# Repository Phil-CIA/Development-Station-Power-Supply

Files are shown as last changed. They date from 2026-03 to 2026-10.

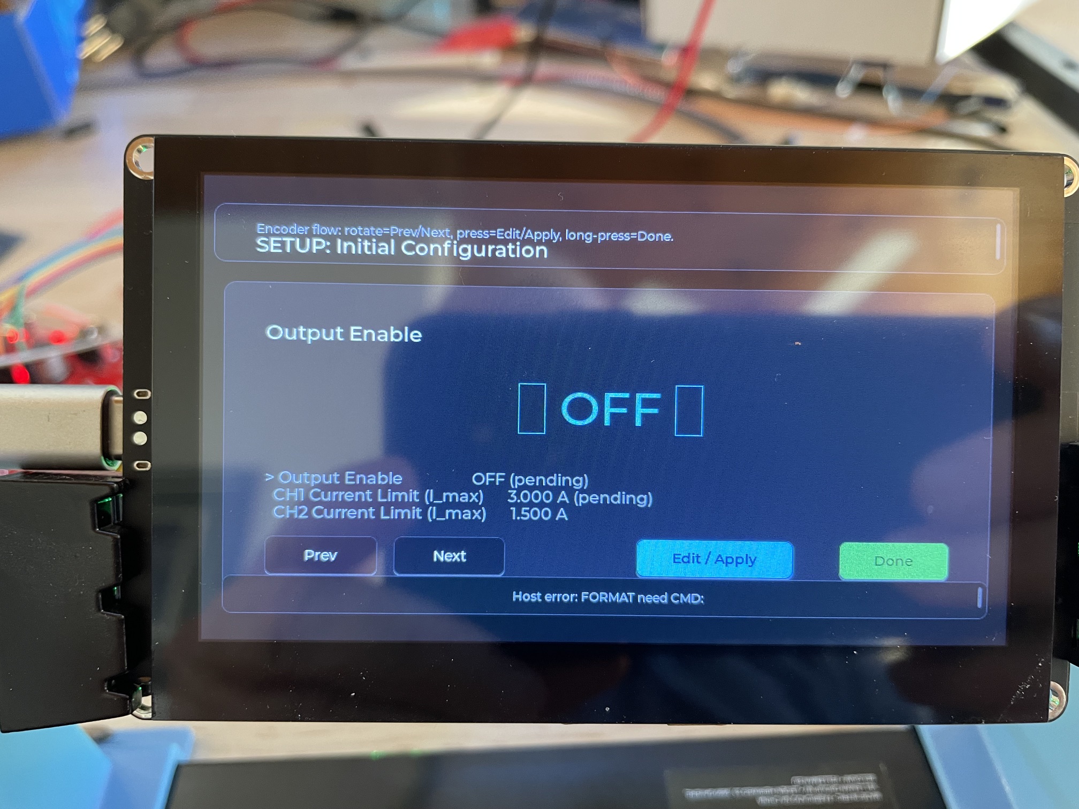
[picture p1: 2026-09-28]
docs/display-project/screenshots/audit/setup-before-fix.jpeg

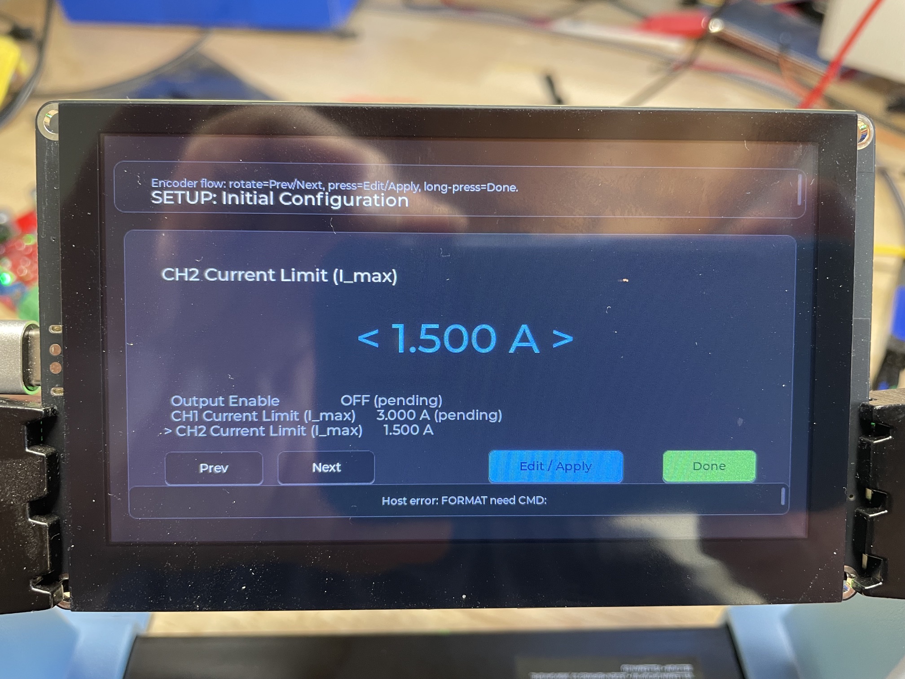
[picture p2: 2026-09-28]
docs/display-project/screenshots/audit/setup-d2.jpeg

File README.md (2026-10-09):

# Development-Station-Power-Supply

Integrated hardware and firmware repository for the development-station bench supply, its control electronics, front-panel display path, and supporting boards.

## What this repo actually contains

This is the active working repo for the full bench-supply platform, not just a single firmware target. It currently includes:

- ESP32 control firmware
- DSP regulator board design
- DSP regulator HAT / measurement-control board design
- original front-panel display board files
- USB hub board files and next-iter reference cleanup
- bring-up notes, pin maps, and display evaluation references

## Current direction (2026-08-14)

The project has shifted to a bring-up-first path.

**Recent progress:**
- Completed design simplification: migrated from adjustable 3-channel architecture to single +5V_Boot rail
- Connector contract verification passing (10 signal mappings validated across regulator↔HAT interface)
- Both RegulatorRevB and HAT-RevB boards electrically verified and ready for order prep

Current plan:
1. Use the hardware already built as the learning and validation baseline
2. Keep Rev-B bench work in proven bypass states while Rev-C electrical issues are closed
3. Complete Rev-C regulator and HAT design validation before PCB fabrication release
4. Continue front-panel work inside this repo
5. Evaluate two display paths in parallel:
   - the existing custom front-panel hardware already designed
   - the Elecrow CrowPanel Advance 4.3 inch HMI display
6. Avoid any new display redesign until bench results show it is needed

Current power-hardware status:

- The 3.3V regulator selector redesign is bench-proven in normal remote-sense operation; fallback and 5V TLV9352 checks remain open.
- The Rev-B HAT current-range switch remains bypassed pending MOSFET pinout and Vgs validation.
- HAT Rev-C implements four-channel differential OCP with dual INA2180A2 amplifiers and dual TLV1702 comparators.
- HAT Rev-C ERC is clean, but RB-012 remains a PCB release gate for Kelvin routing, bypassing, thresholds, hysteresis, footprints, and final DRC/connectivity validation.
- Future HAT Rev-D controller decision: use a bare STM32F405RG LQFP64 as the deterministic controller, replacing the F103C8 Blue Pill development module, with a bare ESP32-C3-MINI-1U external-antenna Wi-Fi coprocessor and USB CDC telemetry to a PC. The cited F405 pin allocation and minimum-support targets are frozen in the Rev-D contract; session 3 confirmed PC0=`C3_EN_N` and PC1=`C3_BOOT_N`. Session 4's reviewed support-only KiCad project remains intact. The separate editable project in `hardware/kicad/dsp-regulator-hat-rev-d-full/` now has an initial committed-source HAT reuse pass and independent local MCU/HAT sheets: 13 F405 interfaces wired, 102 components, 128 nets, ERC 0 errors / 80 unresolved warnings. This is partial integration, not a complete HAT; missing source blocks, bare C3 module/antenna and PCB remain open. User direction (2026-10-09): prior HAT circuits are working reuse candidates, replaceable as needed; full Rev-C bench requalification and the untested fan's later check do not block integration. The supplied 2026-08-28 production Rev-C PCB/Gerber/drill set is the working manufacturing reference, but exact physical-board/schematic correlation remains unresolved. Part qualification, full integration, layout and Rev-D bench validation remain open. See `docs/HAT_REVD_PIN_AND_SUPPORT_CONTRACT.md` and the project's `README.md`; no fabrication or hardware validation is claimed.
- See `docs/DEV_STATION_HANDOFF_2026-08-14.md` for the active restart state.

## Hardware scope in this repo

- External supply 12V feeds the regulator and HAT control stack
- Regulator board generates the main rails (+5V, +3.3V primary; +12V intermediate)
- HAT board handles measurement, feedback, and control behavior
- Front-panel display path is now treated as a system integration problem, not a redesign-first task
- USB hub files are retained as reference and redesign starting point where needed

## Hardware board status

**DSP-Regulator-RevB:** Ready for order
- ERC: 0 electrical errors (8 library warnings, non-critical)
- Connector contract: Verified against HAT-RevB (all 10 required signal mappings present)
- Latest netlist export: 2026-06-11 01:43:33

**DSP-Regulator-HAT-RevB:** Ready for order
- ERC: Clean (0 errors, 0 warnings)
- Connector contract: Verified with Regulator-RevB (all 10 required signal mappings present)
- Latest netlist export: 2026-06-11 01:10:51
- Design: Single +5V_Boot rail (simplified from adjustable 3-channel architecture)

These Rev-B files remain the built/bench baseline. Active redesign work now lives in the corresponding Rev-C project folders; do not release Rev-C fabrication outputs until its tracker gates are closed.

## Firmware status

Current firmware work in this repo includes:

- logical rail telemetry mapping
- automatic range selection support
- per-rail calibration and persistent configuration storage
- current-limit operating modes
- TFT front-panel support hooks

The active [CrowPanel UI plan](docs/display-project/crowpanel-screens-tracker.md)
adapts FNIRSI DPS-150 / IPS3608 styling to fixed +5V/+3.3V rails with editable
current limits and shared output control. It includes the issue/PR sequence
and VS Code Copilot session prompts; definitive CV/CC indication remains
gated on hardware validation.

## Current bench priorities

- Complete DRC checks and generate fabrication outputs for RegulatorRevB and HAT-RevB
- Place orders for both boards
- Safe first power-up and validation of the new boards
- Confirm regulator and HAT behavior on the bench
- Resume front-panel display bring-up
- Map the existing front-panel connector to the smart-display interface as needed

## Useful project references

- docs/SYSTEM_DEVELOPMENT_WORKFLOW.md — branch/PR workflow now in effect
- docs/FIRMWARE_DEVELOPMENT_PLAN.md — firmware feature inventory and milestone/branch plan
- docs/display-project/README.md
- docs/GPIO_PINOUT.md
- docs/USB_HUB_CHANGE_TRACKER.md

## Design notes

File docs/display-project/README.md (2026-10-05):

# Display Project Reference

This folder captures the current starting point for the front-panel display direction inside the Development Station Power Supply project.

## Path priority

| Priority | Path | Hardware | Status |
|---|---|---|---|
| **Primary** | Elecrow CrowPanel 4.3 HMI | ESP32-S3, 800×480 IPS, capacitive touch | Active — main development target |
| Secondary | Custom front-panel board + Hosyond MSP4021 | ESP32-C6, ST7796S SPI, 480×320 | Paused — revisit with replacement module |

## Current direction
The display effort is now on **two paths with a defined priority**:
- **Primary**: Elecrow CrowPanel Advance 4.3 inch HMI — main development target going forward
- **Secondary**: Custom front-panel hardware with Hosyond MSP4021 (ST7796S SPI module) — retained as a documented path but paused pending a replacement module

## Active UI improvement plan

Use FNIRSI DPS-150 / IPS3608 as visual references for an original, touch-first
800x480 interface. Our CH1 +5V and CH2 +3.3V rails remain fixed; users edit
current limits, not voltage or a manual CV/CC selector. One master OUTPUT
control serves both rails. Automatic CV/CC indication is conditional on
proven hardware behavior, not just a software threshold comparison.

The user-selected Main layout has side-by-side CH1/CH2 cards with large
vertical voltage/current/power readouts and no Energy or Input panels.
Tapping a card opens that channel's detail view: readings on the left,
its V/I graph on the right, and a touch action back to Main.

The Graph screen is being rebuilt as a Yokogawa GX-style strip recorder; see
[strip-recorder-graph-spec.md](strip-recorder-graph-spec.md) (Rev 2) for the
plan, hardware-feasibility analysis, and the D5a/D5b bucket breakdown
(supersedes the prior single D5 scope line). History scroll-back and alarm
markers are cut from scope; CSV/PC export is tracked separately in
[#84](https://github.com/Phil-CIA/Development-Station-Power-Supply/issues/84).

The [screen tracker](crowpanel-screens-tracker.md) contains the issue/PR
sequence, reference-photo approval gate, and copy-paste VS Code Copilot
session instructions. The [IPS3608 reference](../IPS3608_REFERENCE_MANUAL_KEY_SPECS.md)
is already in the repo; the user's two supplied visual references and
selected screen composition are described in the tracker. Exact product
identity is unverified and final geometry remains to be approved. No
display hardware redesign or secondary-path restart is included.

A simulated, browser-viewable 800x480 mockup for visual review is at
[mockups/crowpanel-fixed-rail-mockup.html](mockups/crowpanel-fixed-rail-mockup.html)
(baseline visual appearance and screen flow approved 2026-10-02; behavior
questions unresolved; not bench-tested; not an LVGL rendering).

The first LVGL port of the approved Main overview and single-channel detail
screens is on `display/fnirsi-dual-rail-dashboard` (#78); status and visual
differences are in the screen tracker. Build-verified only; not bench-tested.

## Active display candidate
- Elecrow CrowPanel Advance 4.3 inch HMI ESP32 display
- 800x480 IPS panel
- Capacitive touch
- ESP32-S3-WROOM-1-N16R8
- 16MB flash + 8MB PSRAM
- Suitable for Arduino, ESP-IDF, PlatformIO, and LVGL

## Official documentation links
- Product wiki:
  - https://www.elecrow.com/wiki/CrowPanel_Advance_4.3-HMI_ESP32_AI_Display.html
- Product page:
  - https://www.elecrow.com/crowpanel-advance-4-3-hmi-esp32-800x480-ai-display-ips-touch-artificial-intelligent-screen.html
- Elecrow GitHub organization:
  - https://github.com/Elecrow-RD
- Official board repository:
  - https://github.com/Elecrow-RD/CrowPanel-Advance-4.3-HMI-ESP32-S3-AI-Powered-IPS-Touch-Screen-800x480
- General CrowPanel course files:
  - https://github.com/Elecrow-RD/CrowPanel-ESP32-Display-Course-File

## Datasheet and hardware resource links
- Board resource page (includes schematics, version notes, and platform support):
  - https://www.elecrow.com/wiki/CrowPanel_Advance_4.3-HMI_ESP32_AI_Display.html#resources
- GitHub repository hardware and docs area:
  - https://github.com/Elecrow-RD/CrowPanel-Advance-4.3-HMI-ESP32-S3-AI-Powered-IPS-Touch-Screen-800x480
- Espressif ESP32-S3-WROOM module docs:
  - https://www.espressif.com/en/support/documents/technical-documents

## Notes
- The old separate TTF display repo is now reference-only and no longer the active implementation path.
- The front-panel work now lives back under the main Development Station Power Supply project.
- Custom board redesign (Phase 3) is scoped but not started — CrowPanel bring-up (Phase 4) runs first to validate the UART protocol.
- When the CrowPanel arrives, confirm the exact board revision against the Elecrow wiki version notes before selecting example code.
- The wiki indicates 5V input, LVGL support, and external interfaces for UART, I2C, audio, battery, and storage.

## Interface direction
The goal is not identical hardware. The goal is a common front-panel interface so either display path can be used from the host perspective.

**Standard decided (2026-05-27): Universal Display Interface (UDI)**
- Connector: JST XH B4B-XH-A, 4-pin (XH2.54-4P), LCSC C144394
- Pin 1: +5V (host → display), Pin 2: GND, Pin 3: DISP_UART_TX (host TX), Pin 4: DISP_UART_RX (host RX)
- Protocol: LVGL on display MCU; UART 115200 8N1; `CMD:`/`ACK:`/`ERR:`/`EVT:` framing
- Full spec: `docs/DISPLAY_INTERFACE_STANDARD.md`
- HAT Rev-B: implemented at J21 (PB10=TX, PB11=RX via USART3, 33Ω series on both lines)

---

## Custom Board Rev-1 Requirements

The custom front-panel board must be redesigned to comply with the UDI standard. The secondary-path board (ESP32-C6 + ST7796S) remains the hardware baseline; only the host interface and firmware architecture change.

### Host connector (J3) — REPLACE

| Item | Legacy (remove) | Rev-1 target |
|---|---|---|
| Connector | 2×5 IDC, 2.54mm (Conn_02x05) | JST XH B4B-XH-A, 4-pin |
| Signals | +5V, GND, SPI SCK/MISO/MOSI/CS | +5V, GND, UART_RX, UART_TX |
| ESP32-C6 role | SPI slave | UART peripheral |

### Firmware — REPLACE

| Item | Legacy | Rev-1 target |
|---|---|---|
| Graphics | TFT_eSPI / host pixel push | LVGL (display-side rendering) |
| Host link | SPI slave GPIO4–7 | UART RX/TX (GPIO assignment TBD) |
| Protocol | Raw pixel stream | `CMD:`/`ACK:`/`ERR:`/`EVT:` framing |

### What stays unchanged
- MCU: ESP32-C6
- Display panel: Hosyond MSP4021 (ST7796S, 480×320 SPI)
- Local SPI bus: TFT (GPIO10–13), touch XPT2046, SD card
- Power regulator: AMS1117-3.3

### ESP32-C6 UART pin assignment (TBD)
GPIO4/5 (previously SPI slave SCK/MISO) are available candidates for UART RX/TX. Confirm against ESP32-C6 UART peripheral matrix before committing. Document final assignment in `docs/GPIO_PINOUT.md` when redesign begins.

### Scope note
This redesign is Phase 3 — scoped as a requirements spec. KiCad work starts after CrowPanel bring-up (Phase 4) validates the UART protocol end-to-end.

## Local bring-up starter
- Local PlatformIO starter path (CrowPanel):
  - `crowpanel-43-bringup/`
- Starter is based on official Elecrow V1.2 4.3-inch example pin mapping for RGB data bus and touch I2C.
- Current code includes LVGL Splash/Setup/Main/Graph/Settings screens and
  telemetry/UDI bindings. See the screen tracker for merged versus open
  implementation work and remaining bench evidence.

## Hosyond MSP4021 (secondary path) reference
- Hardware spec, confirmed pin map, DC polarity, init sequence, and official resource links:
  - `docs/display-project/hosyond-msp4021-st7796-reference.md`

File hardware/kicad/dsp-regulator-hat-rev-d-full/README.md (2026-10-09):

# DSP Regulator HAT Rev-D Full - Initial Integration

**Status: editable PARTIAL INTEGRATION, not a complete full-HAT schematic.**
Created 2026-10-09 for #102 from the reviewed session-4 support project.
The first source-backed circuit integration pass is now present; remaining
bulk circuit edits belong here. This project is not fabrication-ready or
bench-validated; there is no PCB or PCB DRC result.

## Open and edit this project

- `DSP-Regulator-HAT-RevD-Full.kicad_pro` - project setup
- `DSP-Regulator-HAT-RevD-Full.kicad_sch` - root schematic
- `MCU.kicad_sch` - independent, local hierarchical F405 support sheet
- `HAT.kicad_sch` - independent local copy of committed HAT Rev-C reuse
  candidates, with the old Blue Pill and XIAO C3 removed
- `build_kicad/` - gitignored ERC reports and exported netlists

Open the `.kicad_pro` in KiCad 10.0.5, then open its root schematic and enter
the MCU and HAT sheets. Project/instance names and sheet paths are consistent
with this three-sheet hierarchy. The MCU is a real local copy, not a shared
reference to `../dsp-regulator-hat-rev-d/`; all source projects remain separate.

The reviewed support-only project in `../dsp-regulator-hat-rev-d/` and all
Rev-C source files are unchanged. Do not edit those projects when integrating
here. Preserve the frozen pin/support requirements in
[`HAT_REVD_PIN_AND_SUPPORT_CONTRACT.md`](../../../docs/HAT_REVD_PIN_AND_SUPPORT_CONTRACT.md).

## Present and intentionally absent

Present: bare STM32F405RGT6 support (power/VCAP, HSE, reset, boot and SWD),
USB 2.0 Type-C/ESD/CC and isolated PA9 VBUS sensing, J4's logical C3
UART/EN/BOOT interface, and 62 retained HAT Rev-C components. J4 is not a
C3 module. Crystal/load and EN candidate/DNP markings remain unchanged.

Source: `../dsp-regulator-hat-rev-c/DSP-Regulator-HAT-RevC.kicad_sch`, not
the uncorrelated production PCB. Added MCU/HAT global interfaces:

| F405 pins | Reused endpoint |
|---|---|
| PA0 / PA1 | J12 ISET 5V / 3V3; each has a new 10k pull-down |
| PA5 / PA6 / PA7 / PA8 | U12 W25Q128 SPI / CS; new 47k SCK/MOSI pull-downs and 10k CS pull-up |
| PB6 / PB7 | U16 CH340 debug TX / RX; each has a new 10k pull-up; not legacy PB6/PB7 connector nets |
| PB10 / PB11 | UDI via R77/R79 to J9; each has a new 10k pull-up |
| PB8 / PB9 | J10/U13 I2C; retains source R69/R70 4.7k pull-ups |
| PB5 | R63/Q9 fan control; R64 changed from 100k DNP to populated 10k |
| PA13 / PA14 / NRST | Existing SWD test points/header plus MCU support header |

The source `+3.3V Boot` rail is now `+3V3`, joining U15's output to the
F405 support rail; duplicate MCU rail/ground PWR_FLAGs were removed. This
is connectivity capture, not proof of regulator headroom for the bare C3.
The legacy WS2812B D12 is retained with DIN tied LOW, not wired to PC13;
the frozen low-current sink LED still needs a replacement circuit.

Absent: AW9523/interrupt and shift-register device (not in this source),
complete measurement/protection and fault/control integration, bare
ESP32-C3-MINI-1U and antenna implementation, C3 local supply/straps/UART0
recovery, and PCB. PA4, PC4 and PC13 remain explicit no-connects pending
those endpoints/replacements. Legacy expansion, sense and fault-label gaps
remain visible; do not invent mappings or treat ERC as protection coverage.

## Integration direction and open gates

User direction (2026-10-09): prior HAT circuits are working reuse candidates,
replaceable as needed. Full Rev-C bench requalification is not a prerequisite
to integration; the untested fan's later bench check is nonblocking. Replace
the old C3 development-board implementation, do not carry it forward.

The supplied 2026-08-28 production Rev-C PCB/Gerber/drill set is the working
manufacturing reference, but exact physical-board and schematic correlation
is unresolved. This starter does not claim a match and does not copy or
modify external OneDrive production files. PR #111 records the mismatch
but was not merged when this starter was created. Keep source identity and
block-level connectivity uncertainties explicit during integration rather
than treating manufacturing outputs or screenshots as a verified schematic.

Still required: integrated pin/net and safe-state review, ISET polarity and
shift-register all-off verification, complete ERC after integration,
crystal/load and C3 EN timing qualification, module/antenna and connector
footprint selection, 3.3 V rail budget, layout/USB/ESD/RF review, PCB DRC,
and Rev-D hardware/bench validation (including powered/unpowered USB VBUS
insertion, oscillator startup, reset/boot, fan and protection behavior).

## Validation and unresolved ERC warnings

Original support-only starter: KiCad CLI 10.0.5 reported 0 errors / 0 warnings
before importing the HAT candidates (31 components, 68 nets).

**Current first pass: KiCad CLI 10.0.5 reports 0 errors / 80 warnings**:
32 footprint-library, 32 symbol-library, 3 symbol/library mismatch and
13 isolated-label warnings. No warning exclusions were added to hide them.
The three mismatches are inherited `1My_Connectors:5015` test points
TP9, TP2_+5V1 and TP_+3.3V1.
Isolated labels are the four VSENSE endpoints, Incoming (+/-), legacy
PB6/PB7/B13/B14/B15/SPI_CS expansion endpoints and `FAULT_WARNING_SUM`.
These are unresolved integration gaps, not routed MCU functions.

Exports contain **102 components, 128 nets**, with all 64 F405 pins accounted
for. Root/MCU/HAT netlist and SVG exports resolve as pages 1/2/3. Pairwise
connectivity checks cover all 215 retained HAT pins except the deliberate
D12 DIN grounding, which is checked separately; support pin topology,
13 frozen interfaces, nine new bias resistors, R64 population, SWD,
rail joins and native USB VBUS isolation were checked. SHA-256 confirms
the original support project and HAT Rev-C files remain byte-identical.
This is not a clean full-HAT release, PCB DRC, fabrication or bench validation.

Re-run from the repository root in PowerShell:

```powershell
$project = "hardware\kicad\dsp-regulator-hat-rev-d-full"
$kicad = "$env:LOCALAPPDATA\Programs\KiCad\10.0\bin\kicad-cli.exe"
& $kicad sch erc "$project\DSP-Regulator-HAT-RevD-Full.kicad_sch" `
  --output "$project\build_kicad\ERC.rpt" --format report `
  --severity-all --exit-code-violations
& $kicad sch export netlist "$project\DSP-Regulator-HAT-RevD-Full.kicad_sch" `
  --output "$project\build_kicad\DSP-Regulator-HAT-RevD-Full.net" `
  --format kicadsexpr
```

The strict ERC command intentionally returns a nonzero status while these
warnings remain; inspect the report rather than interpreting export success
as design acceptance.

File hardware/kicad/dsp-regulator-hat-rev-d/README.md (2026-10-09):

# DSP Regulator HAT Rev-D F405 Support Sheet

Status: session-4 schematic capture and initial contract review complete.
This is a separate, hierarchical KiCad project containing the F405
minimum-support circuitry and external C3 interface. It has no PCB and is not
a fabrication release. Rev-C schematic and PCB files were not copied or
modified.

## Project files

- `DSP-Regulator-HAT-RevD-Support.kicad_pro` — project
- `DSP-Regulator-HAT-RevD-Support.kicad_sch` — root sheet
- `MCU.kicad_sch` — hierarchical F405 and support sheet
- `build_kicad/` — gitignored ERC report and netlist exports

## Captured circuits

- `MCU_ST_STM32F4:STM32F405RGTx` symbol with the frozen LQFP64 allocation;
  exact schematic Value is `STM32F405RGT6`.
- Four VDD-pin 100 nF bypass capacitors, local 4.7 µF bulk, VDDA 0 Ω link
  and 100 nF/1 µF bypass, VBAT-to-3.3 V tie, common VSS/VSSA ground, and one
  2.2 µF low-ESR capacitor at each VCAP pin.
- HSE crystal, NRST pull-up/capacitor/reset switch, BOOT0 and PB2 pull-downs,
  and BOOT0 recovery jumper.
- SWD-only ARM 10-pin header interface with SWDIO, SWCLK, NRST, target
  3.3 V reference, and GND. The exact keyed connector footprint is not chosen.
- USB 2.0 Type-C receptacle interface, 5.1 kΩ CC resistors, USBLC6-2SC6 ESD
  protection, and isolated PA9 VBUS sense divider. VBUS does not connect to
  a HAT supply rail. Verify the selected GCT footprint against the orderable
  USB4105-GF-A variant before layout.
- External C3 interface connector J4:

  | J4 pin | Net | F405 connection | C3-side meaning |
  |---:|---|---|---|
  | 1 | `+3V3` | Shared logic rail | C3 supply reference |
  | 2 | `GND` | Common ground | C3 ground |
  | 3 | `C3_UART_RX` | PC10 / UART4 TX | GPIO0 / application UART RX |
  | 4 | `C3_UART_TX` | PC11 / UART4 RX | GPIO1 / application UART TX |
  | 5 | `C3_EN_N` | PC0, open-drain control | CHIP_EN / active-low reset |
  | 6 | `C3_BOOT_N` | PC1, open-drain control | GPIO9 / active-low boot request |

Unallocated F405 pins are marked no-connect in this minimum-support project;
the frozen assignments remain requirements for full-HAT integration.

## Unverified values and integration boundary

The 8.000 MHz crystal and both 10 pF C0G/NP0 load-capacitor Value fields say
`candidate; UNVERIFIED`. The load capacitors are DNP until the selected
crystal's datasheet, total board parasitics, load calculation, and oscillator
startup are reviewed. The optional 1 µF C3 CHIP_EN capacitor is likewise
marked `candidate; UNVERIFIED` and DNP pending exact module and rail-ramp
review. These markings are intentional; do not treat them as released BOM
values.

J4 is a logical module interface, not an ESP32-C3-MINI-1U module footprint.
The C3's local bypassing, GPIO2/GPIO8 boot-strapping, UART0 recovery header,
exact module/antenna selection, RF keep-out, and antenna validation remain
outside this F405 support sheet. The SWD header's exact keyed footprint is
also pending.

## Validation

KiCad CLI 10.0.5 ERC result: **0 errors, 0 warnings**. The exported netlist
was checked against all 64 F405 pins and the contract's power, clock, reset,
boot, C3 UART/control, USB D+/D−/CC/VBUS, and SWD mappings. ERC and netlist
results do not establish PCB routing, USB signal integrity, ESD placement,
clock startup, VBUS behavior under powered/unpowered insertion, or bench
readiness.

Re-run from the repository root in PowerShell:

```powershell
$project = "hardware\kicad\dsp-regulator-hat-rev-d"
$kicad = "$env:LOCALAPPDATA\Programs\KiCad\10.0\bin\kicad-cli.exe"
& $kicad sch erc "$project\DSP-Regulator-HAT-RevD-Support.kicad_sch" `
  --output "$project\build_kicad\ERC.rpt" --format report --severity-all
& $kicad sch export netlist "$project\DSP-Regulator-HAT-RevD-Support.kicad_sch" `
  --output "$project\build_kicad\DSP-Regulator-HAT-RevD-Support.net" `
  --format kicadsexpr
```

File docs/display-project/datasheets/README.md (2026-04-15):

# Datasheet Staging Area

Place downloaded PDFs, pinouts, and vendor reference files for the display project here.

Suggested first additions:
- Board wiki export or PDF print
- ESP32-S3 module datasheet
- Display/touch controller references from the vendor repo
- Any pin maps used during bring-up

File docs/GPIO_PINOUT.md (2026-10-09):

# System Pinout Reference

Status: active. This document is the top-level index for signal/pin contracts
used by this repo. It links each subsystem to its authoritative mapping source.

## Authoritative pin-contract split

| Subsystem | Authoritative source |
|---|---|
| STM32 controller path (Rev-C HAT + `stm32-bluepill-bringup`) | `docs/STM32_BLUEPILL_PIN_TABLE.md` |
| Future Rev-D STM32F405RG controller (pin allocation frozen; not routed) | `docs/HAT_REVD_PIN_AND_SUPPORT_CONTRACT.md` |
| Custom front-panel board (ESP32-C6 + ST7796S path) | This file, sections below |
| Display host interface standard (both display paths) | `docs/DISPLAY_INTERFACE_STANDARD.md` |

---

## A) Custom front-panel board (ESP32-C6) pin mapping

Framework: Arduino  
Display architecture: display-side LVGL with local SPI peripherals  
Host link: UART over UDI connector

### A1) UDI host connector (J3, JST XH 4-pin)

| J3 Pin | Net Name | Direction (Host ↔ Display) | ESP32-C6 role | Notes |
|---:|---|---|---|---|
| 1 | +5V | Host -> Display | Power in | Board regulates to 3.3V via AMS1117-3.3 |
| 2 | GND | — | Ground | Common return |
| 3 | DISP_UART_TX | Host -> Display | UART RX | Host TX into display RX |
| 4 | DISP_UART_RX | Display -> Host | UART TX | Display TX back to host RX |

### A2) TFT module header (J1) -> ESP32-C6 (local SPI master)

| J1 Pin | Net Name | Function | ESP32-C6 GPIO | Notes |
|---:|---|---|---:|---|
| 3 | CS | TFT chip-select | GPIO10 | ST7796S CS |
| 4 | RST | TFT reset | GPIO19 | Active-low reset |
| 5 | D/C | TFT data/command | GPIO18 | |
| 6 | MISO | SPI MISO | GPIO11 | Shared with touch/SD |
| 7 | SCLK | SPI SCLK | GPIO12 | Shared with touch/SD |
| 8 | PWM | Backlight PWM | GPIO20 | LED/backlight control |
| 9 | MOSI | SPI MOSI | GPIO13 | Shared with touch/SD |
| 11 | Touch CS | Touch chip-select | GPIO22 | XPT2046 CS |
| 14 | IRQ | Touch interrupt | GPIO21 | Optional (can be polled) |

### A3) SD header (J2) -> ESP32-C6

| J2 Pin | Net Name | Function | ESP32-C6 GPIO |
|---:|---|---|---:|
| 1 | SCLK | SPI SCLK | GPIO12 |
| 2 | MOSI | SPI MOSI | GPIO13 |
| 3 | MISO | SPI MISO | GPIO11 |
| 4 | SD card CS | SD chip-select | GPIO15 |

Firmware notes:
- Host protocol: UART 115200 8N1 with `CMD:`/`ACK:`/`ERR:`/`EVT:` framing.
- The host sends semantic commands; display firmware renders locally with LVGL.

---

## B) STM32 controller path summary (Rev-C)

For STM32 signal ownership and status, use:
- `docs/STM32_BLUEPILL_PIN_TABLE.md` (authoritative matrix)

Current high-impact contract notes:
1. Rail-control outputs are active on `PA0/PA1/PA2` as `ISET_MPU_5V`,
   `ISET_MPU_3V3`, and `ISET_MPU_Channel_3`.
2. Current Rev-C fan connector (`J7`) is a 2-pin control connector and does
   not expose a dedicated tach net in this revision.
3. `FAULT_CRITICAL_SUM` is observed through AW9523 on Rev-C, not a direct STM32
   GPIO net. Firmware uses AW9523 interrupt signaling (`AW9523_INT` on `PB7`)
   with `PIN_FAULT_CRITICAL_SUM = -1` kept as disabled direct-path fallback.

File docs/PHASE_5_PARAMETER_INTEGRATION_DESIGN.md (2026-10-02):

# Phase 5: Parameter Integration Design (2-Channel Power Supply)

**Date:** 2026-07-03  
**Status:** Design Phase — Ready for Implementation  
**Scope:** Bind real system parameters to CrowPanel UI for 2-fixed-channel power supply  
**Reference:** IPS3608 dark-theme adaptation, Phase 4 visual baseline, UDI UART contract

> Historical design proposal, not the current implementation contract.
> The active [screen tracker](display-project/crowpanel-screens-tracker.md)
> supersedes this document's adjustable-voltage examples, per-channel output
> controls, always-CV assumptions, speculative thresholds, and proposed frame
> layout. Use actual firmware and `DISPLAY_INTERFACE_STANDARD.md` for the
> shipped protocol. Current UI work is fixed +5V/+3.3V, per-channel current
> limits, one shared output control, and touch-first operation; CV/CC claims
> require hardware validation.

---

## 1. Boot Sequence

```
Power On
  ↓
[Splash Screen] 3–5 seconds
  - Brand logo / product name
  - No user interaction
  ↓
[Setup Screen] User-configurable once per boot
  - Feature discovery & control mapping
  - User confirms defaults or adjusts
  - Sets: Current limits, protection thresholds, display preferences
  ↓
[Main Telemetry Screen] Live operation
  - Dual-channel V/I/P display
  - Status indicators
  - Protection state
  - User navigates between Main → Graph → Settings via encoder knob
```

**Gate to Main:** User must confirm Setup OR timeout (auto-proceed with defaults) after 30 seconds.

---

## 2. Parameter Contract

### Real System Data (from STM32 HAT via UART)

**Current telemetry frame (binary, 10 bytes):**
```
[0xAA][0x55][0x06][T][seq][v12_mV_lo][v12_mV_hi][i12_mA_lo][i12_mA_hi][CRC8]
```

**Proposed extended frame (Phase 5):**
```
[0xAA][0x55][LEN][T][seq][v5_mV_lo][v5_mV_hi][i5_mA_lo][i5_mA_hi]
                          [v3v3_mV_lo][v3v3_mV_hi][i3v3_mA_lo][i3v3_mA_hi]
                          [status][protection_flags][temp_C][CRC8]
```

**Status byte breakdown:**
- Bit 7: CH1 output enabled (1=on, 0=off)
- Bit 6: CH2 output enabled
- Bit 5: CH1 in CV mode (constant voltage)
- Bit 4: CH2 in CV mode
- Bit 3: Thermal warning (temp > threshold)
- Bit 2: Reserved
- Bit 1: Reserved
- Bit 0: Reserved

**Protection flags byte:**
- Bit 7: CH1 OVP triggered
- Bit 6: CH1 OCP triggered
- Bit 5: CH2 OVP triggered
- Bit 4: CH2 OCP triggered
- Bit 3: CH1 OTP triggered
- Bit 2: CH2 OTP triggered
- Bit 1: Communication link stale (no frame for > 1 second)
- Bit 0: Reserved

**Frame rate:** 4 Hz (250 ms interval)

### Display-Local Parameters (UI State)

**Setup Configuration (stored in flash or session):**
- CH1 current limit setpoint (0–3A, default TBD)
- CH2 current limit setpoint (0–2A, default TBD)
- CH1 OCP threshold (50–3000 mA, step 10 mA)
- CH2 OCP threshold (50–2000 mA, step 10 mA)
- CH1 OVP threshold (4.5–5.5V, step 0.1V)
- CH2 OVP threshold (3.0–3.6V, step 0.1V)
- OTP threshold (global, 45–80°C, step 1°C)
- Dark theme enabled (1=yes, 0=no — default: yes)
- Brightness (5–100%, step 5)

**User Controls (transient, not stored unless saved to preset):**
- CH1 output enable/disable toggle
- CH2 output enable/disable toggle
- Data group selector (preset 1–6 for quick parameter swap)
- Graph page timebase (0.1s, 0.2s, 0.5s)
- Screen: Main / Graph / Settings selector

---

## 3. Screen Layouts

### 3.1 Setup Screen (Boot Flow)

**Layout:**
```
╔════════════════════════════════════╗
║  Setup: Control Configuration      ║  ← Title
╠════════════════════════════════════╣
║                                    ║
║  CH1: +5V  Current Limit: 3.0 A   ║
║  CH1 OCP:  3000 mA  OVP: 5.5V     ║
║                                    ║
║  CH2: +3.3V  Current Limit: 2.0 A ║
║  CH2 OCP:  2000 mA  OVP: 3.6V     ║
║                                    ║
║  OTP Threshold: 70°C               ║
║  Theme: Dark   Brightness: 80%     ║
║                                    ║
╠════════════════════════════════════╣
║ ↑↓ Scroll  OK Confirm  ESC Cancel  ║  ← Instructions
╚════════════════════════════════════╝
```

**Encoder behavior:**
- Rotate: scroll through parameters
- Press: enter edit mode for selected parameter
- Long press: apply defaults and proceed to Main

**Expected parameters in order:**
1. CH1 current limit
2. CH1 OCP threshold
3. CH1 OVP threshold
4. CH2 current limit
5. CH2 OCP threshold
6. CH2 OVP threshold
7. OTP threshold
8. Brightness
9. Confirm & Start

---

### 3.2 Main Telemetry Screen

**Layout (IPS3608-inspired, dark theme):**

```
╔════════════════════════════════════╗
║ 🔊 ❄️  🔒       M1      CV   ⏹     ║  ← Status chips
╠════════════════════════════════════╣
║                                    ║
║  [CH1: +5V]                        ║
║  V 5.234 v  ← V set: 5.20v        ║  ← Yellow accent
║  A 1.234 A  ← I set: 1.60A        ║  ← Blue accent
║  P 6.3 W    Temp: 28°C            ║  ← Gray accent
║                                    ║
║  [CH2: +3.3V]                      ║
║  V 3.285 v  ← V set: 3.30v        ║  ← Yellow accent
║  A 0.542 A  ← I set: 0.50A        ║  ← Blue accent
║  P 1.8 W                           ║  ← Gray accent
║                                    ║
║  Capacity: 2456.3 Ah              ║
║  Energy: 14523.3 Wh               ║
║  Time: 13:06:17                    ║
║                                    ║
╠════════════════════════════════════╣
║ ↑↓ CH Select  RUN/STOP  ⚙ Settings ║  ← Navigation
╚════════════════════════════════════╝
```

**Status chips (top-right):**
- Volume icon (black if on, white if off)
- Fan icon (black if running, white if idle)
- Lock icon (black if locked, white if unlocked)
- Data group indicator (M1–M6)
- CV indicator (always on for fixed rails)
- RUN/STOP indicator (green if running, red if stopped)

**Encoder behavior:**
- Rotate (no input): toggle between CH1 and CH2 detail focus
- Rotate (after V/A press): scroll pages (Main → Graph → Settings)
- Press RUN/STOP button: toggle output enable for selected channel
- Press V/A: enter current-limit edit mode for selected channel
- Press encoder knob: confirm parameter edit or lock/unlock
- Long press encoder: clear statistics

---

### 3.3 Graph (VI Curve) Screen

**Layout:**

```
╔════════════════════════════════════╗
║ 🔊 ❄️  🔒       M1      CV   ⏹     ║  ← Status chips (same)
╠════════════════════════════════════╣
║  MAX: 5.20v (CH1)  MAX: 0.55A     ║  ← Yellow/Blue labels
║  MIN: 5.18v (CH1)  MIN: 0.10A     ║
║                                    ║
║  ┌────────────────────────────┐    ║
║  │ CH1 ↑   ╱╲╱╲  ← Voltage    │    ║  ← Yellow trace (CH1 V)
║  │     │  ╱  ╲                │    ║
║  │ CH2 ↓ ╱    ╲  ← Current    │    ║  ← Blue trace (CH1 I)
║  │     │╱      ╲              │    ║
║  │     ├────────┤             │    ║
║  │     T: 0.5s  ← Timebase    │    ║
║  └────────────────────────────┘    ║
║                                    ║
║  CH1 Data: V=5.23v I=1.24A        ║
║  CH2 Data: V=3.28v I=0.54A        ║
║                                    ║
╠════════════════════════════════════╣
║ ← TB Time Base      RUN/STOP  ⚙    ║  ← Timebase adjust / nav
╚════════════════════════════════════╝
```

**Legend:**
- **Yellow line:** Voltage trace (normalized to display width)
- **Blue line:** Current trace (normalized to display height)
- **Timebase:** 0.1s, 0.2s, 0.5s per division (left/right buttons adjust)

**Encoder behavior:**
- Rotate: scroll timebase (0.1s ↔ 0.2s ↔ 0.5s)
- Press: return to Main screen
- Long press: clear trend buffer

---

### 3.4 Settings Screen

**Layout:**

```
╔════════════════════════════════════╗
║  Settings: System Configuration    ║
╠════════════════════════════════════╣
║                                    ║
║  ✓ System                          ║  ← Current selection
║    Language: English               ║
║    Brightness: 80%                 ║
║    Volume: 40%                     ║
║    Style: Dark                     ║
║                                    ║
║  DataSet                           ║
║    Group 1–6 parameter presets     ║
║                                    ║
║  About                             ║
║    Model: WorkStation PSU          ║
║    Version: 1.0.0                  ║
║                                    ║
╠════════════════════════════════════╣
║ ↑↓ Menu   ► Enter   ← Back / ESC   ║
╚════════════════════════════════════╝
```

**Encoder behavior:**
- Rotate: select menu item (System / DataSet / About)
- Press: enter submenu
- Left arrow / ESC: return to Main

---

## 4. Operational State Machine

```
BOOT
  ↓
SPLASH (3–5 sec)
  ↓
SETUP (user interactive, 30 sec timeout)
  ├─→ [OK] → RUNNING / IDLE (Main screen, outputs OFF by default)
  └─→ [Timeout] → RUNNING / IDLE (Main screen with defaults)

RUNNING / IDLE
  ├─→ RUN/STOP press → toggle CH1 or CH2 output
  ├─→ V/A press → edit current limit for selected channel
  ├─→ Encoder rotate → select Main / Graph / Settings
  ├─→ Encoder press → navigate within current screen
  └─→ Power off → SHUTDOWN (save state, zero V/I)

FAULT STATE (if protection triggered)
  ├─→ OVP/OCP/OTP sets protection_flags bit
  ├─→ UI shows warning indicator on status chip
  ├─→ Output disabled automatically (hardware + firmware)
  └─→ User must acknowledge (Settings → clear fault)
```

---

## 5. Parameter Mapping: Display ↔ STM32 HAT

| Display Element | Source | Update Rate | Notes |
|---|---|---|---|
| CH1 voltage | STM32 ADC (12-bit) | 4 Hz (250 ms) | Measures main +5V rail |
| CH1 current | STM32 ADC (12-bit) | 4 Hz | INA3221 or equivalent |
| CH2 voltage | STM32 ADC (12-bit) | 4 Hz | Measures main +3.3V rail |
| CH2 current | STM32 ADC (12-bit) | 4 Hz | INA3221 or equivalent |
| Temperature | STM32 internal sensor | 4 Hz | MCU junction or external NTC |
| CH1 output enable | STM32 GPIO (PA0/equivalent) | Immediate | User toggle via UI |
| CH2 output enable | STM32 GPIO (PA1/equivalent) | Immediate | User toggle via UI |
| CH1 current limit | CrowPanel flash or UI state | On change | User-set threshold (compare against ADC) |
| CH2 current limit | CrowPanel flash or UI state | On change | User-set threshold |
| OVP/OCP/OTP flags | STM32 firmware logic | 4 Hz | Comparator + firmware trip |
| Protection flags byte | STM32 UART frame | 4 Hz | Bits 7–2 encode all active faults |
| Thermal warning | STM32 firmware | 4 Hz | Set if temp exceeds OTP threshold |
| Data statistics | CrowPanel accumulator | Real-time | Ah/Wh/time updated locally |

---

## 6. Telemetry Frame Evolution

### Current Frame (Phase 4 — Binary, HAT → CrowPanel only)
```
Byte [0]: 0xAA (SOF1)
Byte [1]: 0x55 (SOF2)
Byte [2]: 0x06 (LEN: TAG + seq + v12 + i12)
Byte [3]: 'T'  (TAG: Telemetry)
Byte [4]: seq  (u8, increments per transmission)
Byte [5–6]: v12_mV (uint16_le, main +12V rail estimate or +5V)
Byte [7–8]: i12_mA (int16_le, main rail current)
Byte [9]: CRC8 (poly 0x07, init 0x00)
```

### Proposed Extended Frame (Phase 5+)
```
Byte [0]: 0xAA (SOF1)
Byte [1]: 0x55 (SOF2)
Byte [2]: 0x14 (LEN: 20 bytes of payload)
Byte [3]: 'T'  (TAG: Extended Telemetry)
Byte [4]: seq  (u8)
Byte [5–6]: v5_mV (uint16_le, +5V channel)
Byte [7–8]: i5_mA (int16_le, +5V channel current)
Byte [9–10]: v3v3_mV (uint16_le, +3.3V channel)
Byte [11–12]: i3v3_mA (int16_le, +3.3V channel current)
Byte [13]: temp_C (u8, 0–125°C)
Byte [14]: status (u8: [CH1_en, CH2_en, CH1_CV, CH2_CV, Thermal_warn, -, -, -])
Byte [15]: protection_flags (u8: [CH1_OVP, CH1_OCP, CH2_OVP, CH2_OCP, CH1_OTP, CH2_OTP, Link_stale, -])
Byte [16–19]: Reserved for future expansion
Byte [20]: CRC8
```

**Backward compatibility:** Old 10-byte frame remains valid. CrowPanel detects frame length and parses accordingly.

**Gate:** Only deploy extended frame after both CrowPanel and STM32 firmware are ready to handle it. Until then, Phase 5 uses 10-byte frame with derived/placeholder values.

---

## 7. Implementation Roadmap (Next Steps)

### 7.1 Immediate (Days 1–2)
1. ✓ Capture IPS3608 manual reference (done)
2. ✓ Create this Phase 5 design doc (done)
3. Commit both to repo
4. Schedule STM32 breadboard bring-up (parallel track, Phase A bench runsheet)

### 7.2 Phase 5a — UI Skeleton (Days 3–5)
1. Add Setup screen template to `main.cpp` (no functional parameter storage yet)
2. Update Main screen to show 2-channel layout (CH1 top, CH2 bottom)
3. Update Graph screen to dual-trace (CH1 + CH2)
4. Update Settings menu structure
5. Build + test on CrowPanel hardware (visual layout only, hardcoded demo data)

### 7.3 Phase 5b — Parameter Binding (Days 6–10)
1. Define flash storage for Setup parameters (on CrowPanel or off-device)
2. Add V/A button handler for current-limit editing
3. Add RUN/STOP toggle for per-channel output control
4. Implement telemetry frame parser (handle both 10-byte and 20-byte formats)
5. Bind status flags and protection warnings to UI indicators

### 7.4 Phase 5c — End-to-End (Days 11–14)
1. Flash updated CrowPanel firmware to hardware
2. Verify STM32 breadboard bring-up results (Phase A completion)
3. Cross-connect STM32 UART → CrowPanel UART0-IN per bench runsheet
4. Test parameter flow: STM32 ADC → UART frame → CrowPanel display
5. Verify output enable/disable commands (if reverse channel added)
6. Capture scope traces for boot-to-run sequence

---

## 8. Definition of Done (Phase 5 Complete)

1. ✓ Setup screen appears at boot, allows current-limit adjustment, proceeds to Main
2. ✓ Main screen displays real V/I/P for both channels (4 Hz update)
3. ✓ Protection flags displayed as visual indicators (red/yellow chips if triggered)
4. ✓ Graph page shows dual traces (V and I) with adjustable timebase
5. ✓ RUN/STOP button toggles CH1 output enable/disable (or per-channel toggle)
6. ✓ V/A button allows current-limit editing (stored in Setup, used for OCP compare)
7. ✓ Guarded build/flash workflow passes for CrowPanel target
8. ✓ No regression in screen navigation or render stability
9. ✓ STM32 ↔ CrowPanel UART link confirmed with bench-captured data

---

**Document Version:** 1.0  
**Last Updated:** 2026-07-03  
**Status:** Ready for Development Sprint  
**Next Review:** After Phase 5a UI skeleton checkpoint (Day 5)

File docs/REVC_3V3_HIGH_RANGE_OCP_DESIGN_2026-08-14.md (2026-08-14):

# Rev-C 3.3V High-Range Differential OCP Design

Date: 2026-08-14

Status: First-channel design baseline; schematic implementation and bench validation pending.

## Design target

This circuit replaces the Rev-B U3A absolute-voltage comparison for the 3.3V high-current range.

| Item | Design value |
|---|---:|
| Rail | 3.3V |
| Shunt | R16, 20mΩ |
| Nominal rising trip | 2.00A |
| Nominal reset | approximately 1.97A |
| Fault polarity | Active high into `FAULT_CRITICAL_SUM` |
| Response target | Less than 10µs before fault-bus loading effects |

The 2.00A target follows the current provisional CH2 maximum in `docs/PHASE_5_PARAMETER_INTEGRATION_DESIGN.md`. It must be reviewed before the Rev-C schematic is released.

## Selected signal chain

Use an INA180A2 current-sense amplifier followed by one TLV1704 comparator channel.

### TLV9352 standardization assessment

TLV9352 remains the standard Rev-C regulator feedback-selector op amp, but it should not replace the INA180A2 in this OCP channel.

| Consideration | TLV9352 discrete differential stage | INA180A2 current-sense stage |
|---|---|---|
| Minimum supply | 4.5V; cannot operate from `+3.3V Boot` | Operates from `+3.3V Boot` |
| High-side 3.3V/5V common mode | Valid when TLV9352 is powered from 12V | Rated from -0.2V to 26V |
| Maximum input offset used for design | Up to 1.8mV over specified conditions | 150µV family maximum |
| Gain of 50 | Requires four precision, ratio-matched resistors | Factory trimmed |
| Common-mode rejection | Dominated by external resistor-ratio matching | 84dB minimum family specification |
| Layout sensitivity | Four-resistor differential network | Direct Kelvin input pair |

At R16 = 20mΩ, 1.8mV of TLV9352 input offset is equivalent to 90mA before resistor-ratio, reference, shunt, and comparator errors are included. The INA180's 150µV maximum corresponds to 7.5mA.

The second TLV9352 channel should not replace TLV1704 merely to reduce IC types. TLV9352 has a push-pull output referenced to its supply, while TLV1704 provides the open-drain output required for the 3.3V-pulled fault wired-OR. A TLV9352 powered from 12V would require an additional level-shift or open-drain transistor stage.

**Standardization decision:** Standardize by function rather than forcing one device into every analog role:

- TLV9352: regulator remote/local feedback selectors.
- INA180 family: high-side shunt differential amplification.
- TLV1704: multi-channel threshold comparison and `FAULT_CRITICAL_SUM` wired-OR.

```text
3V3 regulator side                         3V3 load side
      |                                          |
      +----[ R16 20mΩ, Kelvin pads ]-------------+
             | K+                    K- |
             |                          |
             +---- INA180A2 IN+  IN- ---+
                          VS = +3.3V Boot
                          GND = GND
                          OUT = 50 x (VK+ - VK-)
                                    |
                                  10kΩ
                                    +------ TLV1704 +IN
                                    |              OUT ----+---- D4 ---> FAULT_CRITICAL_SUM
                                  470pF                     |
                                    |                      10kΩ
                                   GND                      |
                                                             +3.3V Boot
                                    +------ 1MΩ -------------+

REF3120 2.048V --- 1.50kΩ ----+---- TLV1704 -IN
                                |
                              43.2kΩ
                                |
                               GND
```

The 1MΩ connection from comparator output to `+IN` provides positive feedback. The existing D4 isolation position may be retained, but its polarity and the complete fault-bus truth table must be checked after annotation.

## Component values

| Function | Part/value | Requirement |
|---|---|---|
| Current-sense amplifier | INA180A2IDBVR | Gain 50V/V, SOT-23-5 |
| Amplifier bypass | 100nF X7R | At INA180 VS pin |
| Shunt | 20mΩ, 1%, four-terminal preferred | Use Kelvin routing even if a two-terminal footprint is retained |
| Comparator | One TLV1704 channel | Existing 12V-powered comparator is suitable |
| Comparator input resistor | 10.0kΩ, 0.1% | INA output to comparator `+IN` |
| Comparator filter capacitor | 470pF C0G/NP0 | Comparator `+IN` to GND |
| Hysteresis resistor | 1.00MΩ, 1% | Comparator output to comparator `+IN` |
| Comparator pull-up | 10.0kΩ | Comparator output to `+3.3V Boot`; replace the weak 100kΩ value |
| Threshold reference | REF3120AIDBZR, 2.048V | SOT-23-3; power from `+3.3V Boot` |
| Reference input bypass | 100nF X7R | REF3120 input to GND at the device |
| Threshold upper resistor | 1.50kΩ, 0.1% | REF3120 output to comparator `-IN` |
| Threshold lower resistor | 43.2kΩ, 0.1% | Comparator `-IN` to GND |
| Threshold bypass | 100nF C0G/X7R | Comparator `-IN` to GND |

Do not place ordinary RC series resistors in the INA180 Kelvin inputs without calculating their gain error. Provide optional symmetric 0Ω footprints and a DNP differential capacitor only if bench noise requires input filtering.

## Nominal calculations

At 2.00A:

`VSHUNT = 2.00A * 0.020Ω = 40.0mV`

`VINA = 40.0mV * 50 = 2.000V`

The threshold divider produces:

`VTH = 2.048V * 43.2kΩ / (43.2kΩ + 1.50kΩ) = 1.9793V`

With the comparator output low before a trip, the 10kΩ/1MΩ positive-feedback network gives:

`ITRIP = VTH * (1 + 10kΩ / 1MΩ) / (50 * 0.020Ω) = 1.999A`

After the output releases high to 3.3V:

`IRESET = [VTH * (1 + 10kΩ / 1MΩ) - 3.3V * 10kΩ / 1MΩ] / (50 * 0.020Ω) = 1.966A`

Nominal hysteresis is approximately 33mA.

At the 2A trip point, R16 dissipates:

`PSHUNT = I²R = 2.00² * 0.020Ω = 80mW`

## Accuracy budget to verify

The INA180 family data lists up to 150µV input offset and 0.8% gain error. At R16 = 20mΩ, 150µV corresponds to 7.5mA input-referred current error. Gain error contributes approximately 16mA at 2A. Shunt tolerance, threshold-reference accuracy, resistor ratio, PCB thermal gradients, and comparator offset must be added to establish the final guaranteed trip band.

REF3120 is specified for a 2.55V to 5.5V input, 0.2% maximum initial accuracy, and 20ppm/°C maximum drift from -40°C to +125°C. Its initial accuracy alone contributes up to approximately 4mA of trip uncertainty in this 1V/A signal chain.

The TLV1704 maximum 2.5mV input offset is approximately 2.5mA referred to load current because the signal-chain transimpedance is 1V/A. This remains subject to verification across temperature.

## Layout requirements

1. Route K+ and K- independently from the inner edges of the R16 pads; neither trace may carry load current.
2. Route the Kelvin pair together and away from MOSFET gates, switch nodes, inductors, and fault-bus edges.
3. Place INA180 next to R16. Place its 100nF bypass directly between VS and GND.
4. Keep the INA180 output-to-comparator trace short. Place the 10kΩ, 470pF, and 1MΩ parts at the comparator pins.
5. Return the amplifier, filter capacitor, threshold divider, and reference to a quiet analog ground point, then join that point to the board ground plane away from shunt load-current spreading.
6. Add test points for K+, K-, `OCP_3V3_HIGH_AMP`, `OCP_3V3_HIGH_REF`, and comparator output.

## Fault behavior and limits

- Normal current: `VINA < VTH`; TLV1704 output sinks low; D4 does not assert the fault bus.
- Overcurrent: `VINA > VTH`; TLV1704 output becomes high impedance; the 10kΩ pull-up drives the isolated fault output high.
- Comparator unpowered: its open-drain output is high impedance, so the pull-up tends to assert a fault. Confirm this at the complete fault bus.
- INA180 unpowered or disconnected is not inherently fail-safe and may appear as zero current. Firmware plausibility checks and power-good supervision remain necessary.
- This is a fixed emergency ceiling, not the normal programmable current regulator. Firmware may enforce a lower user setting.

## Bench validation gate

1. Validate with the range MOSFET bypass retained and the bench PSU current limit set below the expected destructive level.
2. Confirm zero-load amplifier output and record offset.
3. Apply 0.5A, 1.0A, and 1.5A; compare measured `VINA` against `1.000V/A` nominal scaling.
4. Ramp through trip at least five times and record rising trip, reset current, response time, and temperature.
5. Repeat at minimum and maximum intended rail voltage and after thermal soak.
6. Apply representative load steps and switching events below 1.8A; require no false trips.
7. Open each Kelvin connection individually and record behavior before deciding whether additional sense-open diagnostics are required.

## Deferred decisions

- Lock the guaranteed 3.3V channel current rating and allowed trip tolerance.
- Confirm the REF3120AIDBZR footprint and local availability during BOM review.
- Decide whether the fixed 2A ceiling is sufficient or a DAC-controlled hardware threshold is required.
- Design the 200mΩ low-current channel separately; reusing gain 50 would saturate near 330mA on a 3.3V amplifier supply.

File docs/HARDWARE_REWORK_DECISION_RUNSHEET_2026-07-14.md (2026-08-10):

# Hardware Rework Decision Runsheet (2026-07-14)

Purpose: lock a safe hardware baseline before firmware checkout by deciding, validating, and executing restore-or-keep actions for known removed parts and added jumpers.

Scope: regulator board and HAT board hardware state only.

Policy: safety-first temporary state is valid. Do not restore parts just to match nominal BOM unless pass gates are met.

## Confirmed As-Built Hardware State

Use this as the source of truth before touching hardware.

| Board | Item | Current state | Action class |
|---|---|---|---|
| Regulator | U5 | Removed after failed reintroduction (~7V channel drive) | Keep removed for this revision |
| Regulator | R15 | Removed | Do not reinstall (wrong connection point) |
| Regulator | R28 | Removed | Do not reinstall (wrong connection point) |
| Regulator | R9 | Reinstalled | Hold and validate |
| Regulator | R10 | Reinstalled | Hold and validate |
| Regulator | VSENSE_3V3+ -> +3.3V_Reg | Jumper removed | Hold and validate |
| Regulator | +5V_Reg -> VSENSE_5V+ | Jumper added | Temporary workaround |
| HAT | U3 | Removed | Restore candidate |
| HAT | U4 | Removed | Restore candidate |
| HAT | D1 | Removed after heating observation | Temporary removal |
| HAT | D2 | Removed after heating observation | Temporary removal |

## Global Stop Rules

1. Stop immediately on PSU current foldback, smoke, odor, or fast thermal rise.
2. Stop immediately if +5V or +3.3V exceeds safe expected range during startup.
3. Do not perform stacked tests while this runsheet is in progress.
4. Revert only the most recent hardware change when recovering from regression.

## Bench Setup

| Item | Required state | Actual |
|---|---|---|
| Bench PSU | 12V preset, output off at setup | |
| Current limit | Conservative start 0.10A to 0.20A | |
| DMM | Continuity and DC rails ready | |
| Thermal check | IR thermometer or thermal camera ready | |
| Serial monitor | Ready for active firmware heartbeat logs | |
| Log capture | One worksheet/photo log per step | |

## Phase 1 - Freeze Baseline (No Solder Changes)

### 1.1 Photo and continuity record

1. Capture clear top/bottom photos for both boards.
2. Mark each removed part location as verified empty.
3. Confirm both temporary jumpers are physically present and solid.
4. Run continuity checks around changed pads for obvious shorts.

| Check | Result | Notes |
|---|---|---|
| Regulator U5 pad area clean | | |
| Regulator R15/R28/R9/R10 pad areas clean | | |
| HAT U3/U4 pad areas clean | | |
| HAT D1/D2 pad areas clean | | |
| Jumper VSENSE_3V3+ -> +3.3V_Reg absent (as expected) | | |
| Jumper +5V_Reg -> VSENSE_5V+ present | | |

### 1.2 Powered baseline capture

Status: WAIVED by user decision for this session. No additional Phase 1.2 data required before proceeding.

Previously captured reference values are retained for trace only.

| Measurement | Expected trend | Actual |
|---|---|---|
| VIN current at power-on | No runaway or foldback | Not captured in this log |
| VIN current at 10s | Stable | Not captured in this log |
| VIN current at 2 to 5 min | Stable drift only | 71mA at VIN 11.98V (Blue Pill installed) |
| U5 behavior signal note | No saturation or unstable toggling | Prior issue still open: saturation/unstable behavior reported |
| +5V_Reg | Present and stable | 4.91V |
| +3.3V_Reg | Present and stable | 3.25V |
| +5V_Boot | Present and stable | 4.91V |
| +3.3V_Boot | Present and stable | 3.28V |
| Hotspot location | No rapid rise trend | |
| Serial heartbeat | Present, no reset loop | |

Gate to continue:
1. Phase 1.2 is waived for this session by explicit user direction.
2. Continue using safety-first stop rules during all remaining steps.

## Phase 2 - Keep or Restore Decision Gates

Use this matrix before each physical change.

| Item | Keep for firmware checkout if... | Restore now only if... |
|---|---|---|
| Regulator U5 | Keep removed; reintroduction already caused about 7V channel drive | Only after topology redesign that guarantees headroom and output clamping |
| Regulator R15/R28 | User decision is to keep removed due to wrong connection point | Future PCB revision updates the schematic/net placement before any reintroduction |
| Regulator R9/R10 | Reinstallation remains stable in current bench state | Regression appears during continued bench validation |
| HAT U3 | Immediate test does not require U3 function | Firmware objective needs its path now and board remains stable after restore |
| HAT U4 | Immediate test does not require U4 function | Firmware objective needs its path now and board remains stable after restore |
| HAT D1/D2 | Thermal behavior remains stable without these parts and no clamp/protection fault appears | Part rating and orientation are re-verified for 12V conditions |
| VSENSE jumpers | Cold-start without jumper has not been proven safe | A controlled challenge test passes without overvoltage/instability |

## Phase 3 - Staged Physical Rework Sequence

Order is mandatory. Do not skip forward.

### Step A - No-change validation

1. Phase 1.2 remains waived for this session.
2. Use current recorded baseline plus live safety stop rules during operation.
3. Enter firmware checkout gate directly or continue to Step B if additional hardware changes are required.

### Step B - HAT restore steps (optional, scope-driven)

1. Restore one IC only (U3 or U4 based on immediate firmware objective).
2. Unpowered continuity/short check.
3. Power at conservative current limit.
4. Capture rail/current/thermal/serial status at 10s and 2 to 5 min.

| Step B item | Performed | Pass/Fail | Notes |
|---|---|---|---|
| Restore U3 | | | |
| Restore U4 | | | |

### Step C - Regulator resistor restore steps (optional, scope-driven)

1. R15 and R28 are excluded from restore work by user decision (wrong connection point).
2. Only validate stability of already-reinstalled R9 and R10 during normal operation.
3. Run unpowered continuity check only if a new change is introduced.
4. Log any regression against current reference values.

| Step C item | Performed | Pass/Fail | Notes |
|---|---|---|---|
| Keep R15 removed (intentional) | | | |
| Keep R28 removed (intentional) | | | |
| Validate R9 reinstallation stability | | | |
| Validate R10 reinstallation stability | | | |

### Step D - Regulator U5 reintroduction (deferred by default)

Removed from current revision workflow by user decision after failed reintroduction.

1. Do not restore U5 during firmware checkout.
2. Preserve U5 as depopulated in all current bench validations.
3. Reintroduction is moved to future-revision hardware redesign testing only.

| Step D item | Performed | Pass/Fail | Notes |
|---|---|---|---|
| Keep U5 removed (intentional) | | | |
| U5 redesign required before reintroduction | | | |

### Step E - Jumper challenge test (optional, high caution)

1. Remove one jumper only.
2. Run current-limited cold start while watching rails.
3. If instability appears, power off and restore jumper immediately.
4. Repeat for the other jumper only after first challenge is clean.

| Step E item | Performed | Pass/Fail | Notes |
|---|---|---|---|
| Challenge VSENSE_3V3+ -> +3.3V_Reg jumper | | | |
| Challenge +5V_Reg -> VSENSE_5V+ jumper | | | |

## Firmware Checkout Entry Gate

Proceed only when all selected hardware changes are stable and both conditions below pass:

1. Two consecutive clean power cycles with no foldback, no rail collapse, no reset loop.
2. No unresolved thermal rise trend at any modified area.

| Entry gate check | Pass/Fail | Notes |
|---|---|---|
| Two clean consecutive power cycles | | |
| Thermal trend acceptable | | |
| Firmware checkout unlocked | | |

## Rollback Rule

If any step fails, revert only the latest change and re-run baseline checks. Do not alter multiple components at once during recovery.

## Firmware Checkout Implementation Addendum (2026-07-14)

Scope: firmware-only implementation aligned to current baseline where HAT U3/U4 remain removed and U5 is the installed AHT20 I2C sensor.

Controller decision update: ESP32-C6 path is retired for this bring-up branch. STM32 Blue Pill is the active and only firmware target.

### Execution checklist

1. STM32 Blue Pill build (`stm32-bluepill-bringup`, env `bluepill_f103c8`) completes.
2. STM32 flash/program path uses ST-Link only (no ESP32 guarded flash workflow).
3. STM32 serial command set available: HELP, FTEST, AHTNOW, AHTRESET, SRTEST.
4. U5 AHT20 bring-up path active on I2C address 0x38 with init, measurement, and recovery handling.
5. Shift-register interface-only test emits deterministic patterns over SPI + SR_Latch without requiring U4 population.
6. W25Q128 JEDEC/erase/program/readback bring-up implementation passes at boot and can be rerun on-demand via FTEST.

### Current execution status

| Item | Result | Notes |
|---|---|---|
| STM32 Blue Pill build | PASS | `bluepill_f103c8` build succeeds after command-set and sensor/SR integration updates. |
| STM32 W25Q128 implementation | PASS (build) | JEDEC + erase/program/readback flow present and build-verified in `stm32-bluepill-bringup/src/main.cpp`. |
| STM32 manual flash re-test command | PASS (firmware) | `FTEST` reruns flash bring-up test on demand over Serial and SerialDbg. |
| STM32 AHT20 implementation (U5 @ 0x38) | PASS (firmware) | Added init/read/reset path on PB8/PB9 I2C in `stm32-bluepill-bringup/src/main.cpp`. |
| STM32 shift-register interface self-test | PASS (firmware) | Added `SRTEST` SPI pattern sweep with PA4 latch pulse in `stm32-bluepill-bringup/src/main.cpp`. |

### Hardware-dependent gate still open

1. Live on-hardware validation completed for the current firmware scope (command parser, AHT20, SR interface test, W25Q128 test).
2. Device-level shift-register channel verification remains deferred while U4 is intentionally depopulated.

### STM32 Live Evidence (Captured)

1. ST-Link upload completed with verify OK (`bluepill_f103c8`, OpenOCD reset + verify pass).
2. Serial monitor on COM7 stable at 115200 with continuous heartbeat (`hb`).
3. Command parser confirmed:
	- `HELP` returned `cmd: HELP | FTEST | AHTNOW | AHTRESET | SRTEST`
4. AHT20 path confirmed:
	- `AHTRESET` returned `aht20: reset + probe OK`
	- `AHTNOW` returned valid numeric sample: `aht20: T=31.08C RH=31.61% status=0x18`
5. Shift-register interface test confirmed:
	- `SRTEST` logged full deterministic pattern sweep from `0x0000` through `0x0F00` with begin/end markers.
6. W25Q128 memory path confirmed:
	- `FTEST` output: `JEDEC ID mfg=0xEF type=0x40 cap=0x18`, `SR1 before=0x00`, `erase/program/readback PASS`.
7. Automatic periodic health summary confirmed:
	- `status: flash=PASS aht=PASS T=30.12C RH=32.94% runs=1`
	- `status: flash=PASS aht=PASS T=30.00C RH=32.99% runs=1`

### Closeout Decision (This Session)

1. Firmware checkout scope for STM32 baseline is CLOSED as PASS.
2. Remaining open item is hardware-population dependent only: U4-deferred device-level channel verification.
3. Next session should start from STM32-only path; do not resume ESP32-C6 guarded upload flow for this branch.

## 2026-07-14 Delta Notes

1. R9 and R10 were reinstalled.
2. VSENSE_3V3+ -> +3.3V_Reg jumper was removed.
3. +5V_Reg -> VSENSE_5V+ jumper remains in place.
4. U5 behavior is reported as output saturation/unstable when powered from +5V_Boot path.
5. HAT D1 and D2 were removed after heating observations and voltage-rating concern at 12V bench conditions.
6. User decision: Phase 1.2 is waived as not necessary for this session.
7. User decision: R15 and R28 will remain removed and are not to be reinstalled in current hardware.
8. Future revision action: delete R15 and R28 from the design path or relocate them to the correct connection point in schematic/PCB.
9. U5 reintroduced-and-removed event: channel drove to about 7V during test.
10. User direction: keep U5 removed for this revision due to supply-headroom limitation in current topology.
11. Future revision action: redesign U5 supply/reference/output-limiting path before any reintroduction attempt.

## Session Record

| Date/time | Change made | Outcome | Next action |
|---|---|---|---|
| 2026-07-14 | Baseline measurement with Blue Pill installed and current hardware state | VIN 11.98V, 71mA; +5V_Reg 4.91V; +3.3V_Reg 3.25V; +5V_Boot 4.91V; +3.3V_Boot 3.28V | Capture hotspot location and startup (power-on and 10s) current points |
| 2026-07-14 | STM32 firmware integration for AHT20 + SR interface + W25Q128 + command shell | Build and ST-Link upload PASS; serial command set active (`HELP/FTEST/AHTNOW/AHTRESET/SRTEST`) | Capture live command evidence and lock runsheet status |
| 2026-07-14 | Live command validation on COM7 | `AHTNOW` valid data, `AHTRESET` pass, `SRTEST` pattern sweep pass, `FTEST` flash pass | Enable startup/periodic status reporting and capture trend lines |
| 2026-07-14 | Startup self-check + periodic status monitoring enabled | Repeating status lines show `flash=PASS aht=PASS` with stable numeric T/RH samples | Session closeout complete; next work is deferred U4 device-level verification |

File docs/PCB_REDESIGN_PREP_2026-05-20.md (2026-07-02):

# PCB Redesign Prep (2026-05-20)

Goal: Capture all known schematic edits and board-split decision points so Rev-C can be ordered with confidence.

**Current State**: Two-board split (Regulator + HAT) with increased signal traffic. Decision pending: keep split or merge to single board?

---

## Current Active Plan (2026-06-09): USB Hub + STM32 Integration

Objective for this cycle:
- Preserve the original USB hub value (power + port management + metering intent)
- Restore strong STM32 flashing/programming capability after the ESP32-to-STM32 migration
- Keep connector mechanics and external role expectations as stable as practical

Confirmed decisions (locked for this cycle):
1. Scope is hardware-only (schematic + PCB planning/execution).
2. Add an onboard USB-to-SWD debug bridge on the USB hub redesign.
3. Keep high-rate USB serial telemetry path independent (CH340C path on HAT remains runtime telemetry).
4. Preserve existing external connector mechanics/roles as much as possible.
5. Consume one existing flashing/data port budget for the internal SWD bridge path (simplest route).

### Execution Phases (Current)

| Phase | Focus | Exit Criterion |
|---|---|---|
| 0 | Baseline lock + topology map | Port-role map frozen and documented for redesign start |
| 1 | Bridge architecture lock | USB-to-SWD bridge electrical contract frozen |
| 2 | Hub schematic integration | One downstream data path reassigned to onboard bridge |
| 3 | STM32 tie-in contract | SWDIO/SWDCLK/NRST/GND/VTref board-to-board contract validated |
| 4 | PCB implementation | Placement and routing constraints applied for USB + SWD paths |
| 5 | Validation + freeze | ERC/DRC/netlist checks pass and docs updated |

### Kickoff Status (Started 2026-06-09)

Completed now:
1. Baseline target for edits locked to `hardware/kicad/usb-hub-next-iter/USB Hub Next Iter.kicad_sch`.
2. Existing hub role map confirmed from netlist:
   - Upstream host data: `Port H_D+`, `Port H_D-`
   - Downstream data ports: `Port 1_D+/-`, `Port 2_D+/-`, `Port 3_D+/-`, `Port 4_D+/-`
   - Power-only USB-A intent retained for J4/J6 (D+/D- intentionally NC)
3. STM32-side programming + telemetry baseline confirmed:
   - SWD header path present on HAT (`J19`)
   - USB serial telemetry path present (`CH340C` + `J20`)

In progress next:
1. Phase 1 bridge selection and SWD electrical contract freeze.
2. Phase 2 reassignment of one hub downstream data path to the internal bridge in `usb-hub-next-iter` schematic.
3. Tracker updates and explicit closure gates for flash + telemetry coexistence.

### Immediate Work Queue (Next 3 Tasks)

1. Freeze bridge implementation details (signal list, power domain behavior, protection strategy).
2. Add a new redesign issue entry in USB hub tracker for internal SWD-bridge integration work.
3. Define/record which existing flashing data port is consumed by the internal bridge and mark resulting external role update.

### Phase 1 Started: Bridge Electrical Contract Draft

Use this checklist to freeze the bridge contract before editing net topology.

Required USB-side signals:
- `USB_BRIDGE_DP`
- `USB_BRIDGE_DM`
- `USB_BRIDGE_VBUS_SENSE`
- `USB_BRIDGE_GND`

Required target-side signals (STM32):
- `SWDIO`
- `SWDCLK`
- `NRST`
- `VTref` (target voltage sense/reference)
- `GND`

Conditioning/protection requirements:
1. Add series damping (initial target 22-47 ohm) on SWDIO/SWDCLK near bridge output pins.
2. Keep NRST polarity and pull behavior compatible with existing STM32 path.
3. Prevent back-power paths when bridge is USB-powered but target is not.
4. Ensure all bridge I/O connected to STM32 are valid at target voltage domain.

Freeze gates (must be YES before Phase 2 net reassignment):
- Gate A: Bridge USB side is electrically isolated from non-selected downstream ports.
- Gate B: SWD and NRST signaling path is complete end-to-end (bridge -> inter-board contract -> STM32).
- Gate C: CH340C runtime telemetry path remains unchanged and independent.
- Gate D: Power-only USB-A roles (J4/J6 intent) remain unchanged.
- Gate E: ERC has no new hard errors attributable to bridge insertion.

#### Bridge Pin-Level Contract (Draft v0)

| Bridge function | Net label (target) | Notes |
|---|---|---|
| USB D+ input | `USB_BRIDGE_DP` | Comes from selected hub downstream D+ pair |
| USB D- input | `USB_BRIDGE_DM` | Comes from selected hub downstream D- pair |
| USB VBUS detect | `USB_BRIDGE_VBUS_SENSE` | Sense only; do not use as backfeed source |
| USB ground | `USB_BRIDGE_GND` | Tie to local digital ground reference |
| SWD data | `SWDIO_BRIDGE_OUT` | Route to STM32 SWDIO contract with series damping |
| SWD clock | `SWDCLK_BRIDGE_OUT` | Route to STM32 SWDCLK contract with series damping |
| Target reset | `NRST_BRIDGE_OUT` | Preserve active-low behavior to STM32 NRST |
| Target reference | `VTREF_BRIDGE_IN` | Bridge level reference from STM32 target rail |
| Target ground | `SWD_GND_REF` | Common SWD reference return |

#### Electrical Constraints (Draft v0)

1. Place 22-47 ohm series resistors at bridge outputs for `SWDIO_BRIDGE_OUT` and `SWDCLK_BRIDGE_OUT`.
2. Keep `NRST_BRIDGE_OUT` pull network compatible with existing STM32 reset behavior.
3. Do not allow bridge I/O to source STM32 rail when target rail is absent.
4. Keep bridge-to-target SWD routing short and avoid shared high-current return bottlenecks.
5. Keep bridge USB pair stubs short from hub path to bridge input.

### Phase 2 Prep: Provisional Downstream Port Assignment

Provisional selection for internal bridge USB feed:
- Use `Port 2_D+` / `Port 2_D-` as the consumed downstream data path for the onboard USB-to-SWD bridge.

Rationale for provisional pick:
1. `Port 3_D+/-` is tied into additional smart-charging path logic and is not the cleanest first reassignment target.
2. J4/J6 are intentionally power-only and are excluded from consideration.
3. A single clean downstream pair is required to move forward with minimal topology churn.

Validation required before hard-freeze:
1. Confirm connector-level mapping for the physical flashing port currently associated with `Port 2_D+/-`.
2. Confirm that reassignment of `Port 2_D+/-` does not break required external user-facing data behavior.
3. If either check fails, fallback candidate is `Port 1_D+/-`.

### Pack 2 Verification Snapshot (2026-06-09)

Verified from refreshed netlist/ERC:
1. `Port 2_D+/-` is reassigned to internal bridge USB path using `USB_BRIDGE_DP` / `USB_BRIDGE_DM`.
2. Bridge-to-STM32 debug handoff connector present: `J11` value `STM32_SWD_BRIDGE_OUT`.
3. Series damping installed: `R27 = 33 ohm` (SWDIO path), `R28 = 33 ohm` (SWDCLK path).
4. Current ERC state is warning-only for redesign additions (no hard architectural blocker).
5. Latest refreshed ERC baseline is now 0 errors / 5 warnings (library/footprint housekeeping only).

Locked role decision for this pass:
1. External Port 2 data role is consumed by internal STM32 programming bridge path.
2. Upstream host path (`Port H_D+/-`) and non-selected downstream channels remain unchanged in this pass.
3. J4/J6 remain power-only by design intent.

Remaining cleanup (non-blocking for topology lock):
1. Keep net naming consistent between schematic labels and connector pinout notes before PCB floorplanning.

### Priority Shift (2026-06-09): Order Regulator + HAT First

Execution order update:
1. Defer USB hub PCB placement/routing until regulator and HAT boards are finished and ready for order.
2. Keep USB hub schematic/netlist as staged integration baseline while upstream boards are closed.

Immediate gate before regulator/HAT release:
1. `scripts/verify-connector-contract.ps1 -Mode reduced` currently fails 4 required mappings.
2. Fix these connector-contract nets first, then rerun reduced and baseline checks.

Current failing mappings to resolve:
1. `VSENSE_ADJ+` (expected Reg `J2-12` <-> HAT `J6-12`)
2. `VSENSE_ADJ-` (expected Reg `J2-11` <-> HAT `J6-11`)
3. `ISET_MPU_Channel_3` (expected Reg `J2-5` <-> HAT `J6-5`)
4. `+V Adj Channel` (expected Reg `J2-13` <-> HAT `J6-13`)

#### Net Reassignment Mapping (Implementation Draft v0)

Current path (from netlist):
1. `J10 D+/-` feeds ESD stage `U10 I/O1/I/O2`.
2. `U10` feeds hub downstream nets `Port 2_D+` / `Port 2_D-`.
3. Hub controller `U7` consumes `Port 2_D+` / `Port 2_D-` as one external downstream channel.

Planned reassignment:
1. Keep `J10` mechanical connector unchanged unless layout forces otherwise.
2. Reassign `Port 2_D+` / `Port 2_D-` channel to internal bridge nets `USB_BRIDGE_DP` / `USB_BRIDGE_DM`.
3. Document the external role change: the prior Port 2 flashing/data path becomes internal STM32 programming path.
4. Keep `Port H_D+/-` upstream and other downstream channels unchanged for this pass.

Pre-edit schematic checklist:
1. Confirm `J10` is the active physical port associated with `Port 2_D+/-` in current files.
2. Add explicit net labels for bridge USB input and SWD output paths before rerouting.
3. Preserve existing ESD intent while changing only the downstream ownership of the selected channel.

### Phase 4 Handoff Constraints (PCB)

1. Place `J11`, `R27`, and `R28` as a tight SWD cluster with short, direct routes to their source nets.
2. Keep bridge USB D+/D- traces from hub channel to bridge input short and matched as practical.
3. Keep the reassigned Port 2 branch free of unnecessary stubs and avoid crossings near switching power nodes.
4. Preserve clear reference return for SWD signals; avoid routing SWD over split return regions.
5. Maintain existing connector edge mechanics unless a documented mechanical conflict requires change.

---

## Phase 1: Signal Inventory (What Crosses Between Boards?)

### Regulator Board → HAT Board Signals

**Power & Measurement** (Feedback/Sense Pairs):
- `VSENSE_5V+` / `VSENSE_5V-` (5V output sensing, 2 lines)
- `VSENSE_3V3+` / `VSENSE_3V3-` (3.3V output sensing, 2 lines)
- `VSENSE_ADJ+` / `VSENSE_ADJ-` (Adjustable output sensing, 2 lines)

**Fault/Protection**:
- `FAULT_CRITICAL_SUM` (global OCP/fault line)

**Power Rails** (if not integrating):
- `+12V_IN` (input supply)
- `+5V_Reg` / `GND` (primary 5V distribution)
- `+3.3V_Reg` / `GND` (primary 3.3V distribution)
- `+V_Adj` / `GND` (adjustable channel output)
- `+5V_Boot` (bootstrap supply to control circuits)

**Total Current Connector Count**: 13 signals (power/fault/sense) + GND/Vcc repeats

### 2026-05-22 Implementation Kickoff: Verified Cross-Board Contract

Netlist verification from both Rev-B exports confirms the active inter-board contract below.

| Group | Nets (current) | Count |
|---|---|---|
| Kelvin sense pairs | `VSENSE_5V+`, `VSENSE_5V-`, `VSENSE_3V3+`, `VSENSE_3V3-`, `VSENSE_ADJ+`, `VSENSE_ADJ-` | 6 |
| Feedback return paths | `Feedback 5V`, `Feedback 3.3`, `Feedback Adj Channel` | 3 |
| Rail-enable control | `ISET_MPU_5V`, ` ISET_MPU_3V3`, ` ISET_MPU_Channel_3` | 3 |
| Fault | `FAULT_CRITICAL_SUM` | 1 |
| Bootstrap naming (needs normalization) | `+5V_Boot`, `+5V_Bootstrap` | 2 names in use |

Implementation note:
- The signed-off naming policy is a single bootstrap contract, but Rev-B netlists still show both `+5V_Boot` and `+5V_Bootstrap` variants. Normalize this before final netlist release.

### 2026-05-24 Verification Snapshot: Reduced Contract Gate Closed

Status after script and netlist normalization pass:
- `scripts/verify-connector-contract.ps1 -Mode reduced`: **PASS** (0 failures).
- `scripts/verify-connector-contract.ps1 -Mode baseline`: **PASS** under default `-BaselineFeedbackPolicy reduced-policy` (feedback crossings treated as informational while reduced split is active).
- `scripts/verify-connector-contract.ps1 -Mode baseline -BaselineFeedbackPolicy strict`: **3 expected failures** (`Feedback 5V`, `Feedback 3.3`, `Feedback Adj Channel`) for legacy full-crossing baseline auditing.

Key closure details:
- Bootstrap naming is now normalized to single-name detection (`+5V_Boot`) in current Rev-B exports.
- Leading-space label artifacts in Rev-B schematics were normalized (`ISET_MPU_3V3`, `ISET_MPU_Channel_3`, `Memory_CS`) and netlists re-exported.
- Verifier still tolerates trimmed + legacy leading-space variants so older exports remain checkable without false negatives.
- Active gate for this redesign track is reduced mode; strict baseline remains available as an explicit audit mode.

### 2026-05-22 Target: Moderate Redistribution (Pin-Count Reduction First)

Goal: keep two boards for now, but move enough tightly coupled analog/protection logic to reduce connector dependency.

| Candidate move | Current owner | Proposed owner | Expected connector impact |
|---|---|---|---|
| OCP comparator stage (`U8/U9/U10`, trim network) | HAT | Regulator | Can remove/avoid cross-board comparator-driving dependencies and simplify fault routing ownership |
| Fault pull-up ownership (`FAULT_CRITICAL_SUM` pull-up strategy) | HAT side policy | Regulator-side ownership | Simplifies one-direction fault contract and reduces ambiguity at connector |
| Sense conditioning used only for split handoff | HAT | Regulator | Reduces duplicated analog handoff nodes and may allow fewer analog contract lines |

### Reduced-Connector Contract Candidates

Use this as the implementation screen before deciding one-board consolidation.

| Contract Option | Cross-board analog nets | Cross-board control/fault nets | Relative pin count | Decision signal |
|---|---|---|---|---|
| Current split (baseline) | 6 VSENSE + 3 Feedback | 3 ISET + 1 FAULT + power/ground | Highest | Keep only if redistribution gains are small |
| Reduced split (target) | Prefer only one analog scheme (either VSENSE pairs or feedback returns, not both) | Keep 3 ISET + 1 FAULT + required rails | Medium | Preferred if it materially reduces connector complexity |
| Single board | None | None | Lowest | Choose if reduced split still leaves a heavy connector contract |

Implementation rule for this revision:
1. Remove contract duplication first (do not carry both remote VSENSE pairs and duplicate feedback-return crossings unless required by measured behavior).
2. Normalize bootstrap naming to one net contract before any connector repin decisions.
3. If reduced split cannot drop connector complexity enough after ownership moves, promote one-board consolidation immediately instead of preserving a weak partition.

### 2026-05-23 Pivot: Production Connector Architecture (Two-Board Path)

Decision update:
- Pin-count-only optimization is no longer the primary design driver.
- Keep two boards, but replace hobby-style 2.54 mm breakaway headers with a production interconnect architecture.

Connector strategy (recommended):
1. **Power connector**: dedicated high-current board-to-board interface for rail transfer and power returns.
2. **Signal connector**: separate mezzanine interface for Kelvin sense, control, fault, and low-current references.

Why this pivot:
- Current interface relies on pin-ganging for rail current and leaves too few return/common paths.
- This is electrically workable but poor production practice for current density, grounding, and contact reliability.
- Splitting power and signal connectors allows cleaner return-path engineering and preserves two-board modularity.

### Connector Requirements (Must Be Defined Before Part Selection)

| Requirement | Target | Status |
|---|---|---|
| Per-rail max current (`+12V`, `+5V`, `+3.3V`, `+V Adj`) | Numeric values required | Open |
| Contact current derating rule | Use <= 70% of vendor rating at worst-case ambient | Open |
| Return path capacity | Total return contacts sized >= total outbound current capacity | Open |
| Minimum dedicated quiet grounds on signal connector | >= 3 (sense/control reference) | Open |
| Connector retention/keying | Positive latch or equivalent anti-mis-mate feature | Open |
| Mating cycle requirement | Define service-life target | Open |
| Stack-height compatibility | Must satisfy mechanical envelope and spacing constraints | Open |

### Proposed Connector Partition (Draft, Mixed Distribution)

| Connector | Carries | Notes |
|---|---|---|
| Connector A (`CLP/FW` pair #1) | Mixed set: power rails, returns, and subset of control/sense nets | Not a strict power-only connector |
| Connector B (`CLP/FW` pair #2) | Mixed set: remaining power returns plus control/sense/ground references | Not a strict signal-only connector |

Connector selection lock (2026-05-23):
- Use two identical Samtec CLP/FW pairs: `2x` (`CLP-110-02-L-D` + `FW-10-05-L-D-400-150-A`).
- Total inter-board positions available: `40` (20 per connector x 2 connectors).
- Allocation policy: mixed distribution across both connectors (do not assume clean power/control separation).

### Current Budget Worksheet (To Fill Before Final Connector Choice)

Working assumptions for v0 screening:
- Contact derating rule: use 70% of nominal rating.
- Active connector assumption from selected pair: 3.1 A/contact nominal, 2.17 A/contact derated.
- Rail-current assumptions are provisional design targets until bench characterization is logged.

| Rail / Group | Max current (A) | Candidate contact rating (A/contact) | Derated usable (A/contact) | Contacts required (N) | Current plan (N) | Margin |
|---|---|---|---|---|---|---|
| `+12V` feed | 1.0 (provisional) | 3.1 | 2.17 | 1 | 1 | 1.17 A |
| `+5V_reg` | 2.0 (provisional target) | 3.1 | 2.17 | 1 | 1 | 0.17 A |
| `+3.3V_Reg` | 1.5 (provisional target) | 3.1 | 2.17 | 1 | 1 | 0.67 A |
| `+V Adj` | 2.0 (provisional) | 3.1 | 2.17 | 1 | 1 | 0.17 A |
| Power return sum | 6.5 (sum of above) | 3.1 | 2.17 | 3 | 4 | 2.18 A |

Provisional source notes:
- `+5V_reg` and `+3.3V_Reg` starter targets are aligned to protection-sizing guidance captured in issue tracking (`2A` and `1.5A` examples).
- `+V Adj` and `+12V` values are temporary screening assumptions for connector-family down-select only.
- Replace all provisional values with measured/locked limits before freezing connector part numbers.

### Active Allocation Snapshot (2026-05-23 User Update)

Current working allocation:
- Signal pins used: 18
- Power rails: 3 rails at 3.0 A each
- Connector set: two identical CLP/FW pairs (40 total positions)

Capacity check using active contact assumption (3.1 A nominal, 2.17 A derated at 70%):
1. Outbound contacts per 3.0 A rail: `ceil(3.0 / 2.17) = 2`
2. Outbound power contacts for 3 rails: `2 x 3 = 6`
3. Required return contacts for 9.0 A total return: `ceil(9.0 / 2.17) = 5`
4. Total power-group contacts (outbound + return): `6 + 5 = 11`
5. Total used positions with current allocation: `18 (signal) + 11 (power) = 29`
6. Remaining spare positions: `40 - 29 = 11`

Result:
- Provisional PASS for pin-count capacity under the current 18-signal / 3x3 A allocation.
- Still HOLD for final freeze until exact net-to-pin assignment and return-path layout are checked.

### Draft 40-Pin Allocation Table (Dual CLP/FW, Mixed Pre-Layout Baseline)

Scope note:
- This table is the electrical allocation baseline (what each connector position class is reserved for).
- Distribution is intentionally mixed across both connectors.
- Physical connector placement, orientation, and trace routing in KiCad are separate layout tasks.

| Connector | Allocation group | Nets / function | Positions used |
|---|---|---|---|
| Connector A (`CLP/FW` pair #1) | Outbound power rails | Subset of rail contacts (`+12V`, `+5V_reg`, `+3.3V_Reg`) | 3 |
| Connector A (`CLP/FW` pair #1) | Power returns | `GND_power_return` | 3 |
| Connector A (`CLP/FW` pair #1) | Signal/control/fault/bootstrap/quiet grounds | Mixed subset of the 18-signal contract | 9 |
| Connector A (`CLP/FW` pair #1) | Spare / growth | Reserved margin | 5 |
| Connector B (`CLP/FW` pair #2) | Outbound power rails | Remaining rail contacts (`+12V`, `+5V_reg`, `+3.3V_Reg`) | 3 |
| Connector B (`CLP/FW` pair #2) | Power returns | `GND_power_return` | 2 |
| Connector B (`CLP/FW` pair #2) | Signal/control/fault/bootstrap/quiet grounds | Remaining subset of the 18-signal contract | 9 |
| Connector B (`CLP/FW` pair #2) | Spare / growth | Reserved margin | 6 |

Allocation totals check:
1. Connector A used: `3 + 3 + 9 + 5 = 20`
2. Connector B used: `3 + 2 + 9 + 6 = 20`
3. Combined positions: `20 + 20 = 40`
4. Matches active allocation baseline: `18 signal positions`, `11 power-group positions`, `11 spare positions`

### SMT Placement Study Gate (Board-Level, Before Pin Freeze)

Why this gate exists:
- Electrical allocation can pass on paper but still fail in practical placement/routing.
- SMT board-to-board connectors can help routing density and stack profile, but can hurt service robustness and assembly tolerance if placement is poor.

SMT help vs hurt checklist:
1. Helps when: short escape paths, clean return stitching, compact stack height, and no connector overhang conflicts.
2. Hurts when: weak solder-joint leverage under insertion force, poor probe/tool access, or dense fanout that forces long detours and reference breaks.

Placement study workflow (KiCad):
1. Create three placement variants using the same two CLP/FW connectors.
2. For each variant, do quick escape routing for critical groups (`VSENSE_*`, `FAULT_CRITICAL_SUM`, `ISET_*`, rails, and returns).
3. Run DRC and inspect courtyard overlap, keepout conflicts, and accessible rework/probe paths.
4. Score each variant against the matrix below.
5. Freeze only the best-scoring variant that passes hard gates.

Suggested variants:
- Variant A: connectors on one board edge, parallel orientation.
- Variant B: connectors near board centerline, parallel orientation.
- Variant C: staggered spacing (mixed orientation only if routing improves and assembly still passes).

Hard gates (must pass):
1. No DRC errors around connector fanout/courtyards.
2. Kelvin pair routing keeps stable reference adjacency and no forced long loops.
3. Power and return escape can meet copper width/via count targets without choke points.
4. Probe access remains for bring-up nets and fault/debug points.
5. Assembly/rework access supports iron/hot-air reach without shadowing critical parts.

Variant scoring matrix (quick decision tool):

| Variant | Escape routing complexity (1-5, higher is easier) | Return-path continuity (1-5) | Kelvin/control integrity (1-5) | Assembly/rework access (1-5) | Mechanical robustness (1-5) | Total (max 25) | Gate result |
|---|---|---|---|---|---|---|---|
| A | [fill] | [fill] | [fill] | [fill] | [fill] | [fill] | [PASS/HOLD/FAIL] |
| B | [fill] | [fill] | [fill] | [fill] | [fill] | [fill] | [PASS/HOLD/FAIL] |
| C | [fill] | [fill] | [fill] | [fill] | [fill] | [fill] | [PASS/HOLD/FAIL] |

Placement freeze output:
1. Selected variant ID.
2. Final connector coordinates/orientation committed in PCB layout.
3. Pin-number mapping updated to match real placement escape success.

### Connector Selection Gate (Pass/Fail)

Do not freeze connector part numbers until all checks pass:
1. All rails and returns meet derated current capacity with margin.
2. Across both connectors, quiet-ground allocation and net adjacency support Kelvin/control integrity.
3. Mechanical stack height and placement are compatible with enclosure constraints.
4. Selected families provide keying/retention suitable for repeated assembly/service.
5. PCB footprint availability and manufacturability are verified for both board sides.

### Initial Connector Shortlist (For Evaluation)

Use this as a sourcing/layout starting point. Final selection requires the current-budget worksheet and derating checks above.

| Role | Candidate family class | Typical strengths | Typical risks | Fit for this project |
|---|---|---|---|---|
| Power connector | High-current board-to-board power mezzanine | High current per contact, robust wipe force, good for grouped rails/returns | Larger footprint and stack-height impact | High |
| Power connector | Power blade or busbar-style board interconnect | Excellent current density and thermal margin | Mechanical integration complexity, cost | Medium-High |
| Power connector | Rugged wire-to-board power pair (board-stack via short harness) | High current, easy sourcing, robust crimp ecosystem | Loses pure board-stacking simplicity | Medium |
| Signal connector | Fine-pitch mezzanine board-to-board | High pin density for VSENSE/ISET/FAULT/grounds, compact | Lower current per pin, tighter assembly tolerance | High |
| Signal connector | Rugged micro mezzanine (latching) | Better retention and service robustness | Lower pin density and larger area | Medium-High |

Selection rule:
1. Choose power connector first from current-capacity/return-budget constraints.
2. Choose signal connector second from pin density, quiet-ground allocation, and assembly tolerance.
3. Do not collapse power and signal back into one connector unless current and grounding budgets still pass with margin.

### Candidate Series Matrix (v0 Starting Point)

| Role | Candidate series | Type | Why consider | Primary risk/check |
|---|---|---|---|---|
| Power connector | Samtec `CLP-110-02-L-D` + `FW-10-05-L-D-400-150-A` | Board-to-board mezzanine pair | User-selected Samtec pair; significant upgrade over prior hobby header approach | Confirm exact mating compatibility, current/contact limits, and mated-height window from datasheet |
| Signal connector | Samtec `CLP-110-02-L-D` + `FW-10-05-L-D-400-150-A` (second identical connector) | Board-to-board mezzanine pair | Same qualified part family as power connector; simplifies sourcing and assembly | Validate mixed allocation map (adjacency, return distribution, and crosstalk risk) |

Initial screening gate for candidate series:
1. Keep only options that meet derated current and return capacity from the worksheet.
2. Keep only options with available mating-height choices inside the target screening band (`H_mated = 8.0 .. 10.0 mm`, with 9.0 mm ideal).
3. Keep only options with positive retention or anti-mis-mate features for service handling.
4. De-prioritize options with long procurement lead-time unless second-source exists.

### Target-Height Filter (8.0 .. 10.0 mm Screening Band)

Purpose:
- Down-select connector families before part-number lock by checking whether each family offers viable mated-height options near the 9.0 mm target.

| Role | Candidate series | Mated-height options available in family | 8.0 .. 10.0 mm available? | Closest option to 9.0 mm | Height filter result |
|---|---|---|---|---|---|
| Power connector | Samtec `CLP-110-02-L-D` + `FW-10-05-L-D-400-150-A` | User-selected pair (datasheet confirmation pending) | [pending] | [pending] | HOLD (selected; verify height/current) |
| Signal connector | Samtec `CLP-110-02-L-D` + `FW-10-05-L-D-400-150-A` (second identical connector) | Same as selected power connector pair | [pending] | [pending] | HOLD (selected; verify height/current + signal allocation) |

Filter interpretation:
1. PASS: family has at least one practical option in 8.0 .. 10.0 mm, and one option close to 9.0 mm.
2. HOLD: incomplete datasheet confirmation or architecture variant (for example harness path).
3. FAIL: no practical options in 8.0 .. 10.0 mm.

### Candidate Scoring Matrix (v0, Pre-Measurement)

Scoring method:
- 5 = strong fit, 3 = acceptable with caveat, 1 = poor fit.
- Total score is pre-measurement only and must be re-scored after stack-height and sourcing checks.

#### Power Connector Candidates

| Candidate series | Derated current capacity fit | Return-path capacity fit | Mechanical stack/footprint risk | Service/retention fit | Sourcing risk | Total (max 25) | Provisional status |
|---|---|---|---|---|---|---|---|
| Samtec `CLP-110-02-L-D` + `FW-10-05-L-D-400-150-A` | 5 | 5 | 3 | 4 | 3 | 20 | **User-selected power candidate (verify datasheet details)** |

Power selection interpretation:
1. Power connector path is locked to Samtec `CLP-110-02-L-D` + `FW-10-05-L-D-400-150-A` per current user direction.
2. Remaining action is datasheet validation (mating fit, current/contact limits, and mated-height target window).

#### Signal Connector Candidates

| Candidate series | Pin-density fit (VSENSE/ISET/FAULT/grounds) | Quiet-ground allocation fit | Mechanical tolerance risk | Service/retention fit | Sourcing risk | Total (max 25) | Provisional status |
|---|---|---|---|---|---|---|---|
| Samtec `CLP-110-02-L-D` + `FW-10-05-L-D-400-150-A` (second identical connector) | 4 | 4 | 4 | 4 | 4 | 20 | **User-selected signal connector (identical CLP/FW pair; verify allocation + datasheet details)** |

Signal selection interpretation:
1. Signal connector path is locked to a second identical Samtec CLP/FW pair per current user direction.
2. Remaining action is pin-allocation validation (quiet grounds and sensitive nets) plus datasheet/source confirmation.

### Provisional Finalist Pair (Subject To Gate Closure)

Recommended pair for current direction:
1. Power: Samtec `CLP-110-02-L-D` + `FW-10-05-L-D-400-150-A` (user-selected, only active power path).
2. Signal: Samtec `CLP-110-02-L-D` + `FW-10-05-L-D-400-150-A` (second identical connector, user-selected).

Do not freeze part numbers yet:
- Final selection still depends on verified datasheet mating details (mated height and current/contact limits), confirmed rail limits, and procurement lead-time checks.

### Datasheet Validation Ledger (Selected PNs)

Purpose:
- Track exact evidence required to move selected connectors from HOLD to frozen.

Automated source-access status (2026-05-23):
- Attempted manufacturer/distributor extraction for selected PNs returned anti-bot or parse failures in this environment (HTTP 403/500 or no extractable content).
- Validation is therefore in structured HOLD state until manual datasheet values are copied into the table below.

| Item | Selected PN(s) | Required evidence | Current value | Source status | Gate status |
|---|---|---|---|---|---|
| Power mating compatibility | Samtec `CLP-110-02-L-D` + `FW-10-05-L-D-400-150-A` | Explicit mating statement in series datasheet/configurator | [pending] | Blocked via automated fetch (Samtec/Octopart/DigiKey mirror) | HOLD |
| M5 power mated height | Samtec `CLP-110-02-L-D` + `FW-10-05-L-D-400-150-A` | Nominal mated height + tolerance | [pending] | Blocked via automated fetch | HOLD |
| Power current/contact | Samtec `CLP-110-02-L-D` + `FW-10-05-L-D-400-150-A` | Current/contact rating + derated usable value | 3.1 A nominal (user-provided), 2.17 A derated @70% | User-provided from datasheet screenshot; automated fetch blocked | CONDITIONAL (await direct datasheet citation) |
| Signal mating compatibility | Samtec `CLP-110-02-L-D` + `FW-10-05-L-D-400-150-A` (second identical connector) | Explicit mating pair confirmation for second identical connector usage | [pending] | Same selected pair as power connector; automated fetch blocked | HOLD |
| M6 signal mated height | Samtec `CLP-110-02-L-D` + `FW-10-05-L-D-400-150-A` (second identical connector) | Nominal mated height + tolerance for second connector usage | [pending] | Same selected pair as power connector; automated fetch blocked | HOLD |
| Signal current/contact | Samtec `CLP-110-02-L-D` + `FW-10-05-L-D-400-150-A` (second identical connector) | Current/contact rating for signal connector | 3.1 A nominal (user-provided), 2.17 A derated @70% | User-provided from datasheet screenshot; automated fetch blocked | CONDITIONAL (await direct datasheet citation) |
| Procurement readiness | Both selected pairs | In-stock/lead-time snapshot from preferred distributors | [pending] | Blocked via automated fetch | HOLD |

Extraction completion rule:
1. Fill all `Current value` cells with numeric datasheet values and tolerance where applicable.
2. Copy exact source reference (datasheet title/revision/page) into session handoff notes.
3. Recompute RB-007 final pair numbers after M5/M6 are populated.
4. Move selected pair status from HOLD to PASS only after current and height checks both pass.

---

## Phase 2: Component Distribution Decision Matrix

### Current Two-Board Split (HAT + Regulator)

| Component | Board | Rationale |
|---|---|---|
| **Regulators** (U2/U3/U4: LM2596) | Regulator | Large heat-dissipation; requires thermal management separate from digital |
| **Output MOSFETs** (Q1–Q8) | Regulator | Power switching; heat + current path management |
| **Shunt resistors** (R13–R16, R20–R23) | Regulator | Current measurement points; should stay close to load rail for accuracy |
| **INA3221** (U1) | HAT | Digital telemetry; I2C to ESP32 |
| **OCP Comparators** (U8/U9/U10) | HAT | Fast fault detection; easier integration with fault bus |
| **Threshold trimmers** (POT1–POT6) | HAT | User adjustable; on same board as comparators for signal integrity |
| **ESP32 MCU** (U7) | HAT | Digital control/telemetry host |
| **Power entry / terminal block** | Regulator | Input 12V supply management |
| **Feedback op-amps** (Selector circuit) | Regulator | Analog measurement path; close to sense points improves PSRR |

---

## Phase 3: Known Pending Schematic Edits (All Boards)

### Regulator Board (DSP-Regulator Rev-B)

| Issue ID | Status | Description | Components Affected | Action |
|---|---|---|---|---|
| RB-001 | 🟡 Implemented | 3-channel Kelvin selector for feedback | U5/U6 (op-amp), C7/C11/C21 (feedback caps), R31–R36, BAT54C diodes | Bench validation pending; no additional edits needed |
| RB-003 | 🟡 Implemented | MOSFET gate-drive control topology | Q2/Q3/Q16 (BSS138), R1/R5/R65 (pull-ups), diode isolation D7/D8/D10 | Gate drive transient scoping needed (no schematic change) |
| 13 | 🟡 Implemented | Analog OCP comparator path | None (integration happens on HAT board) | Pending HAT finalization |

### HAT Board (DSP-Regulator-HAT Rev-B)

| Issue ID | Status | Description | Components Affected | Action |
|---|---|---|---|---|
| 13 | 🟢 Policy locked | Analog OCP comparator stage (all 3 rails) | U8/U9/U10 (TLV1704), C31–C36, R67–R79, POT1–POT6, D9–D11 | Keep D9–D11 footprints but default DNP for first Rev-C build |
| —— | 🟢 Policy locked | Comparator unused-channel parking | U8C/U8D, U9C/U9D, U10C/U10D outputs | Tie unused +IN/-IN to GND; keep unused outputs off fault bus |
| —— | 🟡 Open | FAULT output pull-up strategy | R65 (10k to 3V3_ESP) | **Verify**: Confirm fault-bus pull-up value and source rail |

### Cross-Board Connector Contract

| Issue ID | Status | Description | Signals Affected | Action |
|---|---|---|---|---|
| 14 | ✅ Verified | Reference sensing contract (Kelvin pairs) | `VSENSE_*±` nets | **Locked**: Routing rule enforcement during layout only |
| 12 | 🟢 Policy locked | Bootstrap split naming consistency | `+5V_Boot` net naming across both boards | Keep single `+5V_Boot` across boards; document source ownership on regulator side |

---

## Pre-Order Issue Triage (Decision Pass)

Purpose: decide what must be resolved before Rev-C order versus what is explicitly deferred.

| Issue ID | Current State | Pre-Order Decision | Order Block? | Owner/Timing |
|---|---|---|---|---|
| RB-001 | Implemented on Rev-B, validation pending | Keep current topology; no new schematic edits unless bench shows continuity/handoff error | No | Bring-up validation after board order |
| RB-002 | On hold for current MPU path | Keep parked; do not add VBUS isolation parts in this Rev-C pass unless MPU plan changes | No | Re-open only with MPU migration |
| RB-003 | Implemented, transient validation pending | Keep netlist implementation; perform bench truth-table and transient capture later | No | Bring-up validation |
| RB-004 | Input connector polarity/silk clarity open | Add silk polarity markers and terminal labeling in PCB layout pass | No | Layout pass before fab release |
| RB-005 | ESP32 footprint/silk clarity open | Confirm deployed module footprint, then record measured footprint dimensions before Gerber release | **Yes** | Schematic + footprint measurement now |
| RB-006 | Rail fuse/TVS policy open | Defer protection add-ons to post-Rev-C data unless enclosure/safety target requires immediate add | No | Next hardware iteration decision |
| RB-007 | Stack height/mechanical fit open | Measure board stack and enclosure budget before locking split-vs-single architecture | **Yes** | Mechanical check now |
| RB-008 | Buck status LED proposal | Defer; optional feature not required for Rev-C readiness | No | Future QoL update |
| RB-009 | TS5A3157 footprint corrected | Closed | No | None |
| 10 | INA channel mapping mismatch | Treat as bring-up + firmware mapping closure; verify shunt/channel contract but do not block PCB unless routing mismatch is found | No* | Bring-up now, schematic check quick-pass |
| 11 | Adjustable rail behavior uncertain | Perform continuity/feedback check; block only if schematic net is actually open | Conditional | Quick schematic continuity check now |
| 12 | Bootstrap naming drift | Lock one naming contract across both schematics/docs | **Yes** | Decide now, then netlist re-export |
| 13 | Analog OCP path implemented on HAT | Keep global-trip policy and comparator topology; finalize output isolation population policy | **Yes** | Decide D9/D10/D11 policy now |
| 14 | VSENSE contract verified | Keep as locked routing contract | No | Layout rule enforcement |
| 15 | MPU migration deferred | Keep deferred and tracked | No | Separate migration phase |

\* If INA mismatch is traced to schematic routing or incorrect shunt value assumptions in BOM, promote to blocking immediately.

### Blocking Items To Close Before Rev-C Order

1. RB-005: Confirm ESP32 module footprint and silk callouts, then log footprint measurements.
2. RB-007: Capture stack height + enclosure fit data and finalize split vs single decision.
3. Issue 12: Lock bootstrap naming contract.
4. Issue 13: Lock D9/D10/D11 population policy.
5. Issue 11 (conditional): Confirm adjustable rail feedback continuity is not open.

### Footprint Measurement Gate (Required Before Order)

Use this gate for every newly changed footprint in Rev-C scope.

1. Open footprint in KiCad Footprint Editor and measure key geometry.
2. Compare against datasheet package drawing.
3. Record measured values in the table below.
4. Mark pass/fail and block Gerber release on any mismatch outside tolerance.

Recommended tolerance for this gate: +/-0.10 mm on pitch and body edges unless the datasheet requires tighter.

| Footprint Ref | Package | Datasheet Pitch (mm) | Measured Pitch (mm) | Datasheet Body LxW (mm) | Measured Body LxW (mm) | Pad Width x Length (mm) | Courtyard Margin (mm) | Result |
|---|---|---|---|---|---|---|---|---|
| U7 (ESP32 module) | [fill] | [fill] | [fill] | [fill] | [fill] | [fill] | [fill] | [PASS/FAIL] |
| Ux (changed part) | [fill] | [fill] | [fill] | [fill] | [fill] | [fill] | [fill] | [PASS/FAIL] |

---

## Phase 4: Single-Board vs Split-Board Decision

### Split Board (Current) — Pros / Cons

**Pros**:
- ✅ Thermal separation: regulator heat stays isolated; easier thermal design
- ✅ Component density: each board smaller, easier PCB routing
- ✅ Modularity: HAT can be swapped/upgraded independently
- ✅ Test isolation: can bench-test regulator without HAT mounted

**Cons**:
- ❌ Connector complexity: 13-pin interface adds cost + assembly risk
- ❌ Signal integrity: longer sense traces (VSENSE_5V+/- crosses via connector)
- ❌ Stack height: combined PCB height may exceed enclosure budget
- ❌ Connector contact resistance adds to feedback path noise

### Single Board (Proposed Consolidation) — Pros / Cons

**Pros**:
- ✅ No connectors: direct PCB traces, lower noise feedback
- ✅ Simpler assembly: one PCB order, one stocking SKU
- ✅ Lower cost: no connector BOM or interface labor
- ✅ Easier troubleshooting: all signals local, no interface debugging

**Cons**:
- ❌ Thermal challenge: regulator + ESP32 on same board = heat management complexity
- ❌ Size: single board larger, may exceed target footprint
- ❌ Design coupling: feedback routing must avoid switching noise from MOSFET switching
- ❌ Loss of modularity: regulator and control always together

---

## Phase 5: Decision Criteria & Recommendations

### Mechanical Stack-Height and Fit Closure Pack (RB-007)

Purpose:
- Close RB-007 with measured mechanical data that is reusable even if connector series changes.

#### A) Measurement Inputs (Capture First)

| Input ID | Description | Method | Unit | Status |
|---|---|---|---|---|
| M1 | Regulator PCB thickness | Caliper at board edge (no copper burr) | mm | 1.60 (measured 2026-05-23) |
| M2 | HAT PCB thickness | Caliper at board edge | mm | 1.60 (measured 2026-05-23) |
| M3 | Tallest regulator top-side component above PCB | Height gauge/caliper from PCB top plane | mm | 11.00 (measured 2026-05-23) |
| M4 | Tallest HAT bottom-side component below PCB | Height gauge/caliper from PCB bottom plane | mm | 2.54 (measured 2026-05-23) |
| M5 | Candidate connector mated stack height (power connector) | Datasheet nominal + tolerance | mm | [open] |
| M6 | Candidate connector mated stack height (signal connector) | Datasheet nominal + tolerance | mm | [open] |
| M7 | Assembly tolerance allowance (board warp + placement + spacer tolerance) | Process allowance | mm | 1.00 (provisional planning default; replace when process spec is known) |
| M8 | Enclosure internal Z budget at stack location | Enclosure measurement/CAD | mm | N/A (non-limiting per current enclosure) |
| M9 | Keepout near external interfaces (USB, terminal block, headers) | CAD/physical measurement | mm | N/A (no known global constraints; check only for local placement conflicts) |

Measured baseline constants from current data:
- `M3 + M4 = 13.54 mm` (fixed term before connector mated height and assembly allowance).
- With current known measurements, `H_required = 13.54 + H_mated + M7`.
- Spacing policy (2026-05-23 user direction):
   - Minimum acceptable inter-board spacing envelope: `13.54 mm`.
   - Preferred working spacing envelope: `23.54 mm` (minimum + 10.00 mm).
- Target-driven connector sizing:
   - `H_mated_target = 23.54 - 13.54 - M7 = 10.00 - M7`.
   - With provisional `M7 = 1.00`, target `H_mated` is `~9.00 mm`.
   - Practical starting band for connector search: `H_mated = 8.0 .. 10.0 mm`.

#### B) Stack-Height Calculation (Connector-Agnostic)

For each connector option pair, compute:

1. Functional mated height:
   - `H_mated = max(M5, M6)` for two-connector architecture if boards are constrained by the taller mated pair.

2. Required internal envelope:
   - `H_required = M3 + H_mated + M4 + M7`
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

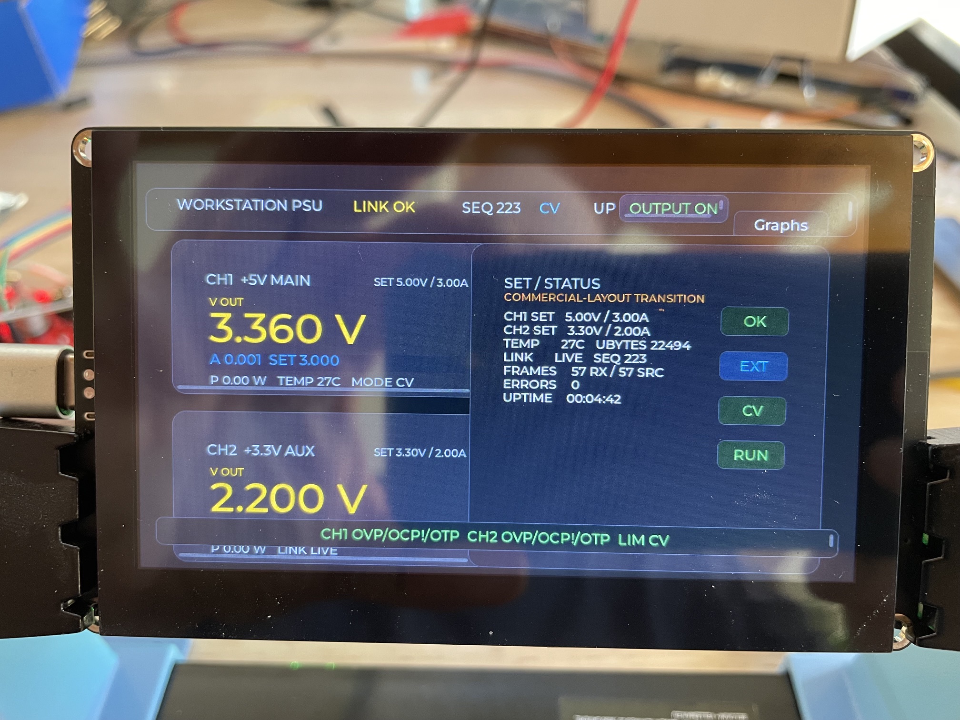
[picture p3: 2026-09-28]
docs/display-project/screenshots/audit/main.jpeg

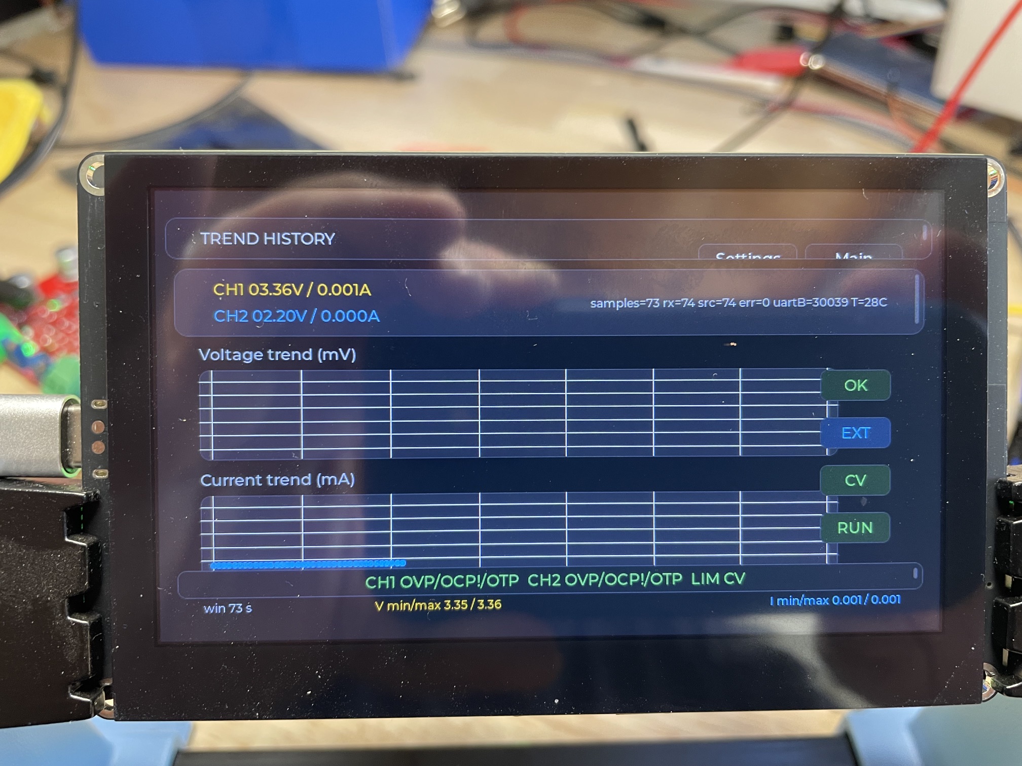
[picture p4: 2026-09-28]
docs/display-project/screenshots/audit/graph-d2.jpeg

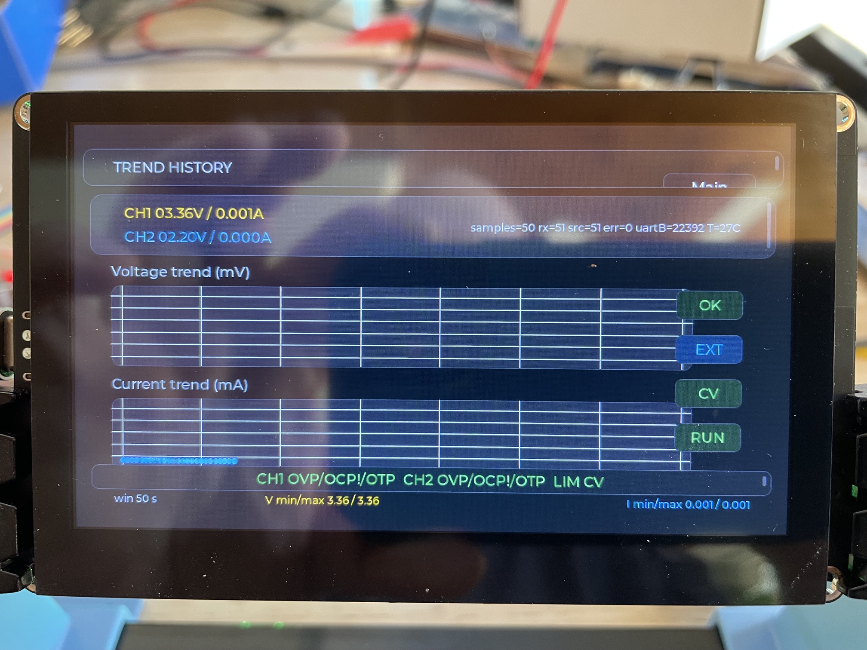
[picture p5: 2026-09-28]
docs/display-project/screenshots/audit/graph.jpeg

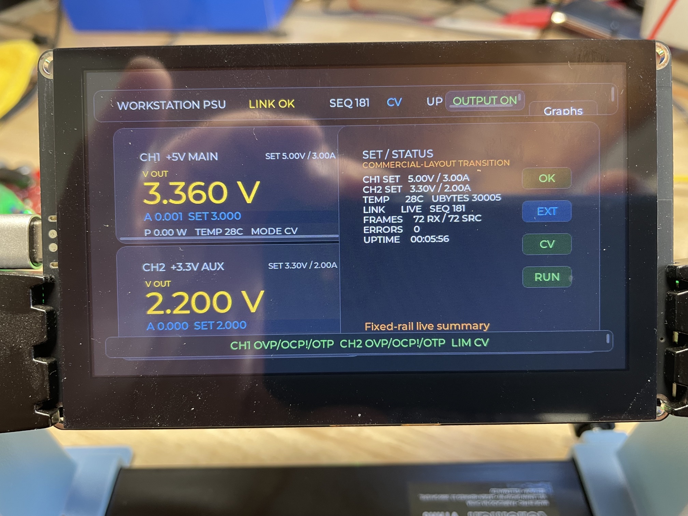
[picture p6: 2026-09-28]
docs/display-project/screenshots/audit/main-d2.jpeg

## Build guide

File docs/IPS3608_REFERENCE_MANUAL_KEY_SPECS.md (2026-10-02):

# IPS3608 Reference Manual — Key Specifications

**Source:** IPS3608 AC-DC Intelligent Digital Control Power Supply User Manual V1.0

This document extracts key specifications from the IPS3608 manual for design adaptation to a 2-fixed-channel power supply system.

**Current adaptation decisions:** See
[`display-project/crowpanel-screens-tracker.md`](display-project/crowpanel-screens-tracker.md)
for the active FNIRSI-inspired UI plan and VS Code session prompts. Reference
device features below are not claims about our hardware. Fixed voltages,
per-channel current limits, shared output enable, and touch-only operation
take precedence over older adjustable-supply examples.

---

## Hardware Specifications

| Parameter | Value |
|---|---|
| Output voltage range | DC 0–36V |
| Output current range | 0–8A |
| Output power range | 0–285W |
| Voltage accuracy | ±(0.3% + 3 bits) |
| Current accuracy | ±(0.15% + 5 bits) |
| Voltage resolution | 0.01V |
| Current resolution | 0.001A |
| Operating temperature | –10°C to +40°C, 0–75% RH |
| Display | 2.8-inch color screen |
| Product size | ≈138 × 214 × 115 mm |
| Product weight | ≈1539g |

### Protection Mechanisms
- Overvoltage protection (OVP)
- Overcurrent protection (OCP)
- Overpower protection (OPP)
- Overtemperature protection (OTP)
- Undervoltage protection (UVP)
- Output reverse injection protection
- Input reverse connection protection
- Short circuit protection

### Fast Charge Support
- **USB-C:** PD3.0, HUAWEI FCP, HUAWEI SCP
- **USB-A:** AFC, QC2.0, QC3.0

---

## UI/Display Features (IPS3608 Reference)

### Main Display Sections

**1. Voltage Display Area**
- Large yellow accent on measurement value
- Shows both measured (output) and set (target) voltage
- Format: `V set` and numerical values

**2. Current Display Area**
- Large blue accent on measurement value
- Shows both measured (output) and set (target) current
- Format: `I set` and numerical values

**3. Power Display Area**
- Gray accent, shows total power in watts
- Shows device temperature (°C) — not user-adjustable

**4. Data Statistics Area**
- Capacity (Ah): total charge delivered
- Energy (Wh): total energy delivered
- Time (HH:MM:SS): device runtime

**5. Status Indicators (Right Side Chips)**
- Volume on/off
- Cooling fan status
- Lock indicator
- OK button validity
- Data group selector (M1–M6)
- CV/CC status
- RUN/STOP state

**6. VI Curve Page**
- Real-time graph showing voltage (yellow) vs current (blue)
- MAX/MIN labels for both
- Timebase adjustment (0.1s–0.5s)

### Theme / Color Palette (Dark Theme)
- **Yellow accent:** Voltage measurements
- **Blue accent:** Current measurements
- **Gray accent:** Temperature, power, neutral elements
- **Dark background:** Primary display area
- **Green buttons:** Confirmation (OK, CV, etc.)
- **Red buttons:** Stop/error states

### Button Layout (Physical Controls)
1. **Encoder knob:** Page navigation, value adjustment
2. **Up/Down buttons:** Data group or menu selection
3. **Left/Right buttons:** Digit selection or parameter stepping
4. **V/A button:** Toggle between voltage and current input modes
5. **RUN/STOP button:** Output enable/disable
6. **Settings menu button:** Enter/exit system settings
7. **Long-press encoder:** Clear data statistics

### Data Group Storage
- 6 separate parameter sets (M1–M6)
- Each group stores:
  - Voltage setting (0–36V)
  - Current setting (0–8A)
  - OVP threshold (0V–36.10V)
  - OCP threshold (0–8.2A)
  - OPP threshold (0W–295.2W)
  - OTP threshold (0–99°C)

### Settings Menu Structure
```
Settings
├── System
│   ├── Language (Chinese, English)
│   ├── Brightness (5%–100%)
│   ├── Volume (0%–100%)
│   ├── Metering switch (ON/OFF)
│   ├── Device address (000–255)
│   └── Style switch (Light/Dark)
├── DataSet
│   ├── Group 1–6 (each with V, I, OVP, OCP, OPP, OTP)
└── About
    └── Model, version, factory reset
```

---

## Operational Flow (from manual Section 5.1)

1. Power on device → enter main interface
2. Press Settings to enter menu
3. Select DataSet group or System settings
4. Adjust parameters with buttons/encoder
5. Set voltage and current via V/A button
6. Confirm with OK button
7. Press RUN/STOP to enable output
8. Monitor V/I/P on main screen
9. Use encoder to switch to VI curve page
10. Power off: reduce V and I to minimum, then press RUN/STOP to disable output

---

## Design Adaptation for 2-Fixed-Channel System

### Channel-to-FNIRSI Mapping

| IPS3608 Element | 2-Channel Adaptation |
|---|---|
| Single voltage dial (0–36V) | Channel 1: Fixed +5V, Channel 2: Fixed +3.3V |
| Single current limit (0–8A) | CH1: User-configurable limit, CH2: User-configurable limit |
| CV/CC indicator | Per-channel automatic status, only where supported by validated hardware evidence; otherwise show limit/trip/unknown |
| Data groups (M1–M6) | Retain for storing presets per channel pair or scenario |
| RUN/STOP button | One shared master output toggle for the current hardware |
| Status chips | Adapt to show CH1/CH2 status separately |
| VI curve | Show both channels on same graph (dual traces) or selector |
| Protection flags | OVP/OCP/OTP per channel |
| Temperature | Show PCB temperature or per-channel thermal state |

### Boot Sequence (2-Channel)
1. **Splash:** Brand/product screen (3–5 seconds)
2. **Setup:** Display features & control configuration (user-defined, then confirm)
3. **Main Telemetry:** Live V/I/P for both channels, status, protection state

### Key UI Changes vs IPS3608
- **Dual channel layout:** Main screen shows CH1 top, CH2 bottom (or side-by-side)
- **No voltage adjustment:** Voltage is fixed per channel; only current limit is user-configurable
- **Simplified output control:** One shared master output control, not independent channel toggles
- **Simplified data groups:** Store current-limit presets instead of full V/I pairs
- **Graph page:** Show dual traces (one per channel) on same timebase

---

## Reference for Implementation

### Files Extracted from Manual
- Section 2.3: Main page layout and status chip definitions
- Section 2.4: VI curve page with dual-trace potential
- Section 2.5: Multi-output layout (USB-A/USB-C) — template for 2-channel display
- Section 3.2: Specification ranges and accuracy formulas
- Section 4.3: DataSet configuration structure
- Section 6: Troubleshooting and error conditions

### Next Steps for Phase 5
1. Define exact channel voltage/current limits (5V/3.3V specs from your HAT)
2. Create Setup screen flow (which parameters to configure at boot)
3. Map telemetry frame additions (if any extra channels needed beyond V/I/P)
4. Finalize status chip indicators (protection flags, thermal, link status)
5. Update `crowpanel-43-bringup/src/main.cpp` with 2-channel rendering

---

**Manual Version:** 1.0  
**Captured:** 2026-07-03  
**Adapter Context:** IPS3608 dark-theme reference for 2-fixed-channel development supply UI

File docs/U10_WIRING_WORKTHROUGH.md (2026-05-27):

# U10 Pin Wiring Workthrough — STM32 Blue Pill (1My_MPUs:stm32_BLUE)

**Date started:** 2026-05-25  
**Last updated:** 2026-05-27  
**Schematic:** `hardware/kicad/dsp-regulator-hat-rev-b/DSP-Regulator-HAT-RevB.kicad_sch`  
**Symbol:** U10 (`1My_MPUs:stm32_BLUE`) — renamed from U9A ✓  
**Old symbol to remove:** U9 (`Local:BluePill_STM32F103C8_Migrated`) — delete after SR_CLK/SR_Data migration

---

## 🚨 STOP — Fix This First

**Pin 37 (R = NRST) is connected to GND.** The MCU will be held in permanent reset and will never run.

- [ ] **Remove the GND connection from pin 37 (R)**
- [ ] **Wire pin 37 → NRST net** (its own dedicated net)

---

## Architecture Notes (Updated 2026-05-26)

**SWD pins preserved — debugging is available:**
- Pin 42 (SW0 / PA13) → `SWDIO` net → test point TP14
- Pin 43 (SWCLK / PA14) → `SWDCLK` net → test point TP13
- Programming via SWD or UART bootloader (BOOT0 jumper high) both available.

**SPI bus (single, shared on-board + off-board via J13):**
- PA4=SR_Latch, PA5=SPI SCK, PA6=SPI_MISO, PA7=SPI_MOSI, PA8=Memory_CS
- PB12=SPI_CS (J13 pin 9 via R83)

**Two I2C buses:**
- Bus 0 (on-board sensors): PB8=I²C SCL_0, PB9=I²C SDA_0 — wired ✓

**Display UART (USART3):**
- PB10=DISP_UART_TX, PB11=DISP_UART_RX — wired to J21 via R78/R79 ✓ (2026-05-27)

---

## Step 0 — Rename U9A → U10

- [x] ~~Double-click U9A in schematic → Edit Properties → set Reference to **U10**~~ ✓ Done

---

## Group A — Power & Ground (7 pins) ✓ (NRST fix pending)

| Pin | Name | Net | Status |
|---|---|---|---|
| 18 | 5V | +5V_Boot | ✓ Done |
| 19 | G | GND | ✓ Done |
| 20 | 3.3 | No connect | ✓ Done |
| 38 | 3.3 | No connect | ✓ Done |
| 39 | GND | GND | ✓ Done |
| 40 | GND | GND | ✓ Done |
| 44 | GND (bottom) | GND | ✓ Done |

---

## Group B — UART1 Debug Bus ✓

| Pin | Name | Net | Status |
|---|---|---|---|
| 6 | A9 | UART1_TX | ✓ Done |
| 7 | A10 | UART1_RX | ✓ Done |
| 8 | A11 | CTS | ✓ Done (→ R77 → J13 pin 6) |
| 9 | A12 | RTS | ✓ Done (→ R73 → J13 pin 4) |

---

## Group C — I2C Bus 0 — PB8/PB9 ✓

| Pin | Name | Net | Status |
|---|---|---|---|
| 16 | B8 | I²C SCL_0 | ✓ Done |
| 17 | B9 | I²C SDA_0 | ✓ Done |

---

## Group D — Display UART (USART3) — PB10/PB11 ✓

| Pin | Name | Net | Status |
|---|---|---|---|
| 35 | B10 | DISP_UART_TX | ✓ Done (2026-05-27) |
| 36 | B11 | DISP_UART_RX | ✓ Done (2026-05-27) |

> I2C Bus 1 removed 2026-05-27. J14/J15 deleted; R78/R79 repurposed as 33Ω series resistors to J21 (display connector). PB10/PB11 reallocated to USART3 display interface.

---

## Group E — SWD / Debug / Reset ✓

| Pin | Name | Net | Status |
|---|---|---|---|
| 37 | R | NRST | ✓ Done |
| 42 | SW0 | SWDIO | ✓ Done (test point TP14) |
| 43 | SWCLK | SWDCLK | ✓ Done (test point TP13) |
| 41 | 3V3 | No connect | ✓ Done |

---

## Group F — ISET Analog Outputs ✓

| Pin | Name | Net | Status |
|---|---|---|---|
| 25 | A0 | ISET_MPU_5V | ✓ Done |
| 26 | A1 | ISET_MPU_3V3 | ✓ Done |
| 27 | A2 | ISET_MPU_Channel_3 | ✓ Done |

---

## Group G — Fault Inputs ✓

| Pin | Name | Net | Status |
|---|---|---|---|
| 28 | A3 | FAULT_CRITICAL_SUM | ✓ Done |
| 33 | B0 | FAULT_WARNING_SUM | ✓ Done |

---

## Group H — SPI Bus ✓

| Pin | Name | Net | Status |
|---|---|---|---|
| 5 | A8 | Memory_CS | ✓ Done |
| 29 | A4 | SR_Latch | ✓ Done |
| 30 | A5 | SPI SCK | ✓ Done (also U7/U8 SHCP) |
| 31 | A6 | SPI_MISO | ✓ Done (also U11 DO) |
| 32 | A7 | SPI_MOSI | ✓ Done (also U7 DS, U11 DI) |
| 1 | B12 | SPI_CS | ✓ Done (→ R83 → J13 pin 9) |

> **U11 (W25Q128, 16MB SPI Flash) role decision (2026-05-26):** Originally intended for ESP32 OTA staging.
> **Repurposed as STM32 telemetry ring buffer** — stores raw V/I sample records for bulk transfer to PC via UART/USB (CH340C bridge, J20).
> STM32 OTA over SPI flash requires a custom IAP bootloader; deferred unless needed.

---

## Group I — Status LED ✓

| Pin | Name | Net | Status |
|---|---|---|---|
| 22 | C13 | Status_LED | ✓ Done (→ D12 DIN) |

---

## Group J — No Connect ✓

All NC pins confirmed in netlist (pintype includes `+no_connect`):
- Pin 10 (A15), 20 (3.3), 21 (VB), 34 (B1), 38 (3.3), 41 (3V3)
- Pins 2–4 (B13–B15), 11–15 (B3–B7), 23–24 (C14–C15)

> Pins 13/14/15 (B5/B6/B7) will be reassigned to Group K GPIO — remove NC markers.

## Group K — Development GPIO Connector Pins

Three development I/O pins brought out to expansion connectors. Assign to adjacent free GPIOs.
Net names follow STM32 port/pin convention (same approach as ESP32 GPIO naming).

| U10 Pin | STM32 Pin | Net Name | Connector | Status |
|---|---|---|---|---|
| 13 (B5) | PB5 | `PB5` | J12 pin 6 (was GPIO10) | ✓ Direct connection |
| 14 (B6) | PB6 | `PB6` | J12 pin 8 (was GPIO11) | ✓ Direct connection |
| 15 (B7) | PB7 | `PB7` | J13 pin 10 (was GPIO12) via R86 | ✓ Series resistor |

**KiCad steps:**
1. Remove NC markers from U10 pins 13, 14, 15
2. Add net label `PB5` on pin 13, `PB6` on pin 14, `PB7` on pin 15
3. Change label at J12 pin 6: `GPIO10` → `PB5`
4. Change label at J12 pin 8: `GPIO11` → `PB6`
5. Change label at J13 pin 10: `GPIO12` → `PB7`

---

## Step Z — Clean Up Complete ✓

- Old U9 (`Local:BluePill_STM32F103C8_Migrated`) deleted ✓
- U9 is now AMS1117-3.3 LDO (VI→+5V_Boot, VO→+3.3V Boot, GND) ✓
- SR_CLK/SR_Data migrated to SPI SCK/SPI_MOSI ✓
- 3V3_ESP renamed to `+3.3V Boot` ✓

---

## Verification Checklist

- [x] ~~Fix NRST (pin 37 off GND)~~ ✓
- [x] ~~SR_CLK/SR_Data labels updated at shift registers~~ ✓
- [x] ~~All NC markers placed~~ ✓
- [x] ~~U9 deleted / replaced with AMS1117-3.3 LDO~~ ✓
- [x] ~~CTS/RTS wired (PA11→J13 pin 6, PA12→J13 pin 4)~~ ✓
- [x] ~~3V3_ESP renamed to +3.3V Boot~~ ✓
- [x] ~~Group K GPIO assignments (J12 pin 6/8, J13 pin 10 → PB5/PB6/PB7)~~ ✓
- [x] ~~KiCad ERC~~ ✓ **0 errors / 9 warnings (all environment/stub label — no electrical issues)**
- [x] ~~J19 SWD Cortex Debug 10-pin header added to schematic~~ ✓ (2026-05-26)
- [x] ~~BOOT0 — closed loop: Blue Pill module JP3 jumper + onboard pull-down handles this; no HAT-level circuit needed~~ ✓
- [x] ~~U11 role decision documented~~ ✓ (telemetry ring buffer, see Group H note)
- [x] ~~Run `scripts/verify-connector-contract.ps1`~~ ✓ passes in `reduced` mode (18/18)
- [x] ~~Add CH340C USB-UART bridge (U12) + USB-C connector (J20) via KiCad GUI~~ ✓ (2026-05-27)
- [x] ~~Re-export netlist after CH340C addition~~ ✓
- [x] ~~Re-run ERC after CH340C addition~~ ✓ 0 errors / 0 warnings
- [x] ~~Display UART: J21 (JST XH 4-pin) added, I2C_1 removed, DISP_UART_TX/RX on PB10/PB11~~ ✓ (2026-05-27)
- [ ] Update `docs/STM32_BLUEPILL_PIN_TABLE.md` validation log

---

## Pin Count Summary

- **Connections wired:** 25 nets
- **No connects:** 19 pins
- **Total:** 44 pins ✓

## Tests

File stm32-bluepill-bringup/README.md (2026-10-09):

# STM32 Bring-up Firmware

## Targets

- `bluepill_f103c8`: Rev-C STM32F103C8 Blue Pill bring-up target.
- `f405rg`: build-only Rev-D STM32F405RG target using the frozen pin
  allocation in `docs/HAT_REVD_PIN_AND_SUPPORT_CONTRACT.md`. Rev-D hardware is
  not available; this build does not validate electrical behavior or imply
  bench readiness.

Board-specific GPIO and UART assignments are held in `src/board_pins_*.h`.
The F103 assignments follow `docs/STM32_BLUEPILL_PIN_TABLE.md`; the F405
assignments follow the Rev-D pin/support contract. The F405 environment
enables USB CDC on OTG FS PA11/PA12 with PA9 VBUS sensing, USART1 debug on
PB6/PB7, USART3 UDI on PB10/PB11, and UART4 for C3 on PC10/PC11. This build
configuration is not evidence that those interfaces are routed or bench-tested.

## Rev-C F103 Blue Pill bring-up (First Flash)

This project is the active bench-controller firmware baseline for STM32F103C8 (Blue Pill) on the current Rev-B HAT bring-up branch.

## Behavior

- Forces control outputs low at startup:
  - PA0 = ISET_MPU_5V
  - PA1 = ISET_MPU_3V3
  - PA2 = ISET_MPU_Channel_3
- Blinks PC13 status LED every 1 second.
- Emits heartbeat on USB/USART monitor (`Serial`) at 115200.
- Emits extended binary telemetry on USART3 via `HardwareSerial SerialU3(PB11, PB10)` at 115200.

## Current role in this repo

- This is the controller-of-record for current bench bring-up and worksheet command checks.
- The active command shell lives in `src/main.cpp`.
- The root-repo ESP32-C6 HAT environments are not the active control path for the current Rev-B bypass worksheet.

## Command shell

- `HELP`
- `FTEST`
- `AHTNOW`
- `AHTRESET`
- `SRTEST`
- `D9FLASH`
- `D9ON`
- `D9OFF`
- `Q1ON`
- `Q1OFF`
- `Q2ON`
- `Q2OFF`
- `Q3ON`
- `Q3OFF`
- `Q4ON`
- `Q4OFF`
- `Q5ON`
- `Q5OFF`
- `Q39ON`
- `Q39OFF`
- `Q612ON`
- `Q612OFF`
- `QSTATE`
- `QSEQ`
- `INAPROBE`
- `INANOW`
- `INARAILS`
- Display-over-UDI command channel on USART3:
  - `CMD:OUTPUT ON|OFF`
  - `CMD:ILIM CH1|CH2 <mA>`
  - Responses: `ACK:...` / `ERR:...` / `EVT:...`
- `AWPROBE`
- `AWMODE`

Range pair notes:
- `Q1ON` / `Q1OFF` drive AW9523 `P0.2` (`ESP- GPIO 5V Low`) for the Q1/Q7 gate path.
- `Q2ON` / `Q2OFF` drive AW9523 `P0.1` (`ESP- GPIO 5V Hi`) for the Q2/Q8 gate path.
- `Q3ON` / `Q3OFF` drive only AW9523 `P0.0` (`ISET_MPU_5V`) for isolated Q3-path testing.
- `Q39ON` / `Q39OFF` drive AW9523 `P0.0` (`ISET_MPU_5V`) and `P0.5` (`ISET_MPU_3V3`) together for the Q3/Q9 test path.
- `Q4ON` / `Q4OFF` drive AW9523 `P0.4` (`ESP- GPIO 3V3 Low`) for the Q4/Q10 gate path.
- `Q5ON` / `Q5OFF` drive AW9523 `P0.3` (`Channel 3 Hi-Range`) for the Q5/Q11 gate path.
- `Q612ON` / `Q612OFF` drive AW9523 `P0.1` (`ESP- GPIO 5V Hi`) for the Q6/Q12 test path.
- `QSTATE` prints AW9523 `P0` output/config register state and decoded ON/OFF state, including separate Q3 (P0.0) and Q9 (P0.5) lines.
- `QSEQ` runs the full test sequence with tagged snapshots: baseline, Q3/Q9 OFF/ON/OFF, then Q6/Q12 OFF/ON/OFF, including INA rail summaries after each step.
- If AW9523 is unavailable, range commands automatically fall back to the legacy SR emulation path.

AW9523 mode notes:
- Control commands force AW9523 into GPIO + push-pull mode before writing outputs.
- `AWMODE` explicitly reapplies and prints mode registers (`GCR`, `LEDMODE_P0`, `LEDMODE_P1`) for bench verification.

## Telemetry

- Current bring-up firmware publishes an extended UART frame once per second.
- Frame payload carries:
  - CH1 (+5V) voltage/current
  - CH2 (+3.3V) voltage/current
  - temperature
  - status byte
  - protection flags byte

## Bench connections

- Flash path: ST-Link using `upload_protocol = stlink`
- Debug shell: USART1/CH340 path at 115200 8N1
- Historical monitor port in prior captures: COM7

## Build

Build the Rev-C environment:

`platformio run -d stm32-bluepill-bringup -e bluepill_f103c8`

Build the Rev-D target:

`platformio run -d stm32-bluepill-bringup -e f405rg`

## Upload (ST-Link)

`platformio run -d stm32-bluepill-bringup -e bluepill_f103c8 -t upload`

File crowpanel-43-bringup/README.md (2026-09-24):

# CrowPanel 4.3 Bring-up (WorkStation)

This is a standalone PlatformIO starter target for the Elecrow CrowPanel Advance 4.3 inch board.

## Why this folder exists

- The official Elecrow repo is Arduino-sketch oriented.
- WorkStation uses PlatformIO for repeatable builds and handoff.
- This folder provides a clean baseline we can iterate without touching existing C6 display bring-up code.

## What this includes

- ESP32-S3 PlatformIO target (`esp32-s3-devkitc-1`)
- UART + I2C board-probe baseline (0x30 board controller and 0x5D touch probe)
- Official V1.2 CrowPanel 4.3 RGB pin mapping captured in serial boot output for verification
- Minimal serial command stub for host-display contract experiments

## Build

```powershell
C:/Users/user/.platformio/penv/Scripts/platformio.exe run -d "c:/Users/user/Esp32 projects VScode/WorkStation/crowpanel-43-bringup"
```

## Upload

```powershell
C:/Users/user/.platformio/penv/Scripts/platformio.exe run -d "c:/Users/user/Esp32 projects VScode/WorkStation/crowpanel-43-bringup" -t upload
```

## Serial monitor

```powershell
C:/Users/user/.platformio/penv/Scripts/platformio.exe device monitor -b 115200
```

## Serial commands

- `HELP`
- `PING`
- `STATUS`
- `RX`
- `UDI_STATUS`
- `UDI_OUTPUT ON|OFF` (sends `CMD:OUTPUT ...` over UDI UART)
- `UDI_ILIM CH1|CH2 <mA>` (sends `CMD:ILIM ...` over UDI UART)

## Notes

- This is a bring-up baseline, not full LVGL UI firmware yet.
- RGB panel init is intentionally deferred in this baseline to keep first compile/flash cycle reliable.
- Next step is enabling panel init after board revision confirmation and then layering LVGL.

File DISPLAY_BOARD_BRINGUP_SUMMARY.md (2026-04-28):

# Display Board Bring-Up Summary - 2026-04-20

## Implementation Status: COMPLETE ✅

All diagnostic infrastructure is in place and ready for systematic root-cause testing.

---

## Current Firmware on COM9

**Configuration**:
- **MOSI**: 11 (swapped from 13)
- **MISO**: 13 (swapped from 11)
- **DC Polarity**: Normal (DIAG_INVERT_DC=0)
- **CS Polarity**: Normal (DIAG_INVERT_CS=0)
- **Controller**: ST7796 (RGB565, 16-bit)

**Status**: Ready for testing

---

## What Works

✅ Backlight PWM brightness control (0-255)  
✅ Hardware reset pulse (GPIO19, active-low)  
✅ Software reset (SWRESET 0x01)  
✅ SPI command transmission  
✅ Backlight diagnostic loop (brightness cycling)  
✅ Firmware boots without errors  
✅ Serial communication at 115200 baud  

---

## What Doesn't Work

❌ RED framebuffer display (no visible output)  
❌ Controller appears to receive commands but not execute framebuffer writes  

---

## Root Cause Candidates

Based on diagnostic evidence:

1. **SPI MOSI/MISO Swap** (HIGH probability)
   - Symptom: Backlight works (command bus OK), framebuffer fails (data bus reversed)
   - Test: Swap pins 13↔11
   - Status: ⚠️ Currently loaded on COM9

2. **DC Line Polarity Reversed** (MEDIUM probability)
   - Symptom: Data/command confusion during initialization
   - Test: Invert DC signal polarity
   - Status: ⚠️ Prepared, not yet tested

3. **CS Line Polarity Reversed** (LOW probability)
   - Symptom: Chip-select not activating, but backlight works (suggests selective issue)
   - Test: Invert CS signal polarity
   - Status: ⚠️ Prepared, ready to build

---

## Diagnostic Testing Procedure

### Quick Start
1. Read: `DISPLAY_TESTING_CHECKLIST.md`
2. Perform: Cold power-cycle (unplug 5s, replug)
3. Observe: Display for RED framebuffer
4. Check: Serial output for boot messages
5. Report: RED appears? YES or NO

### Systematic Testing
Follow `DISPLAY_TESTING_CHECKLIST.md` for step-by-step instructions to test each hypothesis.

### Expected Outcome
When RED framebuffer appears, the root cause is identified:
- RED appears + SPI pin-swap active → **MOSI/MISO are swapped on PCB**
- RED appears + DC polarity inverted → **DC line is inverted on PCB**
- RED appears + CS polarity inverted → **CS line is inverted on PCB**

---

## File Reference

| File | Purpose |
|---|---|
| `src/display_main.cpp` | Dual-profile firmware (ILI9488 + ST7796), diagnostic wrappers |
| `platformio.ini` | Build flags for diagnostic control (DIAG_INVERT_DC, DIAG_INVERT_CS) |
| `docs/GPIO_PINOUT.md` | PCB schematic pin definitions |
| `DISPLAY_DIAGNOSTIC_REFERENCE.md` | Technical reference for each test configuration |
| `DISPLAY_TESTING_CHECKLIST.md` | Step-by-step user guide for testing |
| `DISPLAY_BOARD_BRINGUP_SUMMARY.md` | This file |

---

## Code Changes Made

### 1. Diagnostic Framework
Added compile-time flags to enable/disable polarity inversions:
```cpp
#ifndef DIAG_INVERT_DC
#define DIAG_INVERT_DC 0
#endif

#ifndef DIAG_INVERT_CS
#define DIAG_INVERT_CS 0
#endif
```

### 2. Polarity Wrapper Functions
```cpp
static inline void diagSetDC(bool dataMode) {
#if DIAG_INVERT_DC
    digitalWrite(TFT_DC_PIN, dataMode ? LOW : HIGH);
#else
    digitalWrite(TFT_DC_PIN, dataMode ? HIGH : LOW);
#endif
}

static inline void diagSetCS(bool active) {
#if DIAG_INVERT_CS
    digitalWrite(TFT_CS_PIN, active ? HIGH : LOW);
#else
    digitalWrite(TFT_CS_PIN, active ? LOW : HIGH);
#endif
}
```

### 3. SPI Write Functions Updated
All legacy SPI write functions now use diagnostic wrappers:
- `legacyWriteCommand()` → uses `diagSetCS()` and `diagSetDC()`
- `legacyWriteData8()` → uses `diagSetCS()` and `diagSetDC()`
- `legacyWriteDataN()` → uses `diagSetCS()` and `diagSetDC()`

### 4. Serial Diagnostic Output
Boot messages show which diagnostic is active:
```
[DIAGNOSTIC] DC polarity INVERTED
[DIAGNOSTIC] CS polarity INVERTED
```

### 5. platformio.ini
Added diagnostic flags to build_flags:
```ini
-DDIAG_INVERT_DC=0
-DDIAG_INVERT_CS=0
```

---

## Build Instructions

### Clean Build
```powershell
Set-Location "c:/Users/user/Esp32 projects VScode/WorkStation"
C:/Users/user/.platformio/penv/Scripts/platformio.exe run -e display_board -t upload
```

### With Diagnostics
1. Edit `platformio.ini` or `src/display_main.cpp` as needed
2. Run build command
3. Wait for upload to complete
4. Perform cold power-cycle

---

## Hardware Specifications

**Controller**: ST7796 (Hosyond MSP4022 module)
- Display: 320x480 pixels
- Color: RGB565 (16-bit)
- Interface: SPI 4-wire + control lines
- Init sequence: Full table, SWRESET first

**ESP32-C6 (QFN40 v0.2)**
- Core: RISC-V 160MHz, single-core with LP core
- RAM: 320KB SRAM
- Flash: 4MB
- SPI pins: 12=SCLK, 13=MOSI, 11=MISO (PCB schematic)
- Control: 10=CS, 18=DC, 19=RST (active-low)

---

## Test Matrix Summary

```
Test Config          | Board MOSI/MISO | DC Polarity | CS Polarity | Expected Outcome
                     |                 |             |             |
Original             | 13/11           | Normal      | Normal      | No display (baseline)
MOSI/MISO Swap       | 11/13           | Normal      | Normal      | RED if swapped on PCB
DC Invert            | 13/11           | Inverted    | Normal      | RED if inverted on PCB
CS Invert            | 13/11           | Normal      | Inverted    | RED if inverted on PCB
```

---

## Success Criteria

Display board bring-up is successful when:

1. ✅ RED framebuffer appears on display
2. ✅ Root cause identified (which polarity/pin swap needed)
3. ✅ All brightness levels show RED consistently
4. ✅ No hardware damage or smoke
5. ✅ Serial messages show successful init sequence

---

## Next Steps After Root Cause Identified

Once RED appears and root cause is known:

1. **Update PCB Schematic** with correct pin/polarity definitions
2. **Create Production Firmware** with inverted/swapped configuration as needed
3. **Remove Diagnostic Flags** (set DIAG_INVERT_DC=0, DIAG_INVERT_CS=0)
4. **Full Integration Testing** with other board systems (power supply, control board, etc.)
5. **Prototype Validation** with full hardware stack

---

## Known Issues

⚠️ GFX Library compilation occasionally fails with Error 3 on clean builds  
**Workaround**: Re-run build command or clean build cache

---

## Contact / Questions

- Firmware: `src/display_main.cpp`
- Config: `platformio.ini`
- Testing Guide: `DISPLAY_TESTING_CHECKLIST.md`
- Reference: `DISPLAY_DIAGNOSTIC_REFERENCE.md`

---

**Date**: 2026-04-20  
**Target**: ESP32-C6 Front Display Board (COM9)  
**Module**: Hosyond MSP4022  
**Status**: Diagnostic infrastructure complete, ready for user testing

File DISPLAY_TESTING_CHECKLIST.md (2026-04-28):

# Display Board Diagnostic Testing Checklist

## Current Firmware Status
- **Uploaded to COM9**: SPI Diagnostic Probe (baseline - all diagnostics disabled)
- **MOSI Pin**: 13 (original)
- **MISO Pin**: 11 (original)
- **DC Polarity**: Normal (not inverted)
- **CS Polarity**: Normal (not inverted)

## Pre-Test Checklist
- [ ] Display board connected and powered
- [ ] COM9 connection verified
- [ ] Serial monitor ready (115200 baud)
- [ ] Read diagnostic reference: `DISPLAY_DIAGNOSTIC_REFERENCE.md`

## Test Plan

### Test 1: Baseline (Original Configuration)
**Status**: Firmware already uploaded to COM9

1. [ ] Unplug display board from power
2. [ ] Wait 5+ seconds
3. [ ] Plug back in
4. [ ] Wait 2 seconds for boot
5. [ ] **Observe**: Does RED framebuffer appear?
   - [ ] YES → Baseline works (unexpected - proceed with other tests for confirmation)
   - [ ] NO → Proceed to Test 2
6. [ ] **Serial Output**: Should show boot sequence and brightness diagnostic loop

**Result**: RED appears? __ YES __ NO

---

### Test 2: DC Polarity Invert
**Action Required**: Modify `platformio.ini`

1. [ ] Edit `platformio.ini` line 19: change `-DDIAG_INVERT_DC=0` to `-DDIAG_INVERT_DC=1`
2. [ ] Save file
3. [ ] In terminal: `platformio run -e display_board -t upload`
4. [ ] Wait for success message
5. [ ] Unplug display board
6. [ ] Wait 5+ seconds
7. [ ] Plug back in
8. [ ] Wait 2 seconds for boot
9. [ ] **Observe**: Does RED framebuffer appear?
   - [ ] YES → **DC POLARITY IS INVERTED on PCB** ← ROOT CAUSE FOUND
   - [ ] NO → Proceed to Test 3
10. [ ] **Serial Output**: Should show `[DIAGNOSTIC] DC polarity INVERTED`

**Result**: RED appears? __ YES __ NO

---

### Test 3: SPI Pin Swap (MOSI ↔ MISO)
**Action Required**: Modify `src/display_main.cpp`

1. [ ] Edit `src/display_main.cpp` lines 49-50:
   - Change `constexpr uint8_t TFT_MOSI_PIN   = 13;` to `constexpr uint8_t TFT_MOSI_PIN   = 11;`
   - Change `constexpr uint8_t TFT_MISO_PIN   = 11;` to `constexpr uint8_t TFT_MISO_PIN   = 13;`
2. [ ] Save file
3. [ ] Ensure `platformio.ini` has: `-DDIAG_INVERT_DC=0` (revert Test 2 change if needed)
4. [ ] In terminal: `platformio run -e display_board -t upload`
5. [ ] Wait for success message
6. [ ] Unplug display board
7. [ ] Wait 5+ seconds
8. [ ] Plug back in
9. [ ] Wait 2 seconds for boot
10. [ ] **Observe**: Does RED framebuffer appear?
    - [ ] YES → **MOSI/MISO PINS ARE SWAPPED on PCB** ← ROOT CAUSE FOUND
    - [ ] NO → Proceed to Test 4
11. [ ] **Serial Output**: Should show boot sequence (no diagnostic message)

**Result**: RED appears? __ YES __ NO

---

### Test 4: CS Polarity Invert
**Action Required**: Modify `platformio.ini` and revert `src/display_main.cpp`

1. [ ] Revert `src/display_main.cpp` lines 49-50 to original:
   - Change back to: `constexpr uint8_t TFT_MOSI_PIN   = 13;`
   - Change back to: `constexpr uint8_t TFT_MISO_PIN   = 11;`
2. [ ] Save file
3. [ ] Edit `platformio.ini` line 20: change `-DDIAG_INVERT_CS=0` to `-DDIAG_INVERT_CS=1`
4. [ ] Save file
5. [ ] In terminal: `platformio run -e display_board -t upload`
6. [ ] Wait for success message
7. [ ] Unplug display board
8. [ ] Wait 5+ seconds
9. [ ] Plug back in
10. [ ] Wait 2 seconds for boot
11. [ ] **Observe**: Does RED framebuffer appear?
    - [ ] YES → **CS POLARITY IS INVERTED on PCB** ← ROOT CAUSE FOUND
    - [ ] NO → Hardware issue or incompatibility (see Troubleshooting)
12. [ ] **Serial Output**: Should show `[DIAGNOSTIC] CS polarity INVERTED`

**Result**: RED appears? __ YES __ NO

---

## Summary of Findings

| Test | RED Appears? | Root Cause |
|---|---|---|
| Baseline | [ ] YES / [ ] NO | — |
| DC Polarity | [ ] YES / [ ] NO | DC line inverted on PCB |
| Pin Swap | [ ] YES / [ ] NO | MOSI/MISO swapped on PCB |
| CS Polarity | [ ] YES / [ ] NO | CS line inverted on PCB |

**Root Cause Identified**: ____________________________________________________

---

## If RED Appears in Multiple Tests

This is unlikely but possible if multiple issues exist. Note which tests show RED:
- Tests: _________________________________________________

**Recommendation**: Combine fixes (e.g., invert DC AND swap MOSI/MISO)

---

## If RED Never Appears

**Possible causes**:
1. Hardware defect on display module
2. Controller not recognized (wrong init sequence for this display)
3. SPI timing issue (speed too fast/slow)
4. Power supply insufficient for display
5. PCB has additional undocumented pin swaps

**Next steps**:
- Check backlight brightness cycles (proves SPI bus working)
- Verify reset pulse occurs (GPIO19)
- Test with hardware SPI diagnostic (DC/CS toggling with logic analyzer)
- Consult display module datasheet: Hosyond MSP4022

---

## Testing Notes

- Each test requires **cold power-cycle** (5+ seconds unplugged)
- Warm restart is insufficient; ROM needs time to de-energize
- Serial output shows init table, backlight ramp, then diagnostic loop
- Brightness cycles through {0, 50, 100, 150, 200, 255} every 3 seconds
- If RED appears at any brightness level, display IS responding

---

## Rollback to Baseline

After testing, to return to baseline (all diagnostics disabled):

```powershell
# Revert platformio.ini flags to 0:
platformio run -e display_board -t upload

# Revert src/display_main.cpp pins to original:
# MOSI=13, MISO=11
```

---

**Created**: 2026-04-20
**Target**: ESP32-C6 Front Display Board (COM9)
**Module**: Hosyond MSP4022 / ST7796 controller

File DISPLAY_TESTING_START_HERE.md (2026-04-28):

# NEXT STEPS - Display Board Testing

**Status**: Diagnostic firmware is ready on COM9. Your turn to test and report results.

---

## What You Need to Do

1. **Read**: `DISPLAY_TESTING_CHECKLIST.md` (this will take 5 minutes)
2. **Perform**: Cold power-cycle test (unplug 5+ seconds, replug)
3. **Observe**: Does RED framebuffer appear on the display?
4. **Report**: YES or NO

---

## Quick Reference

| File | Purpose |
|---|---|
| **DISPLAY_TESTING_CHECKLIST.md** | Step-by-step testing instructions (START HERE) |
| **DISPLAY_DIAGNOSTIC_REFERENCE.md** | Technical details on each test configuration |
| **DISPLAY_BOARD_BRINGUP_SUMMARY.md** | Complete implementation overview |

---

## Current Firmware

**Loaded on COM9**: SPI Pin-Swap test version
- **MOSI**: 11 (swapped from 13)
- **MISO**: 13 (swapped from 11)
- **Status**: Ready for first cold-cycle test

---

## What to Expect

**Boot Sequence** (watch serial output at 115200 baud):
```
[display] boot - Arduino_GFX ST7796 probe
[pins] using PCB schematic mapping (CS=10, DC=18, RST=19)
[tft] hardware reset done
[minimal] deterministic dual-profile probe mode
[minimal] profile = ST7796 (full table)
[minimal] ramping backlight 0->255 over 5 seconds...
[minimal] backlight at full brightness
[minimal] fill RED using RGB565 over 320x480
[done] probe complete; screen should be solid RED
[diag] entering brightness diagnostic loop
[diag] brightness = 0 (hold 3s)
[diag] brightness = 50 (hold 3s)
...
```

**Expected Visual**:
- Backlight comes on and ramps from dark to bright (0-255) over 5 seconds
- Screen should show solid RED color
- Brightness cycles through levels {0, 50, 100, 150, 200, 255} every 3 seconds

---

## Test Outcome Matrix

| Test | RED Appears? | What It Means |
|---|---|---|
| SPI Pin-Swap (current) | YES | ✅ **MOSI/MISO are swapped on PCB** → Fix confirmed |
| SPI Pin-Swap (current) | NO | Continue testing (follow checklist) |

---

## If RED Appears in Current Test

**Congratulations!** Root cause identified: MOSI and MISO pins are swapped on the PCB.

**Next Actions**:
1. Confirm result by testing again (repeat cold-cycle)
2. Note which brightness levels show RED (should be all of them)
3. Notify lead engineer with result
4. Update PCB schematic with correct pin mappings
5. Prepare production firmware with pins swapped (11↔13)

---

## If RED Does NOT Appear

**Follow the checklist** to test the next hypothesis (DC polarity invert).

The checklist will guide you through:
1. Modifying the firmware config
2. Rebuilding and uploading
3. Performing cold-cycle test
4. Observing results

---

## Important Notes

- ⚠️ **ALWAYS perform a cold power-cycle** (unplug 5+ seconds, not just restart)
- 🔍 Watch for backlight brightness ramp (proves SPI bus is working)
- 📊 Monitor serial output at 115200 baud for boot messages
- 🔄 Each test takes ~2 minutes (build + upload + cold-cycle)
- 💾 All test configurations are prepared; no coding needed, just config changes

---

## Questions?

Refer to:
- **Testing steps**: `DISPLAY_TESTING_CHECKLIST.md`
- **Technical details**: `DISPLAY_DIAGNOSTIC_REFERENCE.md`
- **Overview**: `DISPLAY_BOARD_BRINGUP_SUMMARY.md`
- **GPIO reference**: `docs/GPIO_PINOUT.md`

---

**Ready?** Open `DISPLAY_TESTING_CHECKLIST.md` and start testing!

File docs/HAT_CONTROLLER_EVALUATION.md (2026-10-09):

# HAT Controller Decision and Rev-D Migration (#102)

**Status:** Controller architecture and MCU selected for future HAT Rev-D:
STM32F405RG bare MCU plus ESP32-C3-MINI Wi-Fi coprocessor. Schematic/layout
migration and verification remain to be done; Rev-C files are not changed by
this decision. The reviewed F405 support project is preserved; use the
separate editable integration starter in
`hardware/kicad/dsp-regulator-hat-rev-d-full/` for full-HAT work. It currently
contains F405 support and an initial committed-source HAT reuse pass, not
the complete HAT, bare C3 module or PCB.

This decision applies to the future HAT revision, referred to here as
Rev-D. Continue Rev-C bring-up and firmware work separately.

## Confirmed future requirements

| Function | Current direction | Boundary |
|---|---|---|
| PC display link | USB device with CDC serial telemetry; a separate PC application renders a larger dashboard | Data/telemetry path, not USB host functionality. The existing CH340C/USART debug path is distinct from the future native USB interface. |
| Wi-Fi | Local-network telemetry and OTA updates | No remote power control has been requested. OTA security, recovery, and update interruption behavior must be evaluated before selection. |
| Power control | Preserve a deterministic, safe control path | USB, Wi-Fi, and update activity must not compromise safe output states, hardware protection, or fault reporting. |

These are future-revision requirements, not authorization to enable Wi-Fi,
OTA, or a new USB path on Rev-C. The exact PC telemetry schema, update
security/recovery policy, and network provisioning behavior remain open.

## Selected Rev-D architecture

The selected architecture is:

- **STM32F405RG** as the on-board, bare LQFP64 control MCU. It replaces the
  STM32F103C8T6 Blue Pill development board used by the current firmware
  bring-up setup and remains the deterministic real-time/control and safety
  authority.
- **ESP32-C3-MINI** as a separate, low-cost Wi-Fi coprocessor for local
  network telemetry and OTA.
- **USB CDC device telemetry** from the HAT to a PC, where a separate
  application can render the larger dashboard.
- Keep Wi-Fi/network activity from directly owning time-critical rail control
  or bypassing STM32 safety/fault handling.

The STM32F405RG selection is final for this architecture decision. The cited
F405 pin allocation and minimum-support targets are frozen in the
[Rev-D pin and support contract](HAT_REVD_PIN_AND_SUPPORT_CONTRACT.md);
schematic capture, electrical review, USB routing, and C3 module integration
remain open before a Rev-D schematic or PCB is ready. Session 3 confirmed
PC0=`C3_EN_N` and PC1=`C3_BOOT_N` for the bare ESP32-C3-MINI-1U external-antenna
module path; exact ordering code and electrical implementation remain to be
verified.
The exact C3 module variant and its use of the current Rev-C U2 footprint and
routing also require verification; the existing `ESP32_C3_mini` symbol at U2
does not prove that it is fully wired or firmware-ready. The Rev-C netlist
identifies that footprint as Seeed SKU `113991054` (XIAO ESP32C3), not a bare
ESP32-C3-MINI module. Its 5 V input is connected, its 3.3 V output is
explicitly no-connected, two GPIOs link to the STM32, two more have isolated
RTS/CTS-named net stubs, and nine GPIOs are explicit no-connects. EN and USB
programming signals are not exposed by the schematic symbol. Rev-D therefore
uses a bare ESP32-C3-MINI-1U module with external antenna, with explicit
power, EN/boot control, UART, and recovery access. Confirm the exact orderable
module variant and antenna/connector before layout; see the C3 audit in the
[Rev-D pin and minimum-support contract](HAT_REVD_PIN_AND_SUPPORT_CONTRACT.md).

The STM32F405RG is an LQFP64 device, not a Blue Pill module. Rev-D must
provide the MCU's required board-level power, clock/reset/boot, programming,
and debug support. The existing Blue Pill is the current Rev-C bring-up
controller and is not the Rev-D implementation.

## Rev-C work continues in parallel

Continue Rev-C firmware development, integration, and bench work wherever
possible while Rev-D migration proceeds. Issue #102 is not a
hold on the current revision and does not replace its remaining firmware and
validation work. Keep changes compatible with Rev-C hardware; when a feature
cannot reasonably fit or operate on the current controller, record that
constraint and defer only that feature or implementation to the future
revision rather than stopping unrelated Rev-C progress.

## Existing controller baseline

| Item | Current evidence |
|---|---|
| Controller | STM32F103C8T6 Blue Pill, 72 MHz; guaranteed 64 KiB program flash and 20 KiB SRAM |
| Firmware links | USART1 to CH340 debug, USART3 to UDI display, I2C on PB8/PB9, SPI external flash, AW9523 interrupt on PB7; see `docs/STM32_BLUEPILL_PIN_TABLE.md` |
| External memory | W25Q128 is SPI data flash for tests/configuration; it is not executable MCU flash or working SRAM |
| Flash constraint | The Rev-C firmware build exceeds the F103C8's 65,536-byte program-flash capacity, and more features remain to be developed. This is sufficient to rule out the F103C8 for the complete planned firmware; the small variation between reported build sizes does not change that decision. |

The remaining Rev-C firmware and validation work is tracked in
`docs/FIRMWARE_DEVELOPMENT_PLAN.md`. Size the F405 firmware for that remaining
work and additional planned features, with an explicit growth reserve; do not
infer the full requirement from the present build alone.

## Migration and implementation checklist

The [Rev-D pin and minimum-support contract](HAT_REVD_PIN_AND_SUPPORT_CONTRACT.md)
provides the frozen, cited F405 allocation and schematic review gates.
Confirmed interface decisions: supply-powered USB device (data/VBUS sensing
only) and a dedicated UART between the STM32 and C3. Session 3 confirmed the
bare ESP32-C3-MINI-1U external-antenna path and PC0/PC1 as the C3 EN/BOOT
controls. The support schematic has passed initial ERC/netlist review, and a
separate editable full-HAT project now adds an initial HAT reuse pass.
The current partial integration has 0 ERC errors and 80 unresolved warnings;
the earlier support-only 0/0 result is not a current full-HAT claim.
Full-HAT integration and electrical review remain open. Under the user's 2026-10-09 direction,
prior HAT circuits are working reuse candidates, replaceable as needed;
full Rev-C bench requalification and the untested fan's later bench check
do not block integration. Production-source/physical-board correlation and
Rev-D validation remain open; see the contract for the manufacturing-reference
boundary and remaining gates.

The F405RG provides up to 1 MiB of flash, 192 KiB SRAM, and USB OTG FS
according to ST documentation. Confirm the exact datasheet limits and memory
regions during firmware migration. The ESP32-C3 remains a separate radio
coprocessor; do not merge its networking responsibilities into the STM32
control loop.

- [ST STM32F405RG product page](https://www.st.com/en/microcontrollers-microprocessors/stm32f405rg.html)
- [ST STM32F405RG datasheet](https://www.st.com/resource/en/datasheet/stm32f405rg.pdf)
- [Espressif ESP32-C3-MINI-1 datasheet](https://documentation.espressif.com/esp32-c3-mini-1_datasheet_en.html)

1. **Board-level STM32 integration:** replace the Blue Pill module representation
   with the exact STM32F405RG LQFP64 symbol and footprint; allocate VDD/VSS,
   VDDA/VSSA, VCAP, decoupling, reset, boot-strapping, clock source, and SWD
   programming/debug access from the current ST documentation and design
   requirements.
2. **Pin/peripheral migration:** map every current F103 signal contract to
   legal F405RG LQFP64 pins and alternate functions. Preserve USART for CH340
   debug and UDI, I2C, SPI W25Q128, shift-register controls, AW9523 interrupt,
   and needed timers/PWM/ADC. Check all simultaneous peripheral use and avoid
   assuming pin-name equivalence between MCUs.
3. **USB CDC hardware:** reserve and route the F405 USB OTG FS device D+/D-
   signals with the required connector, protection, VBUS sensing/power
   policy, and routing constraints. Confirm USB CDC does not conflict with
   existing debug/programming paths.
4. **C3 coprocessor interface:** verify the ESP32-C3-MINI variant, U2
   footprint/power/RF layout, and available GPIOs. Define a robust STM32-C3
   transport, framing, reset/boot control, and behavior when Wi-Fi is absent
   or the coprocessor resets.
5. **Firmware migration:** add a dedicated STM32F405RG build target and move
   the controller firmware off the F103C8 memory map. Revalidate startup,
   safe output defaults, fault latency, watchdog behavior, calibration and
   persistence, UDI, USB CDC telemetry, and build-size/RAM headroom.
6. **Network/update boundary:** define provisioning and local telemetry,
   OTA authentication/signing, rollback/recovery, and power-loss behavior.
   OTA may update the C3 firmware; any STM32 update path must be designed and
   independently validated. Remote power control remains out of scope.
7. **Hardware verification:** run schematic ERC, pin/net contract checks,
   footprint review, PCB DRC, and programming/boot/USB/Wi-Fi coexistence
   tests. Keep fabrication release gated on the applicable Rev-D electrical
   and safety review.

The W25Q128 remains external SPI data flash. It may support data storage or
update staging only if a future boot/update design explicitly implements and
validates that role; it does not replace the F405's executable flash or RAM.

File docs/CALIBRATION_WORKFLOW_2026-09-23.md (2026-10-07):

# Development Station Calibration Workflow (Recovered + Updated)

Date: 2026-09-23
Status: Active working procedure for next calibration session

## Purpose

Recover and update the existing calibration approach already present in firmware and handoff notes, without changing the current CrowPanel UART0 shared transport setup.

## Key Decision

Keep CrowPanel on the current UART0 shared mode for now.

- CrowPanel is confirmed booting and running on COM12.
- In UART0 shared mode, CrowPanel console command interaction is intentionally limited by firmware design.
- Calibration command/control should therefore run from the Blue Pill helper console and/or the main controller console where calibration commands already exist.

## What already exists in repo

### 1) Blue Pill helper path (bring-up and rail-state verification)

File: stm32-bluepill-bringup/src/main.cpp

Useful commands:
- HELP
- AWPROBE
- AWMODE
- Q1ON/Q1OFF, Q2ON/Q2OFF, Q3ON/Q3OFF, Q4ON/Q4OFF, Q5ON/Q5OFF, Q9ON/Q9OFF
- QSTATE
- INAPROBE
- INANOW
- INARAILS
- INADIAG

Use this path to:
- Hold known-safe gate states (all OFF baseline unless a step needs ON)
- Verify AW9523 control is alive
- Capture directional INA behavior while stepping ranges/loads

### 2) Legacy ESP32 calibration reference (not the active STM32 controller)

File: src/main.cpp
File: src/power_telemetry_map.h

These commands belong to the legacy ESP32 firmware, not
`stm32-bluepill-bringup/src/main.cpp`. Do not use this command set to infer or
change the active STM32 controller's calibration or physical shunt mapping.

Legacy command set:
- RCALSHOW
- RCAL <rail> <range> <vgain> <voff> <igain> <ioff>
- SHUNTSHOW
- SHUNT <rail> <range> <ohms>
- AUTORANGE <ON|OFF>
- RTHR <low_mA> <high_mA>
- CFGSHOW
- CFGSAVE
- CFGLOAD
- CFGRESET
- CALRAMP / CALRAMP0 / CALRAMP1
- RAILSNAP

Supported rail/range tokens from command handling:
- rails: 5V, 3V3, ADJ, IN12
- ranges: HIGH, LOW, SINGLE

Calibration is applied as:
- V_cal = V_raw * vgain + voff
- I_cal = I_raw * igain + ioff

## Current-measurement qualification gate (before calibration)

**Status:** Bounded CH1/CH2 HIGH correlation captures and a direct CH1 current
capture recorded below. No calibration values changed; no protection testing
performed.
Operator confirms a 10Ω / 5W resistor load and an OWON XDM1041 DMM. The
disconnected, cold load measured 10.68Ω (operator report). The published
XDM1041 specification is ±(0.05% of reading + 5 counts) on the 5V/50V DC
voltage ranges and ±(0.15% + 10 counts) on the 500Ω resistance range. DMM
calibration status and resistor tolerance remain unknown, so these are
instrument specifications, not a traceable uncertainty statement.
Specification source: https://in.owon.com/products_owon_4_1%7C2_digits_xdm1000_series_bench-type_digital_multimeter
Operator-approved provisional capture bounds: test one channel at a time with
the 10Ω / 5W load, 800mA maximum input-supply limit, and no more than 10 seconds
at load; stop if CH1 leaves 4.75–5.25V or CH2 leaves 3.135–3.465V. Apply only
after unpowered range-to-INA mapping is identified. These bounds do not
authorize protection testing, overloads, or persistent calibration changes.

### Static path findings

- PR #63's current Rev-C regulator export is
  `hardware/kicad/dsp-regulator-rev-c/DSP-Regulator-RevC.net` (export timestamp
  `2026-10-07T05:31:09`). The operator confirms these values are installed:
  R7/R37 = 20mΩ, R19/R45 = 200mΩ, and R64 = 10mΩ. The export confirms the
  first four values and routes the sense nets to INA3221s as follows:

  | Rail/range | INA in Rev-C netlist | INA channel | Range sense nets | Shunt |
  |---|---|---:|---|---|
  | CH1 +5V HIGH | U10 | 1 | `+5V_Hi_Range` / `-5V_Hi_Range` | R7, 20mΩ |
  | CH1 +5V LOW | U10 | 2 | `+5V_low_Range` / `-5V_low_Range` | R19, 200mΩ |
  | CH2 +3.3V HIGH | U11 | 1 | `+3v3V_Hi_Range` / `-3v3V_Hi_Range` | R37, 20mΩ |
  | CH2 +3.3V LOW | U11 | 2 | `+3v3V_low_Range` / `-3v3V_low_Range` | R45, 200mΩ |
  | Incoming monitor | U11 | 3 | `Incoming (+)` / `Incoming (-)` | R64, 10mΩ (operator-confirmed) |

  Firmware addresses U10/U11 as `0x40`/`0x41` and `INARAILS` labels channel 1
  HIGH and channel 2 LOW. This confirms the intended design mapping. Installed
  board revision/population is operator-reported, not independently inspected.
  The export labels R64 `10mohm`, but its component description / linked part
  metadata says 0Ω; the physical 10mΩ value is operator-confirmed, so this is
  a netlist/BOM metadata discrepancy, not a reason to substitute another value.
- The STM32 controller reads INA3221s at `0x40` and `0x41`. Its conversion is
  signed INA shunt-register value × 0.04mV, then shunt mV divided by
  `inaShuntOhmsFor()`. That helper returns 0.200Ω for every output channel and
  0.018Ω for the `0x41` channel-3 incoming monitor. Against the mapped shunts,
  the output formula is nominally correct for LOW (200mΩ) but 10× too small
  for HIGH (20mΩ); the incoming-monitor value also differs from the confirmed
  10mΩ R64. Do not use calibration to mask this range-dependent conversion
  mismatch.
- The published CH1 and CH2 telemetry both use INA channel 1 (index 0), then
  apply one rail-level current coefficient: `I_cal = I_raw * current_gain +
  current_offset_mA`. Defaults are gain 1 and offset 0, but boot can restore
  other persistent flash values. The active STM32 has `CFGSHOW`/`CALSHOW` for
  readback; `CALSET` writes the persistent config immediately. There are no
  per-range calibration coefficients in this path. `INARAILS` can show both
  INA channels, but the published frame always uses channel 1 (HIGH), even
  when the LOW hardware path is active; the CrowPanel therefore cannot provide
  a LOW-range current reading with the current firmware.
- The CrowPanel parses the transmitted integer-mA fields and displays them to
  0.001A precision. It receives the controller's calibrated/rounded frame
  values, not raw INA data, and does not show the calibration coefficients.
  If an INA read fails, the controller currently publishes fallback values
  (500mA for CH1, 320mA for CH2); do not treat those as measurements.
- The operator clarified that #63's loaded readings were incidental, not a
  controlled current-accuracy test. A later reported 10.68Ω cold resistance
  can be used only for an illustrative calculation if it was the same load:
  CH1 `5.005V / 10.68Ω = 468.6mA` and CH2
  `3.3141V / 10.68Ω = 310.3mA`. The CrowPanel values (66mA and 45mA) are
  approximately 7.10× and 6.90× lower than those illustrative estimates.
  Load identity, measurement timing, DMM accuracy/calibration status, and
  resistor temperature/tolerance are not established; this is a discrepancy
  clue only, not evidence that verifies current accuracy or a precise scaling
  error. It is directionally consistent with the now-traced HIGH-range
  formula mismatch but does not independently verify that explanation. CH2's
  recorded 1.1W conflicts with its displayed
  `3.32V × 0.045A ≈ 0.149W`; preserve the discrepancy as unresolved rather
  than selecting one value.
- **Bounded CH1 HIGH correlation capture (operator log, 2026-10-07):** With
  the 10.68Ω cold resistor on CH1, measured voltage across the load was
  4.9203V, giving an illustrative `I = V/R = 460.7mA` and `P = V²/R = 2.267W`.
  CrowPanel reported CH1 `5.02V, 0.066A, 0.33W`; CH2 was zero/off. The serial
  log records `Q2ON`, `QSTATE p0=0x02 ... Q2=1`, and `INARAILS`:
  `rail 5V: hi 5.024V 65.60mA | lo 5.024V 20.60mA`; the 3V3 output channels
  were zero, incoming monitor about 11.088V / 320mA. Controller HIGH current
  and display current agree closely (65.60 vs 66mA), while the load-based
  estimate is about 7.02× higher. The load voltage (4.9203V) is also about
  0.104V below the reported INA/panel voltage (~5.02V). The capture is bounded
  correlation evidence, not a traceable current measurement: DMM calibration,
  resistor tolerance/temperature, and the exact `CFGSHOW` coefficient values
  were not established (`cfg d9=ON 5V[   ] 3V3[   ]` was the recorded output).
  The known 20mΩ HIGH shunt plus the firmware's 200mΩ conversion predicts a
  nominal 10× under-reading, not the observed 7.02×; therefore the conversion
  mismatch is real in source, but does not alone explain the captured value.
  Output was returned OFF after the capture.
- **Bounded CH2 HIGH correlation capture (operator log, 2026-10-07):** With
  the same 10.68Ω cold resistor, voltage across the load was 3.2756V, giving
  illustrative `I = V/R = 306.7mA` and `P = V²/R = 1.005W`. CrowPanel reported
  CH2 `3.32V, 0.046A, 0.15W`; CH1 was zero/off. The serial log records
  `QSTATE p0=0x08 ... Q5=1` and `INARAILS`:
  `rail 3V3: hi 3.320V 45.60mA | lo 3.320V 13.80mA`, with the 5V channels
  zero. Controller HIGH and display current agree (45.60 vs 46mA), while the
  load-based estimate is about 6.73× higher. Load voltage is about 44mV below
  the reported INA/panel voltage. The panel's 0.15W is consistent with
  `3.32V × 0.046A ≈ 0.153W`, but far below the load-based 1.005W estimate.
  The same uncertainty limitations as CH1 apply. The 200mΩ firmware
  denominator with a 20mΩ HIGH shunt predicts about 30.7mA for this load,
  below the observed 45.6mA; the known range conversion mismatch alone does
  not fully explain the capture. No coefficients were changed.
- **CH1 HIGH direct-current capture (operator log, 2026-10-07):** Fluke 87 in
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

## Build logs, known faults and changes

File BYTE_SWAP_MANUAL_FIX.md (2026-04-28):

# Manual Byte-Swap Fix (Build System Workaround)

## Problem
Build system having issues with GFX library compilation. PlatformIO flag approach blocked.  
**Solution**: Manually edit the color byte-send order in C++ code directly.

## Quick Fix (60 seconds)

### Step 1: Open File
Open `src/display_main.cpp`

### Step 2: Find the Function
Search for `legacyFillScreenRaw565` (around line 407)

### Step 3: Swap the Bytes

**Current (WRONG - causing B&W pattern):**
```cpp
for (uint32_t i = 0; i < px; ++i) {
    SPI.transfer(hi);  // HIGH BYTE FIRST
    SPI.transfer(lo);  // LOW BYTE SECOND
}
```

**Change To (TEST THIS):**
```cpp
for (uint32_t i = 0; i < px; ++i) {
    SPI.transfer(lo);  // LOW BYTE FIRST
    SPI.transfer(hi);  // HIGH BYTE SECOND
}
```

### Step 4: Build and Test
```bash
platformio run -e display_board -t upload
```

### Step 5: Observe
- Unplug display 5+ seconds
- Replug
- **If RED appears**: Byte-swap is correct ✅
- **If B&W continues**: Swap back and try alternatives

---

## Why This Matters

16-bit RGB565 color format requires bytes in specific order:
- **Hi-Lo** (current): Sends high byte first, low byte second
- **Lo-Hi** (test): Sends low byte first, high byte second

Display ST7796 controller may expect Lo-Hi order.

---

## Expected Result When Fixed

After byte-swap fix + upload + reboot:
- Backlight ramps brightness 0→255
- Screen fills with **RED** color
- Serial output shows diagnostics
- Display responds to subsequent color commands

---

## If Byte-Swap Fixes It

Commit the change:
```cpp
for (uint32_t i = 0; i < px; ++i) {
    SPI.transfer(lo);  // FINAL: Lo-Hi byte order
    SPI.transfer(hi);
}
```

This becomes the permanent fix for RED framebuffer.

---

## Build Command Quick Reference

```bash
# From WorkStation folder
cd "c:\Users\user\Esp32 projects VScode\WorkStation"

# Build only
platformio run -e display_board

# Build and upload
platformio run -e display_board -t upload
```

---

## Status

- ✅ SPI pins FIXED (11/13 instead of 13/11)
- ✅ B&W pattern CONFIRMED (data flowing)
- ⏳ Color byte order TESTING (next step)
- ⏳ RED framebuffer AWAITING (depends on byte-swap)

Once this fix works, RED will appear and diagnostic phase is COMPLETE.

---

**Action**: Edit `src/display_main.cpp` lines ~414-418, swap the SPI.transfer() call order, rebuild, and report if RED appears.

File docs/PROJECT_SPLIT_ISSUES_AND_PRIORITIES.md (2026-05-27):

# Project Split: Issues and Priorities

**Date**: May 14, 2026  
**Scope**: Complete issue inventory for both redesign path and bring-up continuation path  

---

## Overview

The WorkStation power-supply project is splitting into two parallel efforts:

1. **Redesign Path**: PCB revision with architectural improvements; designs for next-generation boards
2. **Bring-Up Path**: Continue developing on Rev 1 hardware; learn failure modes and system behavior

This document tracks all known issues, their priority, and which path owns each.

---

## Status Legend

| Symbol | Meaning |
|---|---|
| 🔴 | High priority — blocks system validation or creates risk |
| 🟡 | Medium priority — design flaw or missing feature |
| 🟢 | Low priority — quality-of-life, optimization, or future expansion |
| 📍 | Redesign Path — owned by PCB redesign cycle |
| 🔧 | Bring-Up Path — addressed while developing on Rev 1 |
| ✅ | Resolved — change committed or accepted workaround in place |

---

## Electrical & Power Issues

### 1. LM2596 Feedback Path: Open Circuit When MOSFETs Off
**Status**: 🟡 Topology implemented on Rev-B and verified in netlist; bring-up validation pending for closure  
**Path**: 📍 Redesign (implemented in Rev-B) + 🔧 Bring-Up (validation and any value retune)  
**Priority**: High (functional flaw)  
**Description**: Feedback divider (measuring 5V output for regulation) is located after output MOSFETs (Q1/Q7, Q2/Q8). When MOSFETs are off at cold-start, the feedback path is open, causing the LM2596 to regulate to ~10.7V instead of 5V until the MCU boots and closes the MOSFET gates.  
**Current Workaround (Rev1 bring-up baseline)**: Jumper to sense before MOSFET; tenths of volt offset accepted as calibration margin. Less critical since +5V bootstrap regulator was added to power the MCU without waiting on the main rail.  
**Rev-B Baseline**: Use the implemented 3-channel selector topology as the active baseline; do not introduce new topology changes unless bring-up data shows continuity error that requires value retuning.  
**Implemented Rev-B Topology**: Op-amp plus Schottky selector per channel (all three channels: 5V, 3.3V, Adj):

Each channel now uses two buffered sense paths combined through a BAT54C selector node, with remote-sense intended as primary and local-sense intentionally underbiased as fallback.

**Sense points per channel:**

| Channel | Sense A node (always-live) | Sense A net (regulator) | Sense B path (HAT → regulator) | Sense B net (regulator) | FB net |
|---|---|---|---|---|---|
| 5V | L3 pin 2 | `+5V_reg` | `V_out +5V` → R59 (10Ω) → `VSENSE_5V+` → J4 pin 3 → J1 pin 4 | `Feedback 5V` | `Net-(U4-FB)` |
| 3.3V | L1 pin 2 | `+3.3V_Reg` | `V_out +3V3` → R61 (10Ω) → `VSENSE_3V3+` → J4 pin 15 → J1 pin 9 | `Feedback 3.3` | `Net-(U3-FB)` |
| Adj | L5 pin 2 | `+V Adj Channel` | `V_out +CH3` → R63 (10Ω) → `VSENSE_ADJ+` → J6 pin 12 → J2 pin 4 | `Feedback Adj Channel` | `Net-(U2-FB)` |

**Op-amp selector cell (per channel):**
- **Remote path buffer**: Non-inverting buffer for VSENSE path into selector input
- **Local path buffer**: Non-inverting buffer for always-live local rail path into selector input
- **Selector/output node**: BAT54C common-cathode combine to LM2596 FB-divider top node
- **Intent**: Remote path wins in normal operation; local path is slightly lower to provide startup fallback without introducing large measurement handoff steps
- **Verified Rev-B values**: R31/R33/R35 = 100 ohm and R32/R34/R36 = 33k on local fallback legs

**Parts count (new additions):**
- 3 × dual op-amp (e.g., LMV358 SOT-23-8) — one per channel, 6 buffer sections total
- 6 × Schottky diode (e.g., BAT54 or similar, low Vf) — 2 per channel
- 3 × resistive divider for Sense A (2 resistors per channel matching existing Sense B ratio)
- 3 × 100pF compensation cap for Sense A divider (matching C21/C7/C11)

**Residual Impact of Bootstrap Fix**: +5V bootstrap regulator still shortens cold-start exposure, but RB-001 closure now depends on bring-up continuity data, not additional topology creation.  
**Next Action**: Preserve current topology and execute bring-up validation; retune local attenuation values only if measured continuity/step error exceeds expectation.  
**Tracker Alignment Note**: This item has moved from "topology creation" to "bring-up validation and possible value tuning."  
**Control Ownership Rule**: Keep the output MOSFETs as the load-connect/load-isolate layer. Use LM2596 pin 5 as the authoritative hard-disable point for faults and short-circuit shutdown. A low-side pull-down stage can assert enable, but it cannot by itself implement a fault-off override.

**Desired Rev-B control truth table**:

| Load command | Fault critical | Output MOSFET state | LM2596 pin 5 state | Result |
|---|---|---|---|---|
| Disable | Inactive | Off | High / disable | Rail off, load isolated |
| Enable | Inactive | On | Low / enable | Rail on, load connected |
| Disable | Active | Off | High / disable | Fault wins, rail off |
| Enable | Active | Off | High / disable | Fault overrides command, rail off |

**Schematic edit implication**: if a shutdown path currently shares a low-side BSS138 pull-down with the enable path, it must be inverted or moved to a disable-only node so that fault assertion forces the shutdown state instead of reinforcing enable.

**Reference**: [HANDOFF.md](../HANDOFF.md) and [NEW_CHAT_HANDOFF.rmd](../NEW_CHAT_HANDOFF.rmd)

---

### 2. USB Vbus Backfeed: HAT/ESP32 USB 5V Fights Regulator 5V
**Status**: 🟢 On hold for current MPU path | ⏳ Re-open only if MPU changes to a design with board-exposed VBUS  
**Path**: 📍 Redesign (long-term), 🔧 Bring-Up (avoid during testing)  
**Priority**: High (current-limit during stacked test)  
**Description**: When HAT is powered by 5V regulator output AND connected to USB, USB Vbus (~10V) back-drives the 5V rail, causing voltage sag and current limiting (observed 520mA @ 9.3V during first stacked test).  
**Current Workaround**: Disconnect USB 5V or use data-only cable during bench testing  
**Redesign Solution**: Add Schottky diode on Vbus on HAT PCB to isolate USB from 5V rail  
**Board Change Note**: For the current architecture, boot-regulator power to MPU and non-exposed board VBUS make this a non-blocking item. Keep this issue parked unless MPU migration re-introduces direct VBUS exposure on-board.  
**Bring-Up Impact**: No USB power during load testing; use serial-only debugging if needed  
**Next component placement package (only if MPU migration requires VBUS handling)**:
- 1 x series Schottky on USB VBUS path (recommended start: SS14 or SS24, anode at USB VBUS side, cathode at local +5V rail side).
- 1 x optional resettable fuse on USB VBUS input before the Schottky (recommended start: 500mA hold) for cable/port fault limiting.
- 1 x optional VBUS bleed resistor to GND on USB-side node (recommended start: 100k) to discharge cable-side float when unplugged.
- 2 x test points: `TP_USB_VBUS_IN` (before diode) and `TP_USB_VBUS_OUT` (after diode) for bring-up verification.
**Reference**: [HANDOFF.md](../HANDOFF.md) and [NEW_CHAT_HANDOFF.rmd](../NEW_CHAT_HANDOFF.rmd)

---

### 3. ON/OFF Pin Switching: MOSFET Gate Drive Circuit
**Status**: 🟡 Topology implemented, validation pending  
**Path**: 📍 Redesign (design review)  
**Priority**: High (control reliability)  
**Description**: LM2596 pin 5 (ON/OFF) uses N-channel MOSFET for low-side pull-down. Gate drive voltage, rise/fall time, debounce behavior not yet characterized under load transients.  
**Next Step**: Scope gate voltage, drain voltage, and load response during ON → OFF → ON cycles  

**Control contract for the Rev-B edits**:
- The MOSFET pair that touches `~{ON}/OFF` is a load-enable path, not a fault-off path.
- A fault signal must either drive a separate disable element or be inverted before it reaches the shutdown node.
- If the same low-side pull-down polarity is used for both enable and fault, fault assertion can only reinforce enable, which is the wrong polarity for shutdown.
- Use one fault-isolation diode per rail from `FAULT_CRITICAL_SUM` to each enable gate node instead of tying the three gate nets together. That preserves per-rail enable control while still letting fault pull the active gate low.

**2026-05-19 implementation snapshot (netlist)**:
- Fault fanout present: `FAULT_CRITICAL_SUM` -> `R37`, `R39`, `R45` (pin 1 on each resistor).
- Per-rail diode isolation present: `D7`, `D8`, `D10` between each fault branch and each gate net (`Q1-G`, `Q4-G`, `Q5-G`).
- Cross-coupled gate net condition is removed at the netlist level.

**Bring-up instrumentation status (2026-05-19):**
- Gate and fault test points added (3 on regulator path, 1 on HAT path).

**Fault-conditioning component status (2026-05-19 netlist):**
- Implemented: branch pull-ups (`R47`, `R48`, `R49`) to `+5V_Boot`.
- Implemented: branch RC caps (`C14`, `C17`, `C23`) at the three fault-injection branches.
- Implemented: connector entry series resistor (`R50`) between `J2 Pin_3` and `FAULT_CRITICAL_SUM`.

**Next steps (validation, not new components):**
- Scope `FAULT_CRITICAL_SUM` and each gate net (`Q1-G`, `Q4-G`, `Q5-G`) during injected fault pulses and verify no cross-coupled gate transitions.
- Measure fault assert/release timing through `R50` and branch RC networks to confirm shutdown response stays within protection targets.
- Run truth-table bench validation for all four states (Enable/Disable x Fault inactive/active) and record resulting `~ON/OFF` pin state per channel.

**Desired shutdown truth table**:

| MCU rail-enable | Fault critical | Expected `~{ON}/OFF` | Expected regulator state |
|---|---|---|---|
| 0 | 0 | High | Disabled |
| 1 | 0 | Low | Enabled |
| 0 | 1 | High | Disabled |
| 1 | 1 | High | Disabled |

**Current Rev-B netlist snapshot (for schematic review):**
- 3.3V channel control path:
	- Gate drive input: `ISET_MPU_3V3` -> R2 (100 ohm)
	- Gate pull element: R6 (100k to GND)
	- ON/OFF node pull element: R1 (10k to +5V_Boot; verified in current netlist export)
	- LM2596 ON/OFF node: U3 pin 5 via net `Net-(Q16-D)`
	- Netlist observation: Q16 source (pin 2) is currently on `GND`
- 5V channel control path:
	- Gate drive input: `ISET_MPU_5V` -> R24 (100 ohm)
	- Gate pull element: R4 (100k to GND)
	- ON/OFF node pull element: R5 (10k to +5V_Boot; verified in current netlist export)
	- LM2596 ON/OFF node: U4 pin 5 via net `Net-(Q3-D)`
	- Netlist observation: Q3 source (pin 2) is currently on `GND`
- Adj channel control path:
	- Gate drive input: `ISET_MPU_Channel_3` -> R63 (100 ohm)
	- Gate pull element: R64 (100k to GND)
	- ON/OFF node pull element: R65 (10k to +5V_Boot; verified in current netlist export)
	- LM2596 ON/OFF node: U2 pin 5 via net `Net-(Q2-D)`
	- Netlist observation: Q2 source (pin 2) is currently on `GND`

Netlist baseline verified (2026-05-19):
- ON/OFF pull values: R1/R5/R65 = 10k (not 100k as previously documented)
- Gate pull values: R4/R6/R24/R64 = 100k as documented
- Source-side bias: Q2/Q3/Q16 sources on GND (no source-specific ties to +12V present)

**RB-003 schematic checklist (execute in-order):**
1. Confirm intended ON/OFF polarity and thresholds at the LM2596 pin for each channel.
2. Verify symbol pin mapping for Q2/Q3/Q16 against the selected BSS138 footprint orientation in schematic and PCB.
3. Validate whether source-node bias is intentionally referenced to +12V for this topology.
4. Compare available gate drive high levels (ISET_MPU_3V3, ISET_MPU_5V, ISET_MPU_Channel_3) versus source-node potential to ensure expected Vgs sign and magnitude.
5. Confirm ON/OFF node default state at reset using the current 100k pull network (R1/R5/R65 and gate pulls R6/R4/R64).
6. If Vgs operating margin is invalid, update topology (device orientation and/or device type and/or drive reference) before any value tuning.
7. Re-export netlist and verify U2/U3/U4 pin-5 control nets still map one-to-one with their channel-select inputs and default pulls.

**Pass criteria for RB-003 closure:**
- Each channel has a valid control-state truth table (OFF and ON) with achievable gate drive margins at worst-case supply.
- Default power-up state is deterministic and matches intended safety behavior.
- ON/OFF transitions are explainable from schematic alone without relying on ambiguous pin orientation assumptions.

**Reference**: [HANDOFF.md](../HANDOFF.md) and [NEW_CHAT_HANDOFF.rmd](../NEW_CHAT_HANDOFF.rmd)

---

### 4. Internal Voltage Rail Protection: OCP/OVP Fuses or Monitoring
**Status**: 🟡 Open  
**Path**: 📍 Redesign (design review)  
**Priority**: Medium (fault tolerance)  
**Description**: No per-rail fuses or TVS diodes protecting against short-circuit or overvoltage. LM2596 internal OCP is only protection; relies on bench PSU external fuse.  
**Bring-Up Strategy**: If a rail is shorted, test bench PSU defensive behavior; record fuse-trip time and power shutdown response  
**Redesign Solution**: Add SMD fuses (e.g., 2A for 5V, 1.5A for 3.3V) or TVS diodes per output; evaluate firmware rail monitoring thresholds  
**Reference**: [HANDOFF.md](../HANDOFF.md) and [NEW_CHAT_HANDOFF.rmd](../NEW_CHAT_HANDOFF.rmd)

---

### 12. Bootstrap Rail Split Naming: Contract Cleanup Pending
**Status**: ✅ Resolved (Rev-B naming normalized and contract checks updated)  
**Path**: 📍 Redesign (net-contract correction)  
**Priority**: High (cross-board contract consistency)  
**Description**: Bootstrap naming and ownership language had drifted across handoffs and analysis docs. The requirement was to align Rev-B to a single naming contract and re-verify in both schematic and netlist exports.  
**Impact**: Prior ambiguity could misdirect routing and cross-board contract updates.  
**Resolution**: Rev-B exports are normalized to `+5V_Boot` only, and connector-contract verification now supports explicit baseline policy modes (`reduced-policy` default, `strict` audit mode) so redesign gating follows the active reduced-contract path while preserving strict baseline auditing when needed.  
**Reference**: [HANDOFF.md](../HANDOFF.md) and [NEW_CHAT_HANDOFF_SHORT.rmd](../NEW_CHAT_HANDOFF_SHORT.rmd)

---

## PCB Layout & Mechanical Issues

### 5. TS5A3157-DCKR Footprint: Incorrect Package Match
**Status**: ✅ Resolved on Rev-B (symbol library default + instance aligned)  
**Path**: 📍 Redesign (high priority)  
**Priority**: High (assembly and functional risk)  
**Description**: Footprint used for analog switch does not match SOT-363/SC-70-6 package pinout or land pattern. Risk of rotated/misaligned placement or non-functional switch path.  
**Current Impact**: ✅ Rev-B instance footprint corrected to `Package_TO_SOT_SMD:SOT-363_SC-70-6` (LCSC C91307); symbol library default footprint also updated to prevent regressions.  
**Redesign Action**: Completed. Symbol library default is now locked to correct footprint; assembly risk eliminated for new instances in this schematic.  
**Reference**: [HANDOFF.md](../HANDOFF.md)

---

### 6. Input Voltage Terminal Block: Labeling and Polarity Clarity
**Status**: 🟡 Open  
**Path**: 📍 Redesign (assembly QA)  
**Priority**: Medium (user experience / assembly error prevention)  
**Description**: Input 12V terminal block needs clear polarity marking in silkscreen; physical keying or polarity guard preferred.  
**Redesign Actions**:  
- Add silkscreen arrows and +12V / GND labels
- Consider upgrading to keyed connector type
- Document wire gauge and current rating for each terminal  
**Reference**: [HANDOFF.md](../HANDOFF.md)

---

### 7. Stack Height Connector: Physical Fit and Viability
**Status**: 🟡 Open  
**Path**: 📍 Redesign (mechanical review)  
**Priority**: Low to Medium (mechanical integration)  
**Description**: HAT stacks on regulator via connector; stack height may not fit intended enclosure; alignment/contact pressure not yet validated under load.  
**Bring-Up Observations**: Manual stacking works on bench; no mechanical feedback issues observed during light load  
**Redesign Actions**:  
- Measure final stack height with connector
- Review enclosure mechanical constraints
- Confirm connector contact rating for observed current levels
- Evaluate alignment pins/slots for removal/insertion robustness  
**Reference**: [HANDOFF.md](../HANDOFF.md)

---

### 8. ESP32 Footprint: Compatibility and Silk Clarity
**Status**: 🟡 Under investigation  
**Path**: 📍 Redesign (assembly clarity)  
**Priority**: Medium (assembly accuracy)  
**Description**: ESP32 footprint may not match variant in use (originally designed for standard ESP32; bench testing used ESP32-C6). Silk labels for critical pins unclear post-assembly.  
**Bring-Up Finding**: HAT discovered with ESP32-C6, not standard ESP32; pin mapping is GPIO5/GPIO6 per HAT schematic, not footprint dependent  
**Redesign Actions**:  
- Verify footprint matches deployed variant
- Review/clarify silk legends for critical pins
- Confirm mechanical clearance around USB connector  
**Reference**: [HANDOFF.md](../HANDOFF.md)

---

### 9. Buck Output Status LED: Design Consideration
**Status**: 🟢 Design proposal  
**Path**: 📍 Redesign (nice-to-have)  
**Priority**: Low (user feedback / debugging aid)  
**Description**: Proposal to add LED on 5V buck output to indicate power-on, fault, or current-limit mode visually.  
**Bring-Up Strategy**: Not critical for bringup; skip on Rev 1  
**Redesign Considerations**:  
- LED current draw (~1–2mA @ 2V drop, standard ~1kΩ series resistor)
- Blink pattern for fault states (OCP, OVP, current-limit cycle)
- Firmware output pin assignment required  
**Reference**: [HANDOFF.md](../HANDOFF.md)

---

## Measurement & Control Issues

### 10. INA3221 Current Mapping: Channel-to-Rail Assignment Incorrect
**Status**: 🔴 Confirmed  
**Path**: 🔧 Bring-Up (debug), 📍 Redesign (schematic review)  
**Priority**: High (telemetry accuracy)  
**Description**: INA3221 current readings do not match known load behavior. With 10 ohm load on 3.3V drawing ~327mA, INA reports only 18–20mA on loaded channel. Likely cause: wrong channel-to-shunt mapping, incorrect shunt values assumed, or sense routing does not place load current through the expected shunt.  
**Observed Data** (as of 2026-05-11):
- Loaded 3.3V: measured ~3.27V, expected ~327mA, INA reported 18mA on CH1/CH2
- Voltage telemetry appears directionally correct (3.304V INA vs ~3.273V measured)
- Input shunt (CH3 @ 0x41) also suspect: 11.544V and 252mA reported vs ~12.02V measured

**Bring-Up Debug Plan**:  
1. Build channel-to-shunt truth table from HAT schematic
2. Meter actual shunt resistor values on board (20mΩ vs 200mΩ assumed)
3. Load one rail at a time and trace INA reading for the corresponding channel
4. Identify which channels are correctly routed vs. misassigned

**Redesign Review**:  
- Verify HAT schematic rail-to-INA-channel assignment
- Confirm shunt value assumptions with actual BOM
- Update firmware mappings based on truth table  
**Reference**: [STACKED_BOARD_FIRST_POWER_BASELINE.md](STACKED_BOARD_FIRST_POWER_BASELINE.md) INA Confidence Check section

---

### 11. Adjustable Rail Feedback: Disconnected or Default State
**Status**: 🟡 Open  
**Path**: 🔧 Bring-Up (verify), 📍 Redesign (schematic check)  
**Priority**: Medium (rail control)  
**Description**: Adjustable rail (channel 3) reading same voltage as 3.3V reference, suggesting feedback divider not connected or in default state. Rail should be independently adjustable via ISET potentiometer or digital trim (MCP4231).  
**Bring-Up Investigation**:  
- Check feedback divider continuity (from adjustable output to feedback network)
- Verify potentiometer (ISET) range and orientation
- Measure feedback network voltage vs potentiometer output
- If applicable, check LM2596 feedback pin (pin 4) for proper divider scaling  
**Redesign**: Ensure feedback network is present and properly routed if adjustable rail intended to be independent

---

### 13. Short-Circuit Feedback Path: Protection Feedback Integration Missing
**Status**: 🟡 Digital fault path implemented on Rev-B; analog instantaneous OCP path pending  
**Path**: 📍 Redesign (control/protection integration)  
**Priority**: High (layout blocker for protection/control routing)  
**Description**: Short-circuit behavior now has a dedicated digital fault feedback path in Rev-B via INA3221 alert outputs summed into named nets and routed into control logic. An analog instantaneous over-current path is still needed if sub-conversion-cycle protection response is required.  
**Impact**: Digital fault ownership/routing blocker is cleared; fast analog trip capability remains an open integration item.  
**Redesign Actions**:  
- Define explicit short-circuit feedback signal path (source, sink, polarity, threshold intent)
- Connect INA `CRITICAL`/`WARNING` outputs to named fault nets (wired-OR or per-rail scheme) and route to MCU/control domain with proper pull-up strategy
- Rev-B default proposal: use `FAULT_CRITICAL_SUM` and `FAULT_WARNING_SUM` nets and route to currently unconnected MPU pins (`U7.GPIO22` and `U7.GPIO2`) to avoid blocking layout while MPU migration is deferred
- Add named net(s) and connector contract updates where required
- Ensure feedback path is represented in both regulator Rev-B and HAT Rev-B schematics/netlists

**Verification Evidence (2026-05-18)**:
- `FAULT_CRITICAL_SUM` includes U1/U2/U3 `CRITICAL` plus U7 `GPIO2`
- `FAULT_WARNING_SUM` includes U1/U2/U3 `WARNING` plus U7 `GPIO22`
- Prior `unconnected-(U*-CRITICAL/WARNING-Pad*)` nets are absent from the regenerated Rev-B HAT netlist

**Next component placement package (analog instantaneous OCP)**:
- 3 x fast current-sense front ends (one per rail, reusing existing shunt locations) feeding comparator inputs.
- 1 x multi-channel comparator stage (3 channels + optional spare/latch) to generate per-rail fast-trip outputs.
- 3 x threshold-set networks (divider/reference per channel, or shared reference with per-channel trim) for trip current setpoint.
- 3 x blanking/filter RC networks at comparator inputs to avoid switch-edge false trips.
- 3 x isolation/injection elements from comparator outputs into the existing fault-disable path so analog trip can force shutdown without cross-coupling rails.

**5V channel first (pilot implementation order)**:
- Use the existing 5V shunt path first (R13/R14 network) as the analog current source; do not use R42/R43/R44 (those are INA address-strap resistors).
- Add one open-collector comparator channel for 5V fast-trip (starter: LMV393-family channel at 3.3V logic domain).
- Add one 5V threshold network (starter: fixed divider plus trim option) to set instantaneous trip current.
- Add one input blanking RC (starter: 1k series + 1nF to GND at comparator input) to suppress switching-edge false trips.
- Add one comparator-output isolation/injection element into `FAULT_CRITICAL_SUM` so 5V analog trip can assert shutdown immediately without disturbing 3.3V/Adj enable domains.
- Add two pilot test points: `TP_OCP_5V_SENSE` (comparator sense input) and `TP_OCP_5V_TRIP` (comparator output to fault path).

**5V comparator slice wiring contract (place this one first)**:
- Sense input: take the 5V current-sense differential from the existing R13/R14 shunt network.
- Comparator channel: use only one channel of the quad comparator for this slice; leave the other three channels unplaced or DNP until the 5V slice passes.
- Sense conditioning: place the 1k series resistor and 1nF blanking capacitor right at the comparator input.
- Threshold reference: create a dedicated trip reference for this channel only; do not share the threshold node with the other rails yet.
- Output path: wire the open-collector output to the existing fault net through the planned isolation/injection element, then let the existing fault pull-up define the idle state.
- Verification: populate `TP_OCP_5V_SENSE` at the comparator input side of the blanking RC and `TP_OCP_5V_TRIP` at the comparator output side of the isolation element.

**5V slice starter component set**:
- 1 x quad comparator IC, but only channel A used for the first slice.
- 1 x 1k input series resistor.
- 1 x 1nF input blanking capacitor.
- 1 x threshold divider/trimmer network for the 5V trip point.
- 1 x output isolation element into `FAULT_CRITICAL_SUM`.
- 2 x test points (`TP_OCP_5V_SENSE`, `TP_OCP_5V_TRIP`).

**Current implementation snapshot (2026-05-20, HAT Rev-B)**:
- Comparator IC placed (`TLV1704AIPWR`) and powered from +12V/GND.
- Two comparator outputs (`OUT1`, `OUT2`) now assert `FAULT_CRITICAL_SUM` directly (global trip behavior confirmed).
- Input blanking parts are present for first two channels (1k + 1nF per channel).
- Threshold trim network parts are present for first two channels.

**Next component placement batch (continue from here)**:
- Add explicit output isolation options for comparator outputs into `FAULT_CRITICAL_SUM` (DNP-friendly):
	- Starter option: one small-signal diode per comparator output to fault net.
	- Alt option: one small series resistor per output if diode isolation is deferred.
- Add dedicated pilot test points with final names:
	- `TP_OCP_5V_SENSE` on the comparator-input side of the RC sense node.
	- `TP_OCP_5V_TRIP` on the comparator-output/fault-injection node.
- Park unused comparator channels (U8C/U8D) in a deterministic state:
	- Tie each unused `+IN` and `-IN` to a quiet reference (GND preferred for now).
	- Leave `OUT3`/`OUT4` not connected to fault net until those channels are intentionally used.

**5V pilot pass criteria before cloning to 3.3V and Adj**:
- Fast short/over-current event on 5V rail asserts shutdown path without cross-coupled gate behavior on other rails.
- No false trips during expected load-step transients after RC blanking tuning.
- Trip threshold is measurable and repeatable across bench temperature and supply variation.

**Integration rule**:
- Keep INA `CRITICAL/WARNING` as telemetry and slower supervisory path.
- Add analog comparator trip as the instantaneous protection path that can assert disable immediately.

**Protection policy decision (2026-05-20)**:
- Instantaneous analog over-current trip is treated as a system-level critical event, not a single-channel local event.
- Any rail asserting analog trip must drive `FAULT_CRITICAL_SUM` and force global shutdown.
- Rationale: once current exceeds controllable behavior, fail-safe full shutdown is preferred over selective rail isolation.

**Comparator selection shortlist (recommended order)**:
- Option A (preferred): TLV1704 (quad, open-drain outputs, wide supply range, single IC covers 3 rails + 1 spare channel).
- Option B: LM339 family (quad, open-collector outputs, common and widely available, good for wired-fault integration).
- Option C: LMV339 family (quad, low-voltage focused, suitable when comparator domain is fixed at 3.3V).

**Package decision guidance**:
- Use one quad comparator IC for the whole board (3 active channels + 1 spare/latch channel).
- If placement density is tight, choose TSSOP-14 or SOIC-14.
- If hand rework is expected during bring-up, prefer SOIC-14 for easier probing and replacement.

**Minimum electrical requirements for selected part**:
- Open-drain or open-collector outputs (needed for safe OR/injection into fault path).
- Input common-mode range that includes the sensed shunt-comparator operating range.
- Propagation delay fast enough for intended instantaneous trip behavior.
- Stable operation at chosen comparator supply rail (3.3V domain preferred for MCU/fault logic compatibility).

---

### 14. Reference Sensing Path: Architecture Not Finalized
**Status**: 🟢 Contract verified on Rev-B netlists  
**Path**: 📍 Redesign (measurement architecture)  
**Priority**: High (layout blocker for analog routing quality)  
**Description**: Reference sensing requirements (reference node source, return path, and isolation strategy) are not finalized in the active hardware contract. Rev-B already contains `VSENSE_3V3±`, `VSENSE_5V±`, and `VSENSE_ADJ±` nets, but there is no locked reference-sensing contract defining the reference anchor and Kelvin/return strategy for final layout.  
**Impact**: Layout blocker cleared at schematic/netlist level; contract is now defined and present across regulator and HAT Rev-B netlists.  
**Redesign Actions**:  
- Define reference sensing source and return explicitly (including where analog reference ties to power ground)
- Lock Kelvin sense routing rules for `VSENSE_*` pairs (pairing, return locality, and keep-out from switching paths)
- Add/confirm net names and measurement entry points in Rev-B schematics
- Freeze a reference contract table for layout: `VSENSE_3V3±`, `VSENSE_5V±`, `VSENSE_ADJ±` with mapped measurement sink and physical test access
- Validate consistency with INA/channel sensing and feedback nets

**Reference Sensing Contract (Rev-B Lock v1)**:

| Pair | Regulator/HAT Entry | Measurement Sink | Routing Contract |
|---|---|---|---|
| `VSENSE_3V3+/-` | `J4` pins 15/14 | Divider inputs via `R61/R63` and `R62/R64` | Route as paired Kelvin sense lines; keep local return with its + pair; avoid switching-node adjacency |
| `VSENSE_5V+/-` | `J4` pins 3/2 | Divider inputs via `R59/R60` | Route as paired Kelvin sense lines; maintain matched local return path |
| `VSENSE_ADJ+/-` | `J6` pins 12/11 | Sense/protection entry via `D7` (`+`) and `D1` (`-`) | Route as paired Kelvin sense lines; keep reference return tied to same channel locality |

**Verification Evidence (2026-05-18)**:
- Regulator Rev-B netlist includes all six `VSENSE_*` nets with connector entries on `J1`/`J2`
- HAT Rev-B netlist includes all six `VSENSE_*` nets with matching connector entries on `J4`/`J6`
- Pair structure is consistent with divider/protection entry points documented in this contract table

**Implementation note for layout**:
- Keep Kelvin pairing and return-locality rules enforced during PCB routing; treat this as a layout quality rule, not a remaining schematic blocker

---

### 15. MPU Change Plan: Active Migration Closure Workflow
**Status**: 🟡 In Progress (active pre-freeze workflow)  
**Path**: 📍 Redesign (platform transition planning)  
**Priority**: High (Rev-C pin-freeze dependency)  
**Description**: MPU migration is now an active closure gate for Rev-C. Use STM32 Blue Pill as the initial target while keeping the plan non-constraining: escalate to a larger STM32 if objective closure gates fail.  
**Current Decision**: Hardware-only migration planning is in scope now. Firmware rewrite remains out of scope for this document phase.  

**Locked decisions (2026-05-24):**
- Start with STM32 Blue Pill for mapping and footprint planning.
- Keep migration non-constraining: permit scale-up to larger STM32 if required.
- Include both UART and SWD paths in hardware.
- Keep Arduino-style firmware direction for first software phase (tracked, not implemented here).

**Required closure outputs before Rev-C pin freeze:**
1. STM32 interface remap table from ESP32-C6 logical functions to candidate STM32 pins.
2. Voltage-domain compatibility table for all migrated MCU-facing nets.
3. Boot/program/debug contract with both UART and SWD connectivity.
4. MCU-critical connector/net assignment rules aligned with mixed dual-connector policy.
5. Explicit pin-freeze readiness decision: PASS, HOLD, or FAIL with rationale.

**Scale-up trigger gates (Blue Pill -> larger STM32):**
1. GPIO budget fails after assigning all must-have nets.
2. Required peripheral placement conflicts cannot be resolved without high-risk pin reuse.
3. Reset/default-safe state requirements for rail control and fault response are not met.
4. UART+SWD debug/program path cannot be completed without conflicts.

**Connector-pin assignment rules for MCU-critical nets:**
1. Keep `FAULT_CRITICAL_SUM` on a low-noise route with adjacent reference ground and no long detours.
2. Keep I2C pair and its quiet return grouped to preserve measurement integrity.
3. Keep `ISET_MPU_*` control lines away from noisy power-switching regions at connector fanout.
4. Reserve access for SWD and UART pins so they are not consumed by optional features.

**Pin-freeze readiness checklist (Issue 15 closure):**
1. All mandatory MCU logical functions are mapped and conflict-free.
2. Voltage levels and pull ownership are valid at reset and fault conditions.
3. UART and SWD paths are complete and test-accessible.
4. MCU-critical net allocation fits connector policy and quiet-ground constraints.
5. Scale-up recommendation recorded (stay Blue Pill or move up) with evidence.

**Progress snapshot (2026-05-24):**
- Closure outputs 1-4 are now documented in `docs/PCB_REDESIGN_PREP_2026-05-20.md` under Phase 10 (hardware-only migration baseline).
- Output 5 remains open with one identified blocker: **KERC-04 reset-safe startup evidence**.
- Execution checklist in Phase 10.6 is now mostly closed: `KMCU-01..07` are complete and `KERC-01/02/03/05/06` are promoted based on latest ERC evidence.
- Latest ERC evidence remains warning-only (`Errors 0`, `Warnings 50`) and no longer blocks pin-conflict, SWD, UART, fault, or I2C integrity gates.
- Remaining hold is validation-only (bench/firmware): prove rail-control defaults remain inactive through reset/early boot and assert only after controlled firmware init.
- U7 symbol identity is now normalized to local Blue Pill migrated symbol naming in the active HAT schematic; remaining hold is bench evidence only.
- Bench execution reference: `docs/KERC-04_RESET_STARTUP_VALIDATION.md`.

**Issue 15 gate result:** [HOLD - KERC-04 only] (reset-safe startup evidence pending)

---

## Summary: Issues by Path

### 📍 Redesign Path Issues (PCB Next Iteration)

| Issue | ID | Priority | Action |
|---|----|---|----|
| Feedback divider before MOSFET | RB-001 | High | Topology implemented on Rev-B; validate handoff continuity and retune only if needed |
| USB Vbus isolation on HAT | RB-002 | High | On hold for current MPU path; re-open only if MPU migration exposes VBUS on-board |
| TS5A3157 footprint correction | RB-009 | High | ✅ Locked to Package_TO_SOT_SMD:SOT-363_SC-70-6 on Rev-B |
| MOSFET gate drive characterization | RB-003 | High | Scope transient; optimize pull-up/down resistors |
| Rail protection (fuses/TVS) | RB-006 | Medium | Add SMD fuses and/or TVS diodes per output |
| Bootstrap split net labels | 12 | High | ✅ Rev-B naming normalized to `+5V_Boot`; reduced-contract gate closed, strict baseline kept for audit |
| Short-circuit feedback path | 13 | High | Digital INA path implemented; add analog instantaneous OCP comparator path for fast trip |
| Reference sensing architecture | 14 | High | Verified on Rev-B netlists; enforce Kelvin pair/return-locality rules during layout |
| MPU migration closure workflow | 15 | High | Active gate: close remap, level checks, UART+SWD path, and pin-freeze PASS/HOLD/FAIL |
| Terminal block labeling | RB-004 | Medium | Add silkscreen polarity + keyed connector |
| ESP32 footprint clarity | RB-005 | Medium | Verify variant match; update silk legends |
| Stack height/connector review | RB-007 | Low | Measure height; confirm alignment pins; contact rating |
| Buck output LED (optional) | RB-008 | Low | Design LED circuit; firmware pin assignment |
| INA current mapping (architectural) | 10 | High | Review HAT schematic rail-to-channel assignment; verify shunt BOM |

---

### 🔧 Bring-Up Path Issues (Continue on Rev 1)

| Issue | ID | Priority | Action |
|---|----|---|----|
| USB Vbus workaround validation | RB-002 | High | Keep current safe testing procedure; no new hardware action unless MPU migration changes VBUS exposure |
| RB-001 continuity and handoff-step validation | RB-001 | High | Measure remote/local handoff behavior across load and startup; retune local attenuation if needed |
| INA current debug & mapping | 10 | High | Build truth table; meter shunt values; correlate channels to rails |
| Adjustable rail feedback investigation | 11 | Medium | Check continuity; verify potentiometer; characterize output range |
| Rail protection behavior | RB-006 | Medium | Intentional short-circuit test (safe conditions); record fuse trip time |
| MOSFET switch transient logging | RB-003 | Medium | Scope gate/drain during control transitions; document rise/fall times |
| System load-testing at higher currents | Various | Medium | Test with multiple loads; verify no unexpected behavior or resets |

---

## Implementation Strategy

**Redesign Path** (High-level process):
1. Create `dsp-regulator-next-iter/` and `dsp-regulator-hat-next-iter/` folders in `hardware/kicad/`
2. Copy current schematics as starting points
3. Apply fixes from highest-priority items first
4. Perform ERC/DRC validation on each change
5. Tag each fix with issue ID for traceability

**Bring-Up Path** (High-level process):
1. Execute debugging plan for INA current mapping (build truth table, meter values)
2. Document safe procedures for USB isolation, load testing, protection validation
3. Log any new issues discovered during testing
4. Keep Rev 1 hardware stable as testbed for system discovery

---

## Reference Documents

- [PROJECT_SPLIT_ISSUES_AND_PRIORITIES.md](PROJECT_SPLIT_ISSUES_AND_PRIORITIES.md) — Detailed electrical and design issues (RB-001 through RB-009)
- [STACKED_BOARD_FIRST_POWER_BASELINE.md](STACKED_BOARD_FIRST_POWER_BASELINE.md) — Bench bring-up measurements and INA confidence assessment
- [GPIO_PINOUT.md](GPIO_PINOUT.md) — I2C bus and control signal mapping
- [power_telemetry_map.h](../../src/power_telemetry_map.h) — INA address definitions and rail mapping (to be updated based on truth table)

---

## Revision History

| Date | Event |
|---|---|
| 2026-05-14 | Created PROJECT_SPLIT_ISSUES_AND_PRIORITIES.md; consolidated all issues from bring-up and design review |
| 2026-05-18 | Added issue 12 for missing bootstrap split net labels and redesign-path contract alignment |
| 2026-05-18 | Added issues 13-15 for short-circuit feedback integration, reference sensing architecture, and deferred MPU migration tracking |
| 2026-05-18 | Re-validated Rev-B HAT netlist: issue 13 fault nets implemented and no INA CRITICAL/WARNING no-connect remnants; added Reference Sensing Contract (Rev-B Lock v1) for issue 14 |
| 2026-05-18 | Cross-board Rev-B VSENSE audit complete: issue 14 promoted to contract-verified at netlist level |
| 2026-05-18 | RB-009 resolved: TS5A3157 symbol library default footprint corrected to Package_TO_SOT_SMD:SOT-363_SC-70-6 on Rev-B |
| 2026-05-18 | Restart alignment: RB-001 status updated to implemented Rev-B 3-channel selector with bench continuity validation pending; issue 12 wording normalized to contract-cleanup state |
| 2026-05-24 | Issue 15 promoted from deferred tracking to active migration closure workflow with explicit scale-up gates, connector assignment rules, and Rev-C pin-freeze checklist |
| 2026-05-24 | Issue 15 migration-label cutover pass completed on HAT schematic: all `*_DRAFT` U7 net labels promoted to final names; ERC baseline restored to warning-only (`Errors 0`, `Warnings 50`) while symbol-library swap remains deferred |
| 2026-05-24 | Issue 12 closed: Rev-B bootstrap naming normalized to `+5V_Boot`; connector verifier updated with `-BaselineFeedbackPolicy` (`reduced-policy` default, `strict` audit) and both Rev-B netlists re-exported after leading-space label cleanup |
| 2026-05-24 | Issue 15 gate narrowed to single blocker: KERC-04 reset-safe startup evidence; other KERC gates documented as closed by latest ERC-backed evidence |
| 2026-05-24 | Issue 15 symbol migration completion: active U7 symbol/lib_id in `DSP Regulator_hat.kicad_sch` renamed to local Blue Pill migrated identity; gate remains HOLD on KERC-04 bench startup evidence only |

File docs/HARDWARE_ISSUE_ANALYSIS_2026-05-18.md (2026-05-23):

# Hardware Issue Analysis - 2026-05-18 (Archived Snapshot)

Purpose: preserve historical analysis context while avoiding conflicts with current restarted handoff guidance.

## Source Of Truth For Active Work

Use these files first for current direction and stop-state:
- HANDOFF.md
- NEW_CHAT_HANDOFF.rmd
- NEW_CHAT_HANDOFF_SHORT.rmd
- docs/PROJECT_SPLIT_ISSUES_AND_PRIORITIES.md

## Archived Summary

This analysis was produced during an earlier in-session verification pass and contained mixed interim findings. The active baseline has since been restarted and normalized.

Current normalized baseline:
- Rev-B regulator/HAT netlists are the active hardware baseline.
- RB-001 3-channel selector implementation is present in Rev-B (LMV358 plus BAT54C with local attenuation).
- Sense-B origins are confirmed on HAT Rev-B (R59/R60, R61/R62, R63/R64).
- Bench continuity validation remains pending for final RB-001 closure.
- Bootstrap naming and ownership statements should be treated as contract-cleanup items unless explicitly re-verified in latest exports.

## How To Use This File

- Treat this file as historical context only.
- Do not use old "pending/implemented" claims here to override HANDOFF.md.
- If any statement here conflicts with handoff docs, handoff docs win.

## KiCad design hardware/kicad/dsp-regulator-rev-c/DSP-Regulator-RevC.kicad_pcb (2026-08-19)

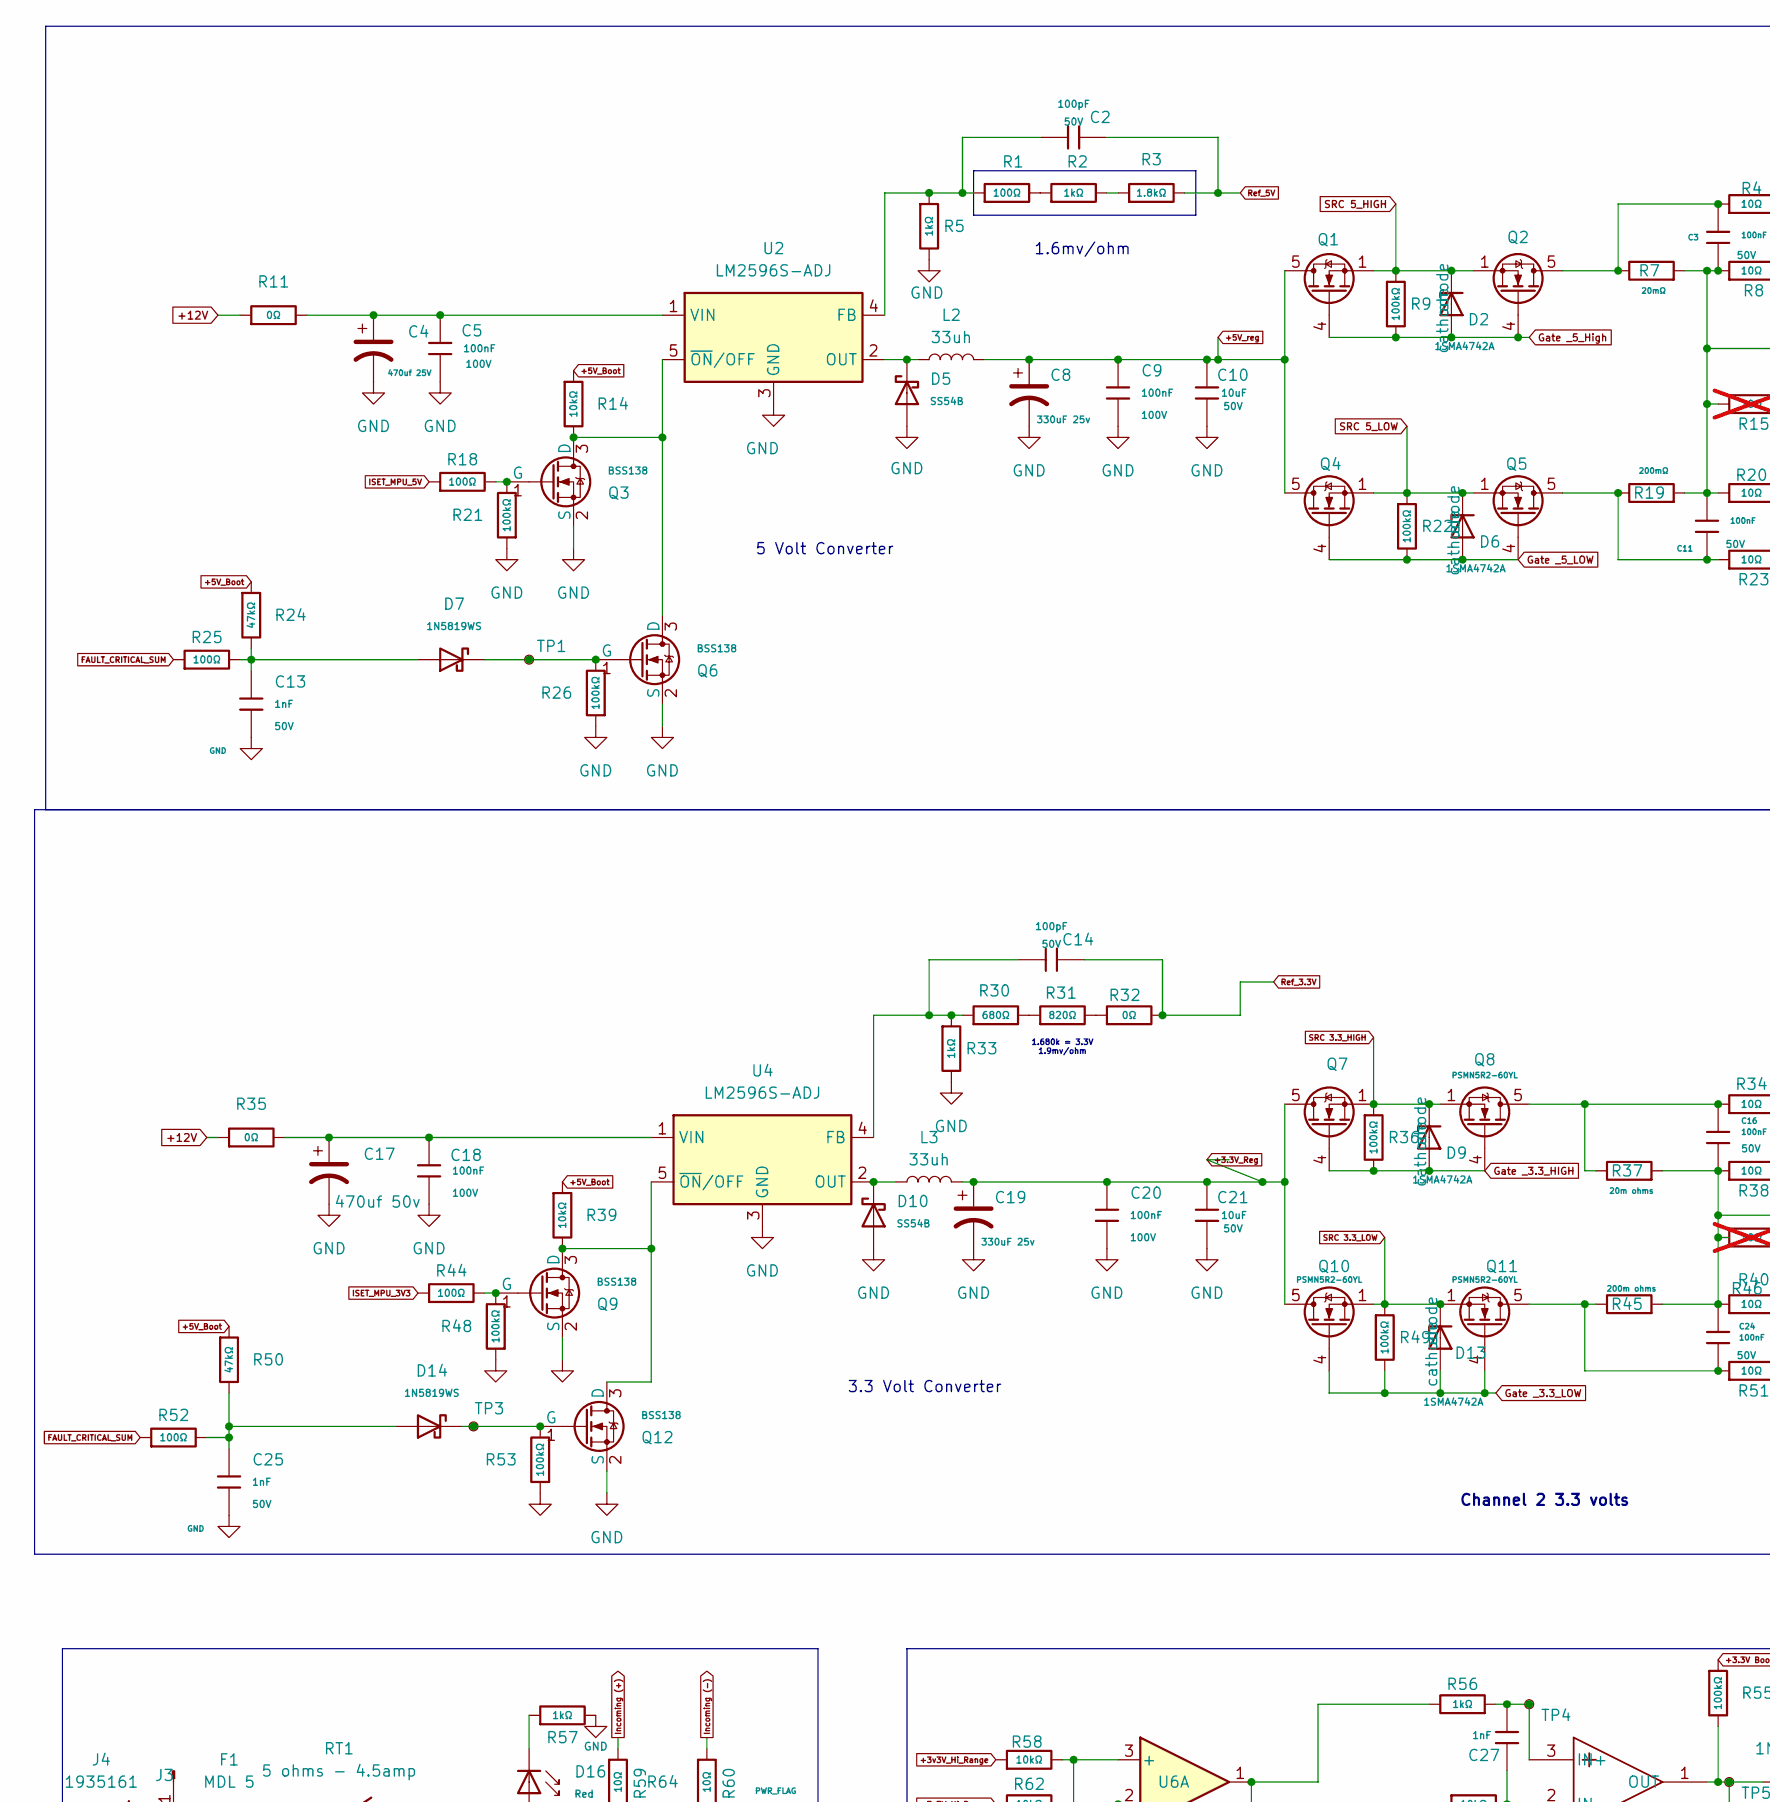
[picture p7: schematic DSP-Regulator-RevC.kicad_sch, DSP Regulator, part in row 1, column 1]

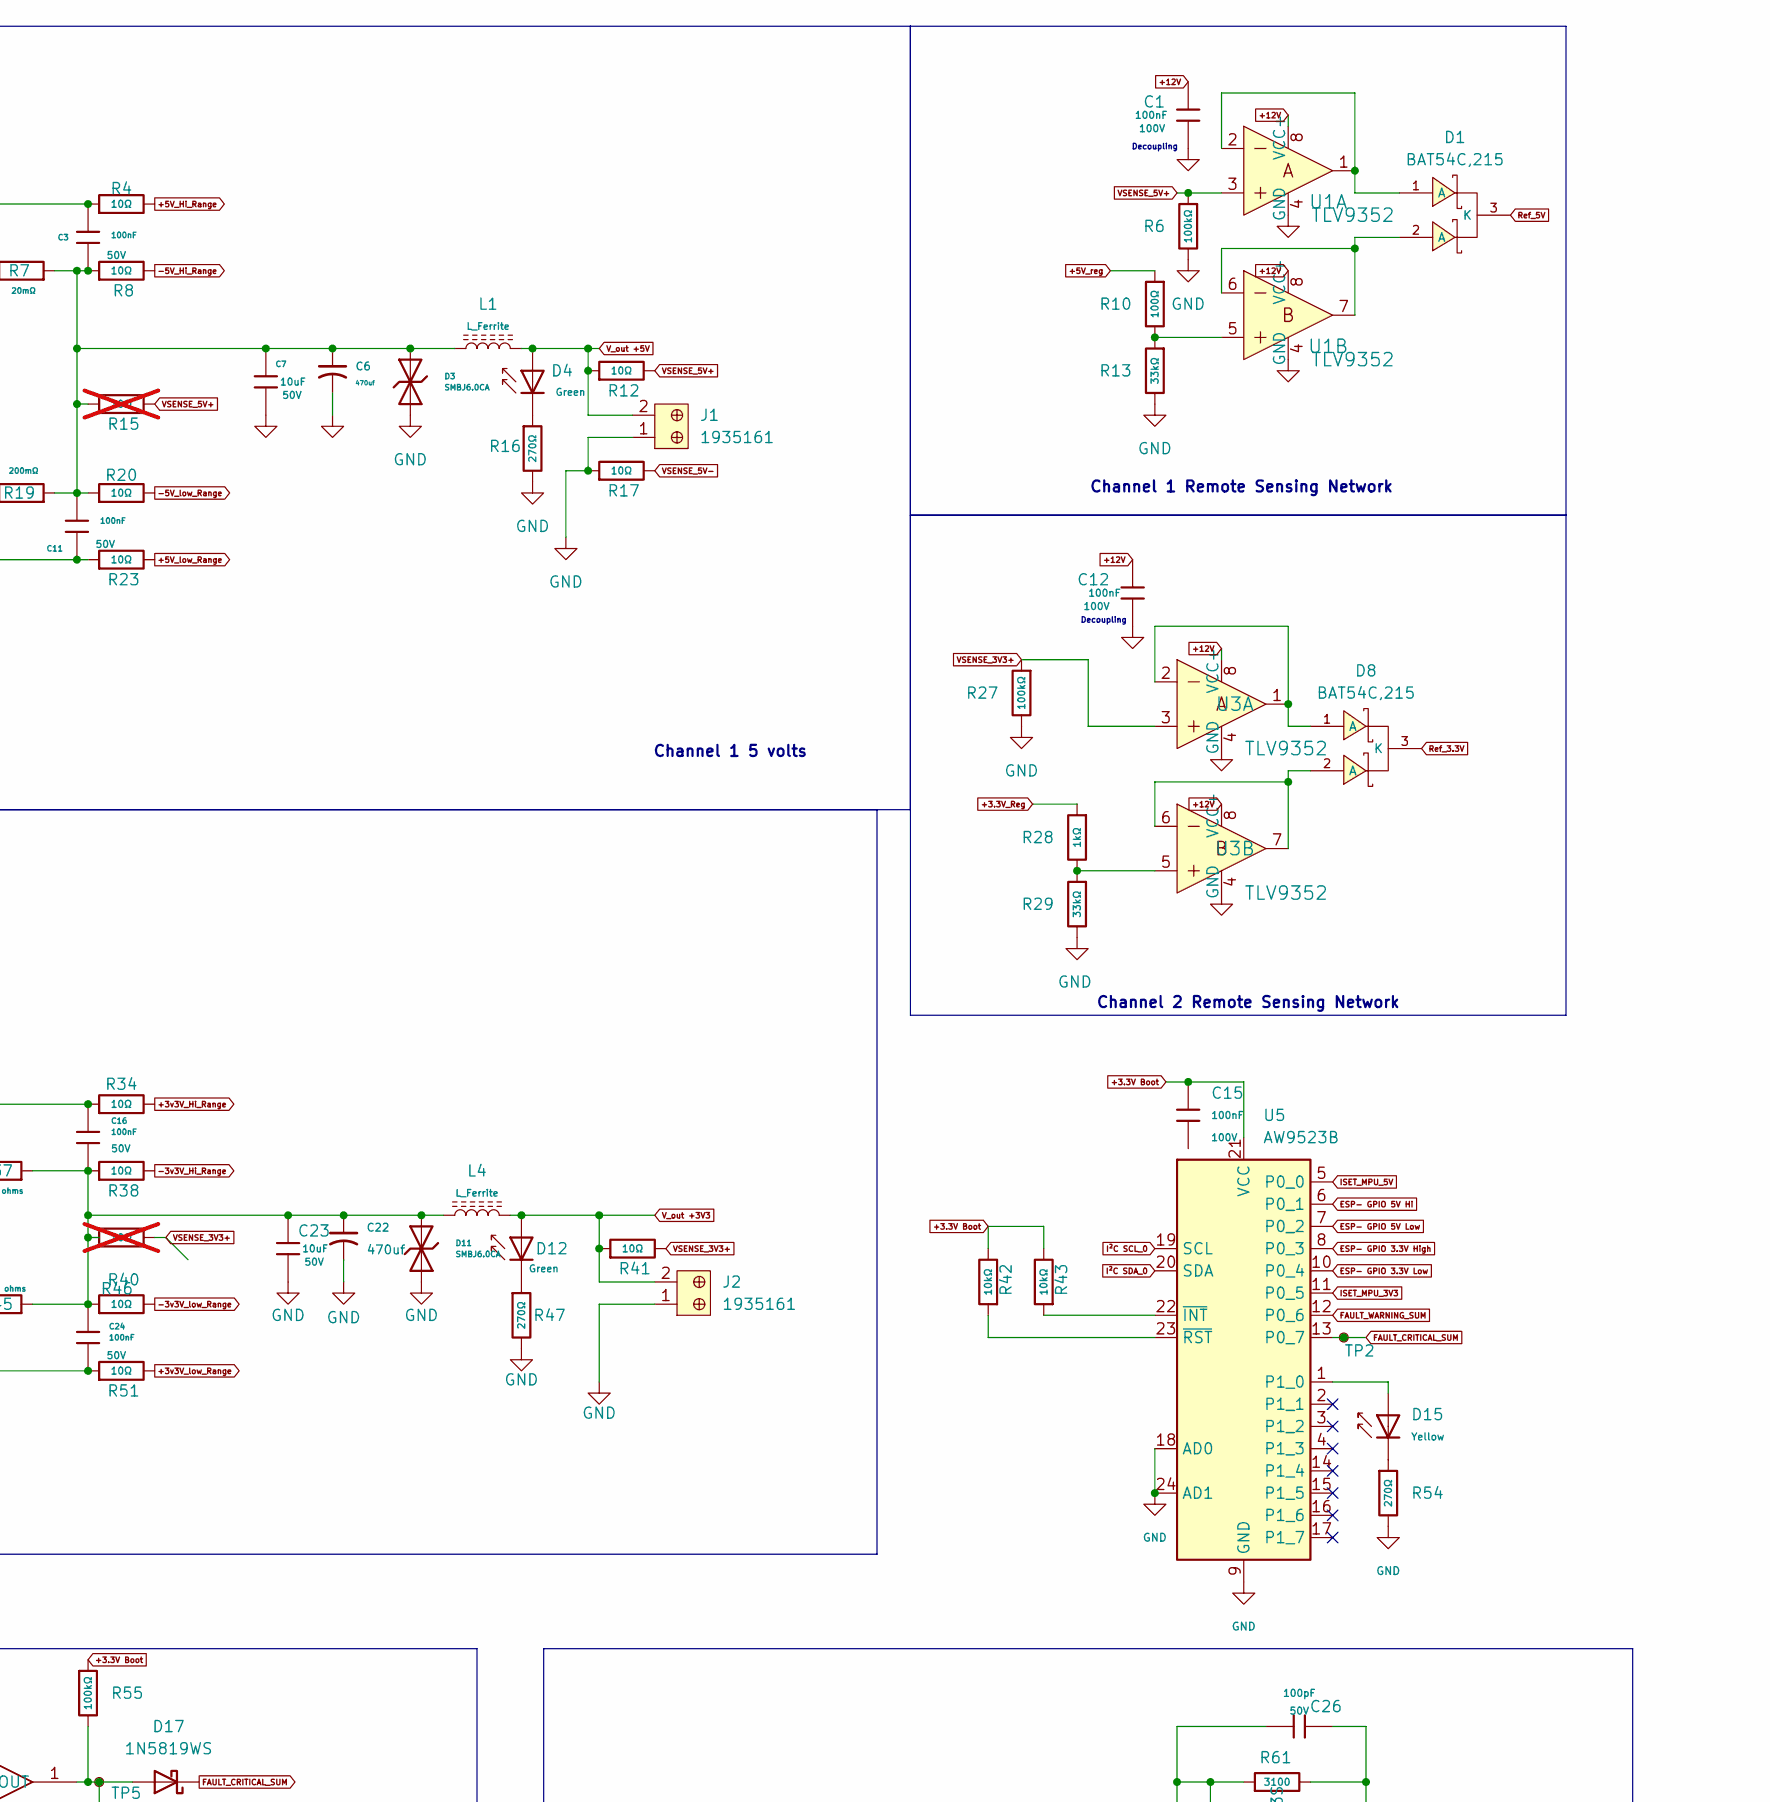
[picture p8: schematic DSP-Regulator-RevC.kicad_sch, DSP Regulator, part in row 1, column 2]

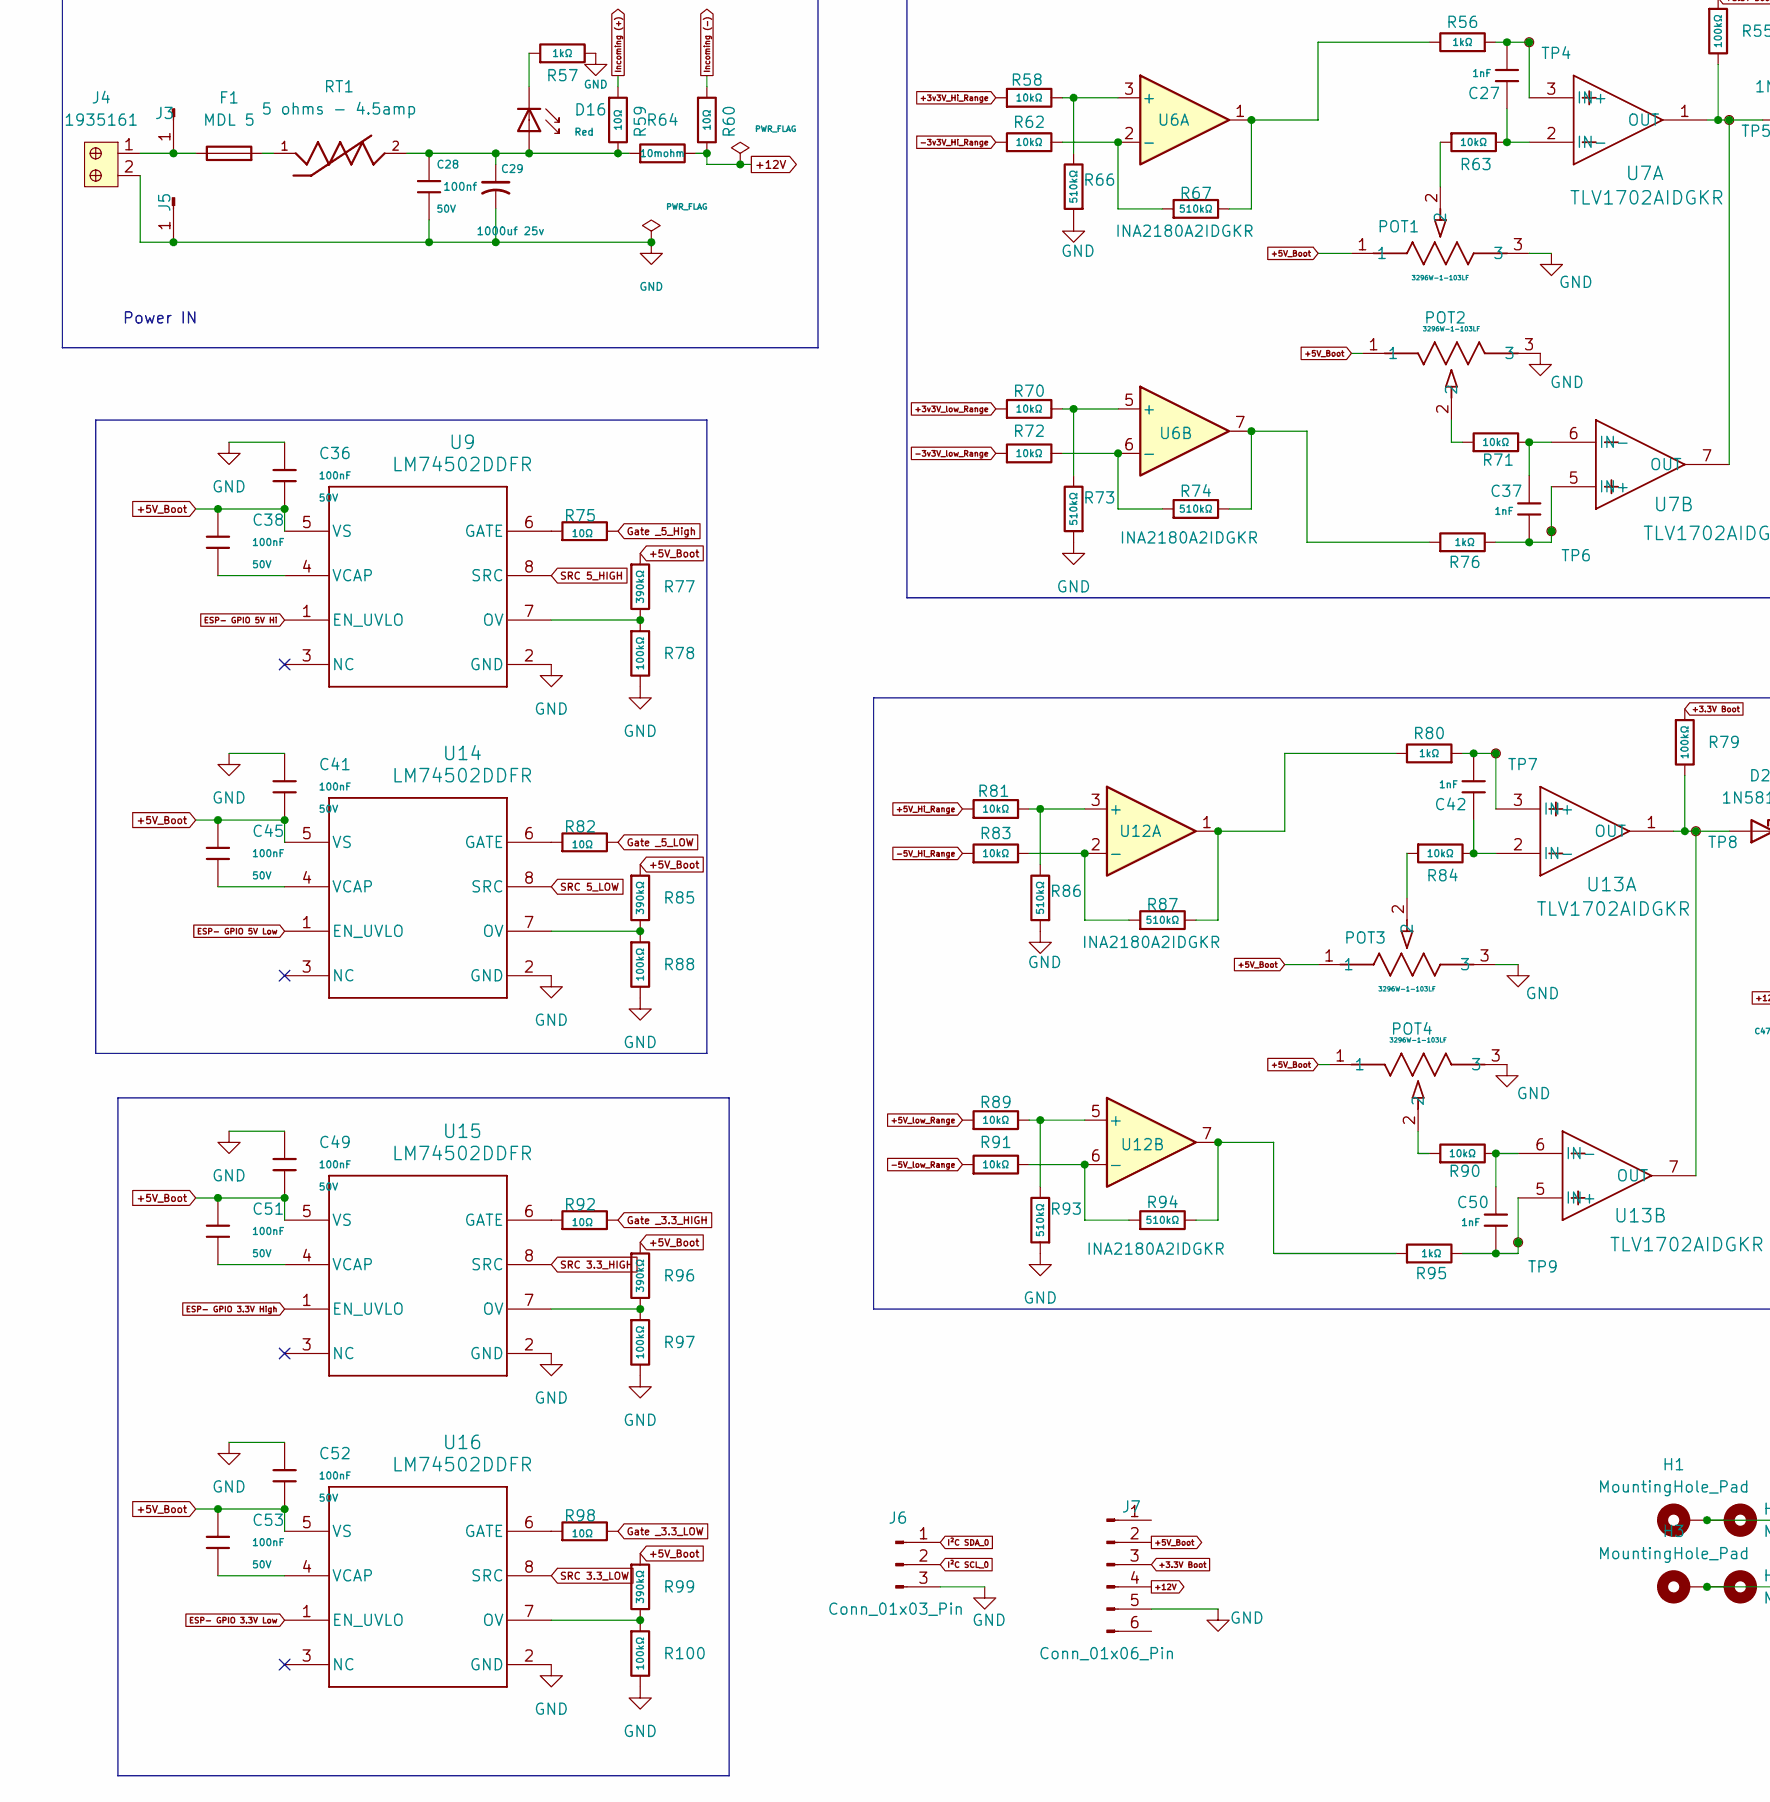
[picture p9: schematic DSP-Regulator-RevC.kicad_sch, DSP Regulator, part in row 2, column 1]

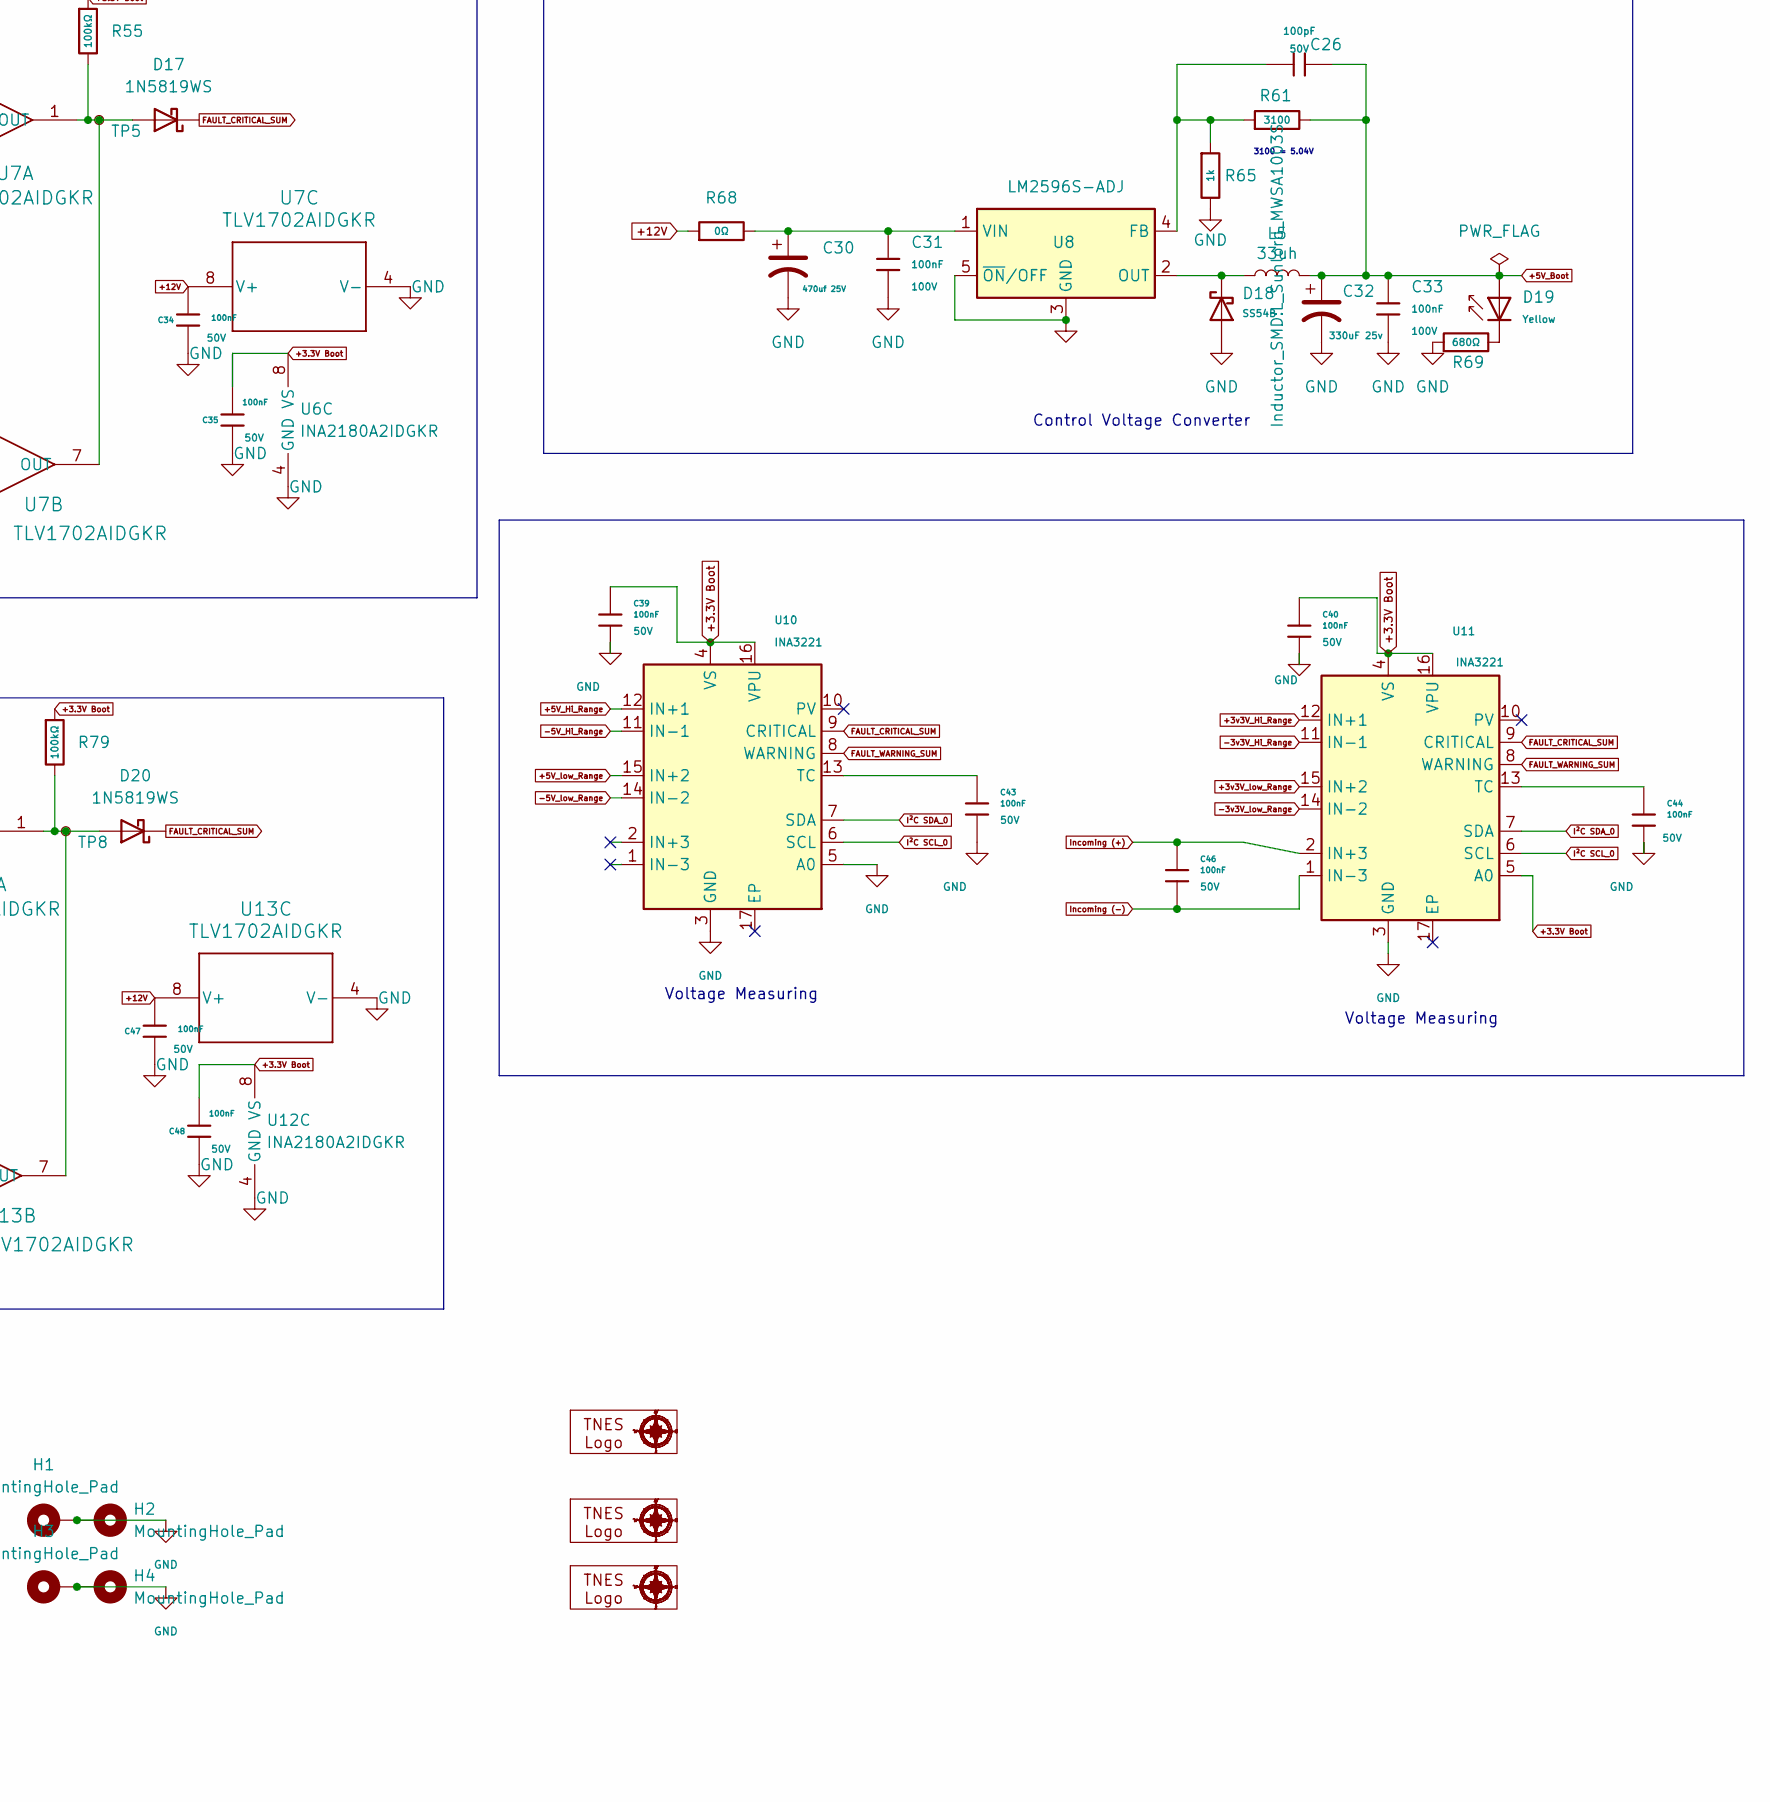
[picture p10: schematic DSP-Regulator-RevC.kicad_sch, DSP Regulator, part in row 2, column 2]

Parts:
5mm1: 5mm LOGO
10mm1, 10mm2: 10mm LOGO
C1, C9, C12, C15, C31, C33: 100nF; C_0805; Voltage Rated 100V; Tolerance ±10%; Part CL21B104KCFNNNE; LCSC C28233
C2, C14: 100pF; C_0805_2012Metric; Voltage Rated 50V; Tolerance ±5%; Part CL21C101JBANNNC; LCSC C1790
C3, C11, C16, C24, C34, C35, C36, C39, C40, C41, C43, C44, C45, C46, C47, C48, C49, C51, C52, C53: 100nF; C_0805; Voltage Rated 50V; Tolerance ±10%; Part CC0805KRX7R9BB104; LCSC C49678
C4, C30: 470uf 25V; CP_Elec_10x10.5; Voltage Class 25; LCSC C48615124
C5, C18, C20: 100nF; C_0805_2012Metric; Voltage Rated 100V; Tolerance ±10%; Part CL21B104KCFNNNE; LCSC C28233
C6, C22: 470uf; CP_Elec_10x10; Part JVE25V470M10X10; LCSC C48615124
C7, C10, C21, C23: 10uF; C_0805; Voltage Rated 50V; Tolerance ±10%; Part GRM21BR61H106KE43L; LCSC C440198
C8, C19, C32: 330uF 25v; CP_Elec_10x10.5; LCSC C72510
C13, C25: 1nF; C_0805_2012Metric; Voltage Rated 50V; Tolerance ±10%; Part CL21B102KBCNNNC; LCSC C46653
C17: 470uf 50v; CP_Elec_10x10.5; Voltage Class 50; LCSC C34642
C26: 100pF; C_0805; Voltage Rated 50V; Tolerance ±5%; Part CL21C101JBANNNC; LCSC C1790
C27, C37, C42, C50: 1nF; C_0805; Voltage Rated 50V; Tolerance ±10%; Part CL21B102KBCNNNC; LCSC C46653
C28: 100nf; C_0805_2012Metric; Voltage Rated 50V; Tolerance ±10%; Part CL21B104KCFNNNE; LCSC C28233
C29: 1000uf 25v; C_Elec_10x10.2; Part EEEFT1E102UP; LCSC C401766
C38: 100nF; C_0805_2012Metric; Voltage Rated 50V; Tolerance ±10%; Part CC0805KRX7R9BB104; LCSC C49678
D1, D8: BAT54C,215; SOT-23-3_L2.9-W1.6-P1.90-LS2.8-BR; Reverse Voltage (Vr) 30V; Forward Voltage (Vf@If) 800mV@100mA; Part BAT54C,215; LCSC C37704
D2, D6, D9, D13: 1SMA4742A; D_DO-214AC(SMA); Part 1SMA4742A; LCSC C19077480
D3, D11: SMBJ6.0CA; D_SMB; Clamping Voltage 10.3V; Voltage - Breakdown 6.67V; PARTREV F2102; LCSC C19077561
D4, D12: Green; D_0805; Part KT-0805G; LCSC C2297
D5, D10, D18: SS54B; D_SMB; Voltage - Forward(Vf@If) 550mV@5.0A; Voltage - DC Reverse(Vr) 40V; Part SS54B; LCSC C18199181
D7, D14: 1N5819WS; D_SOD-323; Forward Voltage (Vf@If) 600mV@1A; Reverse Voltage (Vr) 40V; Part 1N5819WS; LCSC C191023
D15, D19: Yellow; D_0805; Part KT-0805Y; LCSC C2296
D16: Red; D_0805; Forward Voltage (VF) 1.6V~2.6V; Part NCD0805R1; LCSC C84256
D17, D20: 1N5819WS; D_SOD-323; LCSC C191023
F1: MDL 5; Fuseholder_Clip-6.3x32mm_Littelfuse_102_Inline_P34.21x7.62m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
H1, H2, H3, H4: MountingHole_Pad; MountingHole_3.2mm_M3_Pad_Via
J1, J2, J4: 1935161; Terminal_Block_D1.3mm_P5mm; MPN 1935161; Digi-Key_PN 277-1667-ND
J3, J5: Wire con; SolderWire-1sqmm_1x01_D1.4mm_OD2.7mm
J6: Conn_01x03_Pin; PinHeader_1x03_P2.54mm_Vertical_SMD_Pin1Right
J7: Conn_01x06_Pin; PinHeader_1x06_P2.54mm_Vertical_SMD_Pin1Right
L1, L4: L_Ferrite; L_1206_3216Metric; LCSC C85841
L2, L3, L5: 33uh; L_Sunlord_MWSA1003S; LCSC C149598
POT1, POT2, POT3, POT4: 3296W-1-103LF; Potentiometer_Bourns_3296W_Vertical; MPN TC33X-2-103E; Digi-Key_PN TC33X-103ETR-ND
Q1, Q2, Q4, Q5, Q7, Q8, Q10: PSMN5R2-60YL; LFPAK56; Part HL3400; LCSC C22469448
Q3, Q6, Q9, Q12: BSS138; Q_SOT-23; Part BSS138; LCSC C7420339
Q11: PSMN5R2-60YL; LFPAK56; LCSC C22469448
R1, R10, R18, R25, R44, R52: 100Ω; R_0805; Overload Voltage (Max) 150V; Tolerance ±1%; Part 0805W8F1000T5E; LCSC C17408
R2, R5, R28, R33, R56, R57, R76, R80, R95: 1kΩ; R_0805; Overload Voltage (Max) 150V; Tolerance ±1%; Part 0805W8F1001T5E; LCSC C17513
R3: 1.8kΩ; R_0805; Overload Voltage (Max) 150V; Tolerance ±1%; Part 0805W8F1801T5E; LCSC C17398
R4, R8, R12, R17, R20, R23, R34, R38, R41, R46, R51, R59, R60, R75, R82, R92, R98: 10Ω; R_0805; Overload Voltage (Max) 150V; Tolerance ±1%; Part 0805W8F100JT5E; LCSC C17415
R6, R9, R21, R22, R26, R27, R36, R48, R49, R53, R55, R78, R79, R88, R97, R100: 100kΩ; R_0805; Overload Voltage (Max) 150V; Tolerance ±1%; Part 0805W8F1003T5E; LCSC C149504
R7: 20mΩ; R_2512_6332Metric; LCSC C49164694
R11, R35, R68: 0Ω; R_1206; Overload Voltage (Max) 200V; Tolerance ±1%; Part 1206W4F0000T5E; LCSC C17888
R13, R29: 33kΩ; R_0805; Overload Voltage (Max) 150V; Tolerance ±1%; Part 0805W8F3302T5E; LCSC C17633
R14, R39, R42, R43, R58, R62, R63, R70, R71, R72, R81, R83, R84, R89, R90, R91: 10kΩ; R_0805; Overload Voltage (Max) 150V; Tolerance ±1%; Part 0805W8F1002T5E; LCSC C17414
R15, R40: 10Ω; R_0805; Overload Voltage (Max) 150V; Tolerance ±1%; Part 0805W8F100JT5E; LCSC C17415; not fitted
R16, R47, R54: 270Ω; R_0805; Overload Voltage (Max) 150V; Tolerance ±1%; Part 0805W8F2700T5E; LCSC C17590
R19: 200mΩ; R_2512_6332Metric; LCSC C7420022
R24, R50: 47kΩ; R_0805; Overload Voltage (Max) 150V; Tolerance ±1%; Part 0805W8F4702T5E; LCSC C17713
R30, R69: 680Ω; R_0805; Overload Voltage (Max) 150V; Tolerance ±1%; Part 0805W8F6800T5E; LCSC C17798
R31: 820Ω; R_0805; Overload Voltage (Max) 150V; Tolerance ±1%; Part 0805W8F8200T5E; LCSC C17837
R32: 0Ω; R_0805; Overload Voltage (Max) 150V; Tolerance ±1%; Part 0805W8F0000T5E; LCSC C17477
R37: 20m ohms; R_2512_6332Metric; LCSC C49164694
R45: 200m ohms; R_2512_6332Metric; LCSC C7420022
R61: 3100; R_0805; Overload Voltage (Max) 150V; Tolerance ±1%; Part 0805W8F1000T5E; LCSC C17408
R64: 10mohm; R_0805; Overload Voltage (Max) 150V; Tolerance ±1%; Part 0805W8F0000T5E; LCSC C17477
R65: 1k; R_0805; Overload Voltage (Max) 150V; Tolerance ±1%; Part 0805W8F1001T5E; LCSC C17513
R66, R67, R73, R74, R86, R87, R93, R94: 510kΩ; R_0805; Overload Voltage (Max) 150V; Tolerance ±1%; Part 0805W8F5103T5E; LCSC C17733
R77, R85, R96, R99: 390kΩ; R_0805; Overload Voltage (Max) 150V; Tolerance ±1%; Part 0805W8F3903T5E; LCSC C17656
RT1: 5 ohms - 4.5amp; RV_Disc_D7mm_W4.5mm_P5mm; PARTREV 8/1/2022
TP1, TP2, TP3: TestPoint_Small; PinHeader_1x01_P2.54mm_Vertical
TP4, TP5, TP6, TP7, TP8, TP9: TestPoint_Small; PinHeader_1x01_P1.00mm_Vertical
U1, U3: TLV9352; SOIC-8_W3.9mm; MPN LMV358IDR; Digi-Key_PN 296-9571-1-ND
U2, U4, U8: LM2596S-ADJ; TO-263-5_TabPin3
U5: AW9523B; QFN-24-1EP_4x4mm_P0.5mm_EP2.7x2.7mm; LCSC C148077
U6, U12: INA2180A2IDGKR; VSSOP-8_3x3mm_P0.65mm; LCSC C2058508
U7, U13: TLV1702AIDGKR; Texas_S-PDSO-G8_3x3mm_P0.65mm
U9, U14, U15, U16: LM74502DDFR; TSOT-23-8; LCSC C3236215
U10, U11: INA3221; Texas_RGV0016A_VQFN-16-1EP_4x4mm_P0.65mm_EP2.1x2.1mm; LCSC C181255

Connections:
+3.3V Boot: C15.1, C35.1, C39.1, C40.1, C48.1, J7.3, R42.2, R43.2, R55.1, R79.1, U5.21 (VCC), U6.8 (VS), U10.4 (VS), U10.16 (VPU), U11.4 (VS), U11.5 (A0), U11.16 (VPU), U12.8 (VS)
+3.3V_Reg: C19.1, C20.1, C21.1, L3.2, Q7.5 (D), Q10.5 (D), R28.1
+3v3V_Hi_Range: R34.2, R58.1, U11.12 (IN+1)
+3v3V_low_Range: R51.2, R70.1, U11.15 (IN+2)
+5V_Boot: C26.1, C32.1, C33.1, C36.2, C38.1, C41.2, C45.1, C49.2, C51.1, C52.2, C53.1, D19.2, J7.2, L5.2, POT1.1, POT2.1, POT3.1, POT4.1, R14.1, R24.1, R39.1, R50.1, R61.2, R77.1, R85.1, R96.1, R99.1, U9.5 (VS), U14.5 (VS), U15.5 (VS), U16.5 (VS)
+5V_Hi_Range: R4.2, R81.1, U10.12 (IN+1)
+5V_low_Range: R23.2, R89.1, U10.15 (IN+2)
+5V_reg: C8.1, C9.1, C10.1, L2.2, Q1.5 (D), Q4.5 (D), R10.1
+12V: C1.1, C12.1, C34.1, C47.1, J7.4, R11.1, R35.1, R60.2, R64.2, R68.1, U1.8 (VCC+), U3.8 (VCC+), U7.8 (V+), U13.8 (V+)
-3v3V_Hi_Range: R38.2, R62.1, U11.11 (IN-1)
-3v3V_low_Range: R46.2, R72.1, U11.14 (IN-2)
-5V_Hi_Range: R8.2, R83.1, U10.11 (IN-1)
-5V_low_Range: R20.2, R91.1, U10.14 (IN-2)
ESP- GPIO 3.3V High: U5.8 (P0_3), U15.1 (EN_UVLO)
ESP- GPIO 3.3V Low: U5.10 (P0_4), U16.1 (EN_UVLO)
ESP- GPIO 5V Hi: U5.6 (P0_1), U9.1 (EN_UVLO)
ESP- GPIO 5V Low: U5.7 (P0_2), U14.1 (EN_UVLO)
FAULT_CRITICAL_SUM: D17.1 (K), D20.1 (K), R25.1, R52.1, TP2.1 (1_1), U5.13 (P0_7), U10.9 (CRITICAL), U11.9 (CRITICAL)
FAULT_WARNING_SUM: U5.12 (P0_6), U10.8 (WARNING), U11.8 (WARNING)
GND: C1.2, C4.2, C5.2, C6.2, C7.2, C8.2, C9.2, C10.2, C12.2, C13.2, C17.2, C18.2, C19.2, C20.2, C21.2, C22.2, C23.2, C25.2, C28.2, C29.2, C30.2, C31.2, C32.2, C33.2, C34.2, C35.2, C36.1, C39.2, C40.2, C41.1, C43.2, C44.2, C47.2, C48.2, C49.1, C52.1, D3.1, D5.2, D10.2, D11.1, D18.2, H1.1 (1_1), H2.1 (1_1), H3.1 (1_1), H4.1 (1_1), J1.1, J2.1, J4.2, J5.1 (Pin_1_1), J6.3, J7.5, POT1.3, POT2.3, POT3.3, POT4.3, Q3.2 (S), Q6.2 (S), Q9.2 (S), Q12.2 (S), R5.2, R6.2, R13.2, R16.2, R17.1, R21.1, R26.1, R27.2, R29.2, R33.2, R47.2, R48.1, R53.1, R54.2, R57.2, R65.2, R66.1, R69.1, R73.1, R78.2, R86.1, R88.2, R93.1, R97.2, R100.2, U1.4 (GND), U2.3 (GND), U3.4 (GND), U4.3 (GND), U5.9 (GND), U5.18 (AD0), U5.24 (AD1), U5.25 (GND), U6.4 (GND), U7.4 (V-), U8.3 (GND), U8.5 (~ON/OFF), U9.2 (GND), U10.3 (GND), U10.5 (A0), U11.3 (GND), U12.4 (GND), U13.4 (V-), U14.2 (GND), U15.2 (GND), U16.2 (GND)
Gate _3.3_HIGH: D9.2 (cathode), Q7.4 (G), Q8.4 (G), R36.2, R92.2
Gate _3.3_LOW: D13.2 (cathode), Q10.4 (G), Q11.4 (G), R49.2, R98.2
Gate _5_High: D2.2 (cathode), Q1.4 (G), Q2.4 (G), R9.2, R75.2
Gate _5_LOW: D6.2 (cathode), Q4.4 (G), Q5.4 (G), R22.2, R82.2
ISET_MPU_3V3: R44.1, U5.11 (P0_5)
ISET_MPU_5V: R18.1, U5.5 (P0_0)
Incoming (+): C46.1, R59.1, U11.2 (IN+3)
Incoming (-): C46.2, R60.1, U11.1 (IN-3)
I²C SCL_0: J6.2, U5.19 (SCL), U10.6 (SCL), U11.6 (SCL)
I²C SDA_0: J6.1, U5.20 (SDA), U10.7 (SDA), U11.7 (SDA)
unnamed: C3.2, C6.1, C7.1, C11.1, D3.2, L1.1, R7.2, R8.1, R15.1, R19.2, R20.1
unnamed: C13.1, D7.2, R24.2, R25.2
unnamed: C16.2, C22.1, C23.1, C24.1, D11.2, L4.1, R37.2, R38.1, R40.1, R45.2, R46.1
unnamed: C25.1, D14.2, R50.2, R52.2
unnamed: C28.1, C29.1, D16.2, R59.2, R64.1, RT1.2
unnamed: D1.1 (A), U1.1, U1.2
unnamed: D1.2 (A), U1.6, U1.7
unnamed: D4.1, R16.1
unnamed: D8.1 (A), U3.1, U3.2
unnamed: D8.2 (A), U3.6, U3.7
unnamed: D12.1, R47.1
unnamed: D15.1, R54.1
unnamed: D16.1, R57.1
unnamed: D17.2 (A), R55.2, TP5.1 (1_1), U7.1 (OUT), U7.7 (OUT)
unnamed: D19.1, R69.2
unnamed: D20.2 (A), R79.2, TP8.1 (1_1), U13.1 (OUT), U13.7 (OUT)
unnamed: F1.2, RT1.1
unnamed: F1.1, J3.1 (Pin_1_1), J4.1
unnamed: POT1.2, R63.1
unnamed: POT2.2, R71.1
unnamed: POT3.2, R84.1
unnamed: POT4.2, R90.1
unnamed: C3.1, Q2.5 (D), R4.1, R7.1
unnamed: Q3.3 (D), Q6.3 (D), R14.2, U2.5 (~ON/OFF)
unnamed: Q3.1 (G), R18.2, R21.2
unnamed: C11.2, Q5.5 (D), R19.1, R23.1
unnamed: D7.1, Q6.1 (G), R26.2, TP1.1 (1_1)
unnamed: C16.1, Q8.5 (D), R34.1, R37.1
unnamed: Q9.1 (G), R44.2, R48.2
unnamed: C24.2, Q11.5 (D), R45.1, R51.1
unnamed: Q9.3 (D), Q12.3 (D), R39.2, U4.5 (~ON/OFF)
unnamed: D14.1, Q12.1 (G), R53.2, TP3.1 (1_1)
unnamed: R1.2, R2.1
unnamed: R2.2, R3.1
unnamed: R10.2, R13.1, U1.5
unnamed: R28.2, R29.1, U3.5
unnamed: R30.2, R31.1
unnamed: R31.2, R32.1
unnamed: R56.2, R67.2, U6.1
unnamed: R74.2, R76.1, U6.7
unnamed: R80.2, R87.2, U12.1
unnamed: R94.2, R95.1, U12.7
unnamed: C2.2, R1.1, R5.1, U2.4 (FB)
unnamed: D5.1, L2.1, U2.2 (OUT)
unnamed: C4.1, C5.1, R11.2, U2.1 (VIN)
unnamed: C14.2, R30.1, R33.1, U4.4 (FB)
unnamed: D10.1, L3.1, U4.2 (OUT)
unnamed: C17.1, C18.1, R35.2, U4.1 (VIN)
unnamed: D15.2, U5.1 (P1_0)
unnamed: R43.1, U5.22 (~INT)
unnamed: R42.1, U5.23 (~RST)
unnamed: R58.2, R66.2, U6.3 (+)
unnamed: R62.2, R67.1, U6.2 (-)
unnamed: R70.2, R73.2, U6.5 (+)
unnamed: R72.2, R74.1, U6.6 (-)
unnamed: C27.2, R56.1, TP4.1 (1_1), U7.3 (IN+)
unnamed: C27.1, R63.2, U7.2 (IN-)
unnamed: C37.2, R76.2, TP6.1 (1_1), U7.5 (IN+)
unnamed: C37.1, R71.2, U7.6 (IN-)
unnamed: C26.2, R61.1, R65.1, U8.4 (FB)
unnamed: D18.1, L5.1, U8.2 (OUT)
unnamed: C30.1, C31.1, R68.2, U8.1 (VIN)
unnamed: R75.1, U9.6 (GATE)
unnamed: R77.2, R78.1, U9.7 (OV)
unnamed: C38.2, U9.4 (VCAP)
unnamed: C43.1, U10.13 (TC)
unnamed: C44.1, U11.13 (TC)
unnamed: R81.2, R86.2, U12.3 (+)
unnamed: R83.2, R87.1, U12.2 (-)
unnamed: R89.2, R93.2, U12.5 (+)
unnamed: R91.2, R94.1, U12.6 (-)
unnamed: C42.2, R80.1, TP7.1 (1_1), U13.3 (IN+)
unnamed: C42.1, R84.2, U13.2 (IN-)
unnamed: C50.2, R95.2, TP9.1 (1_1), U13.5 (IN+)
unnamed: C50.1, R90.2, U13.6 (IN-)
unnamed: R82.1, U14.6 (GATE)
unnamed: R85.2, R88.1, U14.7 (OV)
unnamed: C45.2, U14.4 (VCAP)
unnamed: R92.1, U15.6 (GATE)
unnamed: R96.2, R97.1, U15.7 (OV)
unnamed: C51.2, U15.4 (VCAP)
unnamed: R98.1, U16.6 (GATE)
unnamed: R99.2, R100.1, U16.7 (OV)
unnamed: C53.2, U16.4 (VCAP)
Ref_3.3V: C14.1, D8.3 (K), R32.2
Ref_5V: C2.1, D1.3 (K), R3.2
SRC 3.3_HIGH: D9.1 (anode), Q7.1 (S), Q7.2 (S), Q7.3 (S), Q8.1 (S), Q8.2 (S), Q8.3 (S), R36.1, U15.8 (SRC)
SRC 3.3_LOW: D13.1 (anode), Q10.1 (S), Q10.2 (S), Q10.3 (S), Q11.1 (S), Q11.2 (S), Q11.3 (S), R49.1, U16.8 (SRC)
SRC 5_HIGH: D2.1 (anode), Q1.1 (S), Q1.2 (S), Q1.3 (S), Q2.1 (S), Q2.2 (S), Q2.3 (S), R9.1, U9.8 (SRC)
SRC 5_LOW: D6.1 (anode), Q4.1 (S), Q4.2 (S), Q4.3 (S), Q5.1 (S), Q5.2 (S), Q5.3 (S), R22.1, U14.8 (SRC)
VSENSE_3V3+: R27.1, R40.2, R41.2, U3.3
VSENSE_5V+: R6.1, R12.2, R15.2, U1.3
VSENSE_5V-: R17.2
V_out +3V3: D12.2, J2.2, L4.2, R41.1
V_out +5V: D4.2, J1.2, L1.2, R12.1

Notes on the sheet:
Voltage Measuring
3100 = 5.04V
Power IN
Control Voltage Converter
Channel 2 Remote Sensing Network
3.3 Volt Converter
Channel 2 3.3 volts
5 Volt Converter
1.6mv/ohm
Decoupling
1.680k = 3.3V 1.9mv/ohm
Channel 1 5 volts
Channel 1 Remote Sensing Network

Board: 2 copper layers, 235 parts (0 on the bottom side), 124 nets, no tracks yet.

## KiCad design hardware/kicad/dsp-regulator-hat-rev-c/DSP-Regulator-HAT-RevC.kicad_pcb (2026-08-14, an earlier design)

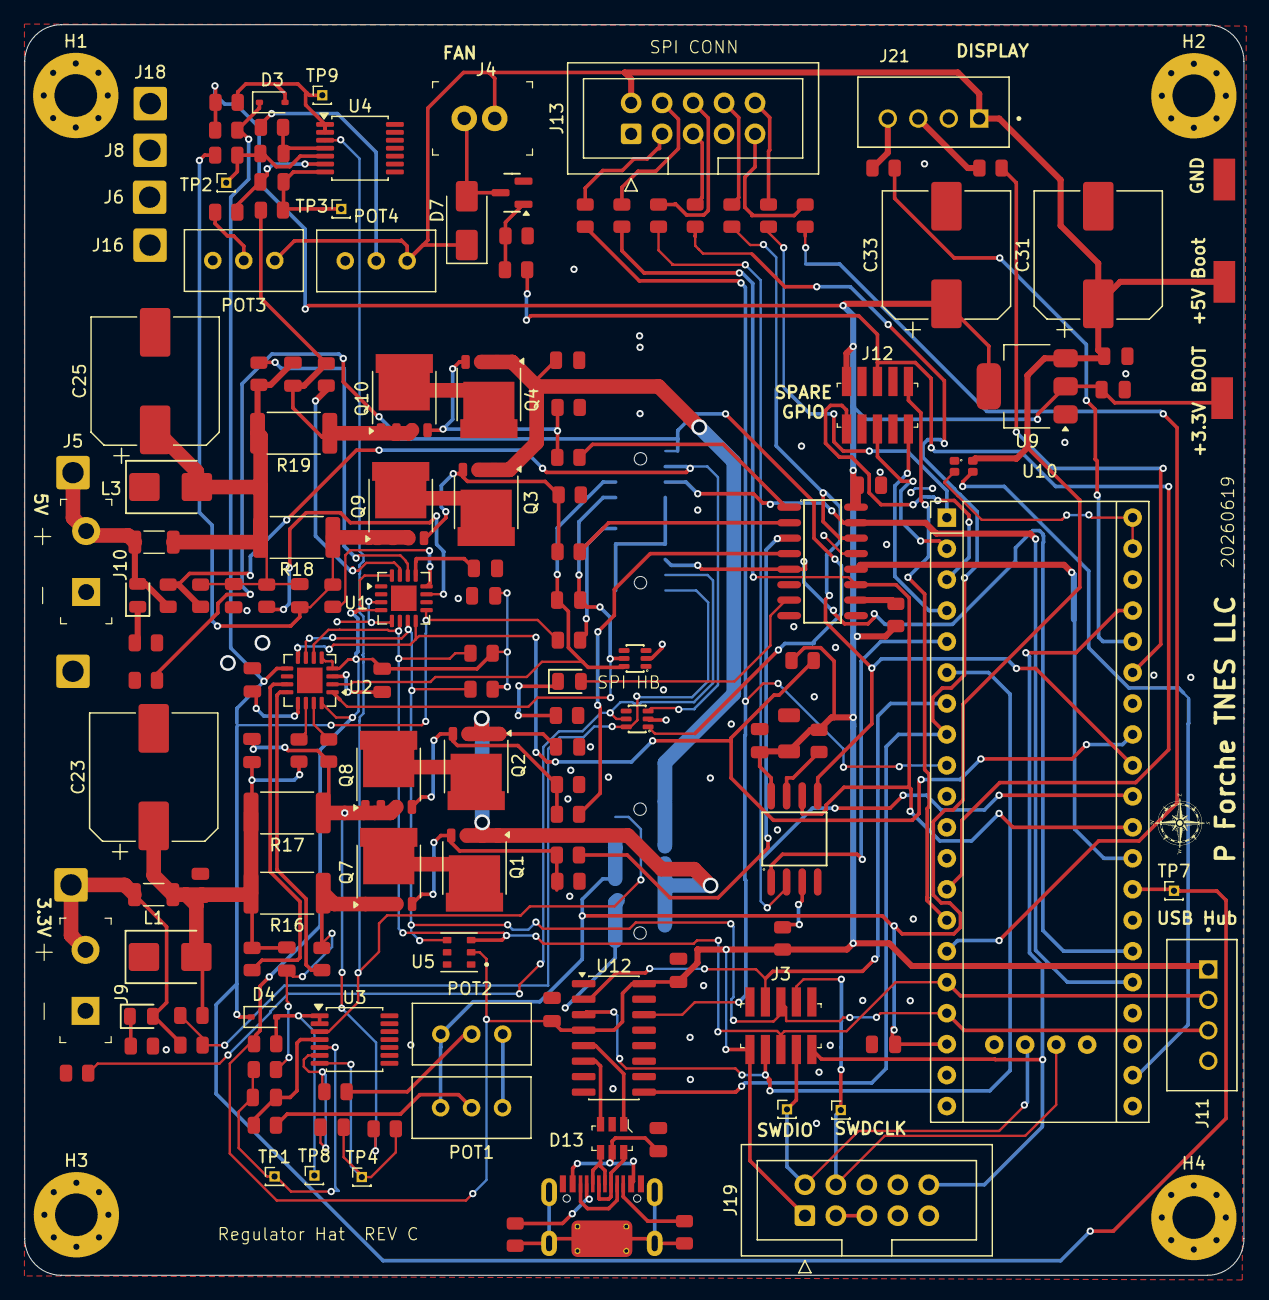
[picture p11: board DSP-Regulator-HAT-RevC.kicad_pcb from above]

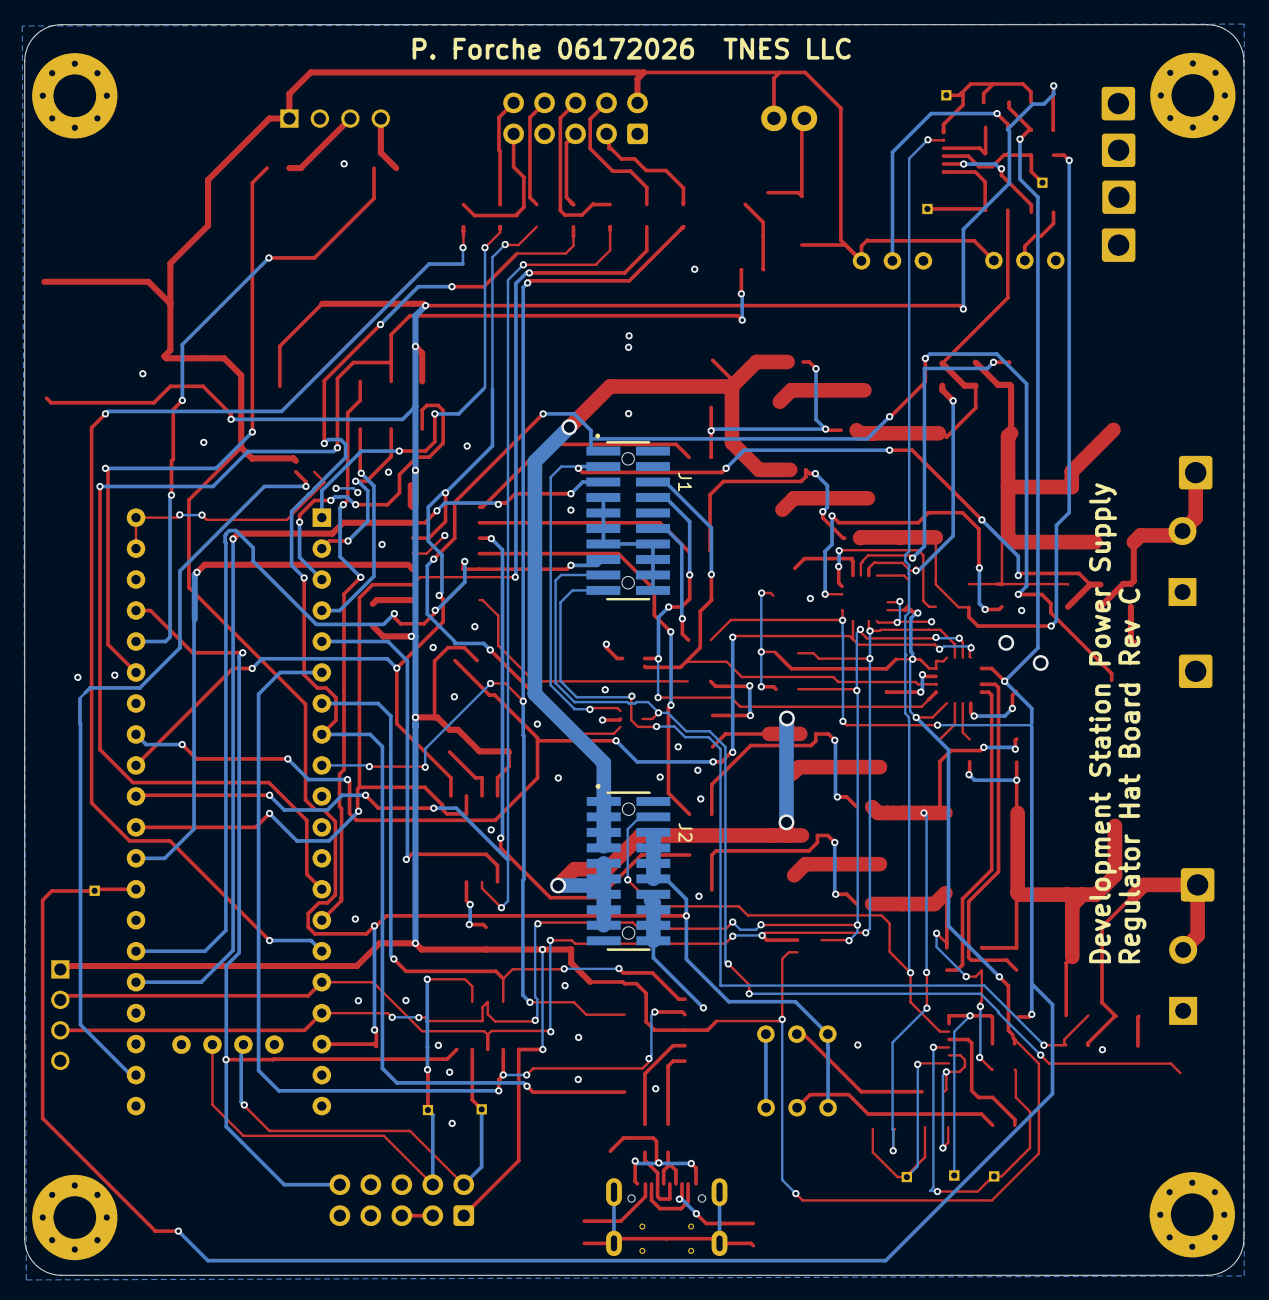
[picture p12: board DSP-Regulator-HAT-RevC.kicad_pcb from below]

Board: 2 copper layers, 100.0 x 102.6 mm, 163 parts (2 on the bottom side), 111 nets.

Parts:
5mm1: 5mm LOGO
C1, C2, C20, C21: 10uF; C_0805
C3, C5, C6, C7, C8, C9, C12, C13, C26, C29, C32, C34, C36, C37, C38, C39, C40: 100nF; C_0805
C14, C15, C16, C17: 1nF; C_0805
C23, C25: 470uf; CP_Elec_10x10
C31, C33: C_Small_US; CP_Elec_10x10
C35: 100uF; C_1206
D1, D2: SMF05CT1G; SOT-363_L2.0-W1.3-P0.65-LS2.1-BR
D3, D4: 1N5819WS; D_SOD-323
D5, D8: SMBJ6.0CA; D_SMB
D6: Yellow; D_0805
D7: US1M; D_SMA
D9, D11: Green; D_0805
D12: WS2812B; LED-SMD_4P-L1.6-W1.5_XL-1615RGBC-WS2812B
D13: USBLC6-2SC6; SOT23-6L
H1, H2, H3, H4: MountingHole_Pad; MountingHole_3.5mm_Pad_Via
J1, J2: FW-10-05-X-D-XXX-XXX-A; SAMTEC_FW-10-05-X-D-XXX-XXX-A
J3, J12: 20021121-00010C4LF; PinHeader_2x5_P1.27mm
J4: Fan Control; PinHeader_1x2_P2.5mm_Drill1.1mm
J5, J6, J7, J8, J16, J17, J18: Conn_01x01_Pin; SolderWire-1sqmm_1x01_D1.4mm_OD2.7mm
J9, J10: 1935161; Terminal_Block_D1.3mm_P5mm
J11: USB Hub I2C; JST_B4B-XH-A
J13, J19: SWD_Debug_Header; IDC-Header_2x05_P2.54mm_Vertical
J20: Connector, USB-TYPE-C-16P; TYPE-C-SMD_HX-TYPE-C-16PIN
J21: Display Uart; JST_B4B-XH-A
L1, L3: L_Ferrite; L_1206_3216Metric
POT1, POT2, POT3, POT4: 3296W-1-103LF; Potentiometer_Bourns_3296W_Vertical
Q1, Q2, Q3, Q4, Q7, Q8, Q9, Q10: PSMN5R2-60YL; LFPAK56
Q5: AO3400A; Q_SOT-23
R1, R2, R3, R4, R10, R51, R53: 100kΩ; R_0805
R5, R55, R57: 270Ω; R_0805
R7, R8, R9, R11, R12: 100Ω; R_0805
R16: 20m ohms; R_2512_6332Metric
R17: 200m ohms; R_2512_6332Metric
R18: 20mΩ; R_2512_6332Metric
R19: 200mΩ; R_2512_6332Metric
R22, R23, R24, R25, R26, R27, R28, R29, R58, R60, R61, R62, R65, R66: 10Ω; R_0805
R36, R38, R41, R43: 1kΩ; R_0805
R37, R39, R40, R42, R70, R72, R74, R84, R85: 10kΩ; R_0805
R48: 56Ω; R_0805
R73, R77, R78, R79, R80, R81, R82, R83, R86: 33Ω; R_0805
R75, R76: 4.7kΩ; R_0805
R87, R88: 5.1kΩ; R_0805
TP1, TP2, TP3, TP4, TP7, TP8, TP9, TP13, TP14: TestPoint_Small; PinHeader_1x01_P1.00mm_Vertical
TP2_+5V1, TP11: 5015; KEYSTONE_5015
TP_+3.3V1: 5015; KEYSTONE_5015
U1, U2: INA3221; Texas_RGV0016A_VQFN-16-1EP_4x4mm_P0.65mm_EP2.1x2.1mm
U3, U4: TLV1704AIPWR; TSSOP-14_4.4x5mm_P0.65mm
U5: AHT20_C2757850; Humidity sensor
U7: 74HC595D; SOIC-16_L9.9-W3.9-P1.27-LS6.0-BL
U9: AMS1117-3.3; SOT-223-3_TabPin2
U10: STM32_BLUE -; STM32 Blue
U11: W25Q128; SOIC-8_L5.3-W5.3-P1.27-LS8.0-BL
U12: CH340C; SOIC-16_3.9x9.9mm_P1.27mm

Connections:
+3.3V Boot: C3.1, C13.1, C29.2, C33.1, C34.1, C35.1, C36.1, C38.2, C39.2, J3.1, J11.1, J12.2, J19.1, R51.1, R53.1, R70.2, R72.1, R74.1, R75.2, R76.2, R84.2, R85.2, TP_+3.3V1.1, U1.4 (VS), U1.16 (VPU), U2.4 (VS), U2.5 (A0), U2.16 (VPU), U5.2 (VDD), U7.16 (VCC), U9.2 (VO), U11.8 (VCC), U12.4 (V3), U12.16 (VCC)
+3.3V_Reg: C1.1, J2.09, J2.11, J2.13, J2.15, J2.17, Q1.1 (S), Q1.2 (S), Q1.3 (S), Q2.1 (S), Q2.2 (S), Q2.3 (S)
+3v3V_Hi_Range: R22.2, U2.12 (IN+1)
+3v3V_low_Range: R25.2, U2.15 (IN+2)
+5V_Boot: C31.1, C32.1, C37.1, D7.1 (K), D12.2 (VDD), J2.06, J2.08, J2.10, J2.12, J4.2, J13.2, J21.1, POT1.1, POT2.1, POT3.1, POT4.1, TP2_+5V1.1, U9.3 (VI), U10.18 (5V)
+5V_Hi_Range: R26.2, U1.12 (IN+1)
+5V_low_Range: R29.2, U1.15 (IN+2)
+5V_reg: C2.1, J2.01, J2.03, J2.05, J2.07, Q3.1 (S), Q3.2 (S), Q3.3 (S), Q4.1 (S), Q4.2 (S), Q4.3 (S)
+12V: J2.04, U3.3 (V+), U4.3 (V+)
-3v3V_Hi_Range: R23.2, U2.11 (IN-1)
-3v3V_low_Range: R24.2, U2.14 (IN-2)
-5V_Hi_Range: R27.2, U1.11 (IN-1)
-5V_low_Range: R28.2, U1.14 (IN-2)
B13: J12.5, U10.2 (B13)
B14: J12.1, U10.3 (B14)
B15: J12.9, U10.4 (B15)
CTS: R77.1, U10.8 (A11), U12.9 (~CTS)
DISP_UART_RX: R79.1, U10.36 (B11)
DISP_UART_TX: R78.1, U10.35 (B10)
ESP- GPIO 3.3V High: R7.2, U7.3 (Q3)
ESP- GPIO 3.3V Low: R8.2, U7.4 (Q4)
ESP- GPIO 5V Hi: R12.2, U7.1 (Q1)
ESP- GPIO 5V Low: R11.2, U7.2 (Q2)
FAULT_CRITICAL_SUM: D3.1 (K), D4.1 (K), R48.1, R72.2, TP7.1, U1.9 (CRITICAL), U2.9 (CRITICAL), U10.28 (A3)
FAULT_WARNING_SUM: R74.2, U1.8 (WARNING), U2.8 (WARNING), U10.33 (B0)
GND: C1.2, C2.2, C3.2, C5.2, C13.2, C20.2, C21.2, C23.2, C25.2, C26.2, C29.1, C31.2, C32.2, C33.2, C34.2, C35.2, C36.2, C37.2, C38.1, C39.1, C40.2, D1.2, D2.2, D5.1, D8.1, D12.3 (GND), D13.2, H1.1, H2.1, H3.1, H4.1, J1.07, J1.09, J1.11, J1.13, J1.14, J1.16, J1.18, J1.20, J2.02, J2.14, J2.16, J2.18, J2.19, J2.20, J3.2, J3.10, J6.1, J8.1, J9.1, J10.1, J11.4, J12.4, J13.1, J13.7, J16.1, J17.1, J18.1, J19.3, J19.5, J19.9, J20.A12B1 (GND), J20.B12A1 (GND), J20.S1 (SHIELD), J21.2, POT1.3, POT2.3, POT3.3, POT4.3, Q5.2 (S), R1.2, R2.2, R3.2, R4.2, R5.2, R10.2, R55.2, R57.2, R61.1, R66.1, R87.2, R88.2, TP11.1, U1.3 (GND), U1.5 (A0), U2.3 (GND), U3.8 (-IN3), U3.9 (+IN3), U3.10 (-IN4), U3.11 (+IN4), U3.12 (V-), U4.8 (-IN3), U4.9 (+IN3), U4.10 (-IN4), U4.11 (+IN4), U4.12 (V-), U5.5 (GND), U7.8 (GND), U7.13 (OE#), U9.1 (GND), U10.19 (G), U10.39 (GND), U10.40 (GND), U10.44 (GND), U11.4 (GND), U12.1 (GND)
ISET_MPU_3V3: J1.15, U7.5 (Q5), U10.26 (A1)
ISET_MPU_5V: J1.05, U7.15 (Q0), U10.25 (A0)
Incoming (+): C12.1, D2.6, J1.06, U2.2 (IN+3)
Incoming (-): C12.2, D2.5, J1.08, U2.1 (IN-3)
I²C SCL_0: J3.5, J11.2, R75.1, U1.6 (SCL), U2.6 (SCL), U5.3 (SCL), U10.16 (B8)
I²C SDA_0: J3.6, J11.3, R76.1, U1.7 (SDA), U2.7 (SDA), U5.4 (SDA), U10.17 (B9)
Memory_CS: U10.5 (A8), U11.1 (CS#)
NRST: J3.9, J19.10, U10.37 (R)
unnamed: C6.2, Q10.1 (S), Q10.2 (S), Q10.3 (S), R19.1, R29.1, R43.1
unnamed: C7.1, Q7.1 (S), Q7.2 (S), Q7.3 (S), R16.1, R22.1, R36.2
unnamed: C8.2, Q8.1 (S), Q8.2 (S), Q8.3 (S), R17.1, R25.1, R41.1
unnamed: C9.1, Q9.1 (S), Q9.2 (S), Q9.3 (S), R18.1, R26.1, R38.2
unnamed: C7.2, C8.1, C20.1, C23.1, D5.2, L1.1, R16.2, R17.2, R23.1, R24.1, R58.1
unnamed: D3.2 (A), R51.2, TP9.1, U4.1 (OUT2), U4.2 (OUT1)
unnamed: D4.2 (A), R53.2, TP8.1, U3.1 (OUT2), U3.2 (OUT1)
unnamed: D6.1, R5.1
unnamed: D7.2 (A), J4.1, Q5.3 (D)
unnamed: D9.1, R55.1
unnamed: D11.1, R57.1
unnamed: D13.4, J20.A7 (D-), J20.B7 (D-)
unnamed: D13.6, J20.A6 (D+), J20.B6 (D+)
unnamed: J1.12, R48.2
unnamed: J13.3, R73.2
unnamed: J13.4, R80.1
unnamed: J13.5, R77.2
unnamed: J13.6, R81.1
unnamed: J13.8, R82.1
unnamed: J13.9, R86.2
unnamed: J13.10, R83.1
unnamed: J20.A5 (CC1), R88.1
unnamed: J20.B5 (CC2), R87.1
unnamed: J20.A8 (SBU1), J20.B8 (SBU2)
unnamed: J21.3, R78.2
unnamed: J21.4, R79.2
unnamed: POT1.2, R37.1
unnamed: POT2.2, R40.1
unnamed: POT3.2, R42.1
unnamed: POT4.2, R39.1
unnamed: Q1.5 (D), Q7.5 (D)
unnamed: Q1.4 (G), Q7.4 (G), R1.1, R7.1
unnamed: Q2.5 (D), Q8.5 (D)
unnamed: Q2.4 (G), Q8.4 (G), R2.1, R8.1
unnamed: Q3.5 (D), Q9.5 (D)
unnamed: Q3.4 (G), Q9.4 (G), R3.1, R11.1
unnamed: Q5.1 (G), R9.2, R10.1
unnamed: Q4.5 (D), Q10.5 (D)
unnamed: Q4.4 (G), Q10.4 (G), R4.1, R12.1
unnamed: C5.1, U1.13 (TC)
unnamed: C26.1, U2.13 (TC)
unnamed: C14.2, R36.1, TP1.1, U3.5 (+IN1)
unnamed: C14.1, R37.2, U3.4 (-IN1)
unnamed: C16.2, R41.2, TP4.1, U3.7 (+IN2)
unnamed: C16.1, R40.2, U3.6 (-IN2)
unnamed: C15.2, R38.1, TP2.1, U4.5 (+IN1)
unnamed: C15.1, R39.2, U4.4 (-IN1)
unnamed: C17.2, R43.2, TP3.1, U4.7 (+IN2)
unnamed: C17.1, R42.2, U4.6 (-IN2)
unnamed: R70.1, U7.10 (MR#)
unnamed: D6.2, U7.7 (Q7)
unnamed: R85.1, U11.3 (IO2)
unnamed: R84.1, U11.7 (IO3)
unnamed: D13.1, U12.5 (UD+)
unnamed: D13.3, U12.6 (UD-)
PB5: J12.6, R9.1, U10.13 (B5)
PB6: J12.10, U10.14 (B6)
PB7: R86.1, U10.15 (B7)
RTS: R73.1, U10.9 (A12), U12.14 (~RTS)
SPI SCK: R80.2, U7.11 (SHCP), U10.30 (A5), U11.6 (CLK)
SPI_CS: R83.2, U10.1 (B12)
SPI_MISO: R81.2, U10.31 (A6), U11.2 (DO)
SPI_MOSI: R82.2, U7.14 (DS), U10.32 (A7), U11.5 (DI)
SR_Latch: U7.12 (STCP), U10.29 (A4)
SWDCLK: J3.8, J19.4, TP13.1, U10.43 (SWCLK)
SWDIO: J3.7, J19.2, TP14.1, U10.42 (SW0)
Shunt -: C6.1, C9.2, C21.1, C25.1, D8.2, L3.1, R18.2, R19.2, R27.1, R28.1, R62.1
Status_LED: D12.4 (DIN), U10.22 (C13)
UART1_RX: J3.4, U10.7 (A10), U12.2 (TXD)
UART1_TX: J3.3, U10.6 (A9), U12.3 (RXD)
VBUS: C40.1, D13.5, J20.A9B4 (VBUS), J20.B9A4 (VBUS)
VSENSE_3V3+: D1.6, J1.19, R58.2, R60.2
VSENSE_3V3-: D1.5, J1.17, R61.2
VSENSE_5V+: D1.3, J1.03, R62.2, R65.2
VSENSE_5V-: D1.1, J1.01, R66.2
V_out +3V3: D9.2, J7.1, J9.2, L1.2, R60.1
V_out +5V: D11.2, J5.1, J10.2, L3.2, R65.1

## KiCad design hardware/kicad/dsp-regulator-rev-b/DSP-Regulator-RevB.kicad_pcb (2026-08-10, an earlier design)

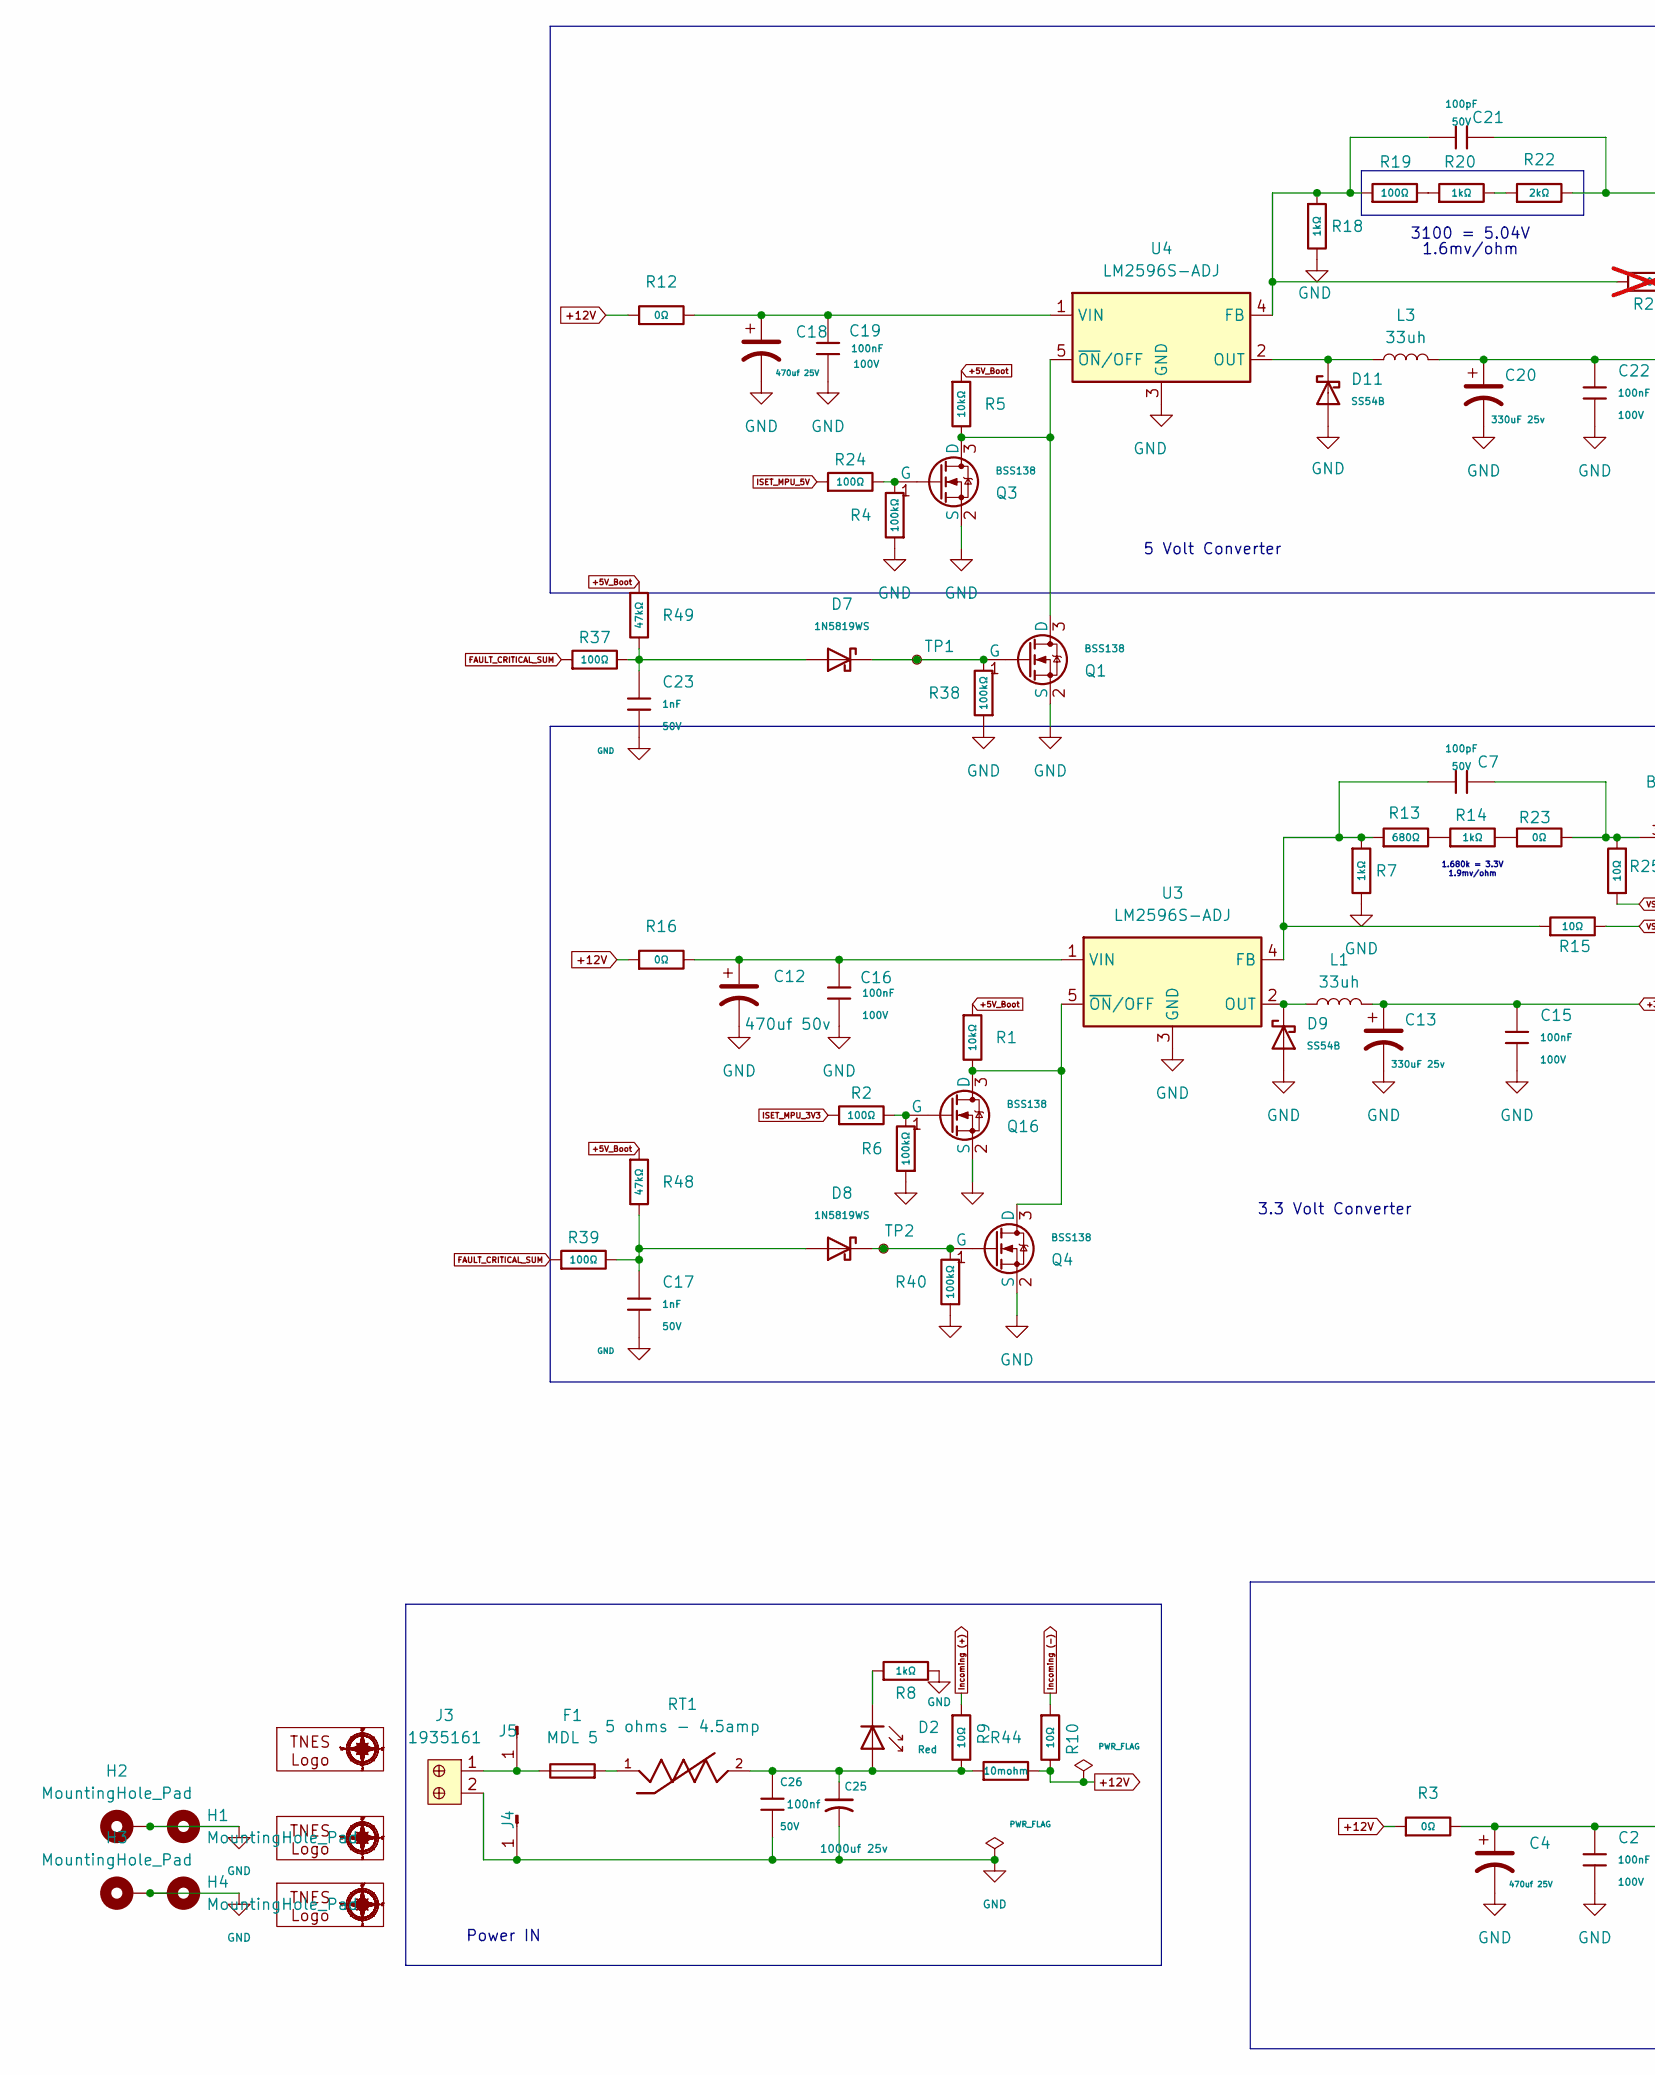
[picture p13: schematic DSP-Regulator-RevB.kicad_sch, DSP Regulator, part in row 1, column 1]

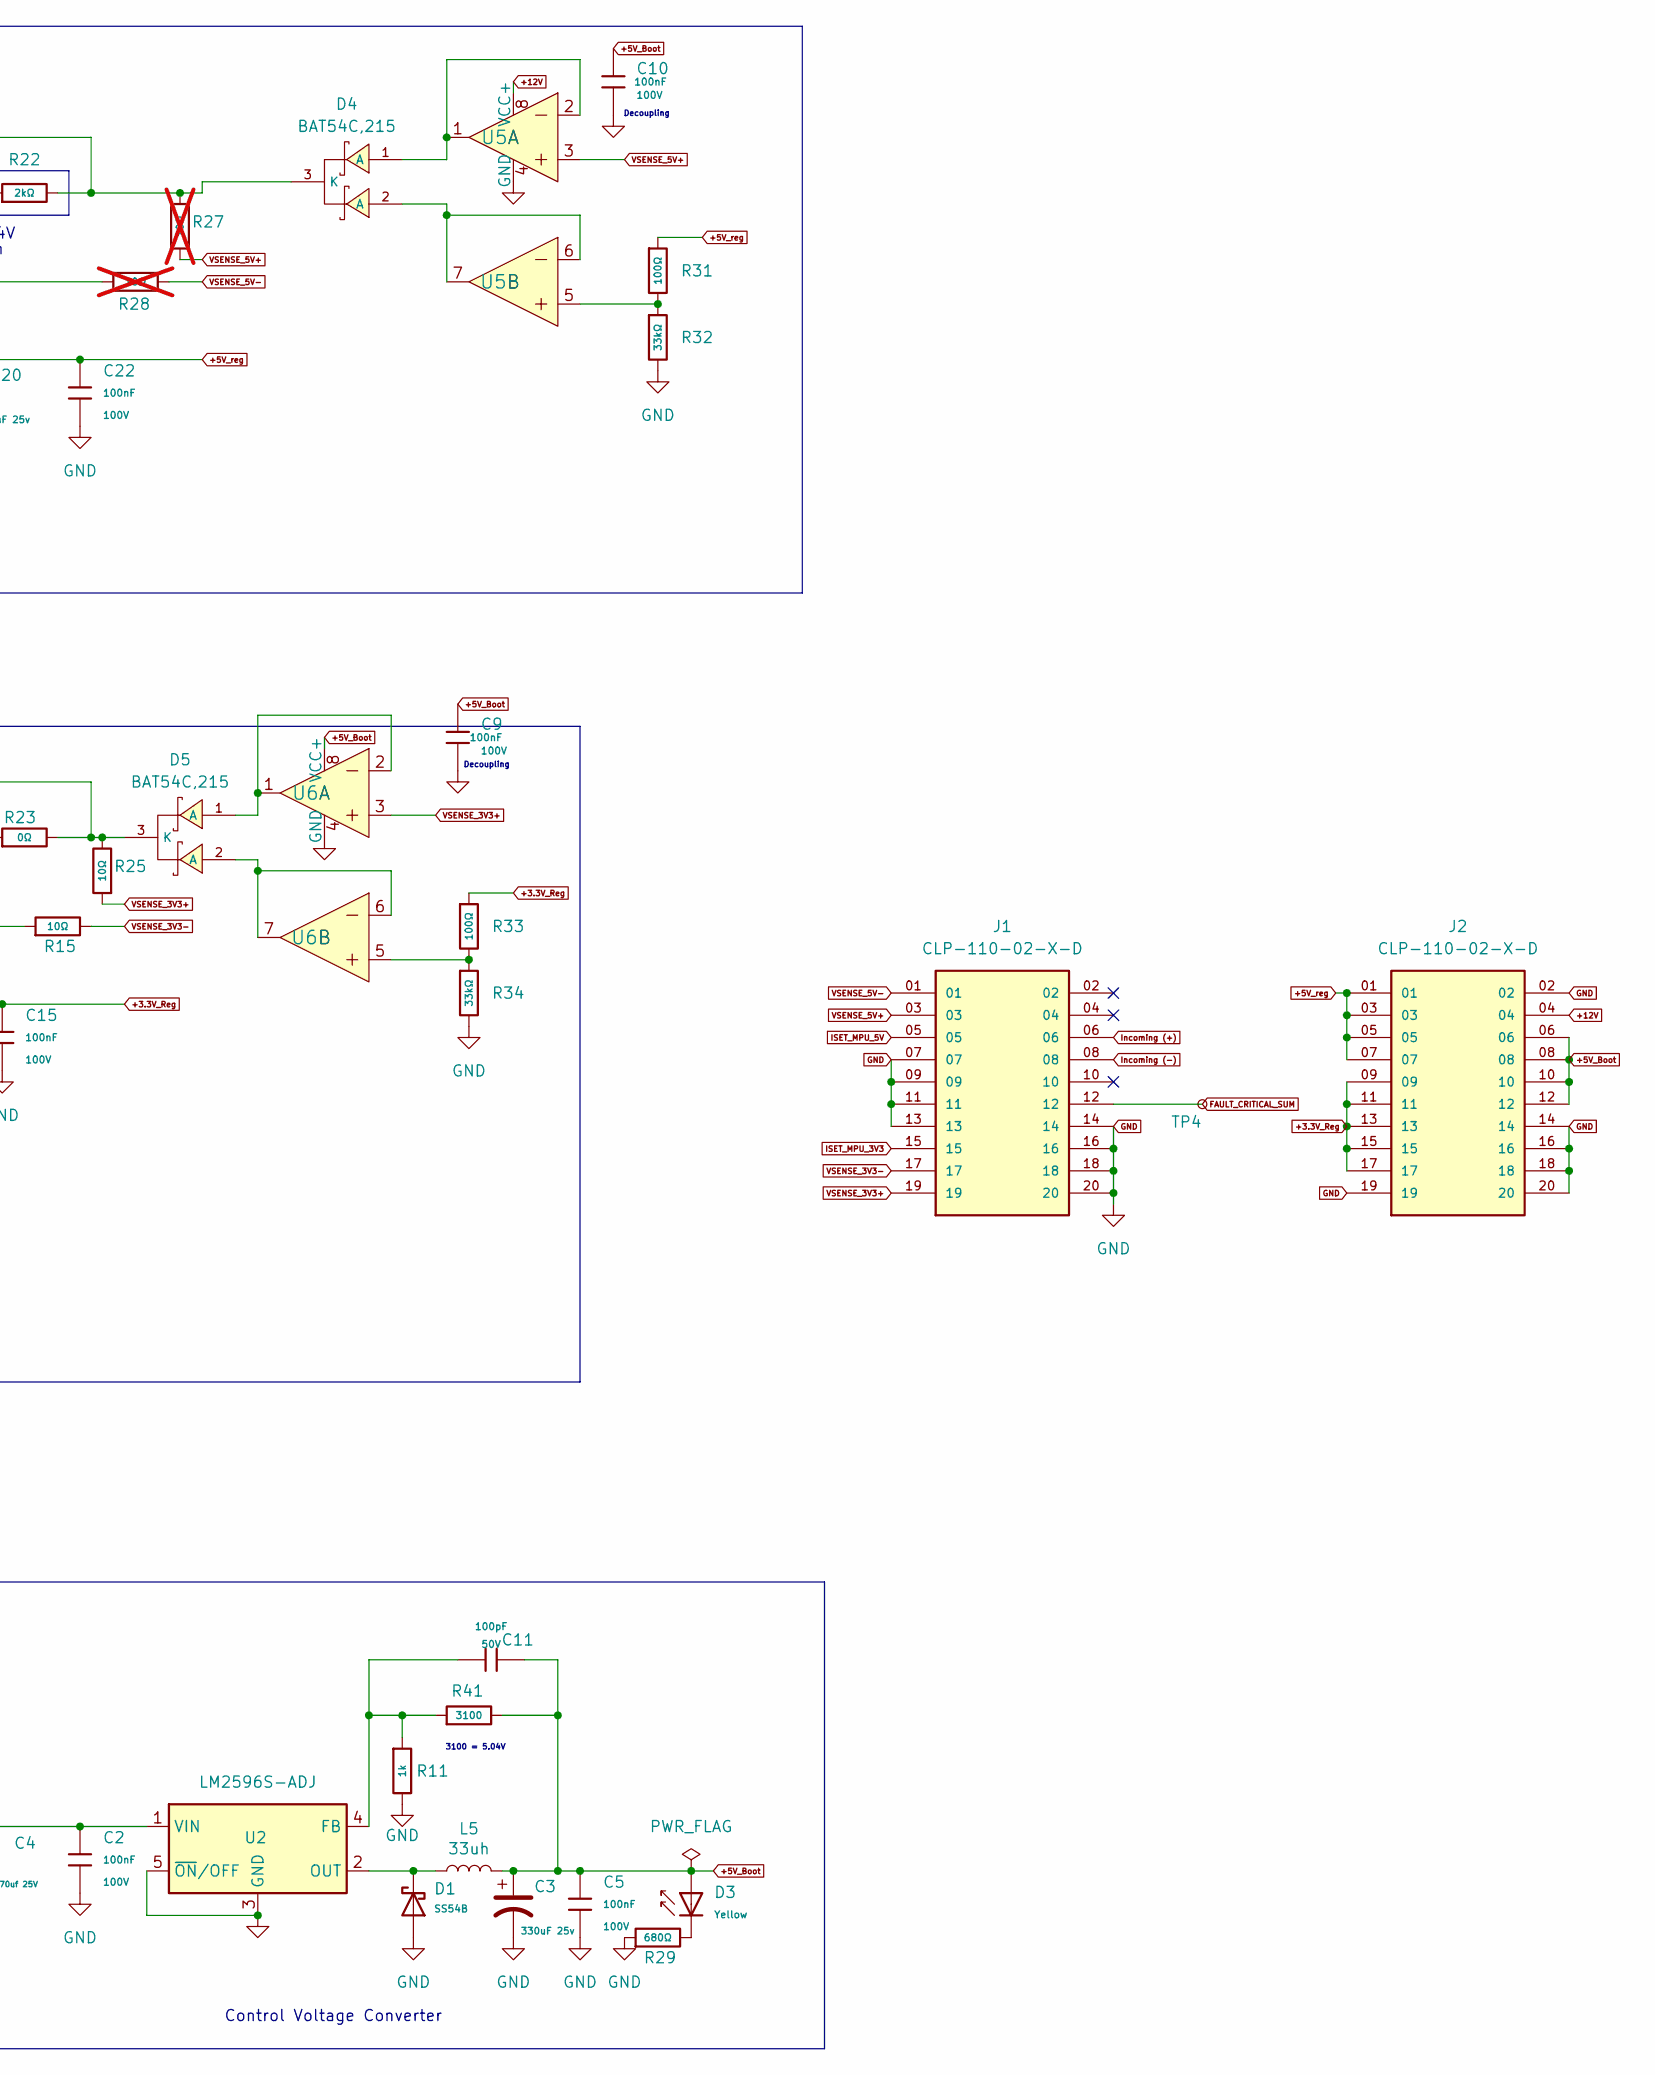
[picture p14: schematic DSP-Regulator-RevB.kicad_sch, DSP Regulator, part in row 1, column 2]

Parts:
5mm1: 5mm LOGO
10mm1, 10mm2: 10mm LOGO
C2, C5, C9, C10, C15, C16, C19, C22: 100nF; C_0805; Voltage Rated 100V; Tolerance ±10%; Part CL21B104KCFNNNE; LCSC C28233
C3, C13, C20: 330uF 25v; CP_Elec_10x10.5; LCSC C72510
C4, C18: 470uf 25V; CP_Elec_10x10.5; Voltage Class 25; LCSC C48615124
C7, C11, C21: 100pF; C_0805; Voltage Rated 50V; Tolerance ±5%; Part CL21C101JBANNNC; LCSC C1790
C12: 470uf 50v; CP_Elec_10x10.5; Voltage Class 50; LCSC C34642
C17, C23: 1nF; C_0805; Voltage Rated 50V; Tolerance ±10%; Part CL21B102KBCNNNC; LCSC C46653
C25: 1000uf 25v; C_Elec_10x10.2; Part EEEFT1E102UP; LCSC C401766
C26: 100nf; C_0805; Voltage Rated 50V; Tolerance ±10%; Part CL21B104KCFNNNE; LCSC C28233
D1, D9, D11: SS54B; D_SMB; Voltage - Forward(Vf@If) 550mV@5.0A; Voltage - DC Reverse(Vr) 40V; Part SS54B; LCSC C18199181
D2: Red; D_0805; Forward Voltage (VF) 1.6V~2.6V; Part NCD0805R1; LCSC C84256
D3: Yellow; D_0805; Part KT-0805Y; LCSC C2296
D4, D5: BAT54C,215; SOT-23-3_L2.9-W1.6-P1.90-LS2.8-BR; Reverse Voltage (Vr) 30V; Forward Voltage (Vf@If) 800mV@100mA; Part BAT54C,215; LCSC C37704
D7, D8: 1N5819WS; D_SOD-323; Forward Voltage (Vf@If) 600mV@1A; Reverse Voltage (Vr) 40V; Part 1N5819WS; LCSC C191023
F1: MDL 5; Fuseholder_Clip-6.3x32mm_Littelfuse_102_Inline_P34.21x7.62m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
H1, H2, H3, H4: MountingHole_Pad; MountingHole_3.2mm_M3_Pad_Via
J1, J2: CLP-110-02-X-D; SAMTEC_CLP-110-02-X-D; PARTREV W
J3: 1935161; Terminal_Block_D1.3mm_P5mm; MPN 1935161; Digi-Key_PN 277-1667-ND
J4, J5: Wire con; SolderWire-1sqmm_1x01_D1.4mm_OD2.7mm
L1, L3, L5: 33uh; L_11.5x10mm_H6mm; LCSC C149598
Q1, Q3, Q4, Q16: BSS138; Q_SOT-23; Part BSS138; LCSC C7420339
R1, R5: 10kΩ; R_0805; Overload Voltage (Max) 150V; Tolerance ±1%; Part 0805W8F1002T5E; LCSC C17414
R2, R19, R24, R31, R33, R37, R39: 100Ω; R_0805; Overload Voltage (Max) 150V; Tolerance ±1%; Part 0805W8F1000T5E; LCSC C17408
R3, R12, R16: 0Ω; R_1206; Overload Voltage (Max) 200V; Tolerance ±1%; Part 1206W4F0000T5E; LCSC C17888
R4, R6, R38, R40: 100kΩ; R_0805; Overload Voltage (Max) 150V; Tolerance ±1%; Part 0805W8F1003T5E; LCSC C149504
R7, R8, R14, R18, R20: 1kΩ; R_0805; Overload Voltage (Max) 150V; Tolerance ±1%; Part 0805W8F1001T5E; LCSC C17513
R9, R10, R15, R25: 10Ω; R_0805; Overload Voltage (Max) 150V; Tolerance ±1%; Part 0805W8F100JT5E; LCSC C17415
R11: 1k; R_0805; Overload Voltage (Max) 150V; Tolerance ±1%; Part 0805W8F1001T5E; LCSC C17513
R13, R29: 680Ω; R_0805; Overload Voltage (Max) 150V; Tolerance ±1%; Part 0805W8F6800T5E; LCSC C17798
R22: 2kΩ; R_0805; Overload Voltage (Max) 150V; Tolerance ±1%; Part 0805W8F2001T5E; LCSC C17604
R23: 0Ω; R_0805; Overload Voltage (Max) 150V; Tolerance ±1%; Part 0805W8F0000T5E; LCSC C17477
R27, R28: 10Ω; R_0805; Overload Voltage (Max) 150V; Tolerance ±1%; Part 0805W8F100JT5E; LCSC C17415; not fitted
R32, R34: 33kΩ; R_0805; Overload Voltage (Max) 150V; Tolerance ±1%; Part 0805W8F3302T5E; LCSC C17633
R41: 3100; R_0805; Overload Voltage (Max) 150V; Tolerance ±1%; Part 0805W8F1000T5E; LCSC C17408
R44: 10mohm; R_0805; Overload Voltage (Max) 150V; Tolerance ±1%; Part 0805W8F0000T5E; LCSC C17477
R48, R49: 47kΩ; R_0805; Overload Voltage (Max) 150V; Tolerance ±1%; Part 0805W8F4702T5E; LCSC C17713
RT1: 5 ohms - 4.5amp; Inrush limiter; PARTREV 8/1/2022
TP1, TP2, TP4: TestPoint_Small; PinHeader_1x01_P2.54mm_Vertical
U2, U3, U4: LM2596S-ADJ; TO-263-5_TabPin3
U5, U6: LMV358IDR; SOIC-8_W3.9mm; MPN LMV358IDR; Digi-Key_PN 296-9571-1-ND

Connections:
+3.3V_Reg: C13.1, C15.1, J2.09, J2.11, J2.13, J2.15, J2.17, L1.2, R33.1
+5V_reg: C20.1, C22.1, J2.01, J2.03, J2.05, J2.07, L3.2, R31.1
FAULT_CRITICAL_SUM: J1.12, R37.1, R39.1, TP4.1
GND: C2.2, C3.2, C4.2, C5.2, C9.2, C10.2, C12.2, C13.2, C15.2, C16.2, C17.2, C18.2, C19.2, C20.2, C22.2, C23.2, C25.2, C26.2, D1.2, D9.2, D11.2, H1.1, H2.1, H3.1, H4.1, J1.07, J1.09, J1.11, J1.13, J1.14, J1.16, J1.18, J1.20, J2.02, J2.14, J2.16, J2.18, J2.19, J2.20, J3.2, J4.1, Q1.2 (S), Q3.2 (S), Q4.2 (S), Q16.2 (S), R4.1, R6.1, R7.2, R8.2, R11.2, R18.2, R29.1, R32.2, R34.2, R38.1, R40.1, U2.3 (GND), U2.5 (~ON/OFF), U3.3 (GND), U4.3 (GND), U5.4 (GND), U6.4 (GND)
ISET_MPU_3V3: J1.15, R2.1
ISET_MPU_5V: J1.05, R24.1
Incoming (+): J1.06, R9.1
Incoming (-): J1.08, R10.1
unnamed: C17.1, D8.2, R39.2, R48.2
unnamed: C23.1, D7.2, R37.2, R49.2
unnamed: C25.1, C26.1, D2.2, R9.2, R44.1, RT1.2
unnamed: D2.1, R8.1
unnamed: D3.1, R29.2
unnamed: D4.1 (A), U5.1, U5.2
unnamed: D4.2 (A), U5.6, U5.7
unnamed: C21.1, D4.3 (K), R22.2, R27.2
unnamed: D5.1 (A), U6.1, U6.2
unnamed: D5.2 (A), U6.6, U6.7
unnamed: C7.1, D5.3 (K), R23.2, R25.2
unnamed: F1.2, RT1.1
unnamed: F1.1, J3.1, J5.1
unnamed: Q1.3 (D), Q3.3 (D), R5.2, U4.5 (~ON/OFF)
unnamed: D7.1, Q1.1 (G), R38.2, TP1.1
unnamed: Q3.1 (G), R4.2, R24.2
unnamed: D8.1, Q4.1 (G), R40.2, TP2.1
unnamed: Q4.3 (D), Q16.3 (D), R1.2, U3.5 (~ON/OFF)
unnamed: Q16.1 (G), R2.2, R6.2
unnamed: R13.2, R14.1
unnamed: R14.2, R23.1
unnamed: R19.2, R20.1
unnamed: R20.2, R22.1
unnamed: R31.2, R32.1, U5.5
unnamed: R33.2, R34.1, U6.5
unnamed: C11.2, R11.1, R41.1, U2.4 (FB)
unnamed: D1.1, L5.1, U2.2 (OUT)
unnamed: C2.1, C4.1, R3.2, U2.1 (VIN)
unnamed: C7.2, R7.1, R13.1, R15.1, U3.4 (FB)
unnamed: D9.1, L1.1, U3.2 (OUT)
unnamed: C12.1, C16.1, R16.2, U3.1 (VIN)
unnamed: C21.2, R18.1, R19.1, R28.2, U4.4 (FB)
unnamed: D11.1, L3.1, U4.2 (OUT)
unnamed: C18.1, C19.1, R12.2, U4.1 (VIN)
VSENSE_3V3+: J1.19, R25.1, U6.3
VSENSE_3V3-: J1.17, R15.2
VSENSE_5V+: J1.03, R27.1, U5.3
VSENSE_5V-: J1.01, R28.1

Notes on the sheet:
Power IN
Control Voltage Converter
3100 = 5.04V
3.3 Volt Converter
5 Volt Converter
1.6mv/ohm
Decoupling
1.680k = 3.3V 1.9mv/ohm

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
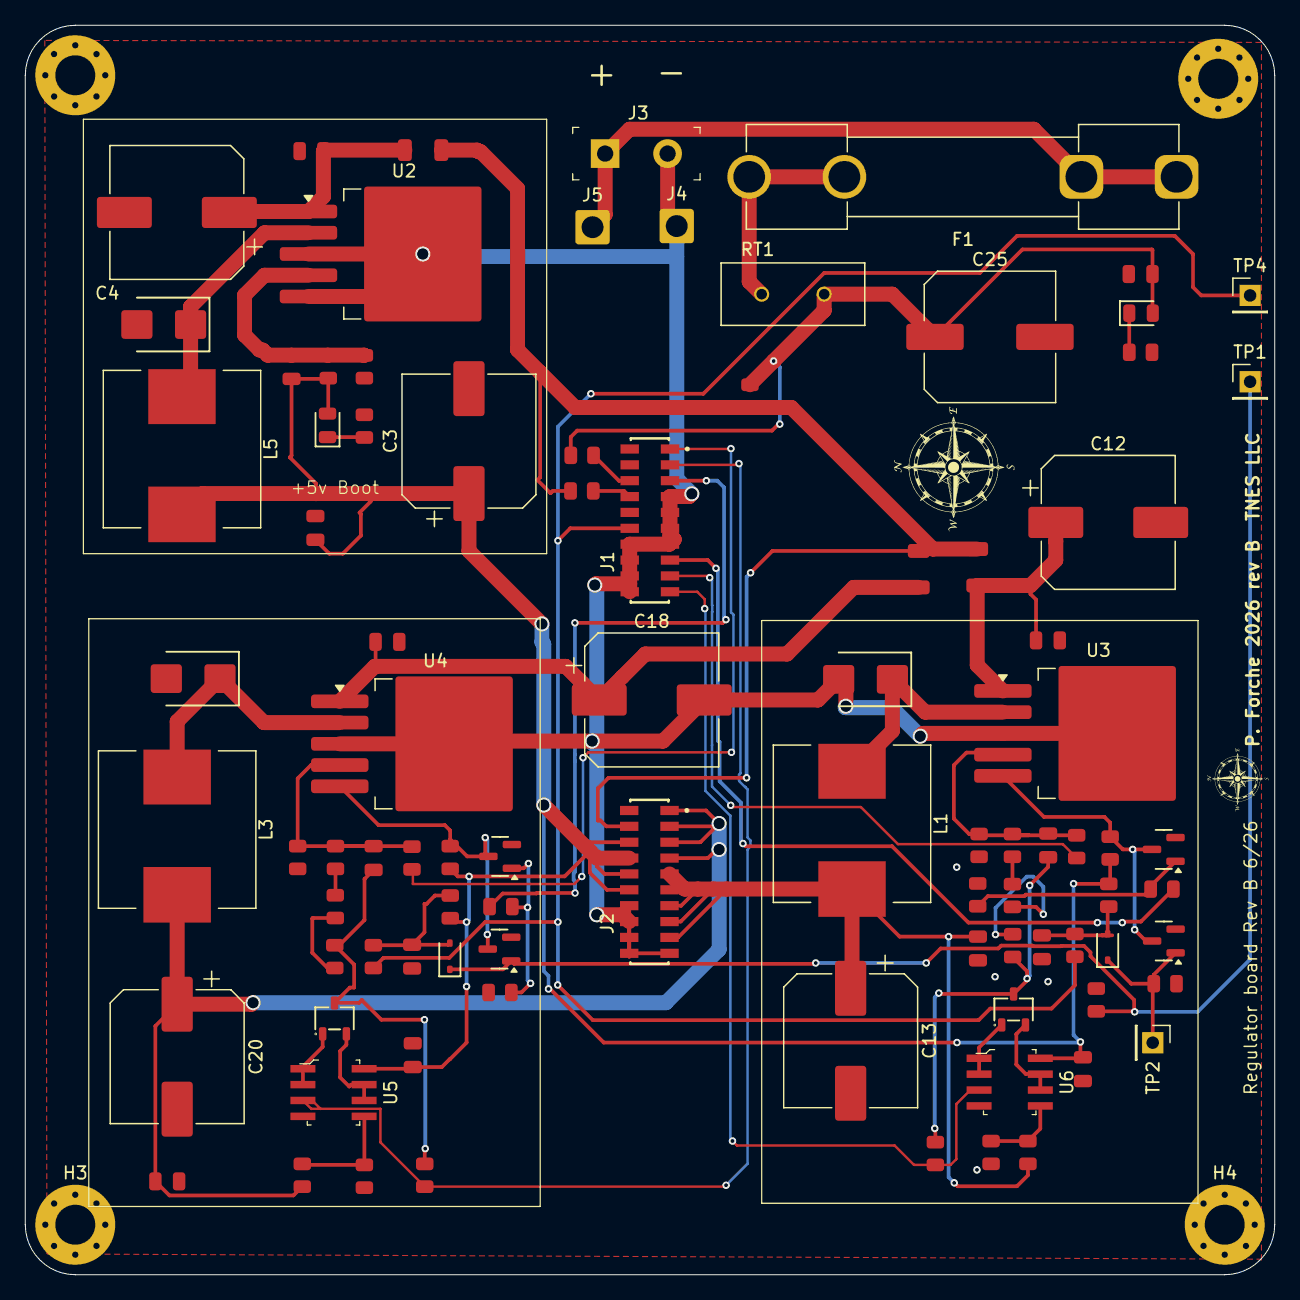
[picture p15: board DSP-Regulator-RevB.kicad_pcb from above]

Board: 2 copper layers, 100.0 x 100.0 mm, 97 parts (1 on the bottom side), 48 nets.

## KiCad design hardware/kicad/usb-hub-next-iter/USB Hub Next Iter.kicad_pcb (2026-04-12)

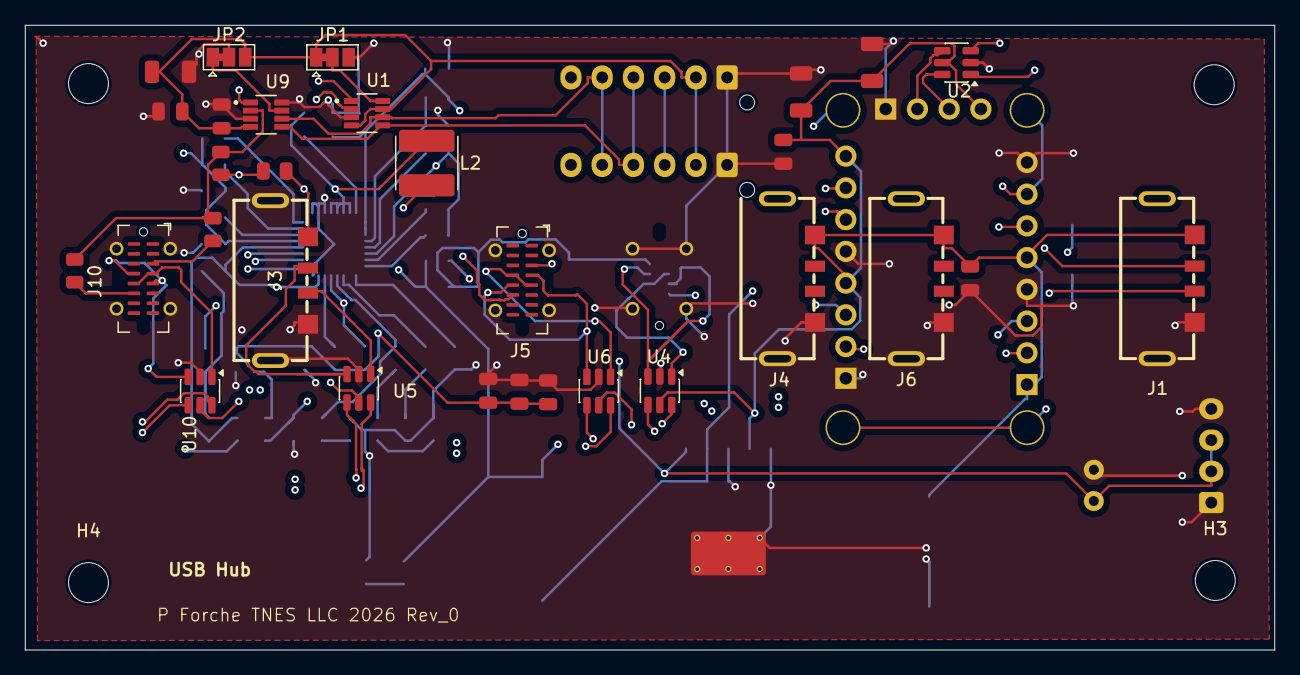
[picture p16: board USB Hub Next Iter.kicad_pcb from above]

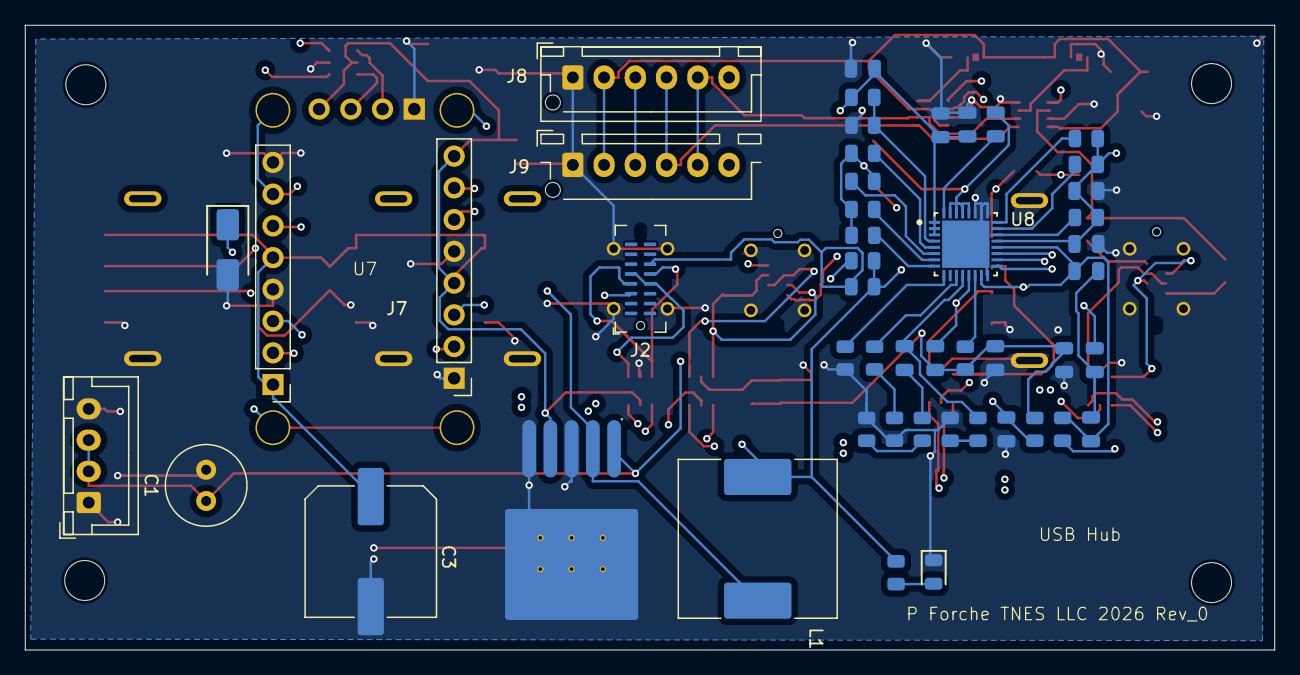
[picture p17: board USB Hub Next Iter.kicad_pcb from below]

Board: 4 copper layers, 100.0 x 50.0 mm, 82 parts (48 on the bottom side), 62 nets.

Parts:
C1: 100uF; C_Radial_D6.3mm_H7.0mm_P2.50mm
C2, C5, C7, C11, C17, C18, C19, C20, C21, C26: 100nF; C_0805
C3: 1000uf; C_Elec_10x10.2
C4, C16: 47uF; C_1206
C6, C8, C13: 220nF; C_0805
C9, C10, C12, C14, C15: 22uF; C_0805
C22: 2.2uF; C_0805
C23: 10uF; C_0805
C24: 2.2nF; C_0805
C25: 100uF; C_1206
D1: B360; D_SMA
D2: Green; D_0805
H1, H2, H3, H4: MountingHole; MountingHole_3.2mm_M3
J1, J3, J4, J6: USB_A; USB-A-SMD_916-261B2115S30200
J2, J10: Connector, USB-TYPE-C-16P; USB_C_Receptacle_G-Switch_GT-USB-7051x
J5: Connector, USB-TYPE-C- vert; USB_C_Receptacle_G-Switch_GT-USB-7051x
J7: From 12V supply; JST_XH_B4B-XH-A_1x04_P2.50mm_Vertical
J8, J9: B5B-XH-A_LF__SN_; JST_XH_B6B-XH-AM_1x06_P2.50mm_Vertical
JP1, JP2: SolderJumper_3_Bridged12; SolderJumper-3_P1.3mm_Bridged12_Pad1.0x1.5mm
L1: 100uh; L_Sunlord_SWRB1204S
L2: 3.3uh 4A; L_Coilcraft_1515SQ-47N
R1, R3, R23: 0.01; R_0805
R2: 100Ω; R_0805
R4, R7, R10: 10kΩ; R_0805
R5: 2.7kΩ; R_0805
R6, R9: 1.8kΩ; R_0805
R8: 300Ω; R_0805
R11: 20kΩ; R_0805
R12: 49.9kΩ; R_0805
R13, R21, R22, R25, R26: 5.1kΩ; R_0805
R14, R15, R16, R17, R18, R19, R20: 100kΩ; R_0805
R24: 330Ω; R_0805
U1, U9: INA219; SOT65P280X145-8N
U2, U4, U6, U10: USBLC6; SOT-23-6
U3: LM2576SX; PG-TO-263-5_L10.2-W8.7-P1.70-LS14.4-BR
U5: USBLC6-2SC6; SOT-23-6
U7: ADA_Fruit_CH334F; Adafruit CH334
U8: TPS25830AQCWRHBRQ1; RHB0032AA-IPC_A

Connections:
3v3: C2.2, C25.1, C26.2, J8.2, J9.2, JP1.1 (A), JP2.3 (B), U1.4 (VS), U1.7 (A0), U9.4 (VS)
5V Main Usb: C3.1, C4.1, C5.2, C16.1, C18.2, J1.1 (VBUS), J4.1 (VBUS), J6.1 (VBUS), L1.1, R1.1, R23.2, R24.1, R25.2, R26.2, U1.1 (IN+), U2.5 (VBUS), U3.4 (FB), U4.5 (VBUS), U7.1 (5V_2), U7.5 (5V_4), U7.9 (5V_H), U7.13 (5V_3), U7.17 (5V_1), U9.1 (IN+), U10.5 (VBUS)
+12V: C1.1, C21.1, C23.1, C24.1, J7.2, J7.3, R11.1, U3.1 (VIN), U8.1 (IN), U8.2 (IN), U8.3 (IN)
GND: C1.2, C2.1, C3.2, C4.2, C5.1, C9.2, C10.1, C11.1, C12.2, C14.1, C15.2, C16.2, C18.1, C20.2, C21.2, C22.2, C23.2, C24.2, C25.2, C26.1, D1.2 (A), D2.1, J1.4 (GND), J1.5 (Shield), J2.S1 (SHIELD), J3.4 (GND), J3.5 (Shield), J3.6, J4.4 (GND), J4.5 (Shield), J5.S1 (SHIELD), J6.4 (GND), J6.5 (Shield), J7.1, J7.4, J8.1, J9.1, J10.S1 (SHIELD), JP1.3 (B), JP2.2 (C), R4.2, R7.2, R10.2, R12.1, R13.2, U1.3 (GND), U2.2 (GND), U3.3 (GND), U3.5 (ON#/OFF), U3.6 (TAB), U4.2 (GND), U5.2 (GND), U6.2 (GND), U7.4 (GND_2), U7.8 (GND_4), U7.12 (GND_H), U7.16 (GND_3), U7.20 (GND_1), U8.16 (AGND), U8.25 (PGND), U8.26 (PGND), U8.27 (PGND), U8.33 (Thermal_Pad), U9.3 (GND), U9.8 (A1), U10.2 (GND)
GPIO: J8.3, J9.3
I2C_CLK: J8.4, J9.4, U1.5 (SCL), U9.5 (SCL)
I2C_Data: J8.5, J9.5, U1.6 (SDA), U9.6 (SDA)
unnamed: C7.2, C9.1, C10.2, C12.1, C14.2, C15.1, L2.1, R3.2, R8.1
unnamed: C6.2, C8.2, C13.2
unnamed: C17.1, R6.2
unnamed: C19.1, L2.2, U8.28 (SW), U8.29 (SW), U8.30 (SW), U8.31 (SW)
unnamed: D1.1 (K), L1.2, U3.2 (OUT)
unnamed: D2.2, R24.2
unnamed: J1.3 (D+), U2.1 (I/O1)
unnamed: J1.2 (D-), U2.3 (I/O2)
unnamed: J2.A5 (CC1), R25.1
unnamed: J2.B5 (CC2), R26.1
unnamed: J2.A6 (D+), J2.B6 (D+), U4.3 (I/O2)
unnamed: J2.A7 (D-), J2.B7 (D-), U4.1 (I/O1)
unnamed: J3.3 (D+), U5.1 (I/O1)
unnamed: J3.2 (D-), U5.3 (I/O2)
unnamed: J3.1 (VBUS), R1.2, U1.2 (IN-), U5.5 (VBUS)
unnamed: C6.1, C8.1, J5.A5 (CC1), R2.1, U8.15 (BUS), U8.20 (CC1)
unnamed: C13.1, J5.B5 (CC2), U8.19 (CC2)
unnamed: J5.A6 (D+), J5.B6 (D+), U6.3 (I/O2)
unnamed: J5.A7 (D-), J5.B7 (D-), U6.1 (I/O1)
unnamed: J10.A5 (CC1), R22.2
unnamed: J10.B5 (CC2), R21.2
unnamed: J10.A6 (D+), J10.B6 (D+), U10.1 (I/O1)
unnamed: J10.A7 (D-), J10.B7 (D-), U10.3 (I/O2)
unnamed: JP1.2 (C), U1.8 (A1)
unnamed: JP2.1 (A), U9.7 (A0)
unnamed: R4.1, R5.1
unnamed: R6.1, R7.1
unnamed: R9.1, R10.1
unnamed: R2.2, U6.5 (VBUS)
unnamed: C19.2, U8.32 (BOOT)
unnamed: C7.1, C11.2, R3.1, U8.13 (CSN_OUT)
unnamed: R8.2, U8.14 (CSP)
unnamed: R14.1, U8.5 (CTRL1)
unnamed: R15.1, U8.6 (CTRL2)
unnamed: R19.1, U8.8 (DM_OUT)
unnamed: R20.1, U8.7 (DP_OUT)
unnamed: R11.2, R13.1, U8.4 (EN)
unnamed: R16.1, U8.24 (FAULT_N)
unnamed: C17.2, R9.2, U8.12 (ILIMIT)
unnamed: R5.2, U8.11 (IMON)
unnamed: R17.1, U8.23 (LD_DET_N)
unnamed: R18.1, U8.22 (POL_N)
unnamed: R12.2, U8.9 (RT_SYNC)
unnamed: C20.1, C22.1, R14.2, R15.2, R16.2, R17.2, R18.2, R19.2, R20.2, U8.21 (VCC)
unnamed: R21.1, R22.1, R23.1, U9.2 (IN-)
Port 1_D+: U4.4 (I/O2), U7.18 (+D1_1)
Port 1_D-: U4.6 (I/O1), U7.19 (-D1_1)
Port 2_D+: U7.2 (+D1_2), U10.4 (I/O2)
Port 2_D-: U7.3 (-D1_2), U10.6 (I/O1)
Port 3_D+: U6.4 (I/O2), U7.14 (+D1_3), U8.18 (DP_IN)
Port 3_D-: U6.6 (I/O1), U7.15 (-D1_3), U8.17 (DM_IN)
Port 4_D+: U5.6 (I/O1), U7.6 (+D1_4)
Port 4_D-: U5.4 (I/O2), U7.0 (GND), U7.7 (-D1_4)
Port H_D+: U2.6 (I/O1), U7.10 (+D1_H)
Port H_D-: U2.4 (I/O2), U7.11 (-D1_H)

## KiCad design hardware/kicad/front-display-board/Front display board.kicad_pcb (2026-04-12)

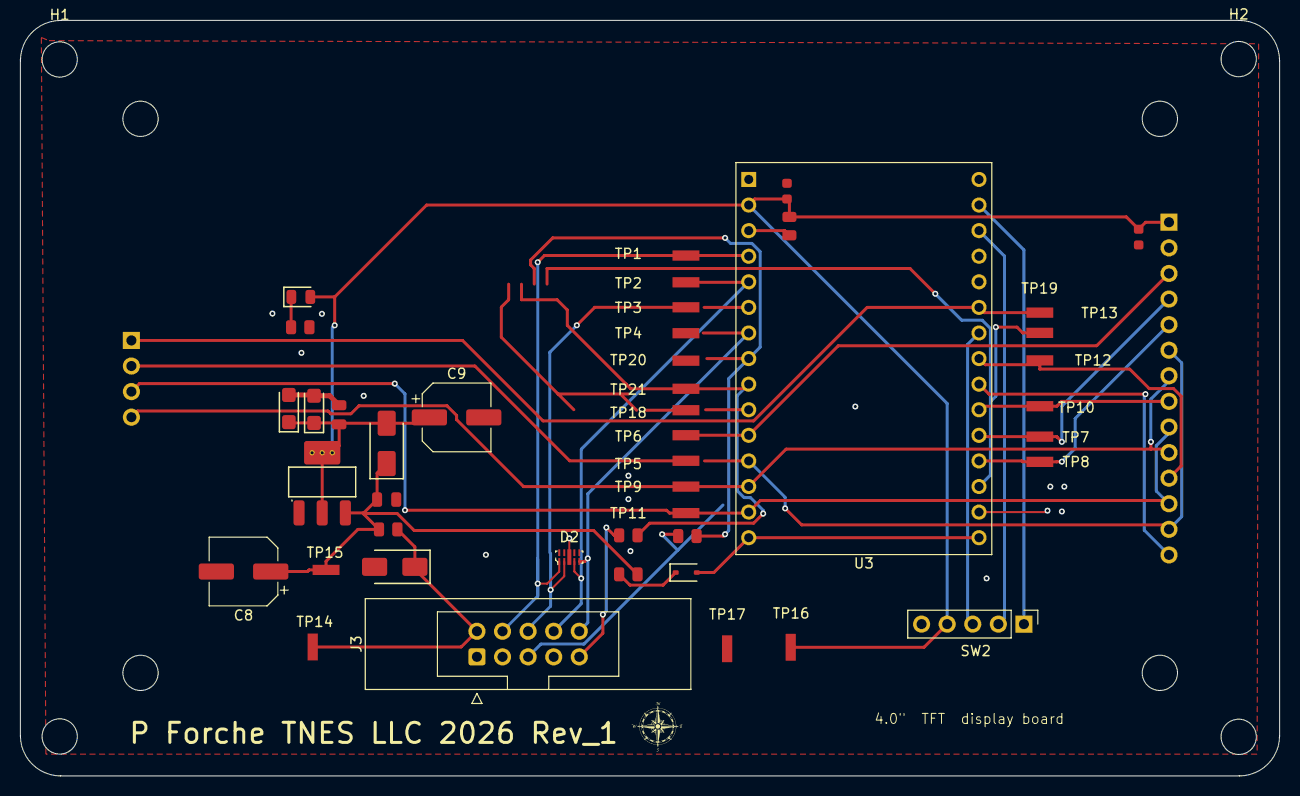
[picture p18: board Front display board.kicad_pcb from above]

Board: 2 copper layers, 125.0 x 75.0 mm, 50 parts (1 on the bottom side), 31 nets.

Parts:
5mm1: 5mm LOGO
C1, C10: 100nF; C_0603
C4, C5: 10uF; C_CASE-A-3216-18(mm)
C6, C7: 100nF; C_0805
C8, C9: 330uf; CP_Elec_6.3x7.7
D1: M1; D_SMA
D2: RCLAMP0524PATCT; UFDFN-10_2.5x1mm
D3: SMAJ5.0A; D_SMA
D4: Green; D_0805
D5: 1N5819WS; D_SOD-323
F1: PTC RESET FUSE 6V 500mA 0805; R_0805
H1, H2, H3, H4: MountingHole; MountingHole_3.5mm
J3: 2 x 5 IDE; IDC-Header_2x05_P2.54mm_Latch_Vertical
R1: 10kΩ; R_0805
R2: 120Ω; R_0805
R3, R4: 220Ω; R_0805
R5: 0Ω; R_0805
SW2: RotaryEncoder_Switch; PinHeader_1x05_P2.54mm_Vertical
TP1, TP2, TP3, TP4, TP5, TP6, TP7, TP8, TP9, TP10, TP11, TP12, TP13, TP14, TP15, TP16, TP17, TP18, TP19, TP20, TP21: 5015; Test_Point_2.67x1.02mm
U1: DISP 1; Hosyond 4.0 480x320
U2: AMS1117; SOT-223-3_L6.5-W3.4-P2.30-LS7.0-BR
U3: ESP32-C6-DevKitM-Amazon; ESP32-C3-DevKitM-1

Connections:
5 V_IN: D3.1, F1.1, J3.2, TP14.1
+3V3: C1.2, C4.1, C5.1, C6.1, C9.1, C10.2, D1.2, D4.2, R1.1, SW2.4 (+V), TP16.1, U1.1 (VCC), U2.2 (VOUT), U2.4 (VOUT), U3.2 (3V3)
CS: TP6.1, U1.3 (~CS), U3.11 (GPIO10)
D/C: TP8.1, U1.5 (D/~C), U3.19 (GPIO18)
Encoder A: SW2.1 (CLK), U3.29 (GPIO2)
Encoder B: SW2.2 (DT), U3.28 (GPIO3)
Encoder SW: SW2.3 (SW), U3.24 (GPIO23)
GND: C1.1, C4.2, C5.2, C6.2, C7.2, C8.2, C9.2, C10.1, D2.3, D2.8, D3.2, J3.1, J3.3, J3.7, R2.2, SW2.5 (GND), TP17.1, U1.2 (GND), U2.1 (GND), U3.1 (GND), U3.17 (GND), U3.30 (GND)
GPIO1: R4.2, TP21.1, U3.9 (GPIO1)
GPIO8: TP18.1, U3.10 (GPIO8)
GPIO9: TP19.1, U3.18 (GPIO9)
IRQ: U1.14 (T_IRQ), U3.22 (GPIO21)
MISO: TP5.1, U1.6 (MOSI), U1.13 (T_DO), U1.16 (SD_MOSI), U3.12 (GPIO11)
MOSI: TP11.1, U1.9 (MISO), U1.12 (T_DIN), U1.17 (SD_MISO), U3.14 (GPIO13)
unnamed: D4.1, R2.1
unnamed: D5.1, R5.1
unnamed: J3.5, R3.1
unnamed: J3.9, R4.1
unnamed: C7.1, C8.1, D1.1, F1.2, R5.2, TP15.1, U2.3 (VIN)
unnamed: R1.2, U3.3 (EN/RESET)
PMW: TP10.1, U1.8 (LED), U3.21 (GPIO20)
RST: TP7.1, U1.4 (RESET), U3.20 (GPIO19)
RTS/CTS: R3.2, TP20.1, U3.8 (GPIO0)
SCLK: TP9.1, U1.7 (SCK), U1.10 (T_CLK), U1.18 (SD_SCK), U3.13 (GPIO12)
SD card CS: TP13.1, U1.15 (SD_CS), U3.25 (GPIO15)
SPI_CS: D2.5, J3.10, TP4.1, U3.7 (GPIO7)
SPI_MISO: D2.2, J3.6, TP3.1, U3.6 (GPIO6)
SPI_MOSI: D2.4, J3.8, TP2.1, U3.5 (GPIO5)
SPI_SCLK: D2.1, J3.4, TP1.1, U3.4 (GPIO4)
Touch CS: TP12.1, U1.11 (T_~CS), U3.23 (GPIO22)
Vbus: D5.2, U3.15 (5V), U3.16 (5V)

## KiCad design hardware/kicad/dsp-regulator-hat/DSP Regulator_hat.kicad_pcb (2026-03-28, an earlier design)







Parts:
5mm1: 5mm LOGO
C1, C2, C3, C8, C11, C12: 10uF; C_0805; Voltage Rated 50V; Tolerance ±10%; Part GRM21BR61H106KE43L; LCSC C440198
C4, C5, C6, C7, C9, C10, C16, C17, C18, C19: 100nf; C_0603; Voltage Rated 50V; Tolerance ±10%; Part CC0603KRX7R9BB104; LCSC C14663
C13, C14, C15, C24, C26: 470uf 25v; CP_Elec_10x10; Part JVE25V470M10X10; LCSC C48615124
C20: 100uF; C_1206; Voltage Rated 6.3V; Tolerance ±20%; Part CL31A107MQHNNNE; LCSC C15008
C21, C22, C23, C25, C27: 100nF; C_0805; Voltage Rated 50V; Tolerance ±10%; Part CC0805KRX7R9BB104; LCSC C49678
CS1: 5015; KEYSTONE_5015; MPN 5017; Digi-Key_PN 36-5017CT-ND
D1, D7: SS54B; D_SMB; Voltage - Forward(Vf@If) 550mV@5.0A; Voltage - DC Reverse(Vr) 40V; Part SS54B; LCSC C18199181
D2, D3, D4: SMBJ6.0A; D_SMB; Clamping Voltage 10.3V; Voltage - Breakdown 6.67V; PARTREV F2102; LCSC C19077561
D5, D6, D8: Green; D_0805; Part KT-0805G; LCSC C2297
H1, H2, H3, H4: MountingHole_Pad; MountingHole_3.2mm_M3_Pad
J1, J2, J3, J10, J11, J12: Wire con; SolderWire-1sqmm_1x01_D1.4mm_OD2.7mm
J4: Left Side; PinHeader_1x15_P2.54mm_Vertical
J5: Conn_01x06_Socket; AMPHENOL_20021121-00010C4LF; PARTREV S
J6: Right Side; PinHeader_1x15_P2.54mm_Vertical
J7: Front Panel; IDC-Header_2x05_P2.54mm_Vertical
J8, J9: I2C bus; JST_B4B-XH-A; PARTREV 7/4/21
L1: Ferrite3.5A 20mΩ; L_1206_3216Metric; LCSC C85841
L2, L3: L_Ferrite 3.5A 20mΩ; L_1206_3216Metric; LCSC C85841
MISO1: 5015; KEYSTONE_5015; MPN 5017; Digi-Key_PN 36-5017CT-ND
MOSI1: 5015; KEYSTONE_5015; MPN 5017; Digi-Key_PN 36-5017CT-ND
Memory_CS1: 5015; KEYSTONE_5015; MPN 5017; Digi-Key_PN 36-5017CT-ND
Q1, Q2, Q3, Q6, Q7, Q8, Q9, Q12: PSMN5R2-60YL; LFPAK56; Part HL3400; LCSC C22469448
Q4, Q10, Q11: PSMN5R2; LFPAK56; Part HL3400; LCSC C22469448
Q5: PSMN5R2'; LFPAK56; Part HL3400; LCSC C22469448
R1, R2, R3, R4, R5, R6: 100kΩ; R_0805; Overload Voltage (Max) 150V; Tolerance ±1%; Part 0805W8F1003T5E; LCSC C149504
R7, R8, R9, R10, R11, R12: 100Ω; R_0805; Overload Voltage (Max) 150V; Tolerance ±1%; Part 0805W8F1000T5E; LCSC C17408
R13, R15, R17: 20mΩ 2W; R_2512_6332Metric; LCSC C7420022
R14, R16, R18: 200mΩ 2W; R_2512_6332Metric; LCSC C7420022
R19, R20, R21, R22, R23, R24, R25, R26, R27, R28, R29, R30, R34, R35: 10Ω; R_0805; Overload Voltage (Max) 150V; Tolerance ±1%; Part 0805W8F100JT5E; LCSC C17415
R31, R32, R33: 270Ω; R_0805; Overload Voltage (Max) 150V; Tolerance ±1%; Part 0805W8F2700T5E; LCSC C17590
R36, R38, R39, R41, R42, R44: 0Ω; R_0805; Overload Voltage (Max) 150V; Tolerance ±1%; Part 0805W8F0000T5E; LCSC C17477; not fitted
R37, R40, R43: 0Ω; R_0805; Overload Voltage (Max) 150V; Tolerance ±1%; Part 0805W8F0000T5E; LCSC C17477
R45, R46, R47, R49, R50: 10kΩ; R_0805; Overload Voltage (Max) 150V; Tolerance ±1%; Part 0805W8F1002T5E; LCSC C17414
R48, R51, R52, R53, R54: 33Ω; R_0805; Overload Voltage (Max) 150V; Tolerance ±1%; Part 0805W8F330JT5E; LCSC C17634
R55, R56, R57, R58: 4.7kΩ; R_0805; Overload Voltage (Max) 150V; Tolerance ±1%; Part 0805W8F4701T5E; LCSC C17673
SCK1: 5015; KEYSTONE_5015; MPN 5017; Digi-Key_PN 36-5017CT-ND
TP1, TP2_+5V1: 5015; KEYSTONE_5015; PARTREV F
TP_+3.3V1: 5015; KEYSTONE_5015; PARTREV F
T_IRQ1: 5015; KEYSTONE_5015; MPN 5017; Digi-Key_PN 36-5017CT-ND
U1, U2, U3: INA3221-AIRGVR; Texas_RGV0016A_VQFN-16-1EP_4x4mm_P0.65mm_EP2.1x2.1mm; LCSC C181255
U4, U5: 74HC595D; SOIC-16_L9.9-W3.9-P1.27-LS6.0-BL; Supply Voltage 2V~6V; Part 74HC595D,118; LCSC C5947
U6: W25Q128; SOIC-8_L5.3-W5.3-P1.27-LS8.0-BL; Part W25Q128JVSIQ; LCSC C97521
U7: ESP32-C6-DevKitM-1; ESP32-C3-DevKitM-1

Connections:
3.3_Select: J6.6, U5.15 (Q0)
3V3_ESP: C17.1, C18.1, C19.1, C20.1, C21.2, C22.2, C23.1, C26.1, C27.1, D7.1, J5.2, J8.2, J9.2, R42.2, R43.2, R44.2, R45.2, R46.2, R47.2, R49.1, R50.2, R55.2, R56.2, R57.2, R58.2, TP_+3.3V1.TP, U1.4 (VS), U2.4 (VS), U3.4 (VS), U4.16 (VCC), U5.16 (VCC), U6.8 (VCC), U7.2 (3V3)
ISET_MPU_3V3: J4.10, U4.7 (Q7)
ISET_MPU_Channel_3: J6.5, U5.1 (Q1)
Memory_CS: Memory_CS1.TP, U6.1 (CS#), U7.14 (GPIO13)
+3.3V_Reg: C2.1, J4.11, J4.12, J4.13, Q3.1 (S), Q3.2 (S), Q3.3 (S), Q4.1 (S), Q4.2 (S), Q4.3 (S)
+3v3V_Hi_Range: R27.2, U2.12 (IN+1)
+3v3V_low_Range: R30.2, U2.15 (IN+2)
+5V_Control: C24.1, C25.1, D1.1, J6.7, J7.1, TP2_+5V1.TP, U7.15 (5V), U7.16 (5V)
+5V_Hi_Range: R19.2, U1.12 (IN+1)
+5V_low_Range: R22.2, U1.15 (IN+2)
+5V_reg: C1.1, D1.2, J4.6, J4.7, J4.8, Q1.1 (S), Q1.2 (S), Q1.3 (S), Q2.1 (S), Q2.2 (S), Q2.3 (S)
+V Adj Channel: C3.1, J6.13, J6.14, J6.15, Q5.1 (S), Q5.2 (S), Q5.3 (S), Q6.1 (S), Q6.2 (S), Q6.3 (S)
+V_Hi_Range: R23.2, U3.12 (IN+1)
+V_low_Range: R26.2, U3.15 (IN+2)
-3v3V_Hi_Range: R28.2, U2.11 (IN-1)
-3v3V_low_Range: R29.2, U2.14 (IN-2)
-5V_Hi_Range: R20.2, U1.11 (IN-1)
-5V_low_Range: R21.2, U1.14 (IN-2)
-V_Hi_Range: R24.2, U3.11 (IN-1)
-V_low_Range: R25.2, U3.14 (IN-2)
Channel _3_High_range: R11.2, U4.6 (Q6)
Channel _3_low_range: R12.2, U4.5 (Q5)
ESP- GPIO 3.3V High: R9.2, U4.3 (Q3)
ESP- GPIO 3.3V Low: R10.2, U4.4 (Q4)
ESP- GPIO 5V Hi: R8.2, U4.1 (Q1)
ESP- GPIO 5V Low: R7.2, U4.2 (Q2)
Feedback 3.3: C8.1, C9.2, C10.1, C13.1, D2.2, J4.9, L1.1, R15.2, R16.2, R28.1, R29.1
Feedback 5V: C4.1, C5.2, C12.1, C15.1, D4.2, J4.4, L2.1, R13.2, R14.2, R20.1, R21.1
Feedback Adj Channel: C6.2, C7.1, C11.1, C14.1, D3.2, J6.4, L3.1, R17.2, R18.2, R24.1, R25.1
GPIO8/BOOT: U7.10 (GPIO8)
GPIO9/BOOT: U7.18 (GPIO9)
GPIO10: J5.6, U7.11 (GPIO10)
GPIO11: J5.8, U7.12 (GPIO11)
GPIO15/JTAG: U7.25 (GPIO15)
ISET_MPU_5V: J4.5, U4.15 (Q0)
Incoming (+): C16.1, J6.9, R34.1
Incoming (-): C16.2, J6.8, R35.1
I²C SCL_0: R36.1, R39.1, R40.1, R55.1, U1.6 (SCL), U2.6 (SCL), U3.6 (SCL), U7.6 (GPIO6)
I²C SCL_1: J8.4, J9.4, R57.1, U7.7 (GPIO7)
I²C SDA_0: R56.1, U1.7 (SDA), U2.7 (SDA), U3.7 (SDA), U7.5 (GPIO5)
I²C SDA_1: J8.3, J9.3, R58.1, U7.8 (GPIO0)
unnamed: C4.2, Q8.1 (S), Q8.2 (S), Q8.3 (S), R14.1, R22.1
unnamed: C5.1, Q7.1 (S), Q7.2 (S), Q7.3 (S), R13.1, R19.1
unnamed: C6.1, Q11.1 (S), Q11.2 (S), Q11.3 (S), R17.1, R23.1
unnamed: C7.2, Q12.1 (S), Q12.2 (S), Q12.3 (S), R18.1, R26.1
unnamed: C9.1, Q9.1 (S), Q9.2 (S), Q9.3 (S), R15.1, R27.1
unnamed: C10.2, Q10.1 (S), Q10.2 (S), Q10.3 (S), R16.1, R30.1
unnamed: D5.1, R31.1
unnamed: D6.1, R32.1
unnamed: D8.1, R33.1
unnamed: J7.3, R51.1
unnamed: J7.5, R52.1
unnamed: J7.6, R48.2
unnamed: J7.7, R53.1
unnamed: J7.9, R54.1
unnamed: Q1.5 (D), Q7.5 (D)
unnamed: Q1.4 (G), Q7.4 (G), R1.1, R7.1
unnamed: Q2.5 (D), Q8.5 (D)
unnamed: Q2.4 (G), Q8.4 (G), R2.1, R8.1
unnamed: Q3.5 (D), Q9.5 (D)
unnamed: Q3.4 (G), Q9.4 (G), R3.1, R9.1
unnamed: Q4.5 (D), Q10.5 (D)
unnamed: Q4.4 (G), Q10.4 (G), R4.1, R10.1
unnamed: Q5.5 (D), Q11.5 (D)
unnamed: Q5.4 (G), Q11.4 (G), R5.1, R11.1
unnamed: Q6.5 (D), Q12.5 (D)
unnamed: Q6.4 (G), Q12.4 (G), R6.1, R12.1
unnamed: R36.2, R37.1, R42.1, U1.5 (A0)
unnamed: R38.1, R39.2, R43.1, U2.5 (A0)
unnamed: R34.2, U2.2 (IN+3)
unnamed: R35.2, U2.1 (IN-3)
unnamed: R40.2, R41.1, R44.1, U3.5 (A0)
unnamed: R45.1, U4.10 (MR#)
unnamed: U4.9 (Q7S), U5.14 (DS)
unnamed: R46.1, U5.10 (MR#)
unnamed: J5.1, U5.2 (Q2)
unnamed: J5.3, U5.3 (Q3)
unnamed: J5.5, U5.4 (Q4)
unnamed: J5.7, U5.5 (Q5)
unnamed: J5.9, U5.6 (Q6)
unnamed: J5.10, U5.7 (Q7)
unnamed: R50.1, U6.3 (IO2)
unnamed: R47.1, U6.7 (IO3)
unnamed: R49.2, U7.3 (EN/RESET)
RTS/CTS: R48.1, T_IRQ1.TP, U7.24 (GPIO23)
RXD: U7.26 (Rx)
SPI SCK: R51.2, SCK1.TP, U6.6 (CLK), U7.20 (GPIO19)
SPI_CS: CS1.TP, R54.2, U7.19 (GPIO18)
SPI_MISO: MISO1.TP, R52.2, U6.2 (DO), U7.21 (GPIO20)
SPI_MOSI: MOSI1.TP, R53.2, U6.5 (DI), U7.22 (GPIO21)
SR_CLK: U4.11 (SHCP), U5.11 (SHCP), U7.4 (GPIO4)
SR_Data: U4.14 (DS), U7.28 (GPIO3)
SR_Latch: U4.12 (STCP), U5.12 (STCP), U7.9 (GPIO1)
TXD: U7.27 (Tx)
V_out +3V3: D5.2, D7.2, J2.1, L1.2
V_out +5V: D6.2, J1.1, L2.2
V_out +CH3: D8.2, J3.1, L3.2

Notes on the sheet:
Channel 1 5 volts
Connectors
Voltage Measuring
I2C Pull-Ups
Channel 2 3.3 volts
Decoupling
16M Memory
Spare Outputs
Regulator control outputs
supply to control
Channel 3 Selectable

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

Board: 2 copper layers, 100.0 x 100.0 mm, 141 parts (0 on the bottom side), 94 nets.

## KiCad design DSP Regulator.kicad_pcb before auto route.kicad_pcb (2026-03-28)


Board: 2 copper layers, 100.0 x 100.0 mm, 71 parts (0 on the bottom side), 42 nets.

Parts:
C1, C12, C18: 470uf 50v; CP_Radial_D10.0mm_P7.50mm
C2, C5, C15, C16, C19, C22: 100nF; C_0805
C3, C13, C20: 330uF 25v; CP_Elec_10x10.5
C7, C11, C21: 100pF; C_0805
C25: 1000uf 25v; C_Elec_10x10.2
C26: 100nf; C_0805
D1, D9, D11: SS54B; D_SMB
D2: Red; D_0805
F1: MDL 5; Fuseholder_Clip-6.3x32mm_Littelfuse_102_Inline_P34.21x7.62m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
H1, H2, H3, H4: MountingHole_Pad; MountingHole_3.2mm_M3_Pad
J1, J2: Conn_01x15_Socket; PinSocket_1x15_P2.54mm_Vertical
J3: 1935161; Terminal_Block_D1.3mm_P5mm
J4, J5: Wire con; SolderWire-1sqmm_1x01_D1.4mm_OD2.7mm
L1, L3, L5: 33uh; L_11.5x10mm_H6mm
Q2, Q3, Q16: BSS138; Q_SOT-23
R1, R4, R5, R6, R64, R65: 100kΩ; R_0805
R2, R19, R24, R41, R63: 100Ω; R_0805
R3, R16, R17: 0Ω; R_1206
R7, R8, R11, R14, R18, R20, R21, R42: 1kΩ; R_0805
R12, R13: 680Ω; R_0805
R22, R43: 2kΩ; R_0805
R23, R26: 0Ω; R_0805
R44: 10mohm; R_0805
RT1: 5 ohms - 4.5amp; Inrush limiter
U2, U3, U4: LM2596S-ADJ; TO-263-5_TabPin3
U8: TS5A3157-DCKR; SOT95P280X145-6N

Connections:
3.3_Select: J2.6, U8.6 (IN)
ISET_MPU_3V3: J1.10, R2.1
ISET_MPU_Channel_3: J2.5, R63.1
+3.3V_Reg: C13.1, C15.1, J1.11, J1.12, J1.13, L1.2
+5V_Control: J2.7, U8.5 (V+)
+5V_reg: C20.1, C22.1, J1.6, J1.7, J1.8, L3.2
+12V: J2.8, R3.1, R16.1, R17.1, R44.2
+V Adj Channel: C3.1, C5.1, J2.13, J2.14, J2.15, L5.2
Feedback 3.3: C7.1, J1.9, R23.2
Feedback 5V: C21.1, J1.4, R22.2
Feedback Adj Channel: C11.1, J2.4, R26.2, R43.2
GND: C1.2, C2.2, C3.2, C5.2, C12.2, C13.2, C15.2, C16.2, C18.2, C19.2, C20.2, C22.2, C25.2, C26.2, D1.2, D9.2, D11.2, H1.1, H2.1, H3.1, H4.1, J1.1, J1.2, J1.3, J2.1, J2.2, J2.3, J3.2, J4.1, R1.2, R4.1, R5.2, R6.1, R7.2, R8.2, R11.2, R18.2, R64.1, R65.2, U2.3 (GND), U3.3 (GND), U4.3 (GND), U8.2 (GND)
ISET_MPU_5V: J1.5, R24.1
Incoming (+): C25.1, C26.1, D2.2, J2.9, R44.1, RT1.2
unnamed: D2.1, R8.1
unnamed: F1.2, RT1.1
unnamed: F1.1, J3.1, J5.1
unnamed: Q2.3 (D), R65.1, U2.5 (~ON/OFF)
unnamed: Q2.1 (G), R63.2, R64.2
unnamed: C1.1, C2.1, Q2.2 (S), R3.2, U2.1 (VIN)
unnamed: Q3.3 (D), R5.1, U4.5 (~ON/OFF)
unnamed: Q3.1 (G), R4.2, R24.2
unnamed: C18.1, C19.1, Q3.2 (S), R17.2, U4.1 (VIN)
unnamed: Q16.3 (D), R1.1, U3.5 (~ON/OFF)
unnamed: Q16.1 (G), R2.2, R6.2
unnamed: C12.1, C16.1, Q16.2 (S), R16.2, U3.1 (VIN)
unnamed: R12.2, R21.1
unnamed: R13.2, R14.1
unnamed: R14.2, R23.1
unnamed: R19.2, R20.1
unnamed: R20.2, R22.1
unnamed: R21.2, R26.1
unnamed: R41.2, R42.1
unnamed: R42.2, R43.1
unnamed: C11.2, R11.1, U2.4 (FB), U8.4 (COM)
unnamed: D1.1, L5.1, U2.2 (OUT)
unnamed: C7.2, R7.1, R13.1, U3.4 (FB)
unnamed: D9.1, L1.1, U3.2 (OUT)
unnamed: C21.2, R18.1, R19.1, U4.4 (FB)
unnamed: D11.1, L3.1, U4.2 (OUT)
unnamed: R41.1, U8.3 (NC)
unnamed: R12.1, U8.1 (NO)

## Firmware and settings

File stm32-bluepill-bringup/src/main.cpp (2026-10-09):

#include <Arduino.h>
#include <SPI.h>
#include <Wire.h>
#include <string.h>
#include <Adafruit_AW9523.h>

#if defined(FIRMWARE_BOARD_F405RG)
#include "board_pins_f405rg.h"
#else
#include "board_pins_f103c8.h"
#endif

// NOTE: framework-arduinoststm32 4.21200.0 (core 2.12) has no `Uart`; its concrete
// serial class is `HardwareSerial` with an (rx, tx) pin-pair constructor.
HardwareSerial SerialDbg(PIN_DEBUG_RX, PIN_DEBUG_TX);
HardwareSerial SerialU3(PIN_UDI_RX, PIN_UDI_TX);
#if defined(FIRMWARE_BOARD_F405RG)
HardwareSerial SerialC3(PIN_C3_UART_RX, PIN_C3_UART_TX);
#endif

// Rev-C netlist currently does not route FAULT_CRITICAL_SUM to an STM32 GPIO.
// Fault observation on Rev-C is handled through AW9523 input + INT signaling.
// U4 shift-register bits controlling 3.3V rail path (PMOS: 0=ON, 1=OFF)
static const uint8_t SR_BIT_3V3_HI = 3;
static const uint8_t SR_BIT_3V3_LO = 4;
static const uint8_t SR_BIT_ADJ_LO = 5;

static const uint8_t AHT20_ADDRESS = 0x38;
static const uint8_t INA3221_ADDR_5V = 0x40;
static const uint8_t INA3221_ADDR_3V3 = 0x41;
static const uint8_t AW95XX_ADDR_MIN = 0x58;
static const uint8_t AW95XX_ADDR_MAX = 0x5B;
static const uint8_t AW95XX_ADDR_ACTIVE = 0x58;
static const uint8_t AW95XX_REG_OUTPUT_P0 = 0x02;
static const uint8_t AW95XX_REG_OUTPUT_P1 = 0x03;
static const uint8_t AW95XX_REG_INPUT_P0 = 0x00;
static const uint8_t AW95XX_REG_CONFIG_P0 = 0x04;
static const uint8_t AW95XX_REG_CONFIG_P1 = 0x05;
static const uint8_t AW95XX_REG_GCR = 0x11;      // Global control register
static const uint8_t AW95XX_REG_LED_MODE_P0 = 0x12; // 1=GPIO, 0=LED current mode (per bit)
static const uint8_t AW95XX_REG_LED_MODE_P1 = 0x13; // 1=GPIO, 0=LED current mode (per bit)
static const uint8_t AW95XX_GCR_PORT_MODE_BIT = 0x10; // 1=push-pull, 0=open-drain
static const uint8_t AW95XX_CFG_P0_POLICY = 0xC0; // P0.0..P0.5 output, P0.6..P0.7 input
static const uint8_t AW95XX_P10_MASK = 0x01;
static const uint8_t AW95XX_P01_MASK = 0x02; // P0.1: ESP- GPIO 5V Hi (Q2/Q8 path)
static const uint8_t AW95XX_P02_MASK = 0x04; // P0.2: ESP- GPIO 5V Low (Q1/Q7 path)
static const uint8_t AW95XX_P03_MASK = 0x08; // P0.3: ESP- GPIO 3V3 High (Q5/Q11 path). Was
                                              // "Channel 3 Hi-Range" pre-Rev-B; Channel 3
                                              // is now the fixed 5V bootstrap supply, not
                                              // an adjustable output, but this AW9523 net
                                              // and its Q5/Q11 gate path are unchanged.
static const uint8_t AW95XX_P04_MASK = 0x10; // P0.4: ESP- GPIO 3V3 Low (Q4/Q10 path)
static const uint8_t AW95XX_P00_MASK = 0x01; // P0.0: ISET_MPU_5V -> Q3 gate path
static const uint8_t AW95XX_P05_MASK = 0x20; // P0.5: ISET_MPU_3V3 -> Q9 gate path
static const uint8_t AW95XX_P06_MASK = 0x40; // P0.6: input, FAULT_WARNING_SUM (schematic-confirmed)
static const uint8_t AW95XX_P07_MASK = 0x80; // P0.7: input, FAULT_CRITICAL_SUM (schematic-confirmed).
                                              // Same net also drives Q12's gate (via D14/R53,
                                              // pulled up through R50 to +5V_Boot) as a hardware
                                              // fault cutoff - Q12 is NOT independently
                                              // commandable from the AW9523; it only turns off
                                              // automatically when FAULT_CRITICAL_SUM trips.
static const uint8_t AW95XX_FAULT_SUM_INPUT_MASK = static_cast<uint8_t>(AW95XX_P06_MASK | AW95XX_P07_MASK);
static const uint8_t AW95XX_PIN_P0_0 = 0;
static const uint8_t AW95XX_PIN_P0_1 = 1;
static const uint8_t AW95XX_PIN_P0_2 = 2;
static const uint8_t AW95XX_PIN_P0_3 = 3;
static const uint8_t AW95XX_PIN_P0_4 = 4;
static const uint8_t AW95XX_PIN_P0_5 = 5;
static const uint8_t AW95XX_PIN_P0_6 = 6;
static const uint8_t AW95XX_PIN_P0_7 = 7;
static const uint8_t AW95XX_PIN_P1_0 = 8;
static const uint8_t INA3221_REG_CONFIG = 0x00;
static const uint8_t INA3221_REG_SHUNTVOLTAGE_1 = 0x01;
static const uint8_t INA3221_REG_BUSVOLTAGE_1 = 0x02;
static const uint16_t INA3221_CONFIG_CONTINUOUS = 0x7127;
static const uint8_t AHT20_CMD_SOFT_RESET = 0xBA;
static const uint8_t AHT20_CMD_INIT = 0xBE;
static const uint8_t AHT20_CMD_MEASURE = 0xAC;
static const uint8_t AHT20_STATUS_BUSY = 0x80;
static const uint8_t AHT20_STATUS_CALIBRATED = 0x08;

// W25Q128 commands (U11 external SPI flash)
static const uint8_t CMD_RDID = 0x9F;
static const uint8_t CMD_RDSR1 = 0x05;
static const uint8_t CMD_WREN = 0x06;
static const uint8_t CMD_SECTOR_ERASE_4K = 0x20;
static const uint8_t CMD_PAGE_PROGRAM = 0x02;
static const uint8_t CMD_READ_DATA = 0x03;

static const uint32_t FLASH_TEST_ADDR = 0x001000; // dedicated bring-up test sector
static const size_t FLASH_TEST_LEN = 32;
static const uint32_t FLASH_CFG_ADDR = 0x002000; // dedicated persistent-config sector
static const uint32_t W25Q_PAGE_SIZE = 256;
static const uint32_t FLASH_CFG_MAGIC = 0x43464731; // "CFG1"
static const uint16_t FLASH_CFG_VERSION = 1;

// ── Telemetry frame constants ──────────────────────────────────────────────
static const uint8_t FRAME_SOF1 = 0xAA;
static const uint8_t FRAME_SOF2 = 0x55;
static const uint8_t FRAME_TAG = 'T';
static const uint8_t FRAME_LEN = 13;
static const size_t FRAME_SIZE = 17;
static const uint32_t TELEMETRY_PERIOD_MS = 500;  // CrowPanel link goes STALE after 1500 ms
static const uint16_t CH1_ENABLED_MIN_MV = 1000;
static const uint16_t CH2_ENABLED_MIN_MV = 1000;
static const uint16_t CH1_OVP_THRESHOLD_MV = 5500;
static const uint16_t CH2_OVP_THRESHOLD_MV = 3600;
static const uint8_t OTP_THRESHOLD_C = 75;
static const uint8_t THERMAL_WARN_THRESHOLD_C = 70;
static const uint8_t STATUS_CH1_ENABLED_MASK = 0x80;
static const uint8_t STATUS_CH2_ENABLED_MASK = 0x40;
static const uint8_t STATUS_CH1_CV_MASK = 0x20;
static const uint8_t STATUS_CH2_CV_MASK = 0x10;
static const uint8_t STATUS_THERMAL_WARN_MASK = 0x08;
static const uint8_t PROT_CH1_OVP_MASK = 0x80;
static const uint8_t PROT_CH1_OCP_MASK = 0x40;
static const uint8_t PROT_CH2_OVP_MASK = 0x20;
static const uint8_t PROT_CH2_OCP_MASK = 0x10;
static const uint8_t PROT_CH1_OTP_MASK = 0x08;
static const uint8_t PROT_CH2_OTP_MASK = 0x04;
static const uint16_t UDI_CH1_LIMIT_MIN_MA = 0;
static const uint16_t UDI_CH1_LIMIT_MAX_MA = 3000;
static const uint16_t UDI_CH2_LIMIT_MIN_MA = 0;
static const uint16_t UDI_CH2_LIMIT_MAX_MA = 2000;
static const size_t UDI_MAX_LINE = 120;
static uint8_t frame_seq = 0;
static bool flash_test_passed = false;
static uint32_t flash_test_runs = 0;
static uint16_t g_sr_state = 0x0000;
static bool g_output_enabled = false;
static uint16_t g_current_limit_ch1_mA = 2500;
static uint16_t g_current_limit_ch2_mA = 1500;
static char g_udi_line_buf[UDI_MAX_LINE + 1] = {};
static size_t g_udi_line_len = 0;

struct RailCalibrationConfig {
  float voltage_gain;
  float voltage_offset_mV;
  float current_gain;
  float current_offset_mA;
};

struct PersistentConfigPayload {
  uint8_t d9_path_enabled;
  uint8_t reserved0;
  uint8_t reserved1;
  uint8_t reserved2;
  RailCalibrationConfig rail_5v;
  RailCalibrationConfig rail_3v3;
};

struct PersistentConfigRecord {
  uint32_t magic;
  uint16_t version;
  uint16_t payload_len;
  PersistentConfigPayload payload;
  uint32_t crc32;
};

enum ConfigRecoveryReason : uint8_t {
  CFGREC_UNKNOWN = 0,
  CFGREC_OK = 1,
  CFGREC_FLASH = 2,
  CFGREC_NOSIG = 3,
  CFGREC_VER = 4,
  CFGREC_LEN = 5,
  CFGREC_CRC = 6,
  CFGREC_GAIN = 7
};

static bool g_hb_print_enabled = false;
static volatile bool g_aw_int_pending = false;
static bool g_fault_sum_valid = false;
static bool g_fault_sum_active = false;
static bool g_fault_evt_valid = false;
static bool g_fault_evt_active = false;
static uint8_t g_fault_input_snapshot = 0x00;
static ConfigRecoveryReason g_cfg_recovery_reason = CFGREC_UNKNOWN;
static bool g_cfg_recovery_defaults = false;
static bool g_cfg_recovery_saved = false;

enum AwBootInitState : uint8_t {
  AW_BOOT_UNKNOWN = 0,
  AW_BOOT_SKIP = 1,
  AW_BOOT_PASS = 2,
  AW_BOOT_HOLD = 3
};

static AwBootInitState g_aw_boot_state = AW_BOOT_UNKNOWN;

static Adafruit_AW9523 g_aw;
static bool g_aw_inited = false;

struct Aht20Sample {
  bool valid;
  float temp_C;
  float humidity_pct;
  uint8_t status;
};

struct Ina3221ChannelReading {
  uint16_t raw_shunt;
  uint16_t raw_bus;
  float bus_V;
  float shunt_mV;
  float current_mA;
};

struct Ina3221Reading {
  uint8_t address;
  bool present;
  Ina3221ChannelReading channel[3];
};

struct IncomingRailSample {
  bool valid;
  float bus_V;
  float current_mA;
};

Aht20Sample g_aht20 = {false, 0.0f, 0.0f, 0};
IncomingRailSample g_incoming_rail = {false, 0.0f, 0.0f};
PersistentConfigPayload g_config = {};

bool runFlashBringupTest();
bool readAht20Now(Aht20Sample& out);
bool readIna3221(uint8_t address, Ina3221Reading& out, bool configure = true);
bool refreshIncomingRailSample();
void runShiftRegisterSelfTest();
void logHealthSummary();
void flashD9Led(uint8_t blinks, uint16_t on_ms, uint16_t off_ms);
void setD9PathEnabled(bool enabled);
void resetPersistentConfigDefaults();
bool savePersistentConfig(bool verbose);
bool loadPersistentConfig(bool verbose);
bool erasePersistentConfig(bool verbose);
char configRecoveryReasonCode(ConfigRecoveryReason reason);
void initPersistentConfigAtBoot();
void printPersistentConfig();
void pollUdiCommands();
void setRangePairEnabled(uint8_t bit, const char* label, bool enabled);
void setQ3OnlyEnabled(bool enabled);
void setQ9OnlyEnabled(bool enabled);
void setAwP0GatePathEnabled(uint8_t mask, uint8_t pin, const char* label, bool enabled);
void setQ1PathEnabled(bool enabled);
void setQ2PathEnabled(bool enabled);
void setQ4PathEnabled(bool enabled);
void setQ5PathEnabled(bool enabled);
void runQ9ElectricalDiagnostic();
void printRangePairStates();
void runRangePairSequence();
void captureRangeSequenceSnapshot(const char* step);
void runAwP10Heartbeat(uint8_t blinks, uint16_t on_ms, uint16_t off_ms);
bool aw95xxSetP0MaskOutputMode(uint8_t mask);
bool aw95xxWriteP0Mask(uint8_t mask, bool high, uint8_t& out_after);
bool aw95xxEnsureGpioPushPull();
void aw95xxPrintModeRegs();
bool aw95xxEnsureDriver();
void logAwP0MaskElectricalState(const char* tag, uint8_t mask, bool expected_high);
void aw95xxBootInit();
const char* awBootStateString();
bool is3v3PathEnabled();
bool isFaultCriticalActive();
void onAw9523Interrupt();
void serviceAw9523FaultPath();
bool sampleFaultSumFromAw9523();

void logBoth(const char* msg) {
  Serial.println(msg);
  SerialDbg.println(msg);
}

void onAw9523Interrupt() {
  g_aw_int_pending = true;
}

void formatAhtValues(const Aht20Sample& sample,
                     int32_t& t_whole,
                     int32_t& t_frac,
                     int32_t& h_whole,
                     int32_t& h_frac) {
  const int32_t t_centi = static_cast<int32_t>(sample.temp_C * 100.0f);
  const int32_t h_centi = static_cast<int32_t>(sample.humidity_pct * 100.0f);
  t_whole = t_centi / 100;
  t_frac = t_centi >= 0 ? (t_centi % 100) : -(t_centi % 100);
  h_whole = h_centi / 100;
  h_frac = h_centi >= 0 ? (h_centi % 100) : -(h_centi % 100);
}

void formatFixedValue(float value, uint32_t scale, uint8_t digits, char* out, size_t out_len) {
  const bool negative = value < 0.0f;
  const float abs_value = negative ? -value : value;
  const uint32_t scaled = static_cast<uint32_t>(abs_value * static_cast<float>(scale) + 0.5f);
  const uint32_t whole = scaled / scale;
  const uint32_t frac = scaled % scale;

  snprintf(out,
           out_len,
           "%s%lu.%0*lu",
           negative ? "-" : "",
           static_cast<unsigned long>(whole),
           static_cast<int>(digits),
           static_cast<unsigned long>(frac));
}

void formatVoltageValue(float value, char* out, size_t out_len) {
  formatFixedValue(value, 1000, 3, out, out_len);
}

void formatCurrentValue(float value, char* out, size_t out_len) {
  formatFixedValue(value, 100, 2, out, out_len);
}

bool parseFloatToken(const char* token, float& out_value) {
  if (token == nullptr || *token == '\0') {
    return false;
  }

  size_t i = 0;
  bool negative = false;
  if (token[i] == '+' || token[i] == '-') {
    negative = token[i] == '-';
    ++i;
  }

  uint32_t whole = 0;
  uint32_t frac = 0;
  uint32_t frac_div = 1;
  bool has_digit = false;
  bool seen_dot = false;

  for (; token[i] != '\0'; ++i) {
    const char ch = token[i];
    if (ch == '.') {
      if (seen_dot) {
        return false;
      }
      seen_dot = true;
      continue;
    }
    if (ch < '0' || ch > '9') {
      return false;
    }

    has_digit = true;
    const uint8_t digit = static_cast<uint8_t>(ch - '0');
    if (!seen_dot) {
      whole = (whole * 10u) + digit;
    } else {
      // Limit precision to keep arithmetic bounded and predictable.
      if (frac_div < 1000000u) {
        frac = (frac * 10u) + digit;
        frac_div *= 10u;
      }
    }
  }

  if (!has_digit) {
    return false;
  }

  out_value = static_cast<float>(whole) +
              (frac_div > 1u ? static_cast<float>(frac) / static_cast<float>(frac_div) : 0.0f);
  if (negative) {
    out_value = -out_value;
  }
  return true;
}

bool parseCalsetCommand(const String& cmd,
                        char* rail_token,
                        size_t rail_token_len,
                        float& v_gain,
                        float& v_off_mV,
                        float& i_gain,
                        float& i_off_mA) {
  if (rail_token == nullptr || rail_token_len == 0) {
    return false;
  }

  char line[UDI_MAX_LINE + 1] = {0};
  strncpy(line, cmd.c_str(), UDI_MAX_LINE);
  line[UDI_MAX_LINE] = '\0';

  char* ctx = nullptr;
  char* token = strtok_r(line, " ", &ctx);
  if (token == nullptr || strcmp(token, "CALSET") != 0) {
    return false;
  }

  const char* rail = strtok_r(nullptr, " ", &ctx);
  const char* vg = strtok_r(nullptr, " ", &ctx);
  const char* vo = strtok_r(nullptr, " ", &ctx);
  const char* ig = strtok_r(nullptr, " ", &ctx);
  const char* io = strtok_r(nullptr, " ", &ctx);
  const char* extra = strtok_r(nullptr, " ", &ctx);

  if (rail == nullptr || vg == nullptr || vo == nullptr || ig == nullptr || io == nullptr || extra != nullptr) {
    return false;
  }

  strncpy(rail_token, rail, rail_token_len - 1);
  rail_token[rail_token_len - 1] = '\0';

  return parseFloatToken(vg, v_gain) &&
         parseFloatToken(vo, v_off_mV) &&
         parseFloatToken(ig, i_gain) &&
         parseFloatToken(io, i_off_mA);
}

float applyVoltageCalibration(float raw_bus_v, const RailCalibrationConfig& cal) {
  const float raw_mV = raw_bus_v * 1000.0f;
  const float corrected_mV = (raw_mV * cal.voltage_gain) + cal.voltage_offset_mV;
  return corrected_mV / 1000.0f;
}

float applyCurrentCalibration(float raw_mA, const RailCalibrationConfig& cal) {
  return (raw_mA * cal.current_gain) + cal.current_offset_mA;
}

const RailCalibrationConfig& calibrationForRail(uint8_t address) {
  if (address == INA3221_ADDR_5V) {
    return g_config.rail_5v;
  }
  return g_config.rail_3v3;
}

uint32_t crc32(const uint8_t* data, size_t len) {
  uint32_t crc = 0xFFFFFFFFu;
  for (size_t i = 0; i < len; ++i) {
    crc ^= static_cast<uint32_t>(data[i]);
    for (uint8_t bit = 0; bit < 8; ++bit) {
      const uint32_t mask = 0u - (crc & 1u);
      crc = (crc >> 1) ^ (0xEDB88320u & mask);
    }
  }
  return ~crc;
}

void printCommandHelp() {
  logBoth("cmd: HELP/DIAG/FTEST/AHT*/SR*/D9*/INA*/CAL*/CFG*/AW*");
  logBoth("udi: CMD:OUTPUT|ILIM|GET*");
}

bool i2cPing(uint8_t address) {
  Wire.beginTransmission(address);
  return Wire.endTransmission() == 0;
}

bool i2cWriteReg16(uint8_t address, uint8_t reg, uint16_t value) {
  Wire.beginTransmission(address);
  Wire.write(reg);
  Wire.write(static_cast<uint8_t>((value >> 8) & 0xFF));
  Wire.write(static_cast<uint8_t>(value & 0xFF));
  return Wire.endTransmission() == 0;
}

bool i2cWriteReg8(uint8_t address, uint8_t reg, uint8_t value) {
  Wire.beginTransmission(address);
  Wire.write(reg);
  Wire.write(value);
  return Wire.endTransmission() == 0;
}

bool i2cReadReg8(uint8_t address, uint8_t reg, uint8_t& value) {
  Wire.beginTransmission(address);
  Wire.write(reg);
  if (Wire.endTransmission(false) != 0) {
    return false;
  }
  if (Wire.requestFrom(static_cast<int>(address), 1) != 1) {
    return false;
  }
  value = static_cast<uint8_t>(Wire.read());
  return true;
}

bool i2cReadReg16(uint8_t address, uint8_t reg, uint16_t& value) {
  Wire.beginTransmission(address);
  Wire.write(reg);
  if (Wire.endTransmission(false) != 0) {
    return false;
  }
  if (Wire.requestFrom(static_cast<int>(address), 2) != 2) {
    return false;
  }
  value = (static_cast<uint16_t>(Wire.read()) << 8) | static_cast<uint16_t>(Wire.read());
  return true;
}
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
void loop() {
  pollCommands();
  serviceAw9523FaultPath();

  static uint32_t lastMs = 0;
  static uint32_t lastSummaryMs = 0;
  uint32_t now = millis();

  if (now - lastMs >= 5000) {
    lastMs = now;
    digitalWrite(PIN_STATUS_LED, LOW);
    delay(40);
    digitalWrite(PIN_STATUS_LED, HIGH);

    refreshIncomingRailSample();

    if (g_hb_print_enabled) {
      Serial.println("hb");
      SerialDbg.println("hb");

      if (g_incoming_rail.valid) {
        char ina_hb_msg[96];
        char vin[16], iin[16];
        formatVoltageValue(g_incoming_rail.bus_V, vin, sizeof(vin));
        formatCurrentValue(g_incoming_rail.current_mA, iin, sizeof(iin));
        snprintf(ina_hb_msg,
                 sizeof(ina_hb_msg),
                 "ina hb: Vin=%sV Iin=%smA",
                 vin,
                 iin);
        logBoth(ina_hb_msg);
      } else {
        logBoth("ina hb: HOLD");
      }

      if (!flash_test_passed) {
        Serial.println("flash: HOLD (bring-up test failed)");
        SerialDbg.println("flash: HOLD (bring-up test failed)");
      }
    }
  }

  static uint32_t lastTelemetryMs = 0;
  if (now - lastTelemetryMs >= TELEMETRY_PERIOD_MS) {
    lastTelemetryMs = now;

    // Publish live telemetry from INA3221 rails when available.
    Ina3221Reading ina_5v = {};
    Ina3221Reading ina_3v3 = {};
    const bool ok_5v = readIna3221(INA3221_ADDR_5V, ina_5v);
    const bool ok_3v3 = readIna3221(INA3221_ADDR_3V3, ina_3v3);

    const auto clampU16 = [](float value, uint16_t fallback) -> uint16_t {
      if (value < 0.0f) return fallback;
      if (value > 65535.0f) return 65535;
      return static_cast<uint16_t>(value + 0.5f);
    };
    const auto clampI16 = [](float value, int16_t fallback) -> int16_t {
      if (value < -32768.0f || value > 32767.0f) return fallback;
      return static_cast<int16_t>(value + (value >= 0.0f ? 0.5f : -0.5f));
    };

    float v5_bus = 5.0f;
    float i5_bus = 500.0f;
    float v3v3_bus = 3.3f;
    float i3v3_bus = 320.0f;
    if (ok_5v) {
      const RailCalibrationConfig& cal = calibrationForRail(INA3221_ADDR_5V);
      v5_bus = applyVoltageCalibration(ina_5v.channel[0].bus_V, cal);
      i5_bus = applyCurrentCalibration(ina_5v.channel[0].current_mA, cal);
    }
    if (ok_3v3) {
      const RailCalibrationConfig& cal = calibrationForRail(INA3221_ADDR_3V3);
      v3v3_bus = applyVoltageCalibration(ina_3v3.channel[0].bus_V, cal);
      i3v3_bus = applyCurrentCalibration(ina_3v3.channel[0].current_mA, cal);
    }

    const uint16_t v5_mV = clampU16(v5_bus * 1000.0f, 5000);
    const int16_t i5_mA = clampI16(i5_bus, 500);
    const uint16_t v3v3_mV = clampU16(v3v3_bus * 1000.0f, 3300);
    const int16_t i3v3_mA = clampI16(i3v3_bus, 320);
    const uint8_t temp_C = g_aht20.valid
        ? static_cast<uint8_t>(constrain(static_cast<int>(g_aht20.temp_C + 0.5f), 0, 125))
        : 31;
    const bool ch1_enabled = g_output_enabled && ok_5v && (v5_mV >= CH1_ENABLED_MIN_MV);
    const bool ch2_enabled = g_output_enabled && ok_3v3 && is3v3PathEnabled() && (v3v3_mV >= CH2_ENABLED_MIN_MV);
    const bool ch1_cc = static_cast<uint16_t>(abs(i5_mA)) >= g_current_limit_ch1_mA;
    const bool ch2_cc = static_cast<uint16_t>(abs(i3v3_mA)) >= g_current_limit_ch2_mA;
    const bool thermal_warn = temp_C >= THERMAL_WARN_THRESHOLD_C;
    const bool ch1_ovp = ok_5v && (v5_mV >= CH1_OVP_THRESHOLD_MV);
    const bool ch2_ovp = ok_3v3 && (v3v3_mV >= CH2_OVP_THRESHOLD_MV);
    const bool otp_trip = temp_C >= OTP_THRESHOLD_C;
    const bool ocp_observable = (PIN_FAULT_CRITICAL_SUM >= 0) || g_fault_sum_valid;
    const bool ocp_sum_trip = ocp_observable && isFaultCriticalActive();

    uint8_t status = 0x00;
    status |= ch1_enabled ? STATUS_CH1_ENABLED_MASK : 0x00u;
    status |= ch2_enabled ? STATUS_CH2_ENABLED_MASK : 0x00u;
    status |= (!ch1_cc) ? STATUS_CH1_CV_MASK : 0x00u;
    status |= (!ch2_cc) ? STATUS_CH2_CV_MASK : 0x00u;
    status |= thermal_warn ? STATUS_THERMAL_WARN_MASK : 0x00u;

    uint8_t protection_flags = 0x00;
    protection_flags |= ch1_ovp ? PROT_CH1_OVP_MASK : 0x00u;
    protection_flags |= ch2_ovp ? PROT_CH2_OVP_MASK : 0x00u;
    // Rev-C currently only exposes a single FAULT_CRITICAL_SUM line (and that line
    // is unrouted on current netlist), so OCP is represented as a shared trip when
    // observable and active.
    protection_flags |= ocp_sum_trip ? PROT_CH1_OCP_MASK : 0x00u;
    protection_flags |= ocp_sum_trip ? PROT_CH2_OCP_MASK : 0x00u;
    // OTP comes from one board-level thermal source today; assert both channel OTP
    // bits so the display can treat it as a global thermal protection event.
    protection_flags |= otp_trip ? PROT_CH1_OTP_MASK : 0x00u;
    protection_flags |= otp_trip ? PROT_CH2_OTP_MASK : 0x00u;
    publishTelemetry(v5_mV, i5_mA, v3v3_mV, i3v3_mA, temp_C, status, protection_flags);
  }

  if (now - lastSummaryMs >= 60000) {
    lastSummaryMs = now;
    Aht20Sample periodic_sample;
    if (readAht20Now(periodic_sample)) {
      g_aht20 = periodic_sample;
    }
    refreshIncomingRailSample();
    logHealthSummary();
  }
}

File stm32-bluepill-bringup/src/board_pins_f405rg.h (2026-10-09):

#pragma once

#include <Arduino.h>

// Rev-D assignments from docs/HAT_REVD_PIN_AND_SUPPORT_CONTRACT.md.
static constexpr uint8_t PIN_DEBUG_RX = PB7;
static constexpr uint8_t PIN_DEBUG_TX = PB6;
static constexpr uint8_t PIN_UDI_RX = PB11;
static constexpr uint8_t PIN_UDI_TX = PB10;
static constexpr uint8_t PIN_C3_UART_RX = PC11;
static constexpr uint8_t PIN_C3_UART_TX = PC10;
static constexpr uint8_t PIN_C3_EN_N = PC0;
static constexpr uint8_t PIN_C3_BOOT_N = PC1;
static constexpr uint8_t PIN_USB_VBUS_SENSE = PA9;
static constexpr uint8_t PIN_USB_DM = PA11;
static constexpr uint8_t PIN_USB_DP = PA12;

static constexpr int8_t PIN_ISET_5V = PA0;
static constexpr int8_t PIN_ISET_3V3 = PA1;
// Rev-D has no CH3 MCU control; PA2 is a free spare.
static constexpr int8_t PIN_ISET_CH3 = -1;
static constexpr int8_t PIN_FAULT_CRITICAL_SUM = -1;
static constexpr uint8_t PIN_AW9523_INT = PC4;
static constexpr uint8_t PIN_STATUS_LED = PC13;
static constexpr uint8_t PIN_FLASH_CS = PA8;
static constexpr uint8_t PIN_SR_LATCH = PA4;
static constexpr uint8_t I2C_SCL_PIN = PB8;
static constexpr uint8_t I2C_SDA_PIN = PB9;

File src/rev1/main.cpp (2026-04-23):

#include <Arduino.h>
#include <math.h>
#include <Wire.h>
#include <SPI.h>
#include <TFT_eSPI.h>
#include <esp_system.h>
#include <Preferences.h>
#include <freertos/FreeRTOS.h>
#include <freertos/task.h>
#include "power_telemetry_map.h"

SDL_Arduino_INA3221 ina3221;
TFT_eSPI display = TFT_eSPI();
HatPowerTelemetry hatTelemetry(ina3221);
Preferences prefs;

constexpr uint8_t STATUS_LED_PIN = 2;
constexpr uint8_t MCP4231_CS_PIN = 5;
#if defined(I2C_SDA_GPIO)
constexpr uint8_t I2C_SDA_PIN = I2C_SDA_GPIO;
#else
constexpr uint8_t I2C_SDA_PIN = 21;
#endif

#if defined(I2C_SCL_GPIO)
constexpr uint8_t I2C_SCL_PIN = I2C_SCL_GPIO;
#else
constexpr uint8_t I2C_SCL_PIN = 22;
#endif
constexpr uint8_t INA3221_ADDR_MIN = 0x40;
constexpr uint8_t INA3221_ADDR_MAX = 0x43;

#if defined(TFT_SCLK)
constexpr int SPI_SCLK_PIN = TFT_SCLK;
#else
constexpr int SPI_SCLK_PIN = 18;
#endif

#if defined(TFT_MISO)
constexpr int SPI_MISO_PIN = TFT_MISO;
#else
constexpr int SPI_MISO_PIN = 19;
#endif

#if defined(TFT_MOSI)
constexpr int SPI_MOSI_PIN = TFT_MOSI;
#else
constexpr int SPI_MOSI_PIN = 23;
#endif

#if defined(MCP4231_SDI_PIN)
constexpr int MCP4231_DATA_PIN = MCP4231_SDI_PIN;
#else
constexpr int MCP4231_DATA_PIN = SPI_MOSI_PIN;
#endif

#if defined(MCP4231_SCK_PIN)
constexpr int MCP4231_CLOCK_PIN = MCP4231_SCK_PIN;
#else
constexpr int MCP4231_CLOCK_PIN = SPI_SCLK_PIN;
#endif

#if defined(TFT_HW_RST)
constexpr int TFT_RESET_PIN = TFT_HW_RST;
#elif defined(TFT_RST)
constexpr int TFT_RESET_PIN = TFT_RST;
#else
constexpr int TFT_RESET_PIN = -1;
#endif

#if defined(TFT_RST_ACTIVE_LOW)
constexpr bool TFT_RESET_ACTIVE_LOW = (TFT_RST_ACTIVE_LOW != 0);
#else
constexpr bool TFT_RESET_ACTIVE_LOW = true;
#endif

bool ledState = false;
uint32_t lastFrameMs = 0;
uint32_t loopCounter = 0;
bool tftInitialized = false;
bool tftWriteOnlyReady = false;
bool tftWriteOnlyDashboardInitialized = false;

enum class TftInitState : uint8_t {
  Idle,
  Running,
  Done,
  Failed
};

volatile TftInitState tftInitState = TftInitState::Idle;
volatile bool tftInitResult = false;
TaskHandle_t tftInitTaskHandle = nullptr;

constexpr bool AUTO_TFT_INIT = true;
constexpr bool AUTO_TFT_WRITE_ONLY = true;
constexpr bool TFT_WRITE_ONLY_ROTATE_90 = true;
#if defined(TFT_VERBOSE_BOOT)
constexpr bool BOOT_LOG_VERBOSE = true;
#else
constexpr bool BOOT_LOG_VERBOSE = false;
#endif
constexpr const char* PROJECT_PATH = "c:/Users/user/Esp32 projects VScode/WorkStation";
constexpr const char* PROJECT_ENV = "esp32dev";

float ch3VoltageScale = 1.00f;
float ch3CurrentScale = 1.00f;
uint8_t mcpWiperCached[2] = {128, 128};
bool autoRangeEnabled = true;
float autoRangeLowThresholdmA = 250.0f;
float autoRangeHighThresholdmA = 900.0f;

enum class OperationMode : uint8_t {
  Normal = 0,
  CurrentLimit = 1
};

OperationMode operationMode = OperationMode::Normal;
volatile uint8_t tftRequestedOperationMode = static_cast<uint8_t>(OperationMode::Normal);

enum class CurrentLimitMode : uint8_t {
  LatchOff = 0,
  Hiccup = 1,
  Monitor = 2
};

struct RailCurrentLimitConfig {
  uint8_t enabled;
  float isetmA;
  float icutmA;
  float hysteresismA;
  uint8_t mode;
  uint16_t tripDelayMs;
  uint16_t retryDelayMs;
};

struct RailCurrentLimitState {
  bool inCc;
  bool tripped;
  uint32_t overStartMs;
  uint32_t tripMs;
  uint32_t lastWarnMs;
};

constexpr uint32_t PERSIST_VERSION = 5;
constexpr const char* PERSIST_NAMESPACE = "hatpsu";
constexpr size_t PERSIST_RAIL_COUNT = static_cast<size_t>(HatRail::Count);
constexpr size_t PERSIST_RANGE_COUNT = 3;

struct PersistentConfig {
  uint32_t version;
  uint8_t autoRangeEnabled;
  uint8_t operationMode;
  float lowThresholdmA;
  float highThresholdmA;
  RailCalibration cal[PERSIST_RAIL_COUNT][PERSIST_RANGE_COUNT];
  float shuntOhms[PERSIST_RAIL_COUNT][PERSIST_RANGE_COUNT];
  RailCurrentLimitConfig currentLimit[PERSIST_RAIL_COUNT];
};

RailCurrentLimitConfig railCurrentLimit[PERSIST_RAIL_COUNT] = {};
RailCurrentLimitState railCurrentState[PERSIST_RAIL_COUNT] = {};

constexpr uint32_t CURRENT_LIMIT_UPDATE_MS = 100;
uint32_t lastCurrentLimitUpdateMs = 0;

// Per-rail hardware output enable hooks for a future board revision.
constexpr int RAIL5V_ENABLE_PIN = -1;
constexpr int RAIL3V3_ENABLE_PIN = -1;
constexpr int RAILADJ_ENABLE_PIN = -1;
constexpr bool RAIL5V_ENABLE_ACTIVE_HIGH = true;
constexpr bool RAIL3V3_ENABLE_ACTIVE_HIGH = true;
constexpr bool RAILADJ_ENABLE_ACTIVE_HIGH = true;

// HMI UART state: per-rail software enable tracking and RailAdj voltage selection.
// These mirror intended hardware state when GPIO pins are not yet assigned.
static bool hmiRailEnabled[3] = {false, false, false};
static bool hmiRailAdjIs5V = true;  // true = 5V selected, false = 3V3 selected

#if defined(TFT_WIDTH)
constexpr uint16_t TFT_PANEL_WIDTH = TFT_WIDTH;
#else
constexpr uint16_t TFT_PANEL_WIDTH = 320;
#endif

#if defined(TFT_HEIGHT)
constexpr uint16_t TFT_PANEL_HEIGHT = TFT_HEIGHT;
#else
constexpr uint16_t TFT_PANEL_HEIGHT = 480;
#endif

constexpr uint16_t TFT_LOGICAL_WIDTH = TFT_WRITE_ONLY_ROTATE_90 ? TFT_PANEL_HEIGHT : TFT_PANEL_WIDTH;
constexpr uint16_t TFT_LOGICAL_HEIGHT = TFT_WRITE_ONLY_ROTATE_90 ? TFT_PANEL_WIDTH : TFT_PANEL_HEIGHT;

struct BootStatus {
  bool uartOk;
  bool tftOk;
  bool tftIdOk;
  bool i2cOk;
  bool inaOk;
  bool inaRwOk;
  bool mcpOk;
  bool touchOk;
  float inaRailVoltage;
  uint8_t inaAddress;
  uint8_t i2cCount;
  uint32_t tftId;
};

BootStatus bootStatus = {false, false, false, false, false, false, false, false, NAN, 0x00, 0, 0};

static const char* resetReasonText(esp_reset_reason_t reason) {
  switch (reason) {
    case ESP_RST_POWERON: return "POWERON";
    case ESP_RST_EXT: return "EXTERNAL_PIN";
    case ESP_RST_SW: return "SOFTWARE";
    case ESP_RST_PANIC: return "PANIC";
    case ESP_RST_INT_WDT: return "INT_WDT";
    case ESP_RST_TASK_WDT: return "TASK_WDT";
    case ESP_RST_WDT: return "OTHER_WDT";
    case ESP_RST_DEEPSLEEP: return "DEEPSLEEP";
    case ESP_RST_BROWNOUT: return "BROWNOUT";
    case ESP_RST_SDIO: return "SDIO";
    default: return "UNKNOWN";
  }
}

static const char* activeTftDriverText() {
#if defined(ST7796_DRIVER)
  return "ST7796";
#elif defined(ILI9488_DRIVER)
  return "ILI9488";
#elif defined(ILI9486_DRIVER)
  return "ILI9486";
#else
  return "UNKNOWN";
#endif
}

static const char* currentLimitModeName(CurrentLimitMode mode) {
  switch (mode) {
    case CurrentLimitMode::LatchOff: return "LATCH";
    case CurrentLimitMode::Hiccup: return "HICCUP";
    default: return "MONITOR";
  }
}

static const char* operationModeName(OperationMode mode) {
  return (mode == OperationMode::CurrentLimit) ? "CURRENT_LIMIT" : "NORMAL";
}
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

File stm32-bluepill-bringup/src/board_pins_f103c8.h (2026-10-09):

#pragma once

#include <Arduino.h>

// Rev-C F103 assignments from docs/STM32_BLUEPILL_PIN_TABLE.md.
static constexpr uint8_t PIN_DEBUG_RX = PA10;
static constexpr uint8_t PIN_DEBUG_TX = PA9;
static constexpr uint8_t PIN_UDI_RX = PB11;
static constexpr uint8_t PIN_UDI_TX = PB10;

static constexpr int8_t PIN_ISET_5V = PA0;
static constexpr int8_t PIN_ISET_3V3 = PA1;
// Rev-C has no CH3 MCU control; PA2/PA3 are the C3 link pair.
static constexpr int8_t PIN_ISET_CH3 = -1;
static constexpr int8_t PIN_FAULT_CRITICAL_SUM = -1;
static constexpr uint8_t PIN_AW9523_INT = PB7;
static constexpr uint8_t PIN_STATUS_LED = PC13;
static constexpr uint8_t PIN_FLASH_CS = PA8;
static constexpr uint8_t PIN_SR_LATCH = PA4;
static constexpr uint8_t I2C_SCL_PIN = PB8;
static constexpr uint8_t I2C_SDA_PIN = PB9;

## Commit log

2026-03-25 Update README with current status and pinout details
    Added current status and pinout information for the display board.
2026-03-25 Create pinout documentation for ESP32-C6 display board
    Added authoritative pinout documentation for ESP32-C6 display board, including wiring and firmware pin definitions.
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2026-03-28 Organize new display-board KiCad files into hardware/docs layout
    [Front display board.kicad_sch]
2026-03-28 Organize DSP regulator KiCad projects into hardware/kicad structure
    [DSP Regulator.kicad_pcb before auto route.kicad_pcb, DSP Regulator.kicad_sch, DSP Regulator.kicad_sch_before hat.kicad_sch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]
2026-03-28 Organize USB hub KiCad project into hardware/kicad structure
    [USB Hub.kicad_sch]
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2026-03-29 Add per-tap shunt resistance config; fix current measurement for dual-range channels
    - InaTap now carries shuntOhms (HIGH=0.100 Ohm, LOW=0.010 Ohm, 12V=0.010 Ohm defaults)
    - readCurrentmA() uses tap-specific shunt voltage / shuntOhms instead of shared library field
    - setShuntOhms() / shuntOhms() / printShuntConfig() added to HatPowerTelemetry
    - tapRef() private helper for mutable InaTap access
    - NVS schema bumped to v2: shuntOhms[4][3] added to PersistentConfig
    - SHUNT <rail> <range> <ohms>: set per-tap shunt resistor value
    - SHUNTSHOW: print all shunt values
    - CFGSHOW: print autorange state, thresholds, all shunts, all calibration
    - CFGRESET now restores default shunts via setInaAddresses()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
    [main.cpp, power_telemetry_map.h]
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2026-03-29 Add per-rail current-limit protection state machine with NVS persistence
    - Add Iset/Icut/hysteresis config per rail
    - Add modes: LATCH, HICCUP, MONITOR
    - Add trip delay and hiccup retry timers
    - Add runtime CC/trip state tracking and periodic protection update loop
    - Add optional rail enable-pin hooks for future hardware control
    - Add serial commands: CLENABLE, CLSET, CLMODE, CLDELAY, CLSTAT, CLCLEAR
    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
2026-03-29 Add NORMAL/CURRENT_LIMIT operation modes with TFT mode hook
    - Add OperationMode state (NORMAL, CURRENT_LIMIT) with NVS persistence (v5)
    - Add MODE command and include mode in CFGSHOW/HELP
    - Current-limit mode now starts from HIGH range and auto-ranges from measured current
    - Normal mode uses fixed HIGH range and clears active CL runtime state
    - Add tftRequestedOperationMode variable and loop sync hook for panel-driven mode selection
    - Add HatPowerTelemetry::resetActiveRangesToHigh() helper
    [main.cpp, power_telemetry_map.h]
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2026-04-12 Add missing front-display and USB hub PCB files
    [Front display board.kicad_pcb, USB Hub.kicad_pcb]
2026-04-12 Create usb-hub next-iteration workspace and fix 12V net label alias
    [USB Hub Next Iter.kicad_pcb, USB Hub Next Iter.kicad_sch]
2026-04-12 Revert "Add files via upload"
    This reverts commit 9727bb8fcf1ad0520ca163fc3fe7730c7a9ac76a.
    [USB Hub.kicad_pcb, USB Hub.kicad_sch]
2026-04-12 usb-hub next-iter: add PWR_FLAGs and clear power-pin ERC issues
    [USB Hub Next Iter.kicad_sch]
2026-04-12 usb-hub next-iter: resolve SCH-002 and clear PCB silk overlaps
    [USB Hub Next Iter.kicad_pcb]
2026-04-14 usb-hub tracker: correct PCB-002 to resolved, PCB-003 count to 14, revhistory from JSON files
2026-04-14 usb-hub tracker: close all remaining items as Won't Fix (as-built board, no further changes this revision)
2026-04-14 usb-hub tracker: mark superseded — full redesign with new components planned
2026-04-14 usb-hub tracker: files are starting point for redesign and PCB bring-up reference
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2026-04-19 Add display_main.cpp for ESP32-C6 front display board initialization
    - Implemented display initialization sequence for ST7796 panel
    - Added color test functionality to verify display operation
    - Configured GPIO pins for display control and backlight management
    - Established communication with the display using Arduino_GFX library
    - Included hardware reset and software reset procedures in setup
    - Display shows "Ready - waiting for host" after initialization
    [display_main.cpp, main.cpp]
2026-04-19 Document display-board breakpoint and preserve minimal C6 TFT baseline
    # Conflicts:
    # .gitignore
2026-04-23 Add CMD: HMI UART command handler stubs
    - handleHmiCommand(): parses CMD:<ACTION> key=value frames (uppercased)
    - CMD:READ_STATUS: returns state/mode/per-rail V+I/r2_sel, fault code
    - CMD:RAIL_ENABLE: sets hmiRailEnabled[], calls setRailOutputEnabled()
    - CMD:RAIL_VOLT_SEL: guards rail-on interlock, updates hmiRailAdjIs5V
    - CMD:SET_MODE: calls applyOperationMode()
    - CMD:RESET: clears all CL trip state, rejects when not in fault
    - CMD:ABORT: disables all rails unconditionally
    - Added CMD: branch at top of handleSerialCommands(); raw commands unchanged
    - hmiRailEnabled[3] and hmiRailAdjIs5V tracking globals added
    - Relay GPIO for RAIL_VOLT_SEL marked TODO (expander not yet wired)
    [main.cpp]
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2026-05-27 2026-05-27: Display interface complete + session docs cleanup
    HAT Rev-B schematic:
    - Added J21 (JST XH B4B-XH-A 4-pin LCSC C144394) as display UART connector
    - Removed I2C_1: deleted J14/J15 headers; repurposed R78/R79 to 33-ohm UART series resistors
    - PB10 (U10 pin 35) -> DISP_UART_TX, PB11 (pin 36) -> DISP_UART_RX (USART3)
    - ERC: 0 errors / 0 warnings; netlist re-exported 07:48:36
    - verify-connector-contract.ps1 -Mode reduced: 18/18 PASS
    - Initial commit of dsp-regulator-hat-rev-b KiCad files (was gitignored by overly broad pattern)
    - Fixed .gitignore: **/KiCad/ -> /KiCad/ (was matching hardware/kicad/ on Windows)
    Documentation (this session):
    - Created docs/DISPLAY_INTERFACE_STANDARD.md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
    [DSP Regulator_hat.kicad_sch, DSP-Regulator-HAT-RevB.kicad_sch]
2026-05-31 firmware: enable C6<->CrowPanel UART link and display bring-up baseline
    [partitions.csv]
2026-07-02 Closeout handoff and checkpoint PCB/netlist updates
    [DSP-Regulator-HAT-RevB.kicad_pcb, DSP-Regulator-HAT-RevB.kicad_sch, DSP-Regulator-RevB.kicad_pcb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]
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2026-07-02 Finalize Rev-B pre-fab review
    [DSP-Regulator-HAT-RevB.kicad_pcb, DSP-Regulator-HAT-RevB.kicad_sch, DSP-Regulator-RevB.kicad_pcb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]
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2026-07-03 Phase 5a UI Skeleton: Fixed variable naming for dual-channel display
    - Fixed bar_main_ch1_ch1_voltage/current double-naming errors
    - All references updated to use ch1/ch2 variant names
    - Build now compiles successfully (589KB firmware, 3.5% flash usage)
    - Compilation verified: exit code 0
    Phase 5a Status: COMPLETE
    - Setup screen with parameter editing template (7 params)
    - Settings screen with System/DataSet/About panels
    - Updated boot sequence: Splash(1.8s) → Setup(30s) → Main
    - Demo tour cycles through all 5 screens
    - Ready for hardware validation
    [main.cpp]
2026-07-27 Enable UART0 replacement-panel bring-up baseline
    [disp_link_slave.cpp, main.cpp]
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2026-08-10 Add 2026-08-10 handoff and capture STM32/board debug state
    [DSP-Regulator-HAT-RevB.kicad_pcb, DSP-Regulator-RevB.kicad_sch]
2026-08-10 Capture VSENSE selector issue, SPICE validation, and pre-RevC routing blocker
    [5v_reg_selector_fault_sweep.csv, 5v_reg_selector_sweep.csv, DSP-Regulator-HAT-RevB.kicad_sch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]
2026-08-12 RB-011: Add 3.3V selector/reference SPICE model with root cause findings
    - hardware/sim/3v3_reg_selector_ref_v2.cir: DC sweep model for 3.3V
    feedback path (D5K, R25, U6A/U6B, BAT54C, LM2596 divider)
    - SPICE confirms R25 is the sole DC return path for LM2596 feedback:
    Case A (R25=10Ohm): V_OUT = 3.309V [bench 3.335V, 0.8% error]
    Case B (R25=open): no stable equilibrium (V_FB stuck at 1.168V)
    - RB-011 status advanced to In-Progress; root cause documented in tracker
    - Remaining closure: node-voltage bench session + Rev-C schematic annotation
2026-08-12 RB-011: Add validated v4 SPICE model with bench probe measurements
    - Model now includes realistic U6 output impedance (75Ω) and bidirectional D5 diode behavior
    - Predicts V_OUT equilibrium at 3.290V vs measured 3.335V (1.4% error within tolerance)
    - D5K prediction 3.278V vs measured 3.3032V (0.8% error)
    - Case B (R25 open) shows D5K held at 3.30V by diode back-drive, output driven to 3.45V
    - Bench probe data confirms: R15 not populated, all node voltages match model predictions
    - Updated RB-011 tracker with full bench probe results and detailed root cause explanation
    [3v3_sel_case_a_v4.csv]
2026-08-12 Session handoff: RB-011 root cause closure complete
    Investigation confirmed: R25 is the sole DC return path for the 3.3V feedback divider.
    - SPICE v4 model validated against bench probe measurements
    - V_OUT prediction error: 1.4% (model 3.29V vs measured 3.335V)
    - D5K prediction error: 0.8% (model 3.278V vs measured 3.303V)
    - Case B (R25 open): No stable regulation equilibrium; output clamps at 3.45V
    - Root cause: Diode back-drive insufficient to maintain divider bias without R25 DC path
    Action for Rev-C: Mark R25 as REQUIRED in BOM. Add design note explaining critical feedback function.
    Ready for next iteration schematic annotation and layout.
2026-08-14 Implement Rev-C differential OCP baseline
    [DSP-Regulator-HAT-RevC.kicad_pcb, DSP-Regulator-HAT-RevC.kicad_sch]
2026-08-14 Sync regulator Rev-C design baseline
    [DSP-Regulator-RevC.kicad_pcb, DSP-Regulator-RevC.kicad_sch]
2026-08-16 Update Rev-C regulator and HAT designs
    [DSP-Regulator-HAT-RevC.kicad_sch, DSP-Regulator-RevC.kicad_pcb, DSP-Regulator-RevC.kicad_sch]
2026-08-16 Update Rev-C regulator PCB metadata
    [DSP-Regulator-RevC.kicad_pcb]
2026-08-16 Save Rev-C regulator PCB routing progress
    [DSP-Regulator-RevC.kicad_pcb]
2026-08-19 Update Rev-C coplanar board designs
    [DSP-Regulator-HAT-RevC.kicad_sch, DSP-Regulator-RevC.kicad_sch]
2026-08-19 Restore Rev-C regulator PCB updates
    [DSP-Regulator-RevC.kicad_pcb]
2026-09-24 firmware(stm32): fix HardwareSerial constructor build break (#18)
    * Add firmware development plan (feature inventory + milestones)
    * firmware(stm32): fix HardwareSerial constructor build break
    Use STM32duino's concrete 'Uart' class instead of the abstract
    ArduinoCore-API 'HardwareSerial' base class, which has no (rx, tx)
    pin-pair constructor. Verified builds successfully with PlatformIO.
    Flip CI's stm32-bluepill-bringup job back to a required check now that
    it builds.
    Fixes #3
    ---------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
    [main.cpp]
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2026-09-24 Add STM32 persistent config on W25Q128 (#20)
    Add a versioned, CRC-checked config record stored in external W25Q128 flash for stm32-bluepill-bringup, with serial CFG save/load/reset/erase commands and persisted rail calibration coefficients. Wire defaults and config load at boot and apply calibration to published telemetry values while keeping issue #12 status/fault logic out of scope.
    [main.cpp]
2026-09-24 Implement UDI command channel for output and current-limit (#21)
    Add bidirectional UART command framing for Milestone 2a: display sends CMD lines to STM32, STM32 validates and returns ACK/ERR/EVT, and CrowPanel tracks command responses while preserving binary tele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
2026-09-24 Implement CrowPanel Settings submenus (#23)
    Add functional System/DataSet/About submenu flows on the CrowPanel Settings screen with live status panes and submenu actions, and update the firmware plan status accordingly.
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2026-09-25 Align STM32 and fan pin docs (#41)
    Replace stale draft pin maps with a current Rev-C STM32 contract matrix, explicitly document the no-tach fan policy for J7, and add a repeatable drift-check workflow tied to firmware and netlist sources. Also update firmware plan notes to reflect the PA3 fault-net mismatch and current fan-contract status.
2026-09-25 Fix Rev-C fault pin mapping (#42)
    Disable PA3 fault pin usage on Rev-C where FAULT_CRITICAL_SUM is not routed to STM32 GPIO, guard fault read path, and align pin-contract docs.
    [main.cpp]
2026-09-25 Add hardware-aligned firmware scope buckets (#43)
    * Fix Rev-C fault pin mapping
    * Add Rev-C firmware scope buckets
    Define hardware-aligned firmware scope buckets with exit criteria and evidence gates, and require bucket mapping in firmware PR workflow.
    ---------
    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
2026-09-25 Derive telemetry fault/status bits at runtime (#44)
    Implement Bucket 3 progress by computing status/protection flags from live channel state, OVP thresholds, and thermal state; gate OCP reporting on observable fault routing; and update firmware plan s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
2026-09-25 Bucket 2: add UDI GET STATE readback for rail-control validation (#45)
    * Add UDI state query for rail-control bring-up
    Add CMD:GET STATE to report output intent, D9 path, CH2 path state, and fault-sum routing visibility for Bucket 2 rail-control validation; update firmware plan command-channel inventory.
    * Fix GET STATE build regression
    Add forward declaration for is3v3PathEnabled used by UDI GET STATE handler.
    * Switch fault path to AW9523 interrupt model
    Implement Rev-C fault observation via AW9523 input plus AW9523_INT on PB7, add GET STA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
    [main.cpp]
2026-09-25 Bucket 2: publish AW9523 fault transition events over UDI (#47)
    * Emit fault transition events over UDI
    Publish EVT:FAULT TRIP/CLEAR on AW9523 interrupt-driven fault state changes, return F=NA in GET STATE until fault state is sampled, and update firmware plan command-channel notes.
    * Trim STM32 diagnostic string footprint
    Shorten non-functional diagnostic/help text to recover Blue Pill flash margin while preserving fault-event behavior (EVT:FAULT TRIP/CLEAR unchanged).
    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
    [main.cpp]
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2026-09-26 Bucket 5 config recovery reason surface (#49)
    Add deterministic persistent-config recovery reason surfacing with additive CMD:GET CFGREC and boot recovery summary logging, while preserving existing GET STATE and ACK/ERR contracts.\n\nCo-authored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
2026-09-26 Bucket 6: add compact STM32 bring-up diagnostics command (#48)
    Scope delivered: add DIAG command, explicit AW9523 INT fault-path visibility log, and align firmware plan status entries.
    Validation: python -m platformio run -d stm32-bluepill-bringup succeeded (Flash 65188/65536, RAM 5656/20480).
    Constraint: richer recovery-hint logging deferred due Blue Pill flash headroom.
2026-09-26 display(crowpanel): make Settings submenus fully interactive (#24)
    Implement System/DataSet/About settings fields and deterministic submenu interactions while leaving Setup binding flow untouched. Add SETTINGS_ENC rotate/press/long commands for bring-up testability and update firmware plan status text.
    [main.cpp]
2026-09-28 docs(display): add CrowPanel screens tracker + audit skeleton (#64)
    Coordination artifacts for the CrowPanel UI polish effort:
    - crowpanel-screens-tracker.md: source of truth for D1..D8 bucket
    status, branch names, PR links, and close-out checklist. Return to
    this file each session to sync state.
    - crowpanel-ui-audit.md: skeleton the D1 agent fills in
    (screen-by-screen button audit, layout-only fixes).
    Related: #26, #27, #37, #38, #39, #40
2026-09-28 docs(display): D1 CrowPanel UI audit + bench-verified layout fixes (#66)
    * docs(display): D1 CrowPanel UI audit + Setup Edit/Apply button width fix
    * docs(display): D1 CrowPanel UI audit - bench-verified layout fixes + screenshots
    * docs(display): update tracker D1 row with PR #66 link
    [main.cpp]
2026-09-28 display(crowpanel): D2 nav-shell fixes - Main->Setup badge nav, Graph<->Settings mutual nav (#67)
    [main.cpp]
2026-09-29 firmware(stm32): fix stale/wrong AW9523 P0.x pin comments (#69)
    * firmware(stm32): fix stale/wrong AW9523 P0.x pin comments, document real mapping
    * docs(stm32): flag Q9 designator conflict, point open items at issue #62
    [main.cpp]
2026-09-29 display(crowpanel): D3 wire Main output ON/OFF toggle to UDI (#68)
    * docs(display): mark D2 tracker row merged (#67)
    * display(crowpanel): D3 wire Main RUN chip to direct UDI output ON/OFF toggle
2026-10-02 docs: plan FNIRSI-inspired fixed-rail CrowPanel UI and VS Code handoffs (#79)
    * docs: plan FNIRSI-inspired fixed-rail CrowPanel UI
    Record approved fixed-rail interaction scope, issue dependencies, and VS Code Copilot session prompts. Separate proven regulation status from inferred CC and reconcile older adjustable-supply proposals.
    * docs: record selected blended UI reference direction
    * docs: capture reference-led overview and channel detail layout
    * docs: specify Iset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
2026-10-02 docs(display): simulated FNIRSI-inspired fixed-rail mockup and proposed visual spec (#76) (#80)
    * docs(display): simulated FNIRSI-inspired fixed-rail mockup and proposed visual spec (#76)
    * docs(display): distinct CH1/CH2 colors, unit temperature and date/time strip in mockup (#76)
    * docs(display): record WiFi time source and single enclosure temperature decisions (#76)
    * docs(display): record baseline visual approval for #80 mockup; behavior questions stay open (#76)
2026-10-04 display(crowpanel): LVGL fixed-rail dashboard - Main overview and channel detail (#78) (#81)
    * display(crowpanel): LVGL fixed-rail dashboard - Main overview and channel detail (#78)
    * fix(crowpanel): raise LVGL heap to 128 KB (boot loop) and stop UDI echo loop on UART0 console (#78)
    * docs(display): record #78 resume point in screen tracker
    * display(crowpanel): panel review round 1 - rail names, CH1 color, ON confirm dialog, shared bottom nav, graph tap, uptime clock (#78)
    * docs(display): record 2026-10-04 resume point after panel review round 1 (#78)
    * docs(display): record 2026-10-04 panel-review checkpoint evidence (#78)
    * chore(display): commit guard read-mac retry, upload_speed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
    [main.cpp]
2026-10-05 fix(crowpanel): prevent Detail readings panel overlapping FIXED/Iset footer (layout only) (#88)
    [main.cpp]
2026-10-05 display(crowpanel): D5a strip-recorder Graph screen (#26) (#89)
    * display(crowpanel): D5a strip-recorder Graph screen - 4-pen trend, PSRAM ring buffer (#26)
    * display(crowpanel): D5a Graph grid lines and uptime time axis (#26)
    * display(crowpanel): D5a Graph fault row lists only active trips; drop inferred CV/CC status chips (#26)
    * docs(display): D5a resume point in screens tracker
    * crowpanel: upload_speed 115200 (460800 repeatedly fails with bad data checksum)
    * docs(display): update D5a resume point (PR #89, STM32 cadence flashed)
    [main.cpp]
2026-10-05 firmware(stm32): publish UDI telemetry every 500 ms; fix HardwareSerial build (#90)
    * firmware(stm32): publish UDI telemetry every 500 ms, decoupled from 5 s heartbeat
    * firmware(stm32): use HardwareSerial (no Uart in core 2.12) to fix build (#3)
    * build(stm32): pin ststm32 platform 19.7.0 so CI matches the core 2.12 the code targets
    [main.cpp]
2026-10-05 display(crowpanel): D5c per-channel strip-recorder micro-views (#26) (#94)
    * display(crowpanel): D5c per-channel micro-view with auto-scaled separated V/I traces (#26)
    * display(crowpanel): micro-view current axis snaps to 10 mA steps (#26)
    * display(crowpanel): D5c micro-view nav, scaling hysteresis, units and state notes (#26)
    * docs(display): D5c bench status and resume point (#26)
    * docs(display): tracker - D5c PR number (#94)
    [main.cpp]
2026-10-06 firmware(crowpanel): move host link default to UART1 and close #93 (#96)
    * firmware(stm32): console QUIET lease and guarded-flash quiet workflow for CrowPanel upload (#93)
    * Revert "firmware(stm32): console QUIET lease and guarded-flash quiet workflow for CrowPanel upload (#93)"
    This reverts commit 60aef07d6e4e873c2f4c7d855260900ca8d300e4.
    * firmware(crowpanel): default host link to UART1 so Blue Pill is off the CH340K UART (#93)
    * docs(display): #93 flash results and handoff resume point
    * docs(display): #93 user-reported result
    * docs(firmware): close out #93 evidence and procedure
    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
    [disp_link_slave.cpp]
2026-10-07 Document range MOSFET bench findings (#63)
    * Document RB-003 bench data from issue #62
    * Add RB-003 diagnostic matrix and closure criteria
    * Reconcile RB-003 revision identity and bench checklist
    * Record operator-confirmed Rev-C board identity for RB-003
    * Import fresh Rev-C netlist and update RB-003 mapping
    * Add Regulato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
2026-10-09 docs(hat): Rev-D F405RG + ESP32-C3 decision, pin contract, session prompts (#102) (#104)
    * docs(hat): Rev-D F405/C3 decision, pin contract, and session prompts (#102)
    * Reconcile Rev-C sources for Rev-D (#105)
    * docs(hat): audit Rev-D ESP32-C3 coprocessor (#102) (#106)
    * docs(hat): define Rev-D ESP32-C3 coprocessor contract (#102)
    * docs(hat): select ESP32-C3-MINI-1U for Rev-D
    * docs(hat): confir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
    [DSP-Regulator-HAT-RevD-Support.kicad_sch, MCU.kicad_sch]
2026-10-09 hw(hat): add Rev-D starter and initial source-backed HAT integration (#112)
    * hw(hat): add independent Rev-D full-HAT integration starter
    Preserve the reviewed support project and Rev-C sources; document editable starter scope, support-only ERC evidence and user-approved reuse direction.
    * hw(hat): start source-backed Rev-D HAT integration
    Import an independent HAT reuse sheet, replace legacy controller endpoints with frozen F405 interfaces and reset biases, and record partial-integration gaps and unresolved inherited ERC warnings. Support-only and Rev-C sources remain byte-identical; no PCB or bench validation clai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
    [DSP-Regulator-HAT-RevD-Full.kicad_sch, HAT.kicad_sch, MCU.kicad_sch]
2026-10-11 hw(hat): rebuild partial Rev-D HAT from selected Rev-C schematic (#111)
    * docs(hat): record Rev-C production source mismatch
    * docs(hat): mark source mismatch non-blocking
    * docs(hat): defer fan check and session 5
    * fix(hat): rebuild Rev-D from selected production schematic
    Replace the incorrect repository-derived HAT baseline with the user-selected production-folder schematic; preserve source circuits and document unsupported interfaces.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
2026-10-11 RB-013 LM74502 variant fix + Bucket 3 fault scope docs (salvaged) (#114)
    Salvaged from phil-cia-bucket-3-execution-takeover, rebased onto current main.
    Excludes the main.cpp Uart->HardwareSerial change, which would undo the
    issue #3 build fix already on main.
2026-10-11 docs: recover missing firmware bucket scopes from P1 branch review (#116)
    Recover Bucket 3-6 documents stranded by merges into the already-merged alignment branch. Preserve current Bucket 2 evidence and align the recovered scopes with current source and display contracts.
2026-10-12 docs(tracker): record 2026-10-06 RB-013 driver rework (#117)
    Recovered from uncommitted notes in the phil-cia-range-mosfet-issue-62 worktree, where they were filed under RB-003. The U9/U14/U15/U16 replacement is RB-013's open rework item.
2026-10-12 docs: add draft enclosure fan-control spec (#28) (#118)
    Recovered from uncommitted work in the phil-cia-congenial-succotash worktree. Adds a caveat that Rev-C J7 has no confirmed tach net (see #29) and links the spec from README and the firmware plan. The worktree's old milestone renumbering was dropped; fan milestones are tracked as issues #31-#36.
2026-10-13 Harden STM32 size-budget checker
    Tighten checker handling, expand targeted tests, and clarify README usage and constraints for F103 flash budget validation.
2026-10-16 Document issue #100 terminal-voltage investigation plan (#124)
    * Document issue 100 investigation plan
    * Clarify calibration evidence for issue 100
    * Trace Rev-C feedback sense source path
    * Use established Rev-C identity baseline
    * Record compact profile issue 100 capture
    * Correct D9 indicator evidence for issue 100
    Co-a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
